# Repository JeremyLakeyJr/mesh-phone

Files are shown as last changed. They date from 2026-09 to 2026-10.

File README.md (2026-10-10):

# MESH-PHONE

ESP32-S3 handheld hardware with sub-GHz radios, LTE, NFC/RFID, a 4×4 keypad,
trackball, GPS and a rear expansion connector. Engineering prototype. **DO NOT FABRICATE OR POWER:** the current handset
is incomplete and only partially routed.

## Project layout

| Directory | Contents |
|---|---|
| [hardware/rev-f](hardware/rev-f/README.md) | Preserved GPS/expansion revision; superseded by the handset redesign |
| [hardware/handset-rev-a](hardware/handset-rev-a/README.md) | Active handset PCB and schematic; open `generated/handset.kicad_pro` |
| `hardware/main/` | Preserved original KiCad project and its local footprints |
| [mechanical/handset](mechanical/handset/README.md) | Latest reference-inspired handset concept; requires new PCB |
| [mechanical/enclosure](mechanical/enclosure/README.md) | Preserved enclosure for the existing Rev F board |
| `scripts/` | Maintained geometry extraction and revision verification |
| `docs/design/` | Historical design notes, pin budgets and routing notes |
| `docs/reviews/` | Electrical review evidence |
| `manufacturing/` | BOMs and explicitly unreleased legacy fabrication exports |
| `archive/` | Prior PCB candidates, enclosure and one-off development scripts |

## Working with the project

Open `hardware/handset-rev-a/generated/handset.kicad_pro` in KiCad 10.
Keep its local symbol and footprint libraries beside the project. The current
checkpoint was checked with KiCad 10.0.6.

Run `bash scripts/check_handset_pcb.sh` to refresh the native netlist, ERC/DRC,
connectivity checks, schematic PDF and previews. Then run
`python3 scripts/check_handset_release.py` to evaluate the release gate.
**The release gate currently fails intentionally:** passing artifact-integrity
checks does not mean the electronics are ready to manufacture.

For the preserved Rev F project, `python3 scripts/verify_revF.py` checks its saved
netlist and placement contracts; it does not run fresh native electrical analysis.

Run `python scripts/enclosure_geometry.py` after PCB mechanical changes, then
`scripts/export_enclosure.sh` to rebuild the enclosure STLs and preview.
See the mechanical README for panel-placement assumptions and fit checks.

Archived scripts preserve historical experiments, including obsolete absolute
paths and old project names. They are not a supported build pipeline and should
not be replayed on the active board. `.history/` is the existing KiCad history
repository and remains in place.

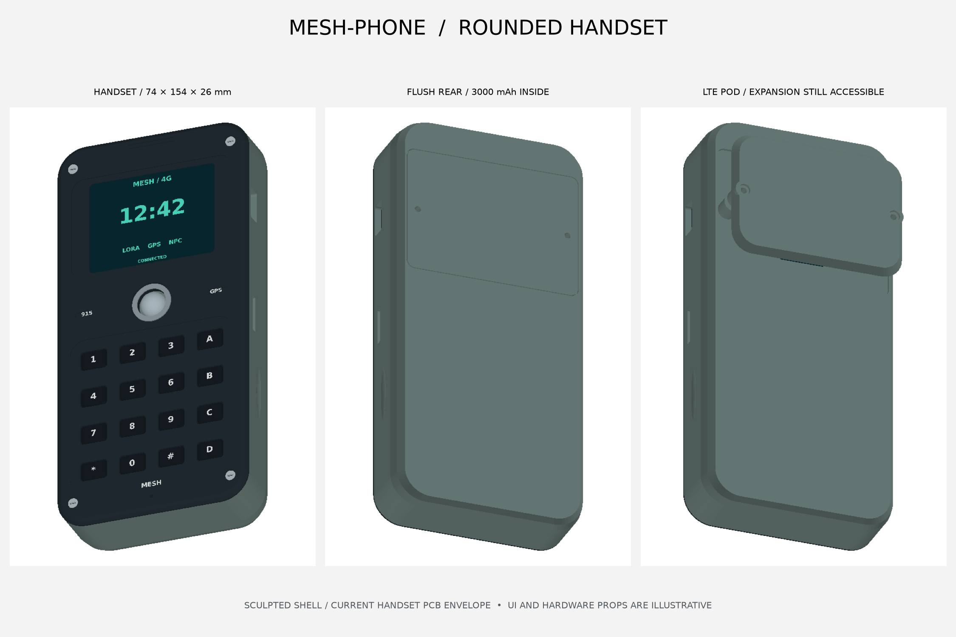
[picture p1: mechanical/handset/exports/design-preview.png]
Rounded handset enclosure


The current enclosure has a sculpted rear, rounded corners and a rolled front
rim. Its maximum body envelope remains 74 × 154 × 26 mm; populated-board fit
and the detachable modem pod still need engineering validation.

Latest appearance: [handset preview](mechanical/handset/exports/design-preview.png).
See [feature preservation](mechanical/handset/FEATURES.md) for the retained hardware
requirements and explicit packaging changes. Build with `scripts/export_handset.sh`.
The selected new-board materials list is in
[`hardware/handset-rev-a/materials-to-use.csv`](hardware/handset-rev-a/materials-to-use.csv).
The supporting component research and comparison table are in
[`docs/research/new-pcb-component-study.md`](docs/research/new-pcb-component-study.md)
and [`hardware/handset-rev-a/candidate-components.csv`](hardware/handset-rev-a/candidate-components.csv).

## Fabrication readiness checklist

Checkpoint: **2026-10-10**. Checked items mean the stated design-file work is
complete, not that the hardware has passed bench testing. Current status:
**277 schematic components, 2,644 passing integrity checks, zero schematic/PCB
parity findings, 20 ERC findings, zero DRC findings, and
216 unconnected items.** Eleven engineering blocker groups remain open.
The detailed source of truth is
[release-blockers.json](hardware/handset-rev-a/release-blockers.json).

Current priority is prototype fabrication readiness: complete the missing circuits,
finish copper and return paths, clear ERC/DRC, freeze the BOM and mechanical fit,
and obtain fabricator/assembler DFM review. Firmware feature work follows this
hardware work. Bench qualification remains required after prototype assembly.

### Completed design work

- [x] Route the SX1262 switch, three RF DC blocks, antenna connector, control filter and filtered supply. Seventeen regression cases and 753 reference samples pass; RF performance remains unqualified. [Switched RF checkpoint](hardware/handset-rev-a/sx1262-power-review.md#switched-rf-routing-checkpoint--2026-10-10).

- [x] Ground all five SX1262 matching-device return lands using scoped 0.2 mm drilled vias and local copper. Thirteen regression cases pass; record a screened 0.34 mm downstream RF routing target. [Ground/impedance checkpoint](hardware/handset-rev-a/sx1262-power-review.md#rf-ground-and-impedance-checkpoint--2026-10-10).
- [x] Relocate the SX1262 clock and route local PA/RF input connections. Nine copper regression cases pass; RF qualification stays open. [Local routing checkpoint](hardware/handset-rev-a/sx1262-power-review.md#local-parf-routing-checkpoint--2026-10-09).
- [x] Capture SX1262 PA choke and dual bypass with specified parts. Eleven circuit mutations pass; PA/RF electrical qualification remains open. [PA checkpoint](hardware/handset-rev-a/sx1262-power-review.md#pa-choke-and-bypass-checkpoint--2026-10-08).
- [x] Capture SX1262 matching/filter, TX/RX switch, control/supply filters and DC blocks. Eight wrong-wiring/value tests pass; physical copper follows in the switched RF checkpoint. [RF checkpoint](hardware/handset-rev-a/sx1262-power-review.md#rf-matching-and-switch-checkpoint--2026-10-08).
- [x] Connect SX1262 input supplies, bypass capacitors and all ground pins to the established rail/return network. Six open-pad tests and 16-pad continuity pass. [Supply checkpoint](hardware/handset-rev-a/sx1262-power-review.md#input-supply-routing-checkpoint--2026-10-08).
- [x] Route the SX1262 core regulator loop, VREG capacitor return and regulator/exposed-pad ground. Six open-pad controls pass; 15 copper items added with existing copper preserved. [Regulator checkpoint](hardware/handset-rev-a/sx1262-power-review.md#regulator-routing-checkpoint--2026-10-08).
- [x] Capture and route the SX1262 TCXO clock: 14 pads, an 8.092 mm relocated clock path and its ground reference pass checks. ERC falls by three; RF frontend and clock electrical qualification remain open. [Clock checkpoint](hardware/handset-rev-a/sx1262-power-review.md#tcxo-clock-checkpoint--2026-10-08).

- [x] Route amplifier power, ground and local shutdown bias; move C13 beside U6. Fifteen physical pads pass continuity, five regression cases pass, and existing copper remains intact. Speaker/I²S/microphone routing remains open. [Layout checkpoint](hardware/handset-rev-a/README.md#audio-power-routing-checkpoint).

- [x] Cross-build an ESP32-S3 keypad bring-up application with I²C, GPIO8 interrupts, USB logs and start/stop/recovery commands. Twelve session tests and native pin-map checks pass. [Build and commissioning instructions](firmware/bringup/README.md); hardware testing remains open.
- [x] Complete the 16-key matrix copper (72 physical pads), add five routing regression cases and a host-tested keypad driver with overflow recovery. [Routing and firmware evidence](hardware/handset-rev-a/keypad-routing-review.md).
- [x] Route ESP32 boot/reset service controls and U2 power, reset, I²C and interrupt connections; eight regression cases pass with zero DRC/parity findings. [Evidence and remaining bring-up work](hardware/handset-rev-a/core-bringup-review.md).
- [x] Organize hardware, mechanical designs, research, reviews and archived checkpoints.
- [x] Create the four-layer handset PCB and rebuild the schematic as a system index plus 24 functional sheets.
- [x] Retain ESP32-S3-WROOM-1-N16R8 and preserve interfaces for the external display, keypad, trackball, cellular adapter, radios, GNSS, NFC/LF RFID, storage, IR, audio and expansion.
- [x] Capture MakerFocus 3000 mAh battery requirements and the external-module connector; exact pack qualification remains below.
- [x] Populate the current schematic/PCB with component footprints and a materials list; final BOM and footprint audits remain below.
- [x] Capture BQ25186 charging, fused USB/battery entry, TPS25200 protection, TUSB320LAI source detection and TCA9536 controls; verify continuity of 113 local power-entry pads.
- [x] Cross-build and validate an inhibited STM32G031 commissioning image with private-bus I²C, PA0 shutdown, watchdog and diagnostic host interface. [Build, evidence and limits](firmware/power/stm32g031/README.md).
- [x] Route supervisor power, private/host I²C and SWD connections; verify 67 endpoints and preserve existing copper. [Routing evidence and remaining work](hardware/handset-rev-a/supervisor-routing-review.md).
- [x] Route charger VSYS to U7, the main power-switch control, and U7 to ESP32 power/bypass/ground; verify 38 physical pads with no new DRC findings. [Routing evidence and limits](hardware/handset-rev-a/main-distribution-review.md).
- [x] Add and route independent STM32 charge permission so a retained expander output cannot defeat reset inhibition; update controller sequencing and pass topology, continuity and fault tests. [Design and qualification limits](hardware/handset-rev-a/charge-inhibit-review.md).
- [x] Capture and place the separate STM32G031 charging supervisor, always-on regulator and isolated host bus; preserve existing copper geometry. [Circuit and remaining work](hardware/handset-rev-a/power-supervisor-review.md).
- [x] Record the charger-policy contract and implement a host-tested portable charger controller with a 4.17 V target; STM32 supervisor integration and hardware tests remain below.
- [x] Capture published MakerFocus pack specifications and calculate an illustrative modem-load budget; the current pack/modem compatibility blocker remains open.
- [x] Audit modem startup/output tolerance and battery current directly from CAD; add regression tests and release-gate checks. User selected a higher-current ~3000 mAh pack; provisional target is at least 5 A, with pack/fit/F2/J1 qualification still open. [Power review and battery requirements](hardware/handset-rev-a/modem-power-review.md).
- [x] Screen a concrete higher-current pouch and low-profile connector: CU-JAS427 and Molex 2053380002. Pack current clears the provisional calculation, but fit and production qualification fail; neither is frozen. [Candidate evidence and remaining checks](hardware/handset-rev-a/battery-candidate-review.md).
- [x] Replace J1 with the low-profile Molex 2053380002 in schematic and PCB; repair local battery/ground routing, preserve unrelated layout, and verify 118 power-entry pads plus a broken-route negative test. [Connector implementation and fuse screening](hardware/handset-rev-a/battery-connector-review.md).
- [x] Widen the battery-to-fuse main trace to 1.2 mm where clearance permits; reduce its calculated resistance by about 24%, preserve placement, and verify continuity with a broken-trace test. Fuse selection and current/thermal qualification remain open. [Copper and fuse follow-up](hardware/handset-rev-a/battery-copper-review.md).
- [x] Inventory handset loads and add a 60-case battery-only power-envelope check separating the charger-fed handset from the modem. Flag the incomplete 0.25 A allowance and configured handset discharge limit in the release gate. [System power review](hardware/handset-rev-a/system-power-review.md).
- [x] Audit display/backlight and expansion limits; specify four high-power backlight resistors in schematic, PCB and BOM. Add checks for panel supply tolerance and port current limit. [Display and expansion review](hardware/handset-rev-a/display-expansion-power-review.md).
- [x] Capture and place a dedicated 3.0 V display supply, SPI/control buffers and touch I²C translator using specified parts. Preserve shared-bus MISO deselection; update BOM and power inventory. Physical routing is recorded below; electrical qualification remains open. [Display interface review](hardware/handset-rev-a/display-interface-review.md).
- [x] Route and physically verify the dedicated display interface: 25 net groups, including supplies, host/connector signals and grounds. Preserve existing placement/copper; add ground returns and continuity regression tests. [Display routing review](hardware/handset-rev-a/display-routing-review.md).
- [x] Install and route the CAT4004A backlight current driver, replacing Q2/R52–R55; verify 26 endpoints, seven regression tests and no new DRC findings. Preserve existing display continuity. [Implementation and qualification limits](hardware/handset-rev-a/backlight-routing-review.md).
- [x] Capture and route expansion power control, fault sensing and hardware signal isolation; verify 31 physical net groups and six regression tests, and add a host-tested portable controller. Preserve all 4,183 existing copper items. [Implementation and qualification limits](hardware/handset-rev-a/expansion-control-review.md).
- [x] Improve expansion ESD ground returns with local inner-layer pours and a direct U16 ground bridge; remove 36.24 mm of ground detours, preserve all signal routing and pass ground-return regression tests. [Evidence and remaining limits](hardware/handset-rev-a/expansion-control-review.md).
- [x] Clear all four USB connector hole-clearance findings using a dedicated ground-corner-relief footprint; preserve holes, routed copper and board rules. Native DRC is now zero; four geometry regression tests pass. [Footprint change and remaining qualification](hardware/handset-rev-a/usb-connector-review.md).
- [x] Route both USB-C data orientations through ESD protection and 22 Ω host termination; match CAD path lengths, add reference copper and verify seven regression cases. Record the JLC04161H-7628 stackup target; fabricator impedance and electrical qualification remain open. [Routing evidence and limits](hardware/handset-rev-a/usb-data-routing-review.md).
- [x] Route the local TPS63802 main 3.3 V regulator circuit; verify continuity of 26 pads.
- [x] Route U20 local modem converter, feedback, ground and switch-controlled enable network; verify 48 pads with no new DRC findings. [Layout and startup limits](hardware/handset-rev-a/modem-layout-review.md).
- [x] Route U10 local 5 V boost, feedback, ground and switch enable; verify 19 pads with no new DRC findings. [Layout and voltage limits](hardware/handset-rev-a/reg5-layout-review.md).
- [x] Route U10 VSYS feed and LF RFID power/ground for U9/U18; verify 36 pads and preserve existing copper. [Distribution evidence and limits](hardware/handset-rev-a/reg5-distribution-review.md).
- [x] Route the local U11 1.8 V regulator circuit, reposition input bypass and orient the inductor toward SW; verify 15 pads and preserve existing copper. [Layout evidence and remaining qualification](hardware/handset-rev-a/reg18-layout-review.md).
- [x] Connect U7 to U11 input, shorten C28 output/sense paths and verify 17 pads. Audit confirms no external 1.8 V loads are assigned; rail purpose remains open. [Distribution evidence](hardware/handset-rev-a/reg18-distribution-review.md).
- [x] Capture auxiliary supplies and the regulated modem supply/enable circuit; complete routing and load qualification remain below.
- [x] Capture the CC1101 clock, 868/915 MHz matching/filter, supply bypass and GDO2 test pad; pass 90 topology/value checks and five negative tests.
- [x] Add SX1262 core DC-DC support, correct its VREG capacitor to 470 nF, and specify input bypass parts; pass 30 circuit checks and four negative tests.
- [x] Capture GNSS, display/touch/backlight, audio, storage/IR, NFC/LF support and protected expansion interfaces; incomplete support circuits are listed below.
- [x] Preserve prior CAD checkpoints and existing routed copper during staged updates.
- [x] Add repeatable checks, schematic PDF and board/assembly previews. Current placement checks report no overlaps; fabrication release remains blocked.

### Remaining before first prototype fabrication

Work through these in order; circuit and mechanical decisions must be resolved
before final routing and manufacturing exports.

- [ ] **Battery and charging:** qualify a higher-current ~3000 mAh 1S replacement (provisional ≥5 A target), preserving the pocketable design; verify dimensions, polarity, protection, NTC and charge/discharge limits. Re-select F2 and qualify J1/harness/copper for the full handset/modem current budget. Complete STM32 durable fault storage, service rearm and expiring host permissions, qualify reset-time CE inhibition and powered-off charging. Confirm NTC attachment and charge-temperature limits. Implement charger policy, fault handling and source recovery; qualify the routed supervisor power/control buses and finish remaining system distribution.
- [ ] **Power supplies:** finish U7 distribution to the remaining peripheral loads and U20 external battery/modem distribution; resolve the audited 3.71–4.13 V turn-on range (up to 4.21 V with the EN-current screening allowance); qualify the routed U10 display branch for voltage, current and trace sizing; resolve the unused 1.8 V rail (assign justified loads or remove it), then finalize U11 output/sense layout. Calculate worst-case inductor current, capacitor DC bias, feedback tolerance, thermal dissipation, startup/UVLO and modem burst margin. Define current-limited bring-up limits and test points.
- [ ] **Cellular adapter:** freeze an orderable modem variant, firmware, SIM interface, logic translation and call-audio circuit. Verify supported bands and carrier VoLTE requirements; interchangeable adapters do not guarantee every carrier. Select the call microphone and speaker/harness arrangement.
- [ ] **SX1262 LoRa:** qualify the captured 32 MHz TCXO amplitude, DIO3 supply and startup timing; qualify the routed PA choke/bypass and local RF input geometry; qualify matching-device grounds, routed RF switch/antenna paths and all three signal-via transitions; complete thermal layout; qualify the routed input supplies and core regulator loop.
- [ ] **CC1101:** refine and route the oscillator, bypass, balun/filter and separate antenna feed against the selected stackup. Review crystal load/drive and the optional spur filter; define firmware SPI/GDO configuration.
- [ ] **NFC and LF RFID:** finish ST25R3916B matching/receive circuitry and HTRC110 clock, analog reference, coil network and timing-capable host return path. Specify external coils, crystal loading and tuning provisions.
- [ ] **GNSS:** finish MAX-M10S decoupling and RF feed; select the passive antenna and verify mounting, keepouts and coexistence requirements.
- [ ] **Expansion and USB:** qualify routed J16 current limits, inrush, isolation, ESD return paths, fault recovery and shared-bus timing; integrate the portable controller. Exchange modules only with handset power off. Qualify the routed USB fanout, uncoupled tuning, three via transitions per leg, termination and eye performance; obtain fabricator impedance approval. Obtain assembler DFM approval of the USB4105 relieved ground-land contour and qualify connector fit/solder joints.
- [ ] **Display, controls and peripherals:** next, qualify the routed U28–U31 interface for regulator load/heat, trace sizing, capacitor DC bias, power sequencing and shared-bus timing; qualify the routed CAT4004A backlight current, heat and default-off/on sequencing. Confirm the purchased display/touch configuration, FPC contact orientation, supply/backlight requirements and GPIO budget. Review keypad-scanner controls, shared SPI chip selects, IR boot behavior, microSD and audio interfaces; implement the firmware needed for safe bring-up.
- [ ] **Antennas and coexistence:** select actual LTE, LoRa, CC1101, GNSS and Wi-Fi/BLE antenna arrangements, cable/connectors and matching provisions. Establish ground clearance, spacing and simultaneous-transmit policy; retain access for RF measurements.
- [ ] **BOM and footprints:** freeze all orderable parts with tolerance, voltage, power, dielectric, temperature and lifecycle requirements. Independently audit every custom symbol pin map, package, exposed pad, paste pattern, orientation and connector mating direction. Define DNP options and approved substitutions.
- [ ] **Mechanical fit:** reconcile the PCB with the pocketable case, actual battery, external screen/FPC, trackball opening and retention, top speaker, bottom microphone, antennas, mounting hardware and external module port. Check populated heights, cable bends and moved power-switch access using a full assembly model and fit prototype.
- [ ] **Fabricator rules:** confirm the proposed JLC04161H-7628 four-layer stackup, copper weights, impedance targets, drill/via limits, solder-mask rules and ESP32 and expansion J16.8/U14.1/U14.6/U16.1 via-in-pad filling/capping requirements with the chosen fabricator. Resolve RF reference via sizes against those capabilities.
- [ ] **Complete PCB routing:** connect all 216 currently unconnected items; finish return planes, ground stitching, thermal paths and supply distribution. Review switching loops, RF/USB impedance, antenna keepouts and analog/digital interference. Recheck clearances after all placement changes.
- [ ] **Independent electrical review:** check every pin and power state against manufacturer documents, including boot straps, pull resistors, power sequencing, unpowered interfaces and test access. Close each blocker with evidence rather than marking an incomplete subsystem complete.
- [ ] **Final native checks:** regenerate netlist/ERC/DRC from the exact release revision; resolve the 30 current ERC findings and all airwires; retain zero DRC findings. Require zero parity errors and passing circuit/continuity checks. Any genuinely intentional rule exception needs a documented engineering justification, not a blanket waiver.
- [ ] **Prototype manufacturing package:** export and inspect Gerbers, plated/non-plated drill files, fabrication drawing/stackup, assembly drawings, full MPN BOM, DNP list and pick-and-place files. Verify units, origin, bottom-side rotation, pin 1, polarity and layer alignment in an independent viewer; obtain fabricator/assembler DFM feedback.
- [ ] **Prototype release:** review the complete package and bring-up plan, close the applicable prototype blockers, tag the exact Git revision and archive checksums/reports with the exports. Update the release gate to distinguish an approved prototype from production qualification. Only then authorize a small prototype build.

### After prototype assembly, before production release

These require physical hardware and therefore cannot be prerequisites for
fabricating the first engineering prototypes.

- [ ] Inspect assembly and check shorts/polarity before applying power; bring up each rail on a current-limited supply with the battery initially disconnected.
- [ ] Measure charge limits, NTC/fault response, protected-pack behavior, powered-off charging, source switching, sleep current, runtime, rail stability, thermal rise and worst-case modem/radio bursts.
- [ ] Validate oscillator startup/frequency/drive, LoRa and CC1101 conducted power/sensitivity, spurious emissions, antenna matching and RF coexistence in the assembled case; tune NFC/LF coils and verify GNSS reception.
- [ ] Test calls/SMS/data with the selected adapters and supported carriers, SIM operation, call/media audio, display/touch, keypad combinations, trackball, storage, IR, GNSS/PPS and expansion functions.
- [ ] Test USB/expansion faults and ESD response, power interruption/recovery, firmware update/recovery and repeated accessory connection cycles.
- [ ] Validate enclosure fit, connector access/retention, drops, pocket pressure, temperature and battery protection from mechanical damage.
- [ ] Complete required EMC/radio/product compliance assessment and testing for intended markets and operating modes.
- [ ] Correct prototype findings, repeat affected checks/tests, freeze production BOM/firmware and create assembly test fixtures, programming instructions, acceptance limits and traceability records.
- [ ] Obtain independent final review and release a versioned production manufacturing package only after all qualification evidence is recorded.

Battery follow-up: [pack, charging and power-budget review](hardware/handset-rev-a/battery-charging-review.md).

Implementation evidence: [power entry](hardware/handset-rev-a/power-entry-review.md),
[3.3 V layout](hardware/handset-rev-a/3v3-layout-review.md),
[schematic rebuild](hardware/handset-rev-a/schematic-rebuild-review.md),
[CC1101](hardware/handset-rev-a/cc1101-review.md), and
[SX1262 power](hardware/handset-rev-a/sx1262-power-review.md).

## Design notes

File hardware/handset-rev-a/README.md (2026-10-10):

# Handset Rev A — PCB redesign in progress

Open [generated/handset.kicad_pro](generated/handset.kicad_pro) in KiCad 10.
This is a new board and hierarchical schematic, not the old Rev F layout.
**It is incomplete, partially routed, and not ready to fabricate or power.**
The original Rev F project is preserved in `../rev-f/`.

Latest: [SX1262 switched RF routing](sx1262-power-review.md#switched-rf-routing-checkpoint--2026-10-10). Fabrication
readiness takes priority over additional firmware features. RF, NFC/LF and other
unfinished circuits remain fabrication blockers.

## Implemented in the design files

- 66 × 142 × 1.6 mm board with four copper layers, four 2.2 mm mounting
  holes and a 27 × 24 mm trackball opening. The extra 4 mm length prevents
  the mounting drills from breaking through the former 138 mm outline.
- Retained ESP32-S3-WROOM-1-N16R8; PSRAM pads 28–30 stay unconnected.
- A rebuilt system index and 21 functional schematic sheets, including
  GNSS/antennas, NFC, protection, storage/IR, LF support, display and modem power.
  See [schematic PDF](generated/handset-schematic.pdf) and
  [rebuild review](schematic-rebuild-review.md) for corrections and remaining work.
- Sixteen switches at the enclosure coordinates, TCA8418 scan circuit,
  matrix row traces on F.Cu and column traces on In2.Cu. Scanner fanout remains.
- BQ25186 programmable charger, TPS63802 3.3 V converter, TPS62840 1.8 V converter,
  TPS61023 LF/backlight 5 V converter and MAX17048 gauge circuits.
- Fused battery and USB paths, TPS25200 eFuse, TUSB320LAI Type-C detection,
  TLV704 always-on detector supply and TCA9536 charge controls. The 113-pad
  local power-entry cell passes copper continuity; firmware and external
  distribution are unfinished. See [power-entry-review.md](power-entry-review.md).
- Main 3.3 V converter local copper is routed and continuity-checked across
  U7, L1, C20–C22 and R30–R33. External power distribution remains incomplete;
  see [3v3-layout-review.md](3v3-layout-review.md).
- CC1101 clock, filtered supply and 868/915 MHz balun/matching/filter circuit
  are captured with specified parts and checked PCB placement. RF routing and
  tuning remain; see [cc1101-review.md](cc1101-review.md).
- SX1262 TCXO clock and local routing are captured; its RF frontend and
  electrical qualification remain open. HTRC110 clock/analog/coil circuits are incomplete.
- MAX98357A media amplifier, SPH0645 digital mic, separate analog call-audio
  harnesses, native ESP32 USB-C and dedicated modem/expansion connectors.
- Manufacturer-derived custom pin definitions and TPS63802 DLA0010A land
  pattern. Custom library geometry still needs an independent pre-fab review.
- MAX-M10S GNSS; ST25R3916B NFC and oscillator; TPS2553 expansion current
  limiter and TPD4E05U06 protection arrays; Hirose DM3D-SF microSD socket;
  LF level translators; transistor-driven case-mounted IR; top-contact
  display connector/backlight switch; TPS63070 regulated modem supply.
- Routed TCA9537 expansion control, SN74CB3Q3245 signal isolation and SN74HCS10 fault interlock; portable controller host tests pass. [Design and remaining qualification](expansion-control-review.md).
- Named Coilcraft XFL4020 inductors replace the generic inductor allowances.
  Details and outstanding electrical work: [population-review.md](population-review.md).

The current component count, native ERC/DRC findings, remaining airwires and
schematic-to-board integrity results are in
[generated/verification-summary.json](generated/verification-summary.json).
The seven former reservation rectangles have been replaced by physical parts
and schematic circuits. Zero reservation rectangles does **not** mean that the
circuits are complete or that the PCB can be ordered.

## Critical unfinished work

| Block | Required work before release |
|---|---|
| GNSS | MAX-M10S is populated. Finish its RF feed, decoupling placement and coexistence review; no hardware backup supply is implemented. |
| Cellular | Select exact unlocked modem/firmware and establish calls, SMS and data on target carriers. The detachable adapter needs its own SIM, antenna feeds, voltage translation, regulated peak-current supply and audio implementation. |
| LCD / touch | ER-TFT024IPS-3 pinout and FH12A-50S-0.5SH(55) connector are captured with backlight switching. Confirm purchased CTP configuration, rail tolerances, FPC orientation/bending and firmware. |
| NFC | ST25R3916B, crystal and bypass components are populated. Finish and tune the antenna matching/receive network and validate oscillator loading. |
| Radio frontends | SX1262 input supply/ground and local core DC-DC loop are routed; finish thermal layout and qualify supply integrity; qualify the relocated TCXO, routed PA and local RF input geometry; qualify matching-device ground vias and complete switch/antenna routing. Route and qualify the implemented CC1101 clock/decoupling/balun/filter circuit and separate antenna feed. |
| LF RFID | SN74AHCT125 and SN74LVC1G17 translation is populated. Clock, analog reference, coil network and timing-capable host return path remain incomplete. |
| GPIO budget | Confirm scanner GPIO behavior and LCD D/C throughput. IR_RX now uses ESP32 GPIO3; preserve default JTAG eFuse policy and verify boot behavior with active IR. |
| USB / J16 | TPS2553 and signal ESD arrays are captured. Finish protected routing, VBUS protection and power-off accessory policy; test current limit and ESD response. |
| Storage / IR | DM3D-SF and IR driver/harnesses are captured. Validate card access, TSAL6400/TSOP38438 case mounting and firmware. |
| Mechanical / RF | Check actual populated heights, display FPC bends, antenna keepouts, connector mating direction and trackball retention. Power-switch placement has moved and needs matching case access. |
| Layout | Finish placement, reference-plane design, all remaining routing, controlled impedance, thermal copper, ground stitching and silkscreen. Clear native ERC/DRC. |

## Power and connector contracts

J1 is a provisional two-pin battery connector; verify the purchased MakerFocus
pack polarity and plug before populating it. J2 is an external 10 kΩ B3435
thermistor to be thermally coupled to the battery; the two-wire pack itself does
not supply that signal. The BQ25186 CE input defaults off; firmware must apply
and read back [charger-policy.json](charger-policy.json) before charging.
The contract requests 300 mA charge on enumerated legacy USB or 500 mA on
qualified Type-C sources, subject to source and thermal limits. It is not yet
implemented firmware. Validate pack protection and discharge current; the
modem burst budget and powered-off charging remain unresolved.

SW19 controls converter enables. VSYS, charger, and battery gauge can remain
energized while the handset rails are off. Inductors now have exact XFL4020
MPNs and documented land patterns; rated-current and thermal review remains.
The legacy-named +5V_RF rail now also supplies the display backlight.

J16 preserves Rev F pin order: GND, EXP_3V3, SCL, SDA, SCK, MOSI, MISO, CS,
IRQ, GND. It is a locking JST GH cable port, independent of the modem.
U14 now supplies EXP_3V3 through a TPS2553 with a 100 kΩ limit resistor;
U15/U16 protect the seven signals. This is captured circuitry, still unrouted
and untested. Swap accessories with power off.

J8 is the proposed modem adapter's 3.3 V logic contract: GND, host TX, host RX,
LTE_ON, GND, MODEM_STATUS. Raw modem UART pins must not be connected unless
their voltage levels match; translation belongs on the adapter. J9 reserves a
separate regulated modem supply with two supply and two ground contacts.
U20 now generates nominal 3.792 V from VBAT, with hardware shutdown and
conservative battery UVLO; it does not connect the modem to raw charger SYS.
Startup requires a sufficiently charged battery (about 3.92 V nominal).
Connector/contact current, cable resistance and transient limits are not yet
validated. J4 carries adapter call speaker ± and microphone ±.
J7 is a proposed harness for PIM447, not a claim that its pad order matches it.

## Multi-carrier requirement

The user requires unlocked operation across carriers. A7672G is consequently
**a candidate, not a frozen or universally compatible modem**. Quectel EG25-G
is another research lead with broader published carrier documentation, but
carrier data approval does not establish smartphone VoLTE acceptance. No
universal-carrier claim is made, and no carrier-specific module is hard-wired
into this main board. The replaceable modem adapter preserves that choice.

## Reproduce and inspect

Edit the saved project directly. `scripts/build_handset_pcb.py` refuses to
overwrite an existing board. The additive population scripts are one-shot
migrations with snapshots/markers; do not rerun them to reset manual placement.

Run `bash scripts/check_handset_pcb.sh` for native XML
netlist export, ERC, DRC, integrity checks and SVG previews. Integrity checks verify real exported
schematic pin nets against board pads and mounting/key coordinates. Passing
them does not waive native errors or establish electrical functionality.

Run `python scripts/check_handset_release.py` for the separate release gate.
It intentionally fails while native errors, unrouted connections or engineering
blockers remain. See [population-review.md](population-review.md) for the
22 September checkpoint and remaining work by review category.

## Primary design references

- [TI BQ25186](https://www.ti.com/lit/ds/symlink/bq25186.pdf)
- [TI TPS63802, including DLA0010A land pattern](https://www.ti.com/lit/ds/symlink/tps63802.pdf)
- [TI TPS62840](https://www.ti.com/lit/ds/symlink/tps62840.pdf)
- [TI TPS61023](https://www.ti.com/lit/ds/symlink/tps61023.pdf)
- [TI TCA8418](https://www.ti.com/lit/ds/symlink/tca8418.pdf)
- [TI CC1101](https://www.ti.com/lit/ds/symlink/cc1101.pdf)
- [Analog Devices MAX17048](https://www.analog.com/media/en/technical-documentation/data-sheets/MAX17048-MAX17049.pdf)
- [u-blox integration-document availability](https://content.u-blox.com/sites/default/files/documents/UBX-M10050-KB_IP_IN_UBX-22012688-2.pdf)
- [SIMCom A7672G specifications and certification list](https://www.simcom.com/product/A7672G.html)
- [Quectel EG25-G carrier and software documents](https://www.quectel.com/product/lte-eg25-g/)

## Audio power routing checkpoint

2026-10-08: U6 supply pins, exposed-pad/ground pins, C13/C14 bypass network and
R13 local shutdown bias now pass physical continuity checks. C13 moved from
(82, 83) mm to (77.45, 80.9) mm, rotated 90 degrees, to put its 100 nF bypass
beside U6. No other footprint, previous track/via, stackup or design rule changed.
All 613 pre-existing connected pad groups retain continuity; all 9,075 previous
copper items remain. The original checkpoint is archived at
`archive/handset-before-audio-routing/a31246005c3d/` in the repository root.

The [MAX98357A datasheet, page 33](https://www.analog.com/media/en/technical-documentation/data-sheets/MAX98357A-MAX98357B.pdf)
specifies supply bypassing and low-resistance supply/output/ground paths.
This routing uses a 0.5 mm feed to the existing 3.3 V trunk, a 0.3 mm bulk-capacitor
branch and short 0.25 mm VDD pad escapes. It is a CAD continuity checkpoint;
current capacity, ground-return/thermal performance, supply noise and audio
performance still need engineering qualification. The 3.3 V system load budget
remains open.

[Construction and preservation evidence](generated/audio-routing.json),
[15-pad continuity checks](generated/audio-routing-check.json) and
[five routing regression cases](generated/audio-routing-tests.json) are included
in the board checks. The release gate checks the new copper directly.
Native DRC and schematic parity are zero; unconnected items fall from 250 to 238.
Thirty ERC findings and eleven engineering blocker groups remain open.

Speaker output placement/routing, I²S, the U2 MEDIA_EN connection and the microphone
are still unfinished. Complete the speaker placement review before routing its
switching-current paths. The circuit is not ready for power-up or fabrication.

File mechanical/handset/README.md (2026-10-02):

# MESH-PHONE handset concept

A rounded handset redesign replaces the flat-sided brick silhouette with a
rolling rear shell, 11 mm corner radii, a softened front rim and smooth thumb
channels. A dark face sits against a muted green-grey rear shell in the CAD
preview. The detachable modem pod also has rounded corners and a tapered back.

**This is a mechanical concept for the current handset Rev A board envelope,
not the preserved Rev F PCB.** The envelope fit checks do not establish a
populated-board, cable or antenna fit. No electronic feature is removed.

## Size and architecture

- Handset: **74 × 154 × 26 mm** maximum, unchanged by the rounded redesign.
  The new shape reduces corner bulk, not the required battery/PCB stack. Compared with the prior 93 × 160 × 38.8 mm body.
  About 49% less body bounding-box volume. No external screw ears. The
  illustrative trackball rises 2.3 mm above the face; quoted body sizes exclude it.
- Proposed new main board: **66 × 142 × 1.6 mm**, underside Z=17.2 mm.
  Extended 4 mm during PCB design to keep mounting drills inside the board.
  Mounting holes are [±30.5, ±68]; board corners use a 1.5 mm clip.
- Battery: MakerFocus **3000 mAh**, nominal 65 × 36 × 10 mm, supplier tolerance
  ±2 mm. Cradle reserves **38 × 67 × 12 mm**, at [0, -39], with lead exit,
  rounded guides and soft-strap anchors. No forced compression of the pouch.
- Smaller touchscreen candidate: EastRising **ER-TFT024IPS-3** rotated to
  landscape. The LCD is 59.26 × 42.72 × 2.3 mm; the CAD reserves
  **60.5 × 43.5 × 3.5 mm** pending the exact capacitive-touch stack drawing,
  with a **48.5 × 36.3 mm** window at [0,42.5]. Freeze its full ordering code and
  FPC before treating it as selected.
- Trackball: retain PIM447's documented **25 × 22 × 11 mm** envelope. Proposed
  center [0,8]. A **27 × 24 mm board aperture** lets its carrier sit partly below
  the new board instead of adding thickness above it. Retention is not finalized.
- Keypad: 16 keys at X=-22.5,-7.5,7.5,22.5 and Y=-11,-26,-41,-56. Requires
  relocated switches. Print `keycap.stl` 16 times; stem height and switch travel
  are provisional. The flange sits below the face and retains each cap.
- LTE carrier: moves into a detachable **66 × 48 × 18 mm** rear pod. It adds
  **16.8 mm** locally when attached, making maximum thickness **42.8 mm**.
  The slim 26 mm body dimension is **without the LTE pod**, not the all-up phone.
  LTE calling/data require that pod until a compact integrated modem redesign.

The design reduces size by changing the packaging, not scaling down components.
The smaller screen and new switch coordinates are explicit changes to the
hardware plan; old display/PCB parts are not drop-in compatible.

## Keep every feature

See [FEATURES.md](FEATURES.md) for the complete feature-to-space/port mapping,
including power, RF, audio, storage and independent expansion requirements.
No camera is added: the user removed it in the prior design history.

The LTE pod uses its own power/UART/control/audio harness through the upper
rear opening. **Do not power LTE from J16.** A separate lower opening reserves
J16 access; the pod's side cable exit keeps that connection accessible while
LTE is attached. A future powered accessory interface is required where a
module exceeds J16's existing 3.3 V/50 mA budget or needs 5 V.

The pod has approximately 61.2 × 43.2 × 15.8 mm internal space before pillars.
A 44.45 × 31.75 × 12.44 mm modem carrier fits the central nominal envelope with
thin foam and no stacked connectors. Its real harness bends, SIM orientation,
antenna and US-compatible replacement still need selection. Optional NFC/RFID
accessories require their own pod/coil arrangement; the LTE pod is not claimed
to hold LTE, NFC and RFID together. They can use the independent accessory
connection after its electrical/power contract is redesigned.

## Files

| File | Purpose |
|---|---|
| `handset.scad` | Editable mechanical concept and transparent `fit` envelopes |
| `exports/rear.stl` | Main body, battery cradle, revised ports and mounts |
| `exports/front.stl` | Frame, recessed face, screen opening and rectangular keys |
| `exports/keycap.stl` | One provisional retained keycap; print 16 |
| `exports/port_cover.stl` | Flush rear cover for both harness openings |
| `exports/module_pod.stl` | Removable LTE/accessory housing |
| `exports/design-preview.png` | Actual CAD geometry with illustrative display/ball/labels |
| `appearance.scad`, `exports/visual_*.stl` | Render-only props; **not printable functional components** |

Rebuild with `scripts/export_handset.sh` from repository root. Requires
OpenSCAD, Python, NumPy and Matplotlib. Preview uses a software depth buffer,
so no display server is required. Mesh checks test closed edges and connected
solids; they do not establish populated-board fit or electrical functionality.

## Assembly and remaining engineering

Main upper walls/face are 2.4 mm and the rear floor is 2.2 mm. The rear
rolls from a 68 mm wide central back to the full 74 mm width over its first
7 mm of depth; the internal cavity follows that transition. Front edges roll
out over 1.8 mm. Side thumb channels are limited to 0.45 mm depth, leaving
1.95 mm of nominal wall at their deepest point. Internal tongue aligns the halves. Four M2
screws pass through the front columns and new board mounting holes into rear
1.7 mm pilots; start with 14 mm under-head screws, then check 5–7 mm engagement
and actual head dimensions. Dock screws engage M2 nuts inserted from inside:
approximately 6 mm for the cover, 22 mm for the pod, subject to a fit print.

Print the five parts exterior-side down as exported; the sculpted rear and
pod shoulders may need supports depending on printer/material and layer height. Verify 0.3 mm lip/cover
clearance and 0.3 mm per-side key clearance on a small fit print first. Keycap
flanges and strap bridges may require local bridging/support. A 7 mm soft strap
holds the battery without squeezing it. The pod currently requires thin foam
or a removable adapter to retain its chosen carrier.

Speaker vents are on the upper left; a front microphone opening is at the
bottom. Top-facing IR apertures preserve transmit/receive access. Power is
left-side, USB and microSD right-side; SIM access is in the modem pod.
Port sizes and centers are targets for the new PCB, not measured positions
from Rev F. The screen, trackball carrier, speaker and RF antennas still need
measured mounting parts and exclusion zones. No drop/waterproof rating is
claimed; this remains a mechanical concept, not a manufacturing release.

Reference: the [user-supplied MAKERphone image](https://i.kickstarter.com/assets/055/040/516/5a5b513d7df97f58d78bb12ea723ae6a_original.png).
Battery dimensions: [MakerFocus 3000 mAh specification](https://www.makerfocus.com/products/makerfocus-3-7v-3000mah-lithium-rechargeable-battery-1s-3c-lipo-battery-pack-of-4).
Other existing module envelopes come from `../../docs/design/module_selection_revE.md`
and `module_inventory_revC.md`; those historical documents are not electrical
release approvals. The previous US modem/power-path blockers still apply.

## Fit checks

Run `python scripts/check_handset_fit.py` to evaluate shell-to-shell, battery,
display, proposed board, keycap, rear cover, rear pod and modem-envelope
intersections. Results are saved in `exports/fit-checks.json`. The board envelope
includes new mounting holes and the trackball aperture. A 0.001 mm offset at
seating planes excludes coincident-surface artifacts. No full populated-board,
antenna or cable-bend model is available yet.

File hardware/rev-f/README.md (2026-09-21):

# Owasso1 Rev F — engineering checkpoint, not a fabrication release

Open `mesh-phone.kicad_pro` in this directory. The project in `../main/` is
the preserved original, not this corrected revision.

Implemented in schematic and PCB:

- MAX-M10S GPS with passive-antenna U.FL, UART, PPS and bypass capacitors.
- Rear keyed 10-pin JST-GH expansion interface, with a current-limited 3.3 V
  supply and shared SPI/I²C. Switch off and disconnect USB before swapping.
- MCU EN/BOOT support, usable SPI pin assignments, keypad expander pin-order
  corrections, display controls and I²C pull-ups.
- Removal of the switch connection that directly joined USB 5 V to the battery.
- Reconciled schematic/PCB pad contracts, with original component placements
  preserved. New parts are rear-mounted.

Read [INTERFACES.md](INTERFACES.md) before designing a module. This is a keyed
cable connector, not a finished blind-mate mechanical docking system.

## Not safe to order or power yet

The inherited battery protection, charger/power path, 3.3 V regulator and 5 V
boost circuits still require redesign. The A7670E modem/carrier is not approved
for the US target. Remaining radio-control, IR, fuel-gauge, RFID and SIM
interfaces are incomplete. See the full
[connection review](../../docs/reviews/review-2026-09-20/CONNECTION_REVIEW.md).

RF/USB impedance and antenna/enclosure placement are unverified. Ground vias
at the new reset circuitry overlap solderable pads; move them outside pads or
specify a suitable filled/capped via process during the final DFM pass. Do not
assume ordinary open vias in solder pads are assembly-ready.

## Verification evidence

Latest checkpoint: **608/608 contract and placement checks passed**. Native
KiCad DRC reports **0 errors, 0 unconnected items and 0 schematic-parity
findings**, with 5 footprint-library mismatch warnings. ERC still reports
**2 errors and 24 warnings** from unresolved supply modelling and interfaces.
The five footprint warnings concern J10, USB1, U1, J14 and J3; their modified
pad/geometry contracts need final library and manufacturer-drawing review.

- `verification-summary.json`: independent net/placement checks, native tool
  counts and SHA-256 fingerprints of the checked files.
- `drc-final.json`: native KiCad DRC, including schematic parity.
- `erc.json`: unresolved electrical-rule findings, not waived with power flags.
- `owasso1-engineering.pdf`: two-sheet schematic for review.
- `previews/`: schematic SVGs.

Zero routing errors would not certify circuit operation. Firmware, bench
bring-up, battery-safety verification, RF tests and cellular carrier acceptance
are still required. No revised manufacturing package has been released.

To repeat the read-only contract checks, run `python scripts/verify_revF.py` from the
repository root after exporting a fresh `netlist.xml`. The build/routing and
layout experiment scripts in `../../archive/scripts/` are checkpoint tools, not an
idempotent pipeline: do not replay them on this finished checkpoint.

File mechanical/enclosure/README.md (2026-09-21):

# Pocket enclosure — MakerFocus 3000 mAh

A compact revision for the existing **87 × 154 mm PCB**. The body is
**93 × 160 × 38.8 mm**, with no projecting screw ears: 11 mm narrower at its
widest point and 0.2 mm thinner than the previous enclosure. It is still a chunky
handheld; a phone-width design requires a narrower PCB and repackaged modules.

## Printable files

| File in `exports/` | Purpose |
|---|---|
| `rear.stl` | Beveled rear shell, PCB supports, battery cradle and strap anchors |
| `front.stl` | Front with internal closure columns and locating tongue |
| `port_cover.stl` | Flush expansion-port blank with orientation pin |
| `module_pod.stl` | Detachable external module housing |
| `preview.png` | All four print parts |
| `assembled.png` | Front and rear assembled views, with and without pod |

`enclosure.scad` is the editable source. `part` selects these four parts,
`layout`, `assembly`, `with_module`, or `fit` (translucent fit envelopes).
Run `scripts/export_enclosure.sh` from the repository root to extract current
PCB datums, rebuild every STL, verify closed connected meshes, and render previews.
Requires OpenSCAD and Python with NumPy/Matplotlib; no display server required.

## Battery and interior

Sized for the [MakerFocus 3000 mAh 103665 pack](https://www.makerfocus.com/products/makerfocus-3-7v-3000mah-lithium-rechargeable-battery-1s-3c-lipo-battery-pack-of-4),
listed at **65 × 36 × 10 mm, ±2 mm** (checked September 21, 2026).
The crosswise **67 × 38 × 12 mm** allowance includes that tolerance;
the cradle adds 0.8 mm per side. Its center is [0, -51], below the keypad.
A rounded lip locates the pouch; a soft 8 mm strap threads through the two
side bridges. Do not tighten it enough to compress the pouch. The cradle has
a 14 mm lead exit toward the upper electronics area. Route the lead along the
right interior margin to J13, clear of screws and the module connector.

The PCB underside is 17.3 mm above the rear exterior. The cradle floor is at
3.2 mm, leaving 2.1 mm above the maximum battery allowance for rear keypad
components. Verify solder joints, actual diode heights, strap and insulation
within that space before assembly. The taller rear RF/GPS components occupy
the upper region instead of being stacked above the battery.

MakerFocus offers 1.25 and 2.0 mm connector options. Confirm the purchased
plug and polarity against J13; this enclosure update does not change the PCB
connector or resolve the existing power-path design blockers.

## External module port

A **24 × 14 mm radiused opening** is centered on J16 at [-3, -10]. The
**68 × 44 mm recessed interface** has a 0.3 mm fit allowance, two M2 fasteners
58 mm apart, and an asymmetric locator. The blank fills the recess when no
module is fitted. Screw heads may sit slightly proud; no exterior ears remain.

The removable pod shares this interface and adds **16.8 mm** of rear depth
only while installed. Its outer envelope is 68 × 44 × 18 mm. Internal walls
leave 63.2 × 39.2 × 15.6 mm before screw pillars and strap bridges. A conservative
central module allowance is **48 × 26 × 10 mm**, with extra room elsewhere for
cable routing. Use foam and a soft strap through the internal anchors; alter the
parametric pod for larger modules. It does not claim to fit every RF/NFC/LTE
carrier. The LTE carrier remains part of the host's provisional front stack.

Plug a short keyed JST-GH cable into J16 through the opening, then secure the
pod; this is a cable-connected module, not a blind-mate electrical card slot.
The shell and screws carry module loads, not J16. Keep the cable within the
50 mm target from [the interface contract](../../hardware/rev-f/INTERFACES.md).
The existing electrical contract requires power off and USB disconnected for
module swaps. Antenna windows and any external module connectors must be
added for the selected module; the generic pod is otherwise closed.

## Closure, durability and assembly

Walls/faces are 2.4 mm; small corner radii preserve clearance around the square
PCB. A 1 mm edge bevel softens the pocket-contact edges. A perimeter tongue
aligns the halves. Four recessed M2 screw heads align with H1–H4, passing through
the front columns and PCB mounting holes into 1.7 mm rear pilot holes. This
uses the board's existing mounting datums without side projections.

Start with approximately 28 mm under-head-length M2 screws for the main body,
then measure engagement; target 6–8 mm without bottoming the 9 mm pilots.
Do not over-tighten against the PCB. Dock mounting uses M2 nuts inserted into
4.8 mm corner-to-corner hex pockets from inside before fitting the board.
Use approximately 6 mm screws for the blank and 22 mm for the pod, confirming
actual nut engagement and head profiles on a fit print. Nut pockets and ports
are not sealed; no water/dust/drop rating is claimed.

Print each part exterior-side down. The exports are already oriented this way.
The 9–10 mm strap-slot bridges and side openings may need local support/tuning.
Inspect layer adhesion and fit before installing electronics. No physical
durability or drop test has been performed.

## Remaining measured-fit work

The documented display outline is 61 × 92.44 mm; four front tabs locate it at
[0, 30]. The opening is 50 × 76 mm and its surrounding ledge accepts thin foam
tape. Confirm the visible display area, FPC fold and actual panel thickness.
The trackball opening remains at [-4.5, -23]; its 25 × 22 × 11 mm carrier needs
measured retention and must clear nearby controls. Keycaps/plungers are not
included. Front clearance is 17.5 mm: 12.44 mm for the documented LTE carrier,
4 mm provisional display thickness, and 1.06 mm assembly clearance. Confirm
header seating and actual display/trackball heights. Increasing `front_clearance` increases thickness.
USB access must be checked with the actual recessed socket and cable overmold.
These are mechanical prototypes, not a verified populated-hardware fit.

## Geometric verification

All four exported parts pass closed-edge and single-connected-component checks.
OpenSCAD intersection checks in `check_fit.scad` found no solid overlap for the
case halves, rear/blank, rear/pod, or rear/battery allowance. The pod test offsets
its seating plane by 0.001 mm to exclude coincident-surface artifacts. These
checks do not include unmodeled populated components or prove physical fit.

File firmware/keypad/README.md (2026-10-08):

# Keypad commissioning driver

Portable C++17 `controller.hpp` controls the handset's U2 keypad scanner at
7-bit I²C address 0x34. The [ESP32 bring-up application](../bringup/README.md) now integrates it with
I²C, GPIO8 interrupts and USB logging and has been cross-built for ESP32-S3.
No image has been flashed or tested on the physical handset.

Implement `keypad::Bus` using serialized, bounded I²C transfers. Give this driver
exclusive ownership of U2's scan/configuration/FIFO registers. Call
`initialize()` with all keys released after hardware commissioning approval.
A GPIO8 falling-edge ISR should wake a task; perform I²C work in that task,
not the ISR. Poll periodically as well as on IRQ, drain while IRQ stays low,
and bound the task's work per scheduling interval. Determine the actual service
rate by measurement; each call returns at most ten events.

Initialization configures only the four matrix rows/columns for scanning,
enables their pull-ups/debounce, disables GPIO FIFO events, and verifies writes.
GPIO direction and output-latch registers are untouched. It neither initializes
nor enables display, backlight, media, modem or RFID outputs. A future shared
U2 controller must integrate those GPIO functions with this register ownership;
do not run independent configuration writers against the chip.

`Batch` contains zero-based row/column press/release events. The physical switch
number is `4 * row + column + 1` (SW1–SW16). Key legends and UI actions are not
assigned here. Process events only when status is `ready`. Any other status
invalidates the application's entire held-key state; cancel gestures/actions,
report the fault and require explicit recovery with all keys released. A failed
or overflowed drain publishes no partial batch. The driver never asserts the
shared MCU_EN reset net automatically.

The implementation follows the [TI TCA8418 datasheet, revision G](https://www.ti.com/lit/ds/symlink/tca8418.pdf),
including the overflow and false-CAD errata. FIFO data loss latches a fault;
CAD status is never interpreted as a reset command. Matrix ghosting remains
possible without per-key diodes: commission one key at a time, and qualify
required multi-key combinations separately. This driver does not promise
arbitrary-key rollover or filter phantom presses.

Run the host checks:

```sh
python scripts/check_handset_keypad_firmware.py
```

Tests cover all 16 press/release codes, initialization and GPIO-register
preservation, FIFO order, empty polls, overflow before/during draining,
invalid events, configuration loss, arrival during interrupt acknowledgement,
ignored writes and transfer failure at each initialization/poll operation.
`test-report.json` binds the result to the tested source hashes.

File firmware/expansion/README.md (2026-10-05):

# Expansion controller core

`controller.hpp` is portable C++17 logic for U33 (TCA9537 at 7-bit address
0x49). It is not installed ESP32 firmware and does not authorize powering the
incomplete board. See the [circuit review](../../hardware/handset-rev-a/expansion-control-review.md).

Initialization writes and reads back output latch 0xF0, polarity 0x00 and
configuration 0xFA, in that order. P0 and P2 become outputs only after the
OFF latch is verified; P1 is fault input and P3 stays unused. Enabling requires
explicit load/startup and bus/address qualification plus a measured settling
interval. Power-only 0xF1 precedes signal-arm 0xF5. Polling verifies configuration,
output levels and FAULT every 100 ms or faster, including during settling.
This interval is a software deadline, not an electrical protection guarantee.
A detected fault or late poll latches OFF until an explicit initialization.
Repeated polling never rewrites the ON latch.

The hardware NAND disconnects signals while FAULT is low, after the TPS2553's
fault-reporting delay. It does **not latch short faults**: the signals may
reconnect when FAULT clears before software observes it. TPS2553 current limiting
is automatic; a polling-only driver can miss brief faults. Short-circuit/startup
and fault persistence must be qualified; there is no claim of latched hardware
shutdown or a rail-good measurement.

Integration must provide bounded-time, serialized I2C operations. Reserve
0x49, prevent other owners from writing U33, and validate the accessory against
all host I2C addresses and shared-SPI behavior. Configure host chip selects
inactive before arming. Never enable unknown or externally powered modules.
The bus switch does not translate voltage; accessories must use compatible
3.3 V signaling. Swap modules only with handset power off.

A failed transfer triggers a best-effort OFF write and reports
`unknown_reset_required`, even if a later write succeeds. A stuck accessory can
hold the same I2C bus used to control U33. Recovery requires an external
MCU_EN reset or whole-handset power cycle, followed by explicit initialization
and qualification. An ESP32 software/watchdog reset alone need not assert
MCU_EN. OFF means verified enable outputs low, not measured zero accessory
voltage; R87 is a bleed resistor, not an instant discharge guarantee. The target
must also detect missed execution externally: software cannot enforce its
poll deadline if it stops running.

Run host tests:

```sh
g++ -std=c++17 -Wall -Wextra -Werror -pedantic -fsanitize=undefined \
  firmware/expansion/tests/controller_test.cpp -o /tmp/handset-expansion-test
/tmp/handset-expansion-test
```

The fake bus covers initialization order, unqualified requests, delayed arming,
fault inhibition, steady-state traffic, missed deadlines, timer wrap,
expander reset, ignored writes, failed transactions and stuck-bus shutdown.
A target build, HAL integration, hardware fault injection and measured timing,
leakage, current, reset behavior and thermal limits remain open.

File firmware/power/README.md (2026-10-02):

# Charger controller integration

`charger.hpp` is a portable C++17 control core for the saved BQ25186/TCA9536
circuit. It is **not installed ESP32 firmware**, and is not authorization to
power the incomplete PCB. No ESP32 firmware target existed in this repository.

The controller starts with CE and legacy authorization low, preloads expander
outputs before configuring direction, verifies register writes and polls the
read-to-clear fault registers. Source loss removes charging permission; valid
source return can recover within the same fault-free session. A fault, register
reset, bus failure or missed 1-second deadline latches inhibition. Steady-state
polling does not toggle CE or restart the charge safety timer.

The 4.17V setpoint incorporates BQ25186's +0.5% regulation tolerance below
4.2V. Limits otherwise match `hardware/handset-rev-a/charger-policy.json`.
Temperature derating/suspension remains enabled in hardware. TS-open/UVLO and
historical battery faults conservatively require service review, so automatic
deeply depleted-pack recovery is **not yet implemented**.

A [cross-built STM32 commissioning target](stm32g031/README.md) now includes
the core, bounded private-bus I²C, watchdog and GPIO shutdown. It deliberately
refuses charging: durable storage and operational host permissions remain open.
It has not been flashed or hardware-tested.

## Integration requirements

Target owner is now the separate STM32G031 supervisor; see
[hardware capture](../../hardware/handset-rev-a/power-supervisor-review.md).
The `esp_idf/` direct U3/U24 adapter is a superseded host-integration example,
not the driver for this PCB. Its fake-SDK tests do not constitute an ESP-IDF
target build. The ESP32 must communicate through the supervisor protocol.

- Implement `set_charge_arm(bool)` on U25 PA0 (pin 6) as a direct GPIO
  operation independent of I2C. Preload low before output mode. The default
  implementation returns failure, preventing startup with an unported HAL.
  The supervisor power/I2C/SWD wiring is now routed; the inhibited commissioning implementation is built, but operational firmware
  remains incomplete. The core disarms before bus/storage operations and raises this permission
  only after verified expander enable. Reset high impedance relies on local R79.
- Supply bounded-time I2C read/write operations at 7-bit addresses 0x6A and 0x41.
  Serialize this owner with the rest of the bus; no other code may consume its
  read-to-clear status flags or write charger/expander registers.
- Implement durable atomic `load_inhibit`/`save_inhibit` storage. Missing,
  corrupt or unavailable records must report failure. The session marker is
  written before charging is possible; an unexpected reset/reboot cannot resume
  charging silently. There is deliberately no automatic fault-clear API.
- An audited service procedure must establish the initial record and explicitly
  authorize recovery with CE disabled, after inspecting the pack/fault cause.
  Do not clear the record on every boot. The current core retains an inhibition
  bit, not detailed diagnostic history; add a durable fault-reason log in the HAL.
- Pass `exact_pack_qualified=false` until the actual pack, NTC, connector and
  thermal/current limits have been verified. It prevents charge enable.
- Call `poll` on USB events immediately and periodically within 1000ms, using
  monotonic uint32 millisecond time. `legacy_granted` is true only for a USB
  configuration authorizing 500mA; revoke on detach, reset, suspend or
  deconfiguration. Type-C permission comes from expander P2, not VBUS voltage.
- The state `charging` means charge permission, not measured current or charge
  completion. Decode charging progress separately without stealing status reads.
- On I2C failure, the independent PA0 permission is removed before best-effort
  bus shutdown. Qualify GPIO reset/discharge, independent watchdog and rail
  collapse; ongoing I2C traffic can service the charger
  watchdog, so a latched-fault system must stop other charger transactions.
- The new hardware capture supplies U25/U24 independently of SW19. This core
  still needs a STM32 HAL, target build, host permission lease and qualified
  reset-time hardware charge inhibit before powered-off charging works. Q8/R79 and the PA0
  control path are now routed; see [inhibit review](../../hardware/handset-rev-a/charge-inhibit-review.md).

## Host validation

```
g++ -std=c++17 -Wall -Wextra -Werror -pedantic -fsanitize=undefined \
  firmware/power/tests/charger_test.cpp -o /tmp/handset-charger-test
/tmp/handset-charger-test
python3 scripts/check_handset_charger_policy.py
python3 scripts/check_handset_battery.py
```

Tests cover source loss/return, Type-C versus legacy authorization, delayed
legacy power-good, unchanged steady-state CE, unqualified packs, startup storage
failure, safety timer, open thermistor, eFuse/OCP, register/expander reset,
I2C failure, restart inhibition and polling deadlines including timer wrap.
These are fake-bus host tests; hardware fault injection and STM32/host protocol integration
remain required. LeakSanitizer is unsupported under this environment's ptrace;
validation uses UndefinedBehaviorSanitizer.

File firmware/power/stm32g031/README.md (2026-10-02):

# STM32G031 supervisor commissioning target

A real, cross-linked Cortex-M0+ target for U25 STM32G031G8U6 is now present.
**This is an inhibited diagnostic image, not operational charging firmware.**
It has not been flashed or run on hardware. The PCB remains unreleased.

Build from the repository root using Clang/LLD and LLVM binary tools:

```sh
bash firmware/power/stm32g031/build.sh
```

Outputs default to `/tmp/handset-stm32g031`: `supervisor.elf`, `supervisor.bin`,
`supervisor.map` and `build-report.json`. An optional argument selects another
output directory. There is no automatic flash/download action or build-time
network dependency. Pinned ST/Arm headers and licenses are included in `vendor/`;
`vendor-manifest.json` records provenance and content hashes.

## Implemented

- Cortex-M0+ reset vector, data/BSS initialization, default fault handler and
  1 ms SysTick. Explicit HSI16 system/peripheral clock selection.
- Linker limits for 64 KiB flash and 8 KiB RAM. Application uses at most 60 KiB;
  two 2 KiB pages are reserved for a future journal. At least 1 KiB is reserved
  above static RAM for the stack. This is not a measured stack-use guarantee.
- PA0 is preloaded low before output mode. Every arm request drives it low;
  requesting high returns failure. The main loop also holds it low.
- Private I2C1 on PB8/PB7 AF6. Register writes and repeated-start byte reads
  have a shared 25 ms transaction deadline and a finite spin fallback. Errors
  drop PA0 before peripheral reset. No automatic stuck-bus recovery/rearming.
- Conservative Standard-mode timing at PCLK 16 MHz: prescaler 250 ns, low/high
  counts 10/8 us before filter/synchronizer delays. Actual frequency and rise
  times must be measured; this is not a validated 100 kHz timing profile.
- PA11/PA12 remapping and AF6 for I2C2 at 7-bit address 0x42. No internal
  pull-ups on the TCA9800 B side. Read-only, polled diagnostic slave with clock
  stretching; writes are discarded and cannot grant power permission.
- Independent watchdog, nominal ~1 s at 32 kHz LSI, refreshed only by the
  foreground loop. Actual bounds require LSI tolerance and hardware testing.
  Fault handlers stop refreshing. Reset cause and option bytes are observable;
  firmware does not write option bytes, configure BOR or erase/program flash.
- The portable charger core is compiled into the ARM image. Startup calls
  `begin(..., false)`. Missing durable storage deliberately reports failure;
  the core requests CE/legacy shutdown and remains fault-inhibited. It does
  not repeatedly service charger registers after that fault.

`load_inhibit` and `save_inhibit` **are deliberately unavailable**, returning
failure rather than inventing a valid persistent record. Thus this image cannot
be turned into working charging firmware by changing the pack-qualified flag.

## Diagnostic interface

Read eight consecutive bytes directly from I2C address 0x42; no register-address
write is needed. Data is snapshotted at address match. Extra bytes read as FF.

| Byte | Meaning |
| --- | --- |
| 0 | Diagnostic format version: 1 |
| 1 | Charging forcibly inhibited: 1 |
| 2 | Portable controller state enum; startup is expected to report fault |
| 3 | I2C1 error counter, low eight bits |
| 4–7 | Captured RCC reset-cause register, little endian |

`supervisor_diagnostics` is also available through SWD, including raw option
bytes and loop/error counters. The slave is polled once per foreground iteration
and can stretch SCL while waiting for SysTick. Validate ESP32 timeout settings.
This diagnostic format is not the future charging-permission protocol; it has
no grant, clear-fault, rearm, passthrough or flash-write commands.

## Validation and next work

The actual ELF passes architecture/EABI, vector-table/Thumb entry, load-region,
flash journal boundary, static RAM/stack reserve and unresolved-symbol checks.
The commissioning build is 2,336 bytes flash and 44 bytes static RAM with the
recorded compiler. Portable charger tests pass with strict warnings and UBSan.
These checks do not execute ARM peripheral behavior or measure hardware timing.

Next implement a power-loss-safe durable inhibit/fault journal, audited service
initialization/rearm, the host protocol with expiring legacy-USB permission and
ESP32 integration. Complete BOR/reset/watchdog provisioning and target-level
fault-injection tests before permitting any charging. Keep exact-pack
qualification false until pack, thermistor, connector and current limits are
verified. Validate bus transactions, clock stretching, reset shutdown and
unpowered-host isolation on the qualified hardware revision.

Register definitions come from [ST's CMSIS device package](https://github.com/STMicroelectronics/cmsis-device-g0)
and [Arm CMSIS 5.9.0](https://github.com/ARM-software/CMSIS_5/tree/5.9.0).
Clock, GPIO remapping and I2C behavior follow
[ST RM0444](https://www.st.com/resource/en/reference_manual/rm0444-stm32g0x1-advanced-armbased-32bit-mcus-stmicroelectronics.pdf);
board pin assignments remain in `power-supervisor.kicad_sch`.

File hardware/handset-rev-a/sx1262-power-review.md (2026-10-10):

# SX1262 core regulator support — 2026-09-24

Latest: [RF matching/switch capture](#rf-matching-and-switch-checkpoint--2026-10-08).

Follow-up: the [TCXO clock checkpoint](#tcxo-clock-checkpoint--2026-10-08) below
adds the clock circuit and its local routing. The original regulator review is
retained as history.

**Engineering draft. Do not fabricate or power.** This step corrects the
core regulator circuit and initial component placement. It does not complete
or qualify the LoRa radio. No new copper has been routed.

## Implemented

- L12, **MLZ2012M150WT000**, 15 µH ±20%, connects U4.9 `SX_DCC_SW`
  to U4.7 `SX_VREG`. This is a shielded 2.0 × 1.25 × 1.25 mm part
  listed in Semtech's recommended-inductor table. KiCad's part-specific
  `L_TDK_MLZ2012_h1.25mm` footprint is used.
- C9 changes from the incorrect 100 nF to **470 nF ±10% X5R 10 V**,
  **GRM155R61A474KE15D**, between VREG and ground (Semtech C17).
- C8 receives an exact **GRM155R71C104KA88D** specification and moves
  closer to VBAT, pin 10. C75 and C76 use the same 100 nF ±10% X7R 16 V
  capacitor for local VDD_IN, pin 1, and VBAT_IO, pin 11, bypass.
- VDD_IN, VBAT and VBAT_IO stay on +3V3. VREG is never tied to +3V3.
  The SX1262 PA does not draw its transmit supply through L12.
- U4, the antenna connector and all unrelated placements remain unchanged.
  All 792 existing copper items are preserved, as are 217 old footprints;
  only C8 and C9 move. Three footprints are added.

TDK specifies 1.235 Ω maximum DCR and a 120 mA inductance-based rating
(at **50% inductance reduction**, not a continuous-current guarantee of
nominal inductance). Semtech's table lists 40 MHz resonance for this type;
verify impedance/current behavior in the final layout. The lower-DCR
MLZ2012N150L alternative was not selected: its 90 mA inductance rating is
below the datasheet's general 100 mA selection criterion, despite appearing
in that same recommended table.

Firmware must select `SetRegulatorMode(0x01)` in `STDBY_RC` after hardware
qualification. This document does not implement or validate that firmware.
Measure effective C9 capacitance, regulator startup, ripple, current and
radio sensitivity on the completed board. Nominal 3.3 V alone does not
prove +22 dBm across rail tolerance, load droop and temperature.

## Validation

- 218 schematic components; 222 board footprints including four mounts.
- 1,957 artifact-integrity assertions pass.
- 30 independent native-netlist power-contract checks pass. Four mutations
  (wrong inductor destination, grounded capacitor error, PA input on VREG,
  and the old 100 nF C9 value) are correctly rejected.
- Native schematic/PCB parity: **0 findings**.
- No new courtyard overlap, short, clearance or silkscreen findings.
- Native ERC: **30 findings** (24 isolated labels and six undriven pins).
- DRC: the same **four USB1 hole-clearance findings**.
- **491 unconnected items**; the added parts require routing.
- The existing CC1101 and local power continuity checks remain required.

The rebuild tool stages into `/tmp/handset-sx1262-power`; it never overwrites
an installed update. Source hashes and a full CAD backup guard installation.
`generated/sx1262-power-update.json` records the backup and preservation
counts. `generated/sx1262-power-bom.csv` is this step's subset, not a complete
manufacturing BOM. `check_handset_sx1262_power.py` reads native KiCad XML,
independently of the circuit generator.

## Remaining LoRa work

1. Qualify the captured TCXO clock below: maximum output amplitude, DIO3
   supply behavior, startup timing and temperature drift remain open.
2. Complete PA choke/bypass, RF switch, matching/filter and antenna feed.
   C10 remains provisional, and J20 is not connected to a working frontend.
3. Route against a frozen stackup, with local returns and thermal vias;
   validate conducted RF, antenna matching and coexistence in the case.

At the original regulator checkpoint, the **Johanson 0900FM15K0039001E** 2.0 × 1.25 mm integrated matching/filter
is a researched candidate for 862–928 MHz, not an installed component.
Its reference still needs an external PA choke, PA bypass, RF switch and
antenna DC block. **BGS12WN6** is a switch candidate; ordering suffix/package,
truth table and land pattern must be verified before capture. The old
BGS12SN6 should not be copied blindly. The reference's 0.2 mm ground-via
layout also needs reconciliation with this board's fabrication rules.

## Manufacturer sources

- [Semtech SX1261/2 datasheet rev 1.2](https://files.waveshare.com/wiki/SX1262-XXXM-LoRaWAN-GNSS-HAT/DS_SX1261-2_V1.2.pdf),
  manufacturer-authored copy hosted by Waveshare: §§5.1.3–5.1.5, Table 5-3,
  and Fig. 14-2. Regulator topology, inductor recommendation and 470 nF bypass.
- [TDK MLZ2012M150WT000](https://product.tdk.com/en/search/inductor/inductor/smd/info?part_no=MLZ2012M150WT000):
  production status, dimensions, DCR and rated-current definitions.
- [TDK MLZ2012 catalog](https://product.tdk.com/info/en/catalog/datasheets/inductor_commercial_decoupling_mlz2012_en.pdf).
- [Murata C9 specification](https://search.murata.co.jp/Ceramy/image/img/A01X/G101/ENG/GRM155R61A474KE15-01A.pdf).
- [Semtech AN1200.40](https://cdn-reichelt.de/documents/datenblatt/A200/SX1262REFERENCE.pdf),
  manufacturer-authored distributor copy: TCXO reference and thermal-drift discussion.
- [Johanson AN101](https://www.johansontechnology.com/docs/4476/Johanson_AN101.pdf)
  and [IPD datasheet](https://www.johansontechnology.com/datasheets/0900FM15K0039/0900FM15K0039.pdf):
  compact frontend candidate and remaining external components.

## TCXO clock checkpoint — 2026-10-08

The clock circuit and local copper are now present. The PA feed, matching/filter,
RF switch, antenna path and remaining radio power/ground are still incomplete.
This does not release the radio or handset for fabrication.

| Ref | Selected part | Connection |
| --- | --- | --- |
| Y3 | ECS-TXO-32CSMV-320-AN-TR | DIO3-powered 32 MHz clipped-sine TCXO |
| R90 | RC0402FR-07220RL, 220 Ω 1% | Series clock resistor |
| C94 | GRM155R71C104KA88D, 100 nF | TCXO supply bypass |
| C95 | GRM1555C1H100JA01D, 10 pF C0G | Series coupling into XTA |

[ECS’s product page](https://ecsxtal.com/products/oscillators/surface-mount-oscillators/ecs-txo-32csmv-320-an-tr/)
lists the selected 32 MHz AN option. Its
[series datasheet](https://ecsxtal.com/store/pdf/ECS-TXO-32CSMV.pdf)
specifies a 1.7–3.465 V supply, 2.5 mA maximum consumption at this frequency,
2 ms maximum startup and 0.8 Vpp **minimum** output. The 0.5 ppm temperature
option is not total frequency accuracy: initial tolerance, aging and other
terms still apply. The audited footprint follows its 1.4 × 1.2 mm lands on
2.2 × 1.6 mm centers; pins 1 and 2 are both ground, 3 is output, 4 is supply.
The older Abracon ASVTX/ASTX-13 datasheet is marked EOL and was not selected.

Semtech DS rev 1.2 §4.1.4 specifies the 220 Ω / 10 pF series network and an open
XTB. DIO3 is reserved for the regulated TCXO supply. The specialized U4 symbol
models this selected supply function; other pin functions are retained.
The proposed setting is 1.8 V (`tcxoVoltage=0x02`) with a provisional 5 ms delay
(`0x000140` at 15.625 µs/tick, §13.3.6). VBAT must exceed the programmed voltage
by 200 mV. These settings require target integration and measurement.

**Open qualification:** Semtech requires TCXO output no greater than 1.2 Vpp,
but ECS’s series sheet supplies no maximum. Obtain a supplier guarantee or
appropriate measurement evidence before approving this interface. Confirm
loaded startup, DIO3 ramp/current, temperature drift, phase noise and radio
sensitivity; the series RC network alone is not proof of compliance.

The routed clock path is 6.789 mm on B.Cu with no signal vias. Two local inner
GND extensions provide its return; 228 sampled corridor points pass. All 14
required physical pads pass continuity. Five netlist mutations and five copper
regression cases detect wrong wiring, capacitance, open pads and a missing
reference plane. Existing component locations and all 9,238 previous copper
items remain intact; all 601 previous connected pad groups remain connected.
Only U12’s reference text moves to B.Fab to clear the new lands.

Native DRC/parity are zero. The three former isolated clock labels are resolved:
ERC falls from 30 to 27. There are 265 components, 2,560 integrity assertions
and 237 remaining unconnected items. Evidence is in
`generated/sx1262-clock-update.json`, `sx1262-clock-checks.json`,
`sx1262-clock-tests.json` and the clock BOM subset. The source checkpoint is
archived at `archive/handset-before-sx1262-clock/7d4b34c23603/` in the repository
root. The manufacturing gate retains clock qualification as an explicit blocker.

## Regulator routing checkpoint — 2026-10-08

The local DC-DC switching and VREG paths are routed on B.Cu without vias.
L12 rotates 180 degrees in place so its switching terminal faces U4.9;
its VREG terminal joins U4.7 and C9.1. C9.2 returns through a new ground
via into the existing inner return. U4.8 and the exposed pad U4.25 join
the established U4.5 ground connection. This establishes electrical
continuity; it does not qualify the final thermal or switching layout.

Fifteen copper items are added. All 9,265 previous tracks/vias and all
602 previous connected pad groups are preserved; L12 is the only rotated
footprint. Independent checks cover the three net groups, back-layer-only
regulator routing, short trace limits and six deliberately disconnected
pads. The existing clock continuity and reference-plane checks still pass.
Native DRC and schematic parity remain zero; open connections fall from
237 to 231. ERC remains at 27 findings.

Evidence: `generated/sx1262-regulator-routing.json` and
`generated/sx1262-regulator-checks.json`. The previous board and placement
are archived at `archive/handset-before-sx1262-regulator/e36b11dc7446/`.
Both the board-check script and manufacturing gate enforce this contract.

**Still open:** U4 input supply/bypass distribution, remaining ground pins,
thermal ground stitching, PA feed and RF frontend. Review loop return
geometry in the completed layout and measure regulator startup/ripple and
RF performance. The TCXO qualification requirements above still apply.
This checkpoint does not release fabrication or authorize power-up.

## Input supply routing checkpoint — 2026-10-08

U4.1 (VDD_IN), U4.10 (VBAT), U4.11 (VBAT_IO), C8, C75 and C76
are connected to the established +3V3 and ground networks. U4.2 and U4.20
join the already routed ground pins and exposed pad. C75 rotates 180 degrees
in place; all other footprint geometry stays unchanged. A front-layer supply
bridge clears the back-layer XTA clock trace.

The new main-rail feed is 0.5 mm wide and 76.695 mm long with ten layer
transitions. The local front-layer bridges are 0.3 mm wide, with 0.2 mm IC
pad escapes. These dimensions describe the implemented copper, not a supply
integrity approval. Review the feed/via impedance, VDD_IN bypass loop and
return geometry; measure rail droop and noise under transmit load before
release. Thermal stitching/spreading and the PA/RF frontend remain open.

All 16 physical pads in the input-supply/ground contract pass, including
continuity to established U1 rail/ground anchors. Six deliberately opened
pads are rejected, alongside the installed-board positive test. Existing
clock continuity/reference coverage and regulator checks pass. All 9,280
previous copper items and 596 previous connected pad groups are preserved;
191 copper items are added. Native DRC/parity are zero; open connections fall
from 231 to 220. The manufacturing gate enforces the new continuity contract
and retains the outstanding engineering blockers.

Evidence: `generated/sx1262-supply-routing.json`, `sx1262-supply-checks.json`
and `sx1262-supply-tests.json`. The previous board and placement are archived
at `archive/handset-before-sx1262-supply/eaa92c47fb4f/`. This checkpoint does
not release fabrication or power-up; the RF and TCXO qualification requirements
above still apply.

## RF matching and switch checkpoint — 2026-10-08

Ten components now capture the matching/filter and TX/RX switch topology.
**This is schematic capture with provisional front-side placement, not a
routed RF frontend.** The clock area occupies space near U4's RF pins;
final placement must be revised to follow the manufacturer layout geometry.
No existing footprint or copper is moved at this checkpoint.

| Ref | Selected part | Function |
| --- | --- | --- |
| U36 | 0900FM15K0039001E | Johanson integrated SX1262 TX/RX matching/filter |
| U37 | BGS12WN6E6327XTSA1 | Infineon SPDT, PG-TSNP-6-10 |
| R91/R92 | RC0402FR-07100RL, 100 Ω 1% | Control/supply series filters |
| C96/C97 | GRM155R71H102KA01D, 1 nF 10% X7R 50 V | Control/supply shunt filters |
| C98/C99/C100 | GRM1555C1H101JA01D, 100 pF 5% C0G 50 V | Antenna/TX/RX DC blocks |
| R93 | RC0402FR-07100KL, 100 kΩ 1% | Default-RX pull-down |

The [Johanson datasheet, revision 3.0](https://www.johansontechnology.com/docs/4856/IPD-0900FM15K0039001E_w8h4xck.pdf)
identifies the part and terminal mapping. Its
[AN101 reference](https://www.johansontechnology.com/docs/4476/Johanson_AN101.pdf)
connects U4 RFO/RFI_N/RFI_P to the matching device, with separate TX and RX
outputs feeding an SPDT. The PA choke and bypass remain external. RF trace
geometry and ground-via placement are part of the filter implementation;
component presence alone does not establish harmonic performance.

The [Infineon product page](https://www.infineon.com/part/BGS12WN6)
identifies the selected order code/package. The
[revision 2.9 datasheet](https://www.infineon.com/assets/row/public/documents/24/49/infineon-bgs12wn6-datasheet-en.pdf)
maps pins 1/2/3/4/5/6 to RF2/GND/RF1/VDD/RFIN/CTRL. Low selects RF1 (RX),
high selects RF2 (TX). DIO2 drives CTRL through R91; R93 supplies the default
low state. R92 feeds the switch from +3V3, independently of DIO3's TCXO rail.
The schematic power flag identifies that passive supply feed, not an
independent source. Firmware must select DIO2 RF-switch control and allow
switch power-up/settling before transmitting.

Infineon requires zero DC on all RF ports. All three ports therefore have
explicit series capacitors. The 100 pF value is an engineering starting
choice, reusing the specified C66 family, rather than a copied reference
value or a validated RF match. Measure DC isolation, loss and return loss in
the completed circuit. The control/supply 1 nF part is documented by
[Murata](https://www.murata.com/en-sg/products/productdetail?partno=GRM155R71H102KA01D).

Independent checks enforce exact net memberships, order codes, values and
both IC land patterns. Eight mutations catch swapped TX/RX ports, bypassed
DC blocks, swapped balanced input, wrong supply/ground and a short in place
of the RF capacitor. Native DRC/parity are zero; the SX1262 sheet has no ERC
findings. Overall ERC falls from 27 to 20. There are 275 components and
2,634 passing integrity assertions. Open connections rise from 220 to 245
because the new circuitry is deliberately still unrouted.

All 9,471 prior copper items, 269 prior footprints and 585 prior connected
pad groups are preserved. Evidence is in `generated/sx1262-rf-update.json`,
`sx1262-rf-checks.json` and `sx1262-rf-bom.csv`; the previous CAD is archived
at `archive/handset-before-sx1262-rf/f178a595df44/`.

**Remaining:** select/capture the PA choke and final VR_PA bypass values;
finish RF placement, routing and ground vias; qualify switch timing, DC
isolation, conducted power/harmonics, receive sensitivity, thermal behavior,
clock and antenna coexistence. The release gate retains these requirements.
No fabrication or power-up release is implied.

## PA choke and bypass checkpoint — 2026-10-08

The PA feed is now captured: `U4.24 (VR_PA)` feeds L13, whose other end
joins `U4.23 (RFO)` and `U36.1`. C10 and C101 connect from VR_PA to ground,
on the supply side of the choke. This rail remains separate from the core
VREG output and +3V3. No extra power flag is needed for U4's PA output.

| Ref | Selected part | Value / function |
| --- | --- | --- |
| L13 | LQW15AN47NG80D | 47 nH ±2%, 0402 wirewound PA choke |
| C10 | GRM155R71E473KA88D | 47 nF ±10%, X7R, 25 V; replaces provisional 100 nF |
| C101 | C1005C0G1H470J050BA | 47 pF ±5%, C0G, 50 V; high-frequency PA bypass |

The values follow the manufacturer's
[RAK4270 schematic](https://downloads.rakwireless.com/LoRa/RAK4270/Hardware-Specification/RAK4270_Schematic.pdf):
L1 is 47 nH and the VR_PA shunts C32/C33 are 47 nF/47 pF.
[Johanson AN101](https://www.johansontechnology.com/docs/4476/Johanson_AN101.pdf)
also shows the external PA choke and two bypass capacitors around its IPD.
**This combines a documented SX1262 PA baseline with the Johanson topology;
it is not a qualified reference BOM/layout for this assembled frontend.**
The chosen supplier parts are engineering selections; the RAK schematic
establishes nominal values, not these exact order codes.

[Murata's component list](https://www.murata.com/-/media/webrenewal/tool/library/common-pdf/static-model/component-list-ind-s-2602.ashx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)
identifies LQW15AN47NG80. Its
[manufacturer-authored data sheet, mirrored by Arrow](https://static6.arrow.com/aropdfconversion/dad745742b96a55e3970cd4197a24f0c7dc60c0/lqw15an47ng80.pdf)
lists the D tape suffix, 440 mA temperature-rise rating and 0.648 ohm maximum
DC resistance. These are component limits, not PA current/thermal approval.
C10's value/dielectric/rating are recorded in
[Murata's MLCC list](https://www.murata.com/-/media/webrenewal/tool/library/common-pdf/dynamic-model/component-list-d-mlcc-2506.ashx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).
[TDK's C101 product page](https://product.tdk.com/en/search/capacitor/ceramic/mlcc/info?part_no=C1005C0G1H470J050BA)
identifies the selected 0402 part. Confirm procurement status and assembly
land patterns when the BOM is frozen.

C10 keeps its previous back-side position. L13/C101 have provisional
front-side positions beside the RF circuit; no PA copper is added. Final
layout must bring the choke/bypass next to U4's RF pins, with short ground
returns and the required RF ground geometry. The existing TCXO occupies
nearby back-side space, so resolve that placement conflict before routing.
Do not route this provisional arrangement as if it were the final RF layout.

The independent PA checker enforces exact VR_PA/RFO membership, bypass
grounds, values, MPNs and PCB/netlist agreement. Eleven mutations reject
wrong supply rails, the core-switch node, bypasses on the RFO side, a wrong
IPD connection, the old C10 value, wrong choke value/package and missing MPN.
Both the integrity gate and manufacturing gate enforce the PA contract;
qualification remains an explicit manufacturing blocker.

There are 277 components and 2,644 passing integrity assertions. Native DRC,
schematic parity and placement findings are zero; overall ERC remains 20
and the SX1262 sheet is clear. Open connections increase from 245 to 249
because the new PA parts are still unrouted. All 9,471 existing copper items,
279 existing footprint geometries and 623 existing connected pad groups are
preserved. Only C10's value/MPN changes among existing PCB components.

Evidence: `generated/sx1262-pa-update.json`, `sx1262-pa-checks.json` and
`sx1262-pa-bom.csv`. The previous CAD is archived at
`archive/handset-before-sx1262-pa/ba78918224a3/`.

**Next:** resolve RF/TCXO placement, route PA and RF paths against the chosen
stackup, complete ground/thermal geometry, and clear remaining circuit and
routing blockers. PA current, supply droop, RF matching, power/harmonics and
receive sensitivity require qualification. Fabrication and power-up remain
unreleased.

## Local PA/RF routing checkpoint — 2026-10-09

The TCXO has moved west of U4 to clear its RF pins. L13, C10, C101 and U36
are now on the back layer beside U4. The PA feed, bypass returns and
RFO/RFI_N/RFI_P connections to U36 are routed. **U36 ground lands and the
downstream switch/antenna paths are still incomplete; this is not an
operational RF frontend or a fabrication release.**

Y3, R90 and C94 move together while C95 stays fixed. The clock signal path
remains entirely on B.Cu without signal vias: 8.092 mm, below the unchanged
10 mm check limit. All 14 clock pads and 276 In2 ground-reference samples
pass. DIO3 power now crosses the local area on In1.Cu; it remains isolated
from the main supply. Two local ground-zone extensions retain the adjacent
reference plane. TCXO amplitude/startup/supply qualification is unchanged.

The unrouted IR connector J25 moves from (103,35) to (103,33.7) mm; R49 and
C44 move to (101,38.4) and (98.8,38.6) mm. These changes clear the oscillator
courtyard while retaining connector pinout and nets. Review case-harness
reach and assembly access before mechanical release. R10 moves to
(116.8,37) mm. The U4 VDD_IN escape/via is rerouted locally to clear the PA
choke; input-supply continuity still passes against the established anchors.
All other footprint geometries stay unchanged.

| Routed net | Total trace length | Geometry |
| --- | --- | --- |
| SX_VR_PA | 4.2094 mm | Local B.Cu choke/bypass feed, no vias |
| SX_RFO | 4.5287 mm | B.Cu input route including choke branch, no vias |
| SX_RFI_N | 3.0924 mm | B.Cu input fanout, no vias |
| SX_RFI_P | 3.0924 mm | B.Cu input fanout, no vias |

These are sums of CAD trace lengths, not electrical lengths. RFO includes
its PA choke branch. The RF fanouts use 0.2 mm traces with native clearance
checks; the receive routes have equal CAD lengths. **Neither equal length
nor continuity validates RF impedance.** The fanouts are routing candidates
pending adaptation/validation against the selected JLC04161H-7628 stackup.
Do not treat them as approved 50-ohm transmission lines.

The [Johanson layout guidance](https://www.johansontechnology.com/docs/4856/IPD-0900FM15K0039001E_w8h4xck.pdf)
requires transmission-line geometry for the actual PCB material/thickness
and emphasizes ground-via placement for harmonic attenuation. Its reference
shows 0.2 mm ground vias; reconcile that geometry with the current board
rules and fabricator before completing U36 grounds. The relocated U36 is a
layout candidate, not a substitute for this review. Adjacent CC1101/GNSS
parts constrain the downstream switch/antenna placement.

Fourteen local PA/RF contract pads pass continuity, including both bypass
returns to the established ground anchor. All 375 sampled In2 ground
reference points under the RF input traces pass. Nine regression cases
cover the installed board, six isolated pads, a wrong RF layer and a removed
reference plane. The five existing clock regression cases also pass.
The RF footprint checker now accounts for back-side mirroring while keeping
the same terminal positions, dimensions and pin-net requirements.

The change replaces 28 explicitly identified clock/local-supply copper items
and adds 49. All other 9,443 copper items and all 627 previously connected
pad groups are preserved; total copper items are 9,492. The manifest lists
every removed item. Native DRC/parity and placement findings remain zero.
All 2,644 integrity assertions pass; 277 components and 20 ERC findings are
unchanged. Unconnected items fall from 249 to 240.

Evidence: `generated/sx1262-local-rf-routing.json`,
`sx1262-local-rf-checks.json`, `sx1262-local-rf-tests.json`, and refreshed
clock/supply checks. Previous board/placement evidence is archived at
`archive/handset-before-sx1262-local-rf/9a212933222f/`.

**Next:** resolve RF transmission-line and U36 ground-via geometry, then
finish switch/DC-block/antenna placement and copper. Complete thermal,
supply, clock, conducted power/harmonics, sensitivity and coexistence
qualification. The manufacturing gate retains these open requirements.

## RF ground and impedance checkpoint — 2026-10-10

All five U36 ground lands (2, 5, 7, 9, 10) now connect to local B.Cu ground
and established ground planes. Each has a nearby through via: 0.45 mm land,
0.2 mm hole, 0.125 mm nominal annular width, explicitly tented on both faces.
The longest pad-center to nearest-via-center distance is 0.6 mm. No component
moves in this checkpoint. Detailed return geometry and harmonic performance
still require validation; this is not an RF performance sign-off.

The [Johanson reference layout](https://www.johansontechnology.com/docs/4856/IPD-0900FM15K0039001E_w8h4xck.pdf)
shows 0.2 mm ground vias and calls out their placement as important to harmonic
attenuation. The implemented five-via/ground-pour arrangement follows those
constraints as a layout candidate, not a claim to reproduce an unavailable
manufacturer CAD file exactly. Confirm the intended hole definition and
final return geometry with the manufacturer/fabricator before release.

[JLCPCB's published drilling capabilities](https://jlcpcb.com/capabilities/pcb-capabilities)
list 0.2 mm as the preferred minimum via hole and describe larger via lands
for small-hole processing. The selected 0.45 mm land retains more than the
board's 0.1 mm minimum annulus. The nominal board is still 1.6 mm/four layers;
this change does not introduce blind vias or via-in-pad. Hole tolerance,
plating, tenting and assembly acceptance remain fabricator review items.

KiCad's global floors are now 0.45 mm via diameter and 0.2 mm hole so the RF
vias can pass. **The new `generated/handset.kicad_dru` is required:** general
rules retain the prior 0.5 mm via / 0.3 mm hole minimums. Only GND vias fully
enclosed in the named `SX1262 RF grounding` area receive the exact
0.45/0.2 mm exception. Copper/hole clearances and minimum annular width are
unchanged. The checker rejects missing or weakened rule files. Native DRC
mutation cases confirm that a small signal via in the area and a small GND
via outside it are rejected, as is a larger drill within the RF exception.

The nominal drill edges stay at least 0.15 mm outside all matching-device
lands; a regression case rejects a drill moved onto a ground land. Fabricator
drill-position and finished-hole tolerances still require review.

The old 14.1 mm front-layer 3V3 segment crossed the new via locations. It is
replaced by a 17.4154 mm path around the RF return area at the same 0.5 mm
width. Input-supply continuity remains intact. Qualify the additional feed
length and its supply impedance under transmit load; continuity and native
clearance do not establish current/thermal performance.

### Downstream 50-ohm routing target

The selected [JLC04161H-7628 stackup](https://jlcpcb.com/impedance) retains
0.2104 mm outer dielectric and 35 micrometre outer copper. A reproducible
2-D finite-volume quasi-TEM screen uses nominal Dk 4.4 and an approximate
solder-mask model, consistent with the existing USB screening approach.

| Model at 0.34 mm trace width | Estimated single-ended impedance |
| --- | --- |
| 5 micrometre grid, 4 × 1.5 mm domain | 49.805 ohms |
| 2.5 micrometre grid, same domain | 49.899 ohms |
| 5 micrometre grid, 6 × 2.25 mm domain | 50.216 ohms |

Grid refinement changes the result by 0.094 ohm; expanding the finite
boundary changes it by 0.411 ohm. These are numerical sensitivity checks,
not material-tolerance or impedance-coupon evidence. The same isolated-line
model gives 63.755 ohms for a 0.2 mm trace, reinforcing that the existing
short IC fanouts cannot simply be described as verified 50-ohm routing.
That isolated-line result does not model the coupled RX pair or the actual
complex chip-port impedances.

A new **RF 50 ohm target** net class records a 0.34 mm routing width only for
SX_TX_MATCH, SX_TX_AC, SX_RX_MATCH, SX_RX_AC, SX_ANT_AC and LORA_RF_50R.
The radio's RFO/RFI_N/RFI_P fanouts remain outside this class. The model
assumes a uniform isolated line above a continuous reference plane; pads,
bends, near coplanar copper, vias, device matching and short transitions
need separate review. No existing signal copper is widened at this checkpoint.
The downstream switch/antenna layout must implement and validate these
transitions rather than blindly apply the nominal trunk width everywhere.

Evidence: `generated/rf-impedance-estimate.json` records inputs, results,
limitations and the estimator hash. Reproduce with
`scripts/estimate_handset_rf_impedance.py --width .34`, add `--step .0025`
for refinement or `--span 3 --height 2.25` for the expanded domain.
Fabricator field-solver/coupon evidence and assembled RF qualification remain
required; no order or supplier approval is implied.

### Verification and remaining work

Thirteen regression cases pass: the installed board, five isolated ground
lands, missing tenting, drill overlap with a land, three native drill-rule mutations, missing rules
and weakened general limits. The full project integrity checks pass with
2,644 assertions, 277 components, zero native DRC/parity/placement findings
and unchanged 20 ERC findings. Unconnected items fall from 240 to 235.

All 281 footprint geometries, 9,491 unreplaced copper items and 618 previously
connected pad groups are preserved. One supply segment is replaced and 15
copper items are added, for 9,506 total. Evidence is in
`generated/sx1262-rf-ground-routing.json`, `sx1262-rf-ground-checks.json`
and `sx1262-rf-ground-tests.json`; the previous board/project is archived at
`archive/handset-before-sx1262-rf-ground/ca67f1aee4ed/`.

**Next:** finish RF switch, DC-block and antenna placement/copper, then review
all RF transitions and ground geometry against the reference design. Keep
fabrication blocked pending RF/supply/clock/thermal qualification and the
other recorded electrical/mechanical blockers.

## Switched RF routing checkpoint — 2026-10-10

**CAD copper is captured; not fabrication or RF performance approval.** The
matching device now connects through C99/C100 to the TX/RX switch, then through
C98 to J20. DIO2 control, its RC filter and default-RX pull-down, filtered +3V3
switch supply, bypass returns and both antenna-connector ground pads are routed.
No schematic values, pin assignments or part selections change.

U37 and its eight passives move within the available front-layer area. The
matching device and connector remain on the back. Three tented 0.5 mm land /
0.3 mm drill through vias transfer TX, RX and antenna signals between faces;
the ordinary drill rules apply. The matching-device 0.45/0.2 mm GND exception
remains limited to its previously checked area. GNSS and existing USB circuitry
retain their placement and copper.

The [Infineon BGS12WN6 datasheet, revision 2.9](https://www.infineon.com/assets/row/public/documents/24/49/infineon-bgs12wn6-datasheet-en.pdf)
requires zero DC on the RF ports and identifies CTRL low with RX/RF1, high with
TX/RF2. All three 100 pF DC blocks and the default-low control bias remain in
that topology. The [Johanson reference](https://www.johansontechnology.com/docs/4856/IPD-0900FM15K0039001E_w8h4xck.pdf)
still governs matching-device ground and port-layout review; the changed layer
transitions require separate RF analysis and measurement.

### Geometry and reference checks

| Net | Planar trace length | Signal vias |
| --- | ---: | ---: |
| SX_TX_MATCH | 3.5105 mm | 1 |
| SX_TX_AC | 2.2586 mm | 0 |
| SX_RX_MATCH | 1.9524 mm | 1 |
| SX_RX_AC | 2.5700 mm | 0 |
| SX_ANT_AC | 4.3875 mm | 0 |
| LORA_RF_50R | 6.3381 mm | 1 |

Lengths exclude component internals and via barrels. Trunks use the previously
screened 0.34 mm width, with 0.2 mm matching-device escapes and 0.15 mm local
switch neck-downs. Neither the narrow sections nor the three transitions are
qualified 50-ohm geometry. Bends, pads, coupling, loss and parasitics remain
part of RF validation; the uniform-line screen does not cover them.

The checker samples the adjacent In1 ground under front traces and In2 under
back traces every 0.1 mm, at the center and 0.1 mm beyond each trace edge.
All 753 samples pass: 103 points inside the explicitly bounded same-net
signal-via antipads are exempt, and no other reference gaps remain. Filled
return copper extends the existing reference planes. The nearest connected
ground vias are 0.6500, 0.8732 and 0.8062 mm from the TX, RX and antenna
transitions respectively. The 1.25 mm checker bound is a layout guard, not an
RF return-inductance qualification. Nominal signal drill edges remain at least
0.15 mm outside numbered lands; actual hole and registration tolerances still
need fabricator review.

The main 0.5 mm front-layer supply feed detours around the RF area. Its
previous 17.4154 mm path is now 20.1225 mm; the width is unchanged and a
0.25 mm branch feeds R92. Confirm the extra feed impedance and thermal behavior
under load. The C8 ground via moves from (115.6, 34.1) to (115.6, 33.6) mm,
shortening its ground stub to clear the DIO2 escape. Supply, clock, local PA/RF
and matching-device ground checks continue to pass.

### Evidence and remaining work

Seventeen regression cases cover the installed layout, twelve disconnected
pad controls, missing signal-via tenting, removed reference planes, missing
transition ground returns and an unreviewed trace width. The full project
checks retain 2,644 passing integrity assertions, 277 schematic components,
zero native DRC/parity/placement findings and 20 existing ERC findings.
Unconnected items fall from **235 to 216**.

All 613 previously connected pad groups, 272 unmoved footprints and 9,501
unreplaced copper items are preserved. Five copper items are replaced and 86
are added, giving 9,587 total. The previous board, project/rules, placement and
verification files are archived at
`archive/handset-before-sx1262-switch/6e88163d5783/`. Current evidence:
`generated/sx1262-switch-routing.json`, `sx1262-switch-checks.json` and
`sx1262-switch-tests.json`. Both the full PCB gate and manufacturing release
check run the new live copper checks; RF qualification still blocks release.

**Next fabrication work:** place and route the CC1101 clock and local supply
network, then its RF matching/filter and antenna path. Complete remaining
routing and ERC corrections, mechanical/BOM review and fabricator DFM before
prototype release. The SX1262 still needs stackup/transition review, switch
DC and timing checks, conducted power/harmonics, sensitivity, antenna matching,
coexistence and clock/supply/thermal qualification on assembled hardware.

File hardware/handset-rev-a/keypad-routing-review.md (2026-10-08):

# Keypad matrix routing and commissioning driver

2026-10-07. **Engineering checkpoint; fabrication release remains blocked.**

Follow-up: the [ESP32 bring-up application](../../firmware/bringup/README.md) now
integrates this driver and cross-builds for the target. Hardware testing remains
open; the layout results below are unchanged.

All eight matrix branches now connect U2 to the existing 16-switch matrix.
All 64 physical switch contacts and eight controller pins pass independent
connectivity checks. No parts, existing tracks/vias, stackup or design rules
were changed. New fanout uses ordinary 0.5 mm through vias with 0.3 mm drills.
New inner-layer segments avoid the protected USB reference area.

| Function | U2 pin | Switches |
| --- | --- | --- |
| ROW0 | 8 | SW1–SW4, both contacts numbered 1 |
| ROW1 | 7 | SW5–SW8, both contacts numbered 1 |
| ROW2 | 6 | SW9–SW12, both contacts numbered 1 |
| ROW3 | 5 | SW13–SW16, both contacts numbered 1 |
| COL0 | 9 | SW1, SW5, SW9, SW13, both contacts numbered 2 |
| COL1 | 10 | SW2, SW6, SW10, SW14, both contacts numbered 2 |
| COL2 | 11 | SW3, SW7, SW11, SW15, both contacts numbered 2 |
| COL3 | 12 | SW4, SW8, SW12, SW16, both contacts numbered 2 |

`generated/keypad-routing.json` records board hashes, preserved copper,
fanout geometry and route evidence. Before installation, all 621 previously
connected pad groups were compared with the staged board; none lost a connection.
The pre-change board/rules/reports are retained under
`archive/handset-before-keypad-routing/24e35cd12f1f/` at the repository root.

The saved checkpoint has zero native DRC violations and zero schematic parity
findings. Unconnected items drop from 258 to 250. There are still 30 ERC findings
and 11 open engineering blocker groups. The main check script runs the eight
matrix groups, five routing regression cases and the host firmware tests,
alongside the prior core, USB, display, expansion and power checks.

The [keypad driver](../../firmware/keypad/README.md) decodes all 16 switches,
checks configuration, bounds FIFO draining and invalidates application key
state after overflow, transfer failure or unexpected events. Its 12 host-test
scenarios do not establish operation on the ESP32 or physical handset.
It does not program GPIO outputs or enable the backlight, modem or media rails.
Target HAL/application integration and shared U2 GPIO sequencing remain open.

After overall hardware approval, commission each switch individually with
press and release logging, then measure IRQ/service timing and test reset,
disconnection and overflow recovery. Check required multi-key combinations:
the current matrix has no per-key diodes and does not establish ghost-free
arbitrary rollover. Key legends, user-interface actions, enclosure actuation,
EMI and switch debounce behavior still require qualification.

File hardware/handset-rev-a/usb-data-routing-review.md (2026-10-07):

# USB data routing — 2026-10-07

USB-C data now connects through U17 protection and R88/R89 termination to the
ESP32-S3. Both cable orientations pass physical continuity, polarity, planar
length and reference-copper checks. Native DRC and schematic parity remain zero;
remaining unconnected items fall from 285 to 279. This is a completed CAD routing
step. USB electrical qualification and fabrication release remain open.

## Circuit and placement

| Signal | Connector contacts | U17 external pass-through | Series resistor | ESP32 module |
|---|---|---|---|---|
| D− | A7, B7 | 10 ↔ 1 | R88, 22 Ω | U1.13 / GPIO19 |
| D+ | A6, B6 | 9 ↔ 2 | R89, 22 Ω | U1.14 / GPIO20 |

The TI protection channels are used with the polarity shown above; the pin names
D1+/D1− in its symbol do not change the table's actual net assignments. Pins 9/10
are **not internally connected** to 2/1: explicit PCB traces join them. NC lands
6/7 remain unused. TI documents external flow-through routing in its
[TPDxE05U06 datasheet, layout section](https://www.ti.com/lit/ds/symlink/tpd4e05u06.pdf).

R88/R89 are [Yageo RC0402FR-0722RL](https://www.yageogroup.com/component-documentation/download/specsheet/RC0402FR-0722RL),
22 Ω, 1%, 0402. This is an initial termination value, following
[Espressif's USB schematic guidance](https://docs.espressif.com/projects/esp-hardware-design-guidelines/en/latest/esp32s3/schematic-checklist.html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).
Their board-side paths to the module pads are each 6.03 mm. No shunt capacitors
are populated or claimed as qualified; evaluate whether tuning footprints are
needed during the remaining signal-integrity review. All existing footprint
positions, connector holes and land geometry are preserved.

## Stackup and routing evidence

The selected **design target** is JLCPCB JLC04161H-7628, nominal 1.6 mm, four
layers: 35 µm outer copper, 15.2 µm inner copper, 0.2104 mm 7628 outer dielectrics,
and a 1.065 mm core. These published rounded copper/dielectric dimensions total
1.5862 mm; the nominal board setting stays 1.6 mm. The manufacturer must confirm
finished thickness and tolerances. This is not an approved order or fabrication
stackup. [Published stackup and material inputs](https://jlcpcb.com/impedance).

Native KiCad stackup data and the `USB data` net class record the target. The
uniform paired trunk uses 0.29 mm width and 0.21 mm edge spacing. The local
finite-volume quasi-TEM screening gives 89.55 Ω at a 5 µm grid and 89.83 Ω at a
2.5 µm grid. The 0.28 Ω refinement difference checks numerical sensitivity; it
does not validate the material model. The model excludes pad/via discontinuities,
uncoupled tuning, etch tolerances, glass weave and module internals. Obtain a
fabricator field-solver result and impedance coupon for the 90 Ω ±10% target.
See [the input/output record](generated/usb-impedance-estimate.json) and
[the reproducible estimator](../../scripts/estimate_handset_usb_impedance.py).

Both orientations have approximately 42.638 mm of planar connector-to-module
copper, excluding resistor bodies, via barrels and module-internal routing.
Nominal CAD mismatch is under 0.01 mm; the check limit is 0.25 mm. Symmetric
connector branches give the same path lengths in either cable orientation.
There are three through-via transitions per leg. The route includes uncoupled
fanout and length tuning, so the uniform-trunk estimate is **not** a claim that
the entire path has controlled impedance. Review those sections and validate USB
electrical behavior before closing the USB engineering blocker.

Ground pours on In1/In2 provide the adjacent reference for the outer signal
layers. The checker samples the trace center and both edges plus a 0.10 mm
margin, at intervals no larger than 0.10 mm. All 2,928 samples pass outside
recorded local antipad exemptions within 0.65 mm of a signal via. Six added
return vias are independently checked for connection to board ground; each
signal transition has at least two connected ground vias within 2.5 mm.
This is a geometric return-path check, not an ESD or high-frequency measurement.
The design targets follow [Espressif's USB layout guidance](https://docs.espressif.com/projects/esp-hardware-design-guidelines/en/latest/esp32s3/pcb-layout-design.html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).

## Power preservation and validation

Two existing VBUS segments were changed to make room for the connector data
fanout. The local bridge now uses In1 with a new through via at (128.5, 56) mm;
its route avoids the front USB reference corridor. All other 7,858 original
track/via items are preserved exactly. The new inner-layer power copper needs
current/voltage-drop and thermal review against the selected 15.2 µm copper;
continuity alone does not qualify it. All 118 existing local power-entry pad
connections still pass. No clearance rule was relaxed and no exclusion added.

Seven regression cases cover the installed board, a removed external ESD
bridge, swapped host polarity, missing reference fill, missing transition
return, wrong termination, and added skew with continuity retained. The full
project check also verifies previous power, display, backlight, expansion and
radio-power work. The release gate independently reruns the USB geometry checks.

- [Actual copper/path/reference report](generated/usb-data-check.json)
- [Regression results](generated/usb-data-tests.json)
- [Change manifest](generated/usb-data-update.json) and [added-parts BOM](generated/usb-data-bom.csv)
- [Pre-change source archive](../../archive/handset-before-usb-data/2cb4ad59cd64)

The saved checkpoint has 261 components, 2,537 passing integrity assertions,
zero DRC/parity findings, 30 ERC findings and 279 unconnected items. All eleven
engineering blocker groups stay open. Still obtain USB footprint/stackup DFM,
qualify protection placement and ground returns, source current and VBUS copper,
termination and USB eye behavior, and finish the rest of the board. No fabrication
or power-up release is granted by this routing change.

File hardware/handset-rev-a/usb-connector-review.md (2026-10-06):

# USB4105 ground-land clearance correction — 2026-10-06

The four native USB1 hole-clearance findings are eliminated. Native DRC now
reports zero findings, with zero schematic parity findings and 285 unconnected
items. This completes the nominal CAD clearance correction, not board release.

## Geometry and evidence

The installed footprint is `Handset:USB4105_GroundCornerRelief`. USB4105,
its location/orientation, all locating and shell holes, pad centers, pad
bounding dimensions, nets and all 7,860 track/via items are retained. The
0.25 mm hole-clearance rule and all other board rules are unchanged.

The old round-rectangle ground lands were only 0.1944 mm from the locating
holes. A 0.30 mm chamfer on each hole-facing heel corner gives 0.263302 mm
nominal clearance. A1/B12 and A12/B1 are duplicate electrical pad numbers
on two physical lands; their overlapping shapes are changed together.

The [GCT USB4105 B4 drawing](https://gct.co/files/drawings/usb4105.pdf)
(18 December 2023, sheet 1) supplies the nominal hole and land dimensions.
The contour here is an **engineered modification of the recommended land
pattern**, not an unmodified or manufacturer-approved footprint. The 0.60 ×
1.15 mm land envelope and 0.65 mm locating holes remain intact. Only the
hole-facing corner beneath the connector is relieved; the terminal-facing
part of the land remains. An independent geometry check verifies a continuous
0.45 × 0.75 mm central solder rectangle in each ground land. That rectangle
is a design retention criterion, not a substitute for assembler approval or
a measured solder joint. Nominal CAD clearance does not include a fabricated
hole-registration tolerance analysis.

No connector substitution, drill shrinkage, moved holes, clearance exception
or DRC exclusion is used. The custom library footprint and schematic
assignment agree with the PCB. `prepare_handset_usb_connector.py` stages the
change and refuses to overwrite an installed revision.

## Verification and preservation

- Four regression tests pass: actual geometry, rejection of the original
  corner clearance, rejection of smaller locating holes, and rejection of a
  smaller ground land.
- All 118 local power-entry pad connections pass, including connector power,
  CC and ground. USB D+/D− routing is outside that continuity check.
- The full board check verifies all prior circuits and refreshes native reports
  and previews. The manufacturing release gate independently checks the USB
  land geometry and continues to block release for unfinished work.
- The previous board, rules, schematic sheet and verification reports are in
  [`archive/handset-before-usb-relief/ef24884f9bbb`](../../archive/handset-before-usb-relief/ef24884f9bbb).
- Exact source/final hashes and scope are in
  [generated/usb-connector-update.json](generated/usb-connector-update.json);
  measured clearances are in
  [generated/usb-connector-check.json](generated/usb-connector-check.json).

## Remaining work

Finish USB data routing against the selected stackup and qualify ESD, signal
integrity, source-current behavior and connector fit. Freeze the actual
USB4105 ordering suffix and obtain assembler DFM approval of the modified
land contour and solder process. The rest of the board still has 30 ERC
findings, 285 unconnected items and eleven open engineering blocker groups.
It is not released for fabrication or power-up.

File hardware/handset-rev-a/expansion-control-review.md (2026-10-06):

# Expansion power control and signal isolation — 2026-10-05

The expansion update replaces U14's permanently enabled supply and direct
host signal connections with separately controlled power and signal isolation.
This is an engineering implementation, not fabrication or power-up approval.

## Ground-return revision — 2026-10-05

Local GND pours on In1.Cu and In2.Cu fill previously uncovered areas above
the trackball cutout. Their outlines subtract existing pours, preserving
existing zone geometry and avoiding isolated overlap fragments. Ninety
expansion-added inner-layer ground segments (36.237 mm total) are removed.
Four short B.Cu ground segments (3.985 mm total) reinforce the ESD escapes
and directly join U16 ground pads 3/8. Three segments are 0.30 mm wide; the
U16.3 escape is 0.18 mm to retain clearance from the IRQ via.

All signal routing, all footprint positions and 7,856 retained copper items
are unchanged, including all 4,183 pre-expansion copper items. The final board
has 7,860 copper items. The previous board and reports are in
[`archive/handset-before-expansion-ground/a952add783fb`](../../archive/handset-before-expansion-ground/a952add783fb).
The current geometry/hash and removed segment IDs are recorded in
[generated/expansion-ground-update.json](generated/expansion-ground-update.json).

The [In1 ground preview](generated/previews/expansion-ground-In1.svg) and
[In2 ground preview](generated/previews/expansion-ground-In2.svg) show the
updated fill and remaining signal clearances.

Both ground-return tests and all six expansion regression tests pass. Removing
the new pours in a test copy breaks ESD ground continuity, demonstrating that
the new return does not rely on the removed detours. All previous copper checks
pass. Native DRC retains only the four USB1 hole-clearance findings, with 285
unconnected items and zero schematic parity findings.

This is a geometric/DC improvement, not ESD qualification. TI recommends
short, low-impedance ground returns and protection close to the connector
([TPD4E05U06 datasheet, layout section](https://www.ti.com/lit/ds/symlink/tpd4e05u06.pdf)).
U15 connector distance, remaining signal-created plane slots, current
spreading and transient clamping still require review and measurement. No
new vias are added; the existing J16.8/U14.1/U14.6/U16.1 filled-and-capped
via-in-pad requirements remain open with the assembler.

## Circuit and evidence

U33, TCA9537DGSR, shares the host I2C bus at fixed 7-bit address 0x49.
P0 controls TPS2553 EN, P1 reads its active-low fault, P2 arms the signal path,
and P3 remains an unused input. R83/R84 (4.7 kΩ) pull the two permissions low
when U33 resets to inputs. RESET follows MCU_EN; INT is unused. The routing scope also includes the
existing R1/C1 host reset network and checks the R3/R4 I2C pull-ups. The remaining
ESP32 boot-strap and PSRAM pins are unchanged. C91 provides local bypass.
The [TI TCA9537 datasheet](https://www.ti.com/lit/ds/symlink/tca9537.pdf)
supports the pin map, reset behavior, fixed address and register sequence.
TI names DGS VSSOP; the corresponding KiCad land pattern is
`MSOP-10_3x3mm_P0.5mm`. Independently verify the selected package before release.

U34, SN74CB3Q3245PWR, interrupts all seven accessory signals before the
existing 33 Ω series resistors and port-side ESD arrays. Its eighth channel
is grounded on both sides; pin 1 is NC. C92 bypasses its supply. This is a
bidirectional bus switch, not a voltage translator. Compatible 3.3 V accessories
remain mandatory. The [TI bus-switch datasheet](https://www.ti.com/lit/ds/symlink/sn74cb3q3245.pdf)
specifies disabled isolation, powered-off leakage and supply current; the
[TI switch databook](https://www.ti.com/lit/ug/scdd003a/scdd003a.pdf) includes
the package pinout. Leakage is finite, so disconnected does not mean zero
current or immunity to externally powered accessories.

U35, SN74HCS10PWR, drives `/OE = NOT (power_EN AND IO_ARM AND FAULT_N)`.
A real Schmitt-input NAND accommodates the open-drain fault signal; C93 is
its bypass capacitor. Unused gate inputs are grounded and outputs are NC.
R42 changes from 100 kΩ to 10 kΩ for the fault pull-up; R86 pulls /OE high
through 220 kΩ. At a 3.6 V supply, R86 plus the switch's specified input leakage
keeps the static sink load within the NAND's 20 µA low-voltage output test
condition. This calculation does not qualify transition timing or thresholds
through ramp/brownout. See the [TI SN74HCS10 datasheet](https://www.ti.com/lit/ds/symlink/sn74hcs10.pdf).

R41 remains 100 kΩ ±1%. The [TI TPS2553 datasheet](https://www.ti.com/lit/ds/symlink/tps2553.pdf)
yields a calculated current-limit range of approximately 232–306 mA including
resistor tolerance. This is neither an accessory current allocation nor proof
of adequate host supply margin. R87 (10 kΩ) bleeds EXP_3V3; accessory capacitance
and external power remain unknown, so no universal discharge interval is claimed.
Orderable parts are recorded in `generated/expansion-bom.csv` and native CAD.

## Reset, faults and firmware

An external MCU_EN reset makes the permission pins inputs and lets the
pull-downs turn the port off. An ESP32 internal software/watchdog reset need
not assert MCU_EN. A module holding the shared I2C bus low can prevent U33
shutdown commands; recovery then requires external reset or handset power-off.
Do not claim software-independent latched shutdown from this topology.

The NAND disconnects signals while FAULT is asserted, after the TPS2553's
fault-reporting delay. It reconnects if FAULT clears while both permissions
remain high. Brief faults can escape polling. There is no rail-good detector,
no independent watchdog on these permissions, and no hot-swap qualification.
Exchange modules only with the handset powered off. Reserve address 0x49 and
qualify every accessory's address, signal timing, chip-select and idle behavior.

The [portable controller](../../firmware/expansion/README.md) preloads output
0xF0 before direction 0xFA, verifies writes, enables supply with 0xF1, then arms
signals with 0xF5 only after an explicitly qualified settling interval.
Observed faults and missed polling deadlines latch software inhibition.
Failed bus operations produce an unknown/reset-required state even after a
best-effort OFF write. It is a host-tested core, not an integrated target build.

## Remaining qualification

Measure startup/inrush, load/current-limit tolerance, output discharge, power
ramps and brownout, external-reset behavior, fault delays/reconnection, stuck
bus recovery, isolation leakage, SPI edges and I2C capacitance. Audit bus-switch
charge-pump current and dynamic gate/controller demand in the system budget.
Verify routing widths, voltage drop, return paths, bypass loops, package land
patterns and assembly clearance against the final stackup and enclosure.
The total accessory and control load remains unqualified in the power inventory.
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

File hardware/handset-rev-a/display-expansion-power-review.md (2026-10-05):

# Display and expansion power review — 2026-09-27

The expansion topology in this earlier audit is superseded by the [power-control and isolation update](expansion-control-review.md). Current limits remain screening values, not qualified accessory demand.

**Historical resistor update (superseded 2026-10-01):** R52–R55 now specify **Vishay CRCW0603150RFKEAHP**, 150 Ω ±1%, in the existing 0603 footprints. The schematic and PCB contain explicit MPN fields; the connectivity specification, placement table and `generated/backlight-resistor-bom.csv` agree. Resistance, nets, component placement and copper geometry are unchanged.

The [current Vishay CRCW-HP e3 datasheet](https://www.vishay.com/docs/20043/crcwhpe3.pdf), revision 17-Mar-2026, specifies 0.33 W P70 for the 0603 part. It makes that rating conditional on permissible film temperature and assembly thermal performance. This replaces the previous 0.1 W specification; it is not a completed thermal qualification.

The CAT4004A driver now replaces Q2 and R52–R55; see the [backlight implementation and routing review](backlight-routing-review.md) for current topology, evidence and remaining limits. The resistor calculations below document the previous design.
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

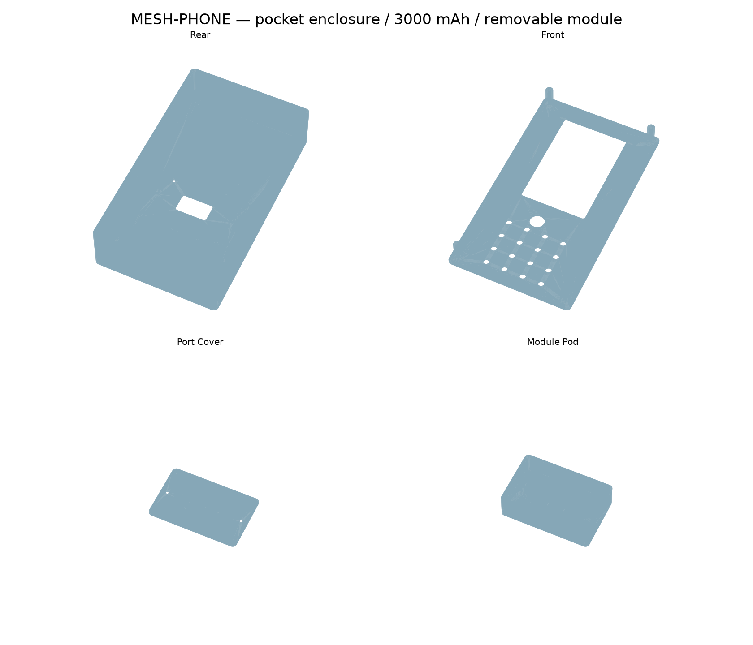
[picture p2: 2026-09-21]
mechanical/enclosure/exports/preview.png

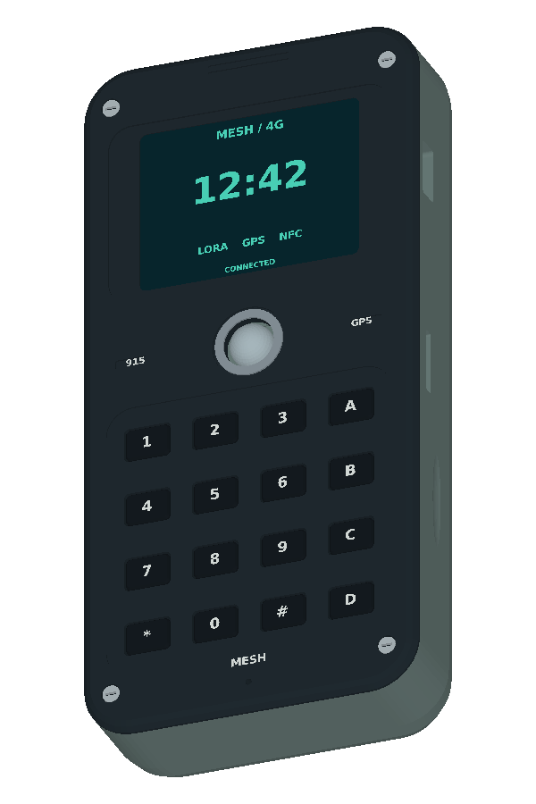
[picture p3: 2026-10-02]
mechanical/handset/exports/front-preview.png

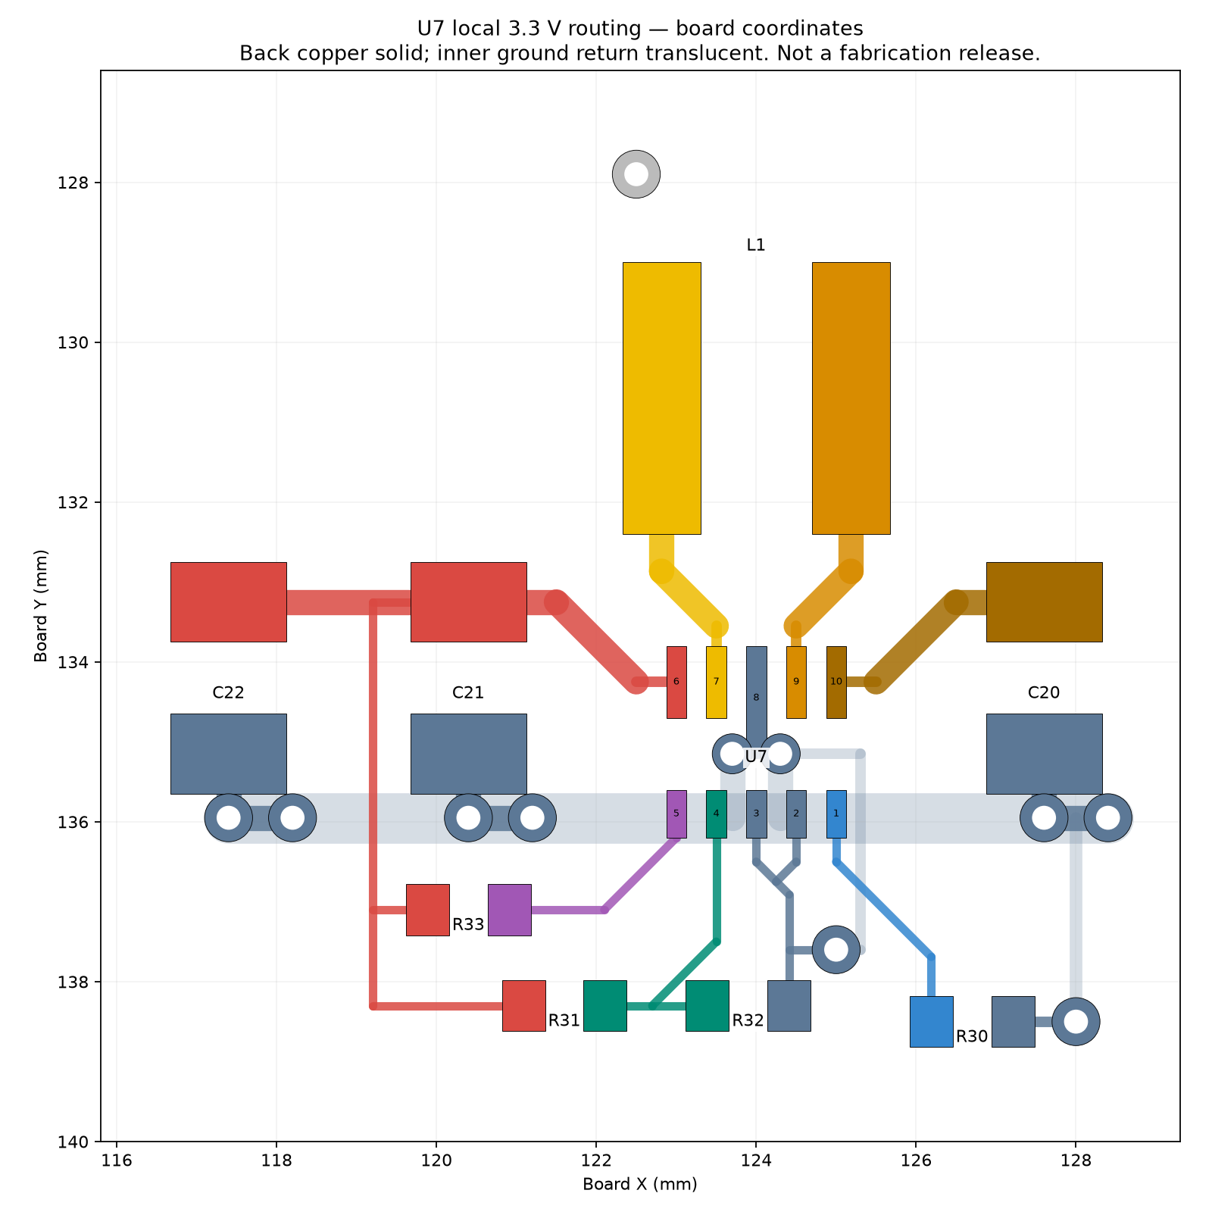
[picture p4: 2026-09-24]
hardware/handset-rev-a/generated/previews/reg3-layout.png

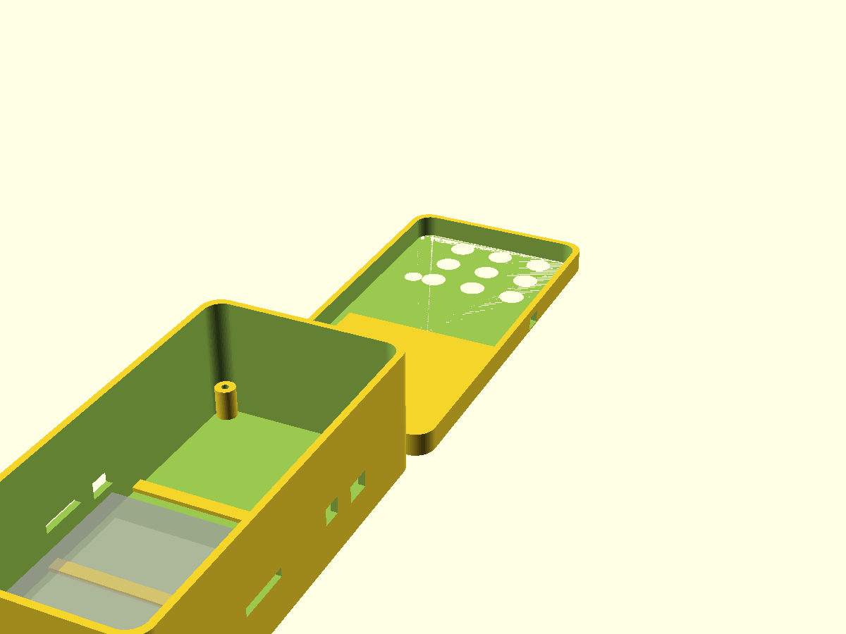
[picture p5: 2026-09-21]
enclosure.png

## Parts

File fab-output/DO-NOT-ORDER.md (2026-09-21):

# Do not order these fabrication files

The 2026-09-20 electrical audit found critical battery/power and pin-assignment
faults in the source design. These older manufacturing outputs are not approved
and do not include the GPS/expansion engineering revision.

Read [the connection review](../review-2026-09-20/CONNECTION_REVIEW.md).

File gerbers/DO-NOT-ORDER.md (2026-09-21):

# Do not order these Gerbers

These files predate the 2026-09-20 electrical audit and GPS/expansion work.
Critical battery/power and pin-assignment faults remain unresolved.

Read [the connection review](../review-2026-09-20/CONNECTION_REVIEW.md).

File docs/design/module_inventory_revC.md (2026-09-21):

# OWASSO-1 module inventory and mechanical audit — rev E

This is the controlled module list extracted from:

- `/home/lakey/diy-phone-blueprint.html`
- `/home/lakey/diy-phone-build.html`
- `/home/lakey/diy-phone-sourcing.html`

The PCB is now 70 x 154 mm. A listed item is marked **on-board** only when its
actual connector or IC footprint is on the PCB. Large breakout boards are
external modules connected through a deliberate header/FPC interface; their
full body must not be silently treated as PCB copper.

| Requirement | PCB ref/interface | Selected part or interface | Mechanical basis | Status |
|---|---|---|---|---|
| MCU + Wi-Fi/BLE + PSRAM | U1 | ESP32-S3-WROOM-1-N16R8 | 18 x 25.5 mm module; antenna keepout required | on-board, placed |
| Camera | J8 | Hirose FH12-24S-0.5SH FPC | 0.5 mm pitch, 24 position, approx. 16.1 x 6.4 x 2.0 mm connector | on-board connector, placed |
| Display | J7 | Waveshare 3.5inch Capacitive Touch LCD 18-pin FPC interface | 0.5 mm FPC; vendor-specific 18-pin pinout; use matching panel/cable only | interface must be changed to vendor pinout before fab |
| Display module | external | Waveshare 3.5inch Capacitive Touch LCD, ST7796-class | 61.00 x 92.44 mm module; 320×480; 18-pin FPC option; touch signals included | selected panel family; freeze exact revision/cable |
| microSD | J9 | Molex 104031-0811 | about 11.95 x 11.40 x 1.42 mm | on-board, exact footprint selected |
| LTE modem | J1 | SIMCom CC-MCore-A7670E-LASE audio core carrier | 44.45 x 31.75 x 12.44 mm; 12-pin + 11-pin 2.54 mm side headers; IPEX-1; micro-SIM | custom J1 footprint and documented 23-pin audio/UART mapping |
| nano-SIM | J10 | JAE SF72S006 | 11.2 x 14.35 x 1.25 mm | on-board, placed |
| CC1101 | J2 | N503-style module header | N503 module about 17 x 16 x 3 mm | external module interface |
| SX1262 / LoRa | J3 | Ebyte E22-400M30S | 24 x 38.5 mm; SMT/castellated module; SPI; 30 dBm; antenna edge/keepout required | do not call current 9-pin J3 direct-fit; use module carrier/adapter |
| PN532 NFC | J4 | 4-pin UART/I2C module header | common breakout about 40 x 40 x 4 mm | external module interface; antenna not on PCB |
| RDM6300 LF RFID | J5 | 4-pin UART/power header | common board about 38 x 22 x 8 mm; 5 V module | direct VCC/GND/TX/RX interface; corrected from 5 pins |
| IR transmitter | D1 | TSAL6200 | 5 mm THT/LED envelope | on-board, placed |
| IR receiver | U7 | TSOP38238 | small 3-pin receiver envelope | on-board, placed |
| Trackball | J6 | Pimoroni PIM447 Trackball Breakout | 25 x 22 x 11 mm; 5-pin header: VCC, GND, SDA, SCL, INT; I2C 0x0A/0x0B | exact module selected; J6 changed to 5-pin |
| Keypad | SW2–SW17/D2–D17/U2 | 4 x 4 switch matrix + PCF8574 | compact KMR2 SMD tactiles; 16 switches + 16 steering diodes | implemented in source/netlist; PCB rebuilt with 4x4 placement |
| Audio | J12 | A7670 analog voice audio | MIC+, MIC−, SPK+, SPK−; use electret mic + 8-ohm speaker | mapped through J1 SC/SD/SR/SV on the 23-pin carrier |
| Battery | J13 | MakerFocus 3.7 V 2000 mAh protected pouch | 50 x 34 x 10 mm ±2 mm; listed with Micro JST 1.25 plug | PH 2.0 was wrong; J13 changed to 1.25 mm mating footprint |
| Charger/protection | U3/U4 | TP4056 + DW01A/FS8205A | power circuit needs complete protection FETs/passives | incomplete schematic/power section |
| Modem boost | U8/L1/D11/C1/R2/R3 | MT3608-class 5 V boost | required by the HTML power plan for modem peaks | PCB implementation added |
| USB-C | USB1 | GCT USB4105-xx-A | connector body/layout per GCT drawing | on-board, placed |
| Power switch | SW1 | CK OS102011MA1Q | side-access switch envelope | on-board, placement still collides |

## Mechanical conclusions

1. The 40 x 40 mm PN532, 38 x 22 mm RDM6300, 24 x 38.5 mm E22 module,
   trackball breakout, and LTE carrier cannot all be physically stacked inside
   a 56 x 122 mm PCB envelope. They must be external/front-panel modules or
   the phone must grow substantially.
2. The PCB therefore carries interfaces, power, protection, antenna keepouts,
   and the MCU/display/camera/card connectors. It does not claim full-board
   placement for those external modules.
3. J1 now targets the larger 23-pin audio carrier. Its left row is SC, SD, SR,
   SV, STA, TXD, RXD, RTS, PEN, R/P, GND, P/G; its right row is VEXT, VTTL,
   CTS, RI, DTR, RXD2, TXD2, VBAT, NET, VIN, VIN.
4. The 4x4 rebuild is a new placement-only candidate and must be rerouted and
   DRC-cleaned before fabrication.
5. The TP4056/DW01A/FS8205A protection network is represented, but its exact
   purchased implementation and battery connector variant still need a bench
   validation before production release.

## Sources used for dimensions

- ESP32-S3-WROOM-1: https://documentation.espressif.com/esp32-s3-wroom-1_wroom-1u_datasheet_en.pdf
- Ebyte E22-400M30S: https://www.ebyte.com/product/452.html
- MakerFocus 2000 mAh pouch: https://www.makerfocus.com/products/makerfocus-3-7v-2000mah-lithium-rechargeable-battery-1s-3c-lipo-battery-with-protection-board-pack-of-4
- Molex 104031-0811: https://www.molex.com/content/dam/molex/molex-dot-com/products/automated/en-us/productspecificationpdf/104/104031/PS-104031-001-001.pdf
- Hirose FH12-24S: https://www.hirose.com/product/p/CL0586-0521-0-55
- JAE SF72: https://www.jae.com/en/connectors/series/detail/id%3D64200
- Ebyte/CC1101 and trackball dimensions: https://www.coralradio.com/CC1101.html and https://thepihut.com/products/trackball-breakout
- A7670SA-FASE carrier dimensions: https://manuals.plus/ae/1005005674566670
- A7670E-LASE compact 7-pin header and pin order: https://www.faranux.com/product/a7670e-4g-lte-cat1-core-board/
- E22-400M30S dimensions and pin definition: https://datasheet.lcsc.com/lcsc/1912111437_Chengdu-Ebyte-Elec-Tech-E22-400M30S_C411292.pdf
- PN532 breakout dimensions: https://www.espboards.dev/sensors/pn532/
- RDM6300 pinout and dimensions: https://www.espboards.dev/sensors/rdm6300/
- 3.5-inch 320×480 FPC display dimensions/interface: https://www.buydisplay.com/download/manual/ER-TFT035IPS-6_Datasheet.pdf
- RDM6300: https://www.espboards.dev/sensors/rdm6300/
- SIMCom A7670E-LASE 23-pin core board: https://manuals.plus/ae/1005007419043953
- A7670E compact 7-pin header order: https://www.faranux.com/product/a7670e-4g-lte-cat1-core-board/
- Waveshare 3.5-inch display: https://www.waveshare.com/wiki/3.5inch_Capacitive_Touch_LCD
- Pimoroni PIM447 trackball: https://wholesale.pimoroni.com/en-us/products/trackball-breakout
- Adafruit I2S microphone pinout reference: https://learn.adafruit.com/adafruit-i2s-mems-microphone-breakout/pinouts

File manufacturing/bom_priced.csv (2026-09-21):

Refs | Description | MPN | Qty | Source | LCSC | UnitUSD | ExtUSD | est
U1 | ESP32-S3-WROOM-1-N16R8 MCU module | ESP32-S3-WROOM-1-N16R8 | 1 | LCSC | C2913205 | 4.78 | 4.78 | VERIFIED LIVE
U2 | I2C GPIO expander (keypad+trackball dirs) | MCP23017T-E/SO SOIC-28 | 1 | LCSC | C32945 | 1.20 | 1.20 | est
U3 | Li-ion charger IC 1A | TP4056 ESOP-8 | 1 | LCSC | C382139 | 0.12 | 0.12 | VERIFIED LIVE
U4 | Battery protection IC | DW01A SOT-23-6 | 1 | LCSC | C14213 | 0.10 | 0.10 | est
U5 | 3.3V LDO 500mA | ME6211C33M5G SOT-23-5 | 1 | LCSC | C82942 | 0.05 | 0.05 | VERIFIED LIVE
U6 | Fuel gauge (header-mounted) | MAX17048G+T10 | 1 | LCSC | C2681679 | 1.80 | 1.80 | est
J1 | LTE Cat-1 modem core board + SIM slot | A7670SA-FASE core board | 1 | AliExpress |  | 14.00 | 14.00 | est
J2 | Sub-GHz transceiver module 300-928MHz | CC1101 N503 module | 1 | AliExpress |  | 4.00 | 4.00 | est
J3 | LoRa SX1262 mesh module (Meshtastic/RNode) | Ebyte E22-400M30S | 1 | cdebyte.com |  | 5.99 | 5.99 | VERIFIED LIVE
J4 | NFC reader/writer/emulator | PN532 breakout red-board | 1 | AliExpress |  | 5.00 | 5.00 | est
J5 | 125kHz RFID reader | RDM6300 | 1 | AliExpress |  | 2.50 | 2.50 | est
J6 | Scroll ball input | BlackBerry trackball breakout | 1 | PMD Way/eBay |  | 15.40 | 15.40 | VERIFIED LIVE
J7 | Display 2in IPS 320x240 SPI | ST7789V FPC module | 1 | AliExpress/Amazon |  | 6.00 | 6.00 | est
J8 | Camera 2MP DVP retro | OV2640 module w/ flex | 1 | AliExpress |  | 3.00 | 3.00 | est
J9 | microSD push-push socket | Molex 104031-0811 | 1 | LCSC | C114757 | 0.82 | 0.82 | VERIFIED LIVE
J10 | SIM card connector | push-type nano-SIM | 1 | LCSC/AliExpress |  | 0.60 | 0.60 | est
SW1_9 | Keypad tactile switches low-profile x9 | SKRPACE010 / ALPS SKRP | 9 | LCSC | C318884 | 0.07 | 0.63 | VERIFIED: LCSC C139797 10+@$0.0623
D_IR1 | IR emitter LED 940nm | TSAL6200 | 1 | LCSC | C9962 | 0.12 | 0.12 | est
U7 | IR receiver 38kHz | TSOP38238 | 1 | LCSC | C134616 | 0.35 | 0.35 | est
USB1 | USB-C receptacle 16pin | GCT USB4105 or equiv | 1 | LCSC | C165948 | 0.55 | 0.55 | est
SW_PWR | Slide switch SPDT | SS12D00 style | 1 | LCSC/AliExpress |  | 0.30 | 0.30 | est
BT1 | Flat LiPo pouch 4000mAh (605080) w/ protection | 605080 LiPo or 2x103450 | 1 | AliExpress/Amazon |  | 9.00 | 9.00 | CHANGED: user wants flat Li-ion not 18650
PCB | Custom 4-layer PCB 62x128mm | JLC04161H-7628 stackup | 5 | JLCPCB |  | 1.40 | 7.00 | est
ANT1 | LTE antenna u.FL + pigtail | 4G/LTE blade antenna | 1 | AliExpress |  | 2.00 | 2.00 | est
ANT2 | LoRa/SubGHz antenna u.FL | 868/915MHz rubber duck | 1 | AliExpress |  | 2.50 | 2.50 | est
PASS | Passives kit: 0805 R/C, 1N4148W x9+, bulk caps 1000uF x2 | assorted | 1 | LCSC/JLC-PCBA |  | 3.00 | 3.00 | est
LENS | Clear front lens 1mm acrylic/PETG | cut-to-size acrylic sheet | 1 | Amazon/TAP Plastics |  | 4.00 | 4.00 | NEW: user request
TOTAL |  |  |  |  |  | TOTAL (mixed verified+est) |  | 89.80

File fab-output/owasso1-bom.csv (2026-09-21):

Refs | Value | Footprint | Qty | DNP
C1 | 1000uF-MODEM-BULK | Capacitor_SMD:C_1206_3216Metric | 1
C2 | 100uF-VBAT-BULK | Capacitor_SMD:C_1206_3216Metric | 1
C3 | 10uF-3V3-BULK | Capacitor_SMD:C_1206_3216Metric | 1
C4 | 10uF-USB-IN | Capacitor_SMD:C_1206_3216Metric | 1
D1 | TSAL6200-IR-LED | LED_SMD:LED_0805_2012Metric | 1
D2 | 1N4148W-KEY-1 | Diode_SMD:D_SOD-123 | 1
D3 | 1N4148W-KEY-2 | Diode_SMD:D_SOD-123 | 1
D4 | 1N4148W-KEY-3 | Diode_SMD:D_SOD-123 | 1
D5 | 1N4148W-KEY-4 | Diode_SMD:D_SOD-123 | 1
D6 | 1N4148W-KEY-5 | Diode_SMD:D_SOD-123 | 1
D7 | 1N4148W-KEY-6 | Diode_SMD:D_SOD-123 | 1
D8 | 1N4148W-KEY-7 | Diode_SMD:D_SOD-123 | 1
D9 | 1N4148W-KEY-8 | Diode_SMD:D_SOD-123 | 1
D10 | 1N4148W-KEY-9 | Diode_SMD:D_SOD-123 | 1
D11 | 1N4148W-KEY-10 | Diode_SMD:D_SOD-123 | 1
D12 | 1N4148W-KEY-11 | Diode_SMD:D_SOD-123 | 1
D13 | 1N4148W-KEY-12 | Diode_SMD:D_SOD-123 | 1
D14 | 1N4148W-KEY-13 | Diode_SMD:D_SOD-123 | 1
D15 | 1N4148W-KEY-14 | Diode_SMD:D_SOD-123 | 1
D16 | 1N4148W-KEY-15 | Diode_SMD:D_SOD-123 | 1
D17 | 1N4148W-KEY-16 | Diode_SMD:D_SOD-123 | 1
J1 | A7670E-LASE-23P-12+11 | owasso1:A7670E_LASE_23P_12+11 | 1
J2 | CC1101-module | Connector_PinHeader_2.54mm:PinHeader_1x08_P2.54mm_Vertical | 1
J3 | Ra-01SH-SX1262-915MHz | owasso1:Ra-01SH | 1
J4 | PN532-NFC-module | Connector_PinHeader_2.54mm:PinHeader_1x04_P2.54mm_Vertical | 1
J5 | RDM6300-RFID-module | Connector_PinHeader_2.54mm:PinHeader_1x05_P2.54mm_Vertical | 1
J6 | Pimoroni-PIM447-Trackball | Connector_PinHeader_2.54mm:PinHeader_1x05_P2.54mm_Vertical | 1
J7 | Waveshare-3.5in-18pin-FPC | Connector_FFC-FPC:Hirose_FH12-18S-0.5SH_1x18-1MP_P0.50mm_Horizontal | 1
J9 | MicroSD-SPI | Connector_PinHeader_2.54mm:PinHeader_1x10_P2.54mm_Vertical | 1
J10 | Nano-SIM | Connector_PinHeader_2.54mm:PinHeader_1x06_P2.54mm_Vertical | 1
J13 | LiPo-BATTERY-MICRO-JST-1.25 | Connector_JST:JST_GH_SM02B-GHS-TB_1x02-1MP_P1.25mm_Horizontal | 1
J14 | LoRa-UFL-Antenna | owasso1:U.FL_Hirose_U.FL-R-SMT-1_Vertical | 1
L1 | 1uH-BOOST-INDUCTOR | Inductor_SMD:L_1210_3225Metric | 1
Q1 | FS8205A-PROTECTION-FET | Package_TO_SOT_SMD:SOT-23-6 | 1
R1 | 1.2k-TP4056-PROG | Resistor_SMD:R_0805_2012Metric | 1
R2 | 180k-BOOST-FB | Resistor_SMD:R_0805_2012Metric | 1
R3 | 27k-BOOST-FB | Resistor_SMD:R_0805_2012Metric | 1
R4 | 5.1k-USB-C-CC1-Rd | Resistor_SMD:R_0805_2012Metric | 1
R5 | 5.1k-USB-C-CC2-Rd | Resistor_SMD:R_0805_2012Metric | 1
SW1 | Power-switch | Button_Switch_SMD:SW_SPDT_CK_JS102011SAQN | 1
SW2 | KEY-1 | Button_Switch_SMD:SW_SPST_B3S-1000 | 1
SW3 | KEY-2 | Button_Switch_SMD:SW_SPST_B3S-1000 | 1
SW4 | KEY-3 | Button_Switch_SMD:SW_SPST_B3S-1000 | 1
SW5 | KEY-4 | Button_Switch_SMD:SW_SPST_B3S-1000 | 1
SW6 | KEY-5 | Button_Switch_SMD:SW_SPST_B3S-1000 | 1
SW7 | KEY-6 | Button_Switch_SMD:SW_SPST_B3S-1000 | 1
SW8 | KEY-7 | Button_Switch_SMD:SW_SPST_B3S-1000 | 1
SW9 | KEY-8 | Button_Switch_SMD:SW_SPST_B3S-1000 | 1
SW10 | KEY-9 | Button_Switch_SMD:SW_SPST_B3S-1000 | 1
SW11 | KEY-10 | Button_Switch_SMD:SW_SPST_B3S-1000 | 1
SW12 | KEY-11 | Button_Switch_SMD:SW_SPST_B3S-1000 | 1
SW13 | KEY-12 | Button_Switch_SMD:SW_SPST_B3S-1000 | 1
SW14 | KEY-13 | Button_Switch_SMD:SW_SPST_B3S-1000 | 1
SW15 | KEY-14 | Button_Switch_SMD:SW_SPST_B3S-1000 | 1
SW16 | KEY-15 | Button_Switch_SMD:SW_SPST_B3S-1000 | 1
SW17 | KEY-16 | Button_Switch_SMD:SW_SPST_B3S-1000 | 1
U1 | ESP32-S3-WROOM-1-N16R8 | RF_Module:ESP32-S3-WROOM-1 | 1
U2 | PCF8574T-keypad-expander | Package_SO:SOIC-16_3.9x9.9mm_P1.27mm | 1
U3 | TP4056-charger | Package_SO:HSOP-8-1EP_3.9x4.9mm_P1.27mm_EP2.3x2.3mm | 1
U4 | DW01A-protection | Package_TO_SOT_SMD:SOT-23-6 | 1
U5 | 3V3-LDO | Package_TO_SOT_SMD:SOT-23-5 | 1
U6 | MAX17048-fuel-gauge | Connector_PinHeader_2.54mm:PinHeader_1x04_P2.54mm_Vertical | 1
U7 | TSOP38238-IR-receiver | Connector_PinHeader_2.54mm:PinHeader_1x03_P2.54mm_Vertical | 1
U8 | TPS61023DRLR-5V-BOOST | Package_TO_SOT_SMD:SOT-563 | 1
USB1 | USB-C-charge-and-data | Connector_USB:USB_C_Receptacle_GCT_USB4105-xx-A_16P_TopMnt_Horizontal | 1

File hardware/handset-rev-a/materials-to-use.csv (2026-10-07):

Block | Part / material | Manufacturer part number | Package / envelope | Use on new PCB | Release condition
MCU / Wi-Fi / BLE | ESP32-S3-WROOM-1 N16R8 | ESP32-S3-WROOM-1-N16R8 | 18x25.5mm module | RETAIN CURRENT PART | Observe Espressif antenna keepout and module placement rules
LTE voice and data | Unlocked replaceable modem adapter; A7672G or broader approved alternative | TBD | Adapter envelope pending | REQUIRED BUT MODEM NOT FROZEN | User requires multi-carrier service; verify exact modem firmware carrier VoLTE audio and peak-current operation
LoRa / Meshtastic | Semtech SX1262 | SX1262 | 4x4mm QFN | YES | Copy the 915MHz reference RF network and validate antenna matching
Sub-GHz general radio | TI CC1101 | CC1101 | 4x4mm VQFN | CC1101 FRONTEND SCHEMATIC POPULATED | 868/915MHz clock and matching captured; finish RF layout and qualify oscillator, conducted RF, emissions and case antenna; see cc1101-review.md
GNSS and PPS | u-blox MAX-M10S | MAX-M10S-00B-01 | 9.7x10.1mm LCC | POPULATED U12 | Complete passive antenna feed and coexistence validation; no hardware backup supply
NFC reader / writer | ST ST25R3916B | ST25R3916B-AQET | 5x5mm QFN | YES | Design and tune a case-mounted 13.56MHz loop and matching network
125kHz RFID reader | NXP HTRC110 | HTRC11001T | SO14 body about 8.7x3.9mm | YES | Validate tag protocol and tune the external LF coil
Keypad scanner | TI TCA8418 | TCA8418 | 4x4mm WQFN | YES | Test required simultaneous key combinations before removing per-key diodes
Battery charger and power path | TI BQ25186 | BQ25186DLHR | 2.2x2.0mm DLH WSON-10 | SELECTED U3 | Program and verify charger-policy.json; battery NTC and thermal/load qualification required
Battery fuel gauge | Analog Devices MAX17048 | MAX17048G+T | 2x2mm TDFN | YES | Configure and validate the battery model
3.3V system buck-boost | TI TPS63802 | TPS63802 | 3x2mm VSON-HR | YES | Verify simultaneous radio/display transient budget
1.8V regulator | TI TPS62840 | TPS62840 | SON or WCSP | YES | Freeze package after 1.8V load budget
Switched 5V boost | TI TPS61023 | TPS61023 | 1.6x1.6mm SOT-5X3 | YES IF REQUIRED | Populate only when a confirmed RFID/audio/accessory load requires 5V; never feed LTE from it
Media / key-tone speaker amplifier | Analog Devices MAX98357A | MAX98357A | 3x3mm QFN preferred | YES | Use QFN for prototype assembly and keep modem call-audio routing separate
Call microphone | Low-profile analog microphone on modem audio adapter | TBD | TBD | REQUIRED ON ADAPTER | Select against verified modem codec and microphone bias circuit
Digital microphone | Knowles SPH0645LM4H-1 | SPH0645LM4H-1 | 3.5x2.65x0.98mm | YES | Use for ESP32 recording/assistant input rather than direct modem call audio
Display with capacitive touch | EastRising ER-TFT024IPS-3 CTP option | ER-TFT024IPS-3 with CTP | 42.72x59.46x2.3mm plus touch | INTERFACE POPULATED J26 | Confirm purchased CTP configuration and voltage tolerances; SPI II and top-contact FPC captured
Trackball module | Pimoroni trackball breakout | PIM447 | 25x22x11mm | YES | Recess through the main-PCB cutout and retain serviceable module connection
microSD socket | Hirose push-pull microSD | DM3D-SF | 1.55mm high | POPULATED J23 | Manufacturer contact map and KiCad footprint; confirm card insertion access in enclosure
nano-SIM socket | JAE push-push nano-SIM | SF72S006 | 11.2x14.3x1.25mm | YES | Route only to the selected modem SIM supply/interface
USB-C receptacle | GCT USB4105 | USB4105 | 7.35mm body / 3.31mm profile | YES | USB4105_GroundCornerRelief footprint; assembler DFM and ordering suffix remain open; finish USB2 data routing and qualification
IR transmitter | Vishay case-mounted IR LED and AOS driver | TSAL6400 + AO3400A | 5mm LED off-board and SOT-23 driver | DRIVER AND J24 POPULATED | Confirm optical range and enclosure alignment; 47 ohm series resistor
IR receiver | Vishay case-mounted 38kHz receiver | TSOP38438 | 5x6.95x4.8mm off-board | J25 INTERFACE POPULATED | GPIO3 receives directly; validate protocol and boot behavior
Battery | MakerFocus protected 3000mAh LiPo | MakerFocus 3000mAh protected pouch | 65x36x10mm nominal +/-2mm | YES | Verify the exact purchased pack connector polarity protection-board current and measured dimensions
Expansion connection | JST GH 10-pin cable port | BM10B-GHS-TBT | Enclosure rear port | POPULATED J16 | Power-off swaps; verify cable and connector assembly
NFC antenna | Case-mounted 13.56MHz flex or PCB loop | Custom | Tuned to installed enclosure | YES | Tune with production plastics battery and nearby conductors installed
LF RFID antenna | Case-mounted 125kHz coil | Custom | Tuned to installed enclosure | YES | Tune with production plastics battery and nearby conductors installed
RF antennas | LTE + LoRa + CC1101 + GNSS + Wi-Fi/BLE antennas | Exact parts TBD | Separate validated antenna systems | YES | Select after placement study and validate matching isolation coexistence and regulatory performance
Expansion power switch | TI adjustable current limiter | TPS2553DBVR | SOT-23-6 | POPULATED U14 | 100k ILIM resistor; validate accessory current and fault behavior
External signal protection | TI four-channel ESD array | TPD4E05U06DQAR | USON-10 2.5x1mm | POPULATED U15 U16 U17 | Complete low-inductance ground returns and test ESD performance
LF logic up-translation | TI TTL-input buffer | SN74AHCT125PWR | TSSOP-14 | POPULATED U18 | 5V supply; dedicated host timing still unresolved
LF logic down-translation | TI Schmitt buffer | SN74LVC1G17DBVR | SOT-23-5 | POPULATED U19 | 3.3V supply and 5V-tolerant input; host return remains unassigned
NFC clock | Abracon 27.12MHz crystal | ABM8-27.120MHZ-B2-T | 3.2x2.5mm four-pad | POPULATED Y1 | Validate 27pF load capacitors against actual parasitics
Display connector | Hirose top-contact 50-way ZIF | FH12A-50S-0.5SH(55) | 0.5mm pitch | POPULATED J26 | Custom footprint from shared manufacturer lands; inspect contact orientation and cable retention
Modem regulator | TI buck-boost | TPS63070RNMR | VQFN-HR RNM0015A | POPULATED U20 | 3.792V nominal; conservative UVLO; burst and custom footprint validation required
System inductor | Coilcraft shielded 0.47uH | XFL4020-471MEC | 4x4x2.1mm | POPULATED L1 | Check inductance under peak current and temperature
5V inductor | Coilcraft shielded 1uH | XFL4020-102MEC | 4x4x2.1mm | POPULATED L2 | LF plus display backlight rail load budget
1.8V inductor | Coilcraft shielded 2.2uH | XFL4020-222MEC | 4x4x2.1mm | POPULATED L3 | Validate current and control-loop behavior
Modem inductor | Coilcraft shielded 1.5uH | XFL4020-152MEC | 4x4x2.1mm | POPULATED L4 | TI-listed inductor family; validate burst temperature and saturation
USB input eFuse | TI TPS25200 | TPS25200DRVR | 2x2mm DRV WSON-6 | SELECTED U21 | 100k 1% current limit; verify TVS/fuse coordination and fault response
USB-C source detector | TI TUSB320LAI | TUSB320LAIRWBR | 1.6x1.6mm RWB X2QFN-12 | SELECTED U22 | Sink-only GPIO mode; internal Rd; no PD or BC1.2
USB detector supply | TI TLV70433 | TLV70433DBVR | SOT-23-5 | SELECTED U23 | Always-on detector supply from fused VBUS; verify power budget
Charger control GPIO | TI TCA9536 | TCA9536DGKR | VSSOP-8 | SELECTED U24 | 0x41 I2C; preload outputs low before enabling output direction
USB and battery fuses | Littelfuse 467 series | 046701.5NRHF | 0603 | SELECTED F1 F2 | 1.5A fast fuse is not a precision operating-current limiter
USB VBUS TVS | Diotec SMF5.0A | SMF5.0A | SOD-123FL | SELECTED D1 | Verify polarity and pulse/fuse coordination; not continuous high-voltage protection
USB permission diode OR | Nexperia BAT54C | BAT54C,215 | SOT-23 | SELECTED D2 | Common cathode pin 3; qualify logic thresholds
Type-C permission switch | AOS AO3401A | AO3401A | SOT-23 | SELECTED Q6 | Logic-level P-channel; confirm pinout and startup behavior
Charger gate and status isolation | AOS AO3400A | AO3400A | SOT-23 | SELECTED Q5 Q7 | Gate pulldowns and isolated source status; fault injection required
CC1101 frontend | 26MHz CL10pF | ABM8-26.000MHZ-10-D-1-G-T | 3.2x2.5mm | POPULATED Y2 | Circuit specification only; RF layout, effective capacitance, oscillator loading and bench qualification remain; see cc1101-review.md
CC1101 frontend | 1kohm @100MHz | BLM15HG102SN1D | 0402 | POPULATED L11 | Circuit specification only; RF layout, effective capacitance, oscillator loading and bench qualification remain; see cc1101-review.md
CC1101 frontend | 100pF 5% C0G 50V | GRM1555C1H101JA01D | 0402 | POPULATED C66 | Circuit specification only; RF layout, effective capacitance, oscillator loading and bench qualification remain; see cc1101-review.md
CC1101 frontend | 12pF 5% C0G 50V | GRM1555C1H120JA01D | 0402 | POPULATED C67 | Circuit specification only; RF layout, effective capacitance, oscillator loading and bench qualification remain; see cc1101-review.md
CC1101 frontend | 15pF 5% C0G 50V | GRM1555C1H150JA01D | 0402 | POPULATED C61, C62 | Circuit specification only; RF layout, effective capacitance, oscillator loading and bench qualification remain; see cc1101-review.md
CC1101 frontend | 1pF 0.25pF C0G 50V | GRM1555C1H1R0CA01D | 0402 | POPULATED C63 | Circuit specification only; RF layout, effective capacitance, oscillator loading and bench qualification remain; see cc1101-review.md
CC1101 frontend | 1.5pF 0.25pF C0G 50V | GRM1555C1H1R5CA01D | 0402 | POPULATED C64, C68 | Circuit specification only; RF layout, effective capacitance, oscillator loading and bench qualification remain; see cc1101-review.md
CC1101 frontend | 3.3pF 0.25pF C0G 50V | GRM1555C1H3R3CA01D | 0402 | POPULATED C65 | Circuit specification only; RF layout, effective capacitance, oscillator loading and bench qualification remain; see cc1101-review.md
CC1101 frontend | 1uF 10% X5R 10V | GRM155R61A105KE15D | 0402 | POPULATED C74 | Circuit specification only; RF layout, effective capacitance, oscillator loading and bench qualification remain; see cc1101-review.md
CC1101 frontend | 100nF 10% X7R 16V | GRM155R71C104KA88D | 0402 | POPULATED C11, C12, C69, C70, C71, C72, C73 | Circuit specification only; RF layout, effective capacitance, oscillator loading and bench qualification remain; see cc1101-review.md
CC1101 frontend | 12nH 5% | LQW15AN12NJ00D | 0402 | POPULATED L5, L6, L9, L10 | Circuit specification only; RF layout, effective capacitance, oscillator loading and bench qualification remain; see cc1101-review.md
CC1101 frontend | 18nH 5% | LQW15AN18NJ00D | 0402 | POPULATED L7, L8 | Circuit specification only; RF layout, effective capacitance, oscillator loading and bench qualification remain; see cc1101-review.md
LoRa core regulator | TDK shielded 15uH 20% inductor L12 | MLZ2012M150WT000 | 2.0x1.25x1.25mm | POPULATED L12 | Route core loop; qualify ripple and current; see sx1262-power-review.md
LoRa core bypass | Murata 470nF 10% X5R 10V C9 | GRM155R61A474KE15D | 0402 | CORRECTED C9 | Verify effective capacitance and regulator startup; replaces incorrect 100nF
LoRa input bypass | Murata 100nF 10% X7R 16V C8 C75 C76 | GRM155R71C104KA88D | 0402 | POPULATED C8 C75 C76 | Route close to U4 supply pins 10 1 11 with local ground returns
Backlight current control | onsemi CAT4004A | CAT4004AHU2-GT3 | UDFN-8 2x2mm exposed pad | INSTALLED U32; 4.99k RSET | Qualify current, panel compatibility, heat and control timing; see backlight-routing-review.md
Expansion controller | Resettable 4-bit I2C GPIO | TCA9537DGSR | DGS 3x3mm / KiCad MSOP10 | CAPTURED U33 | Host target integration and external-reset/stuck-bus qualification
Expansion bus switch | 8-channel bidirectional switch; 7 used | SN74CB3Q3245PWR | TSSOP20 | CAPTURED U34 | Compatible 3.3V modules only; leakage, timing, current and startup qualification
Expansion fault interlock | Triple 3-input Schmitt NAND | SN74HCS10PWR | TSSOP14 | CAPTURED U35 | Qualify thresholds, delays and brief-fault reconnection; no hardware fault latch
USB data termination | R88/R89: 22 ohm 1% series resistors | RC0402FR-0722RL | 0402 / 1005 | POPULATED AND ROUTED | Initial termination; qualify USB eye and stackup impedance; see usb-data-routing-review.md

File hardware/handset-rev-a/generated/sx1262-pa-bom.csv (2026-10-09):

ref | value | mpn | footprint | role
C10 | 47nF 10% X7R 25V | GRM155R71E473KA88D | Capacitor_SMD:C_0402_1005Metric | PA bypass on VR_PA side of choke; replaces provisional 100nF
L13 | 47nH 2% | LQW15AN47NG80D | Inductor_SMD:L_0402_1005Metric | PA RF choke; 47nH baseline from RAK4270; qualify current, RF loss and harmonics
C101 | 47pF 5% C0G 50V | C1005C0G1H470J050BA | Capacitor_SMD:C_0402_1005Metric | PA high-frequency bypass on VR_PA side of choke; provisional RF placement

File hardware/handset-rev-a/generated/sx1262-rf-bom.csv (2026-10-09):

ref | value | mpn | footprint | role
U36 | 0900FM15K0039001E | 0900FM15K0039001E | RF_Converter:Balun_Johanson_0900FM15K0039 | Integrated SX1262 matching/filter; RF placement/routing and ground vias require qualification
U37 | BGS12WN6E6327 | BGS12WN6E6327XTSA1 | Package_LGA:Infineon_PG-TSNP-6-10_0.7x1.1mm_0.7x1.1mm_P0.4mm | CTRL high selects TX RF2; low selects RX RF1; all RF ports require zero DC
R91 | 100R 1% | RC0402FR-07100RL | Resistor_SMD:R_0402_1005Metric | DIO2 control series filter
R92 | 100R 1% | RC0402FR-07100RL | Resistor_SMD:R_0402_1005Metric | Always-powered switch supply series filter
C96 | 1nF 10% X7R 50V | GRM155R71H102KA01D | Capacitor_SMD:C_0402_1005Metric | Switch control/supply shunt filter
C97 | 1nF 10% X7R 50V | GRM155R71H102KA01D | Capacitor_SMD:C_0402_1005Metric | Switch control/supply shunt filter
C98 | 100pF 5% C0G 50V | GRM1555C1H101JA01D | Capacitor_SMD:C_0402_1005Metric | Explicit RF port DC block; 100pF starting value requires RF validation
C99 | 100pF 5% C0G 50V | GRM1555C1H101JA01D | Capacitor_SMD:C_0402_1005Metric | Explicit RF port DC block; 100pF starting value requires RF validation
C100 | 100pF 5% C0G 50V | GRM1555C1H101JA01D | Capacitor_SMD:C_0402_1005Metric | Explicit RF port DC block; 100pF starting value requires RF validation
R93 | 100k 1% | RC0402FR-07100KL | Resistor_SMD:R_0402_1005Metric | Default RX while DIO2 is high impedance

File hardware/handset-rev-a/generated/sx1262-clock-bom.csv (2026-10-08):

ref | value | mpn | footprint | role
Y3 | 32MHz TCXO 0.5ppm temp | ECS-TXO-32CSMV-320-AN-TR | Handset:ECS_TXO_32CSMV_3225 | 1.8V DIO3 supply; clipped sine; maximum amplitude requires supplier/bench qualification
R90 | 220R 1% | RC0402FR-07220RL | Resistor_SMD:R_0402_1005Metric | Semtech series clock resistor
C94 | 100nF 10% X7R 16V | GRM155R71C104KA88D | Capacitor_SMD:C_0402_1005Metric | Local TCXO supply bypass
C95 | 10pF 5% C0G 50V | GRM1555C1H100JA01D | Capacitor_SMD:C_0402_1005Metric | Semtech XTA series DC blocking capacitor

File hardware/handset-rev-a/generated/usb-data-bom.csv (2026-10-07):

Reference | Manufacturer | MPN | Value | Footprint | Qualification
R88 | Yageo | RC0402FR-0722RL | 22 ohm 1% | Resistor_SMD:R_0402_1005Metric | Initial termination; qualify USB electrical performance
R89 | Yageo | RC0402FR-0722RL | 22 ohm 1% | Resistor_SMD:R_0402_1005Metric | Initial termination; qualify USB electrical performance

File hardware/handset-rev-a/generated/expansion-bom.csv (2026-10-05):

Reference | Manufacturer | MPN | Value | Footprint | Qualification
U33 | Texas Instruments | TCA9537DGSR | TCA9537DGSR | Package_SO:MSOP-10_3x3mm_P0.5mm | Captured; hardware qualification pending
U34 | Texas Instruments | SN74CB3Q3245PWR | SN74CB3Q3245PWR | Package_SO:TSSOP-20_4.4x6.5mm_P0.65mm | Captured; hardware qualification pending
U35 | Texas Instruments | SN74HCS10PWR | SN74HCS10PWR | Package_SO:TSSOP-14_4.4x5mm_P0.65mm | Captured; hardware qualification pending
C91 | Murata | GRM155R71C104KA88D | 100nF 10% X7R 16V | Capacitor_SMD:C_0402_1005Metric | Captured; hardware qualification pending
C92 | Murata | GRM155R71C104KA88D | 100nF 10% X7R 16V | Capacitor_SMD:C_0402_1005Metric | Captured; hardware qualification pending
C93 | Murata | GRM155R71C104KA88D | 100nF 10% X7R 16V | Capacitor_SMD:C_0402_1005Metric | Captured; hardware qualification pending
R83 | Yageo | RC0402FR-074K7L | 4.7k 1% | Resistor_SMD:R_0402_1005Metric | Captured; hardware qualification pending
R84 | Yageo | RC0402FR-074K7L | 4.7k 1% | Resistor_SMD:R_0402_1005Metric | Captured; hardware qualification pending
R85 | Yageo | RC0402FR-07100KL | 100k 1% | Resistor_SMD:R_0402_1005Metric | Captured; hardware qualification pending
R86 | Yageo | RC0402FR-07220KL | 220k 1% | Resistor_SMD:R_0402_1005Metric | Captured; hardware qualification pending
R87 | Yageo | RC0402FR-0710KL | 10k 1% | Resistor_SMD:R_0402_1005Metric | Captured; hardware qualification pending
R42 | Yageo | RC0402FR-0710KL | 10k 1% | Resistor_SMD:R_0402_1005Metric | Captured; hardware qualification pending

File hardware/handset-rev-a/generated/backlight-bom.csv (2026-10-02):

Reference | Manufacturer | MPN | Value | Footprint | Qualification
U32 | onsemi | CAT4004AHU2-GT3 | CAT4004AHU2-GT3 | Handset:CAT4004A_UDFN-8_2x2mm_P0.5mm_EP1x1.73mm | Installed and routed; electrical and thermal qualification pending
R82 | Yageo | RC0402FR-074K99L | 4.99k 1% | Resistor_SMD:R_0402_1005Metric | Installed and routed; electrical and thermal qualification pending
C90 | Murata | GRM188R71E105KA12D | 1uF 10% X7R 25V | Capacitor_SMD:C_0603_1608Metric | Installed and routed; electrical and thermal qualification pending

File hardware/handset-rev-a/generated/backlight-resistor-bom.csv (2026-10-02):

References | Quantity | Manufacturer | MPN | Value | Footprint | Qualification
R52 R53 R54 R55 | 4 | Vishay | CRCW0603150RFKEAHP | 150 1% 0.33W | Resistor_SMD:R_0603_1608Metric | 0.33W P70 per current datasheet; assembly thermal qualification open

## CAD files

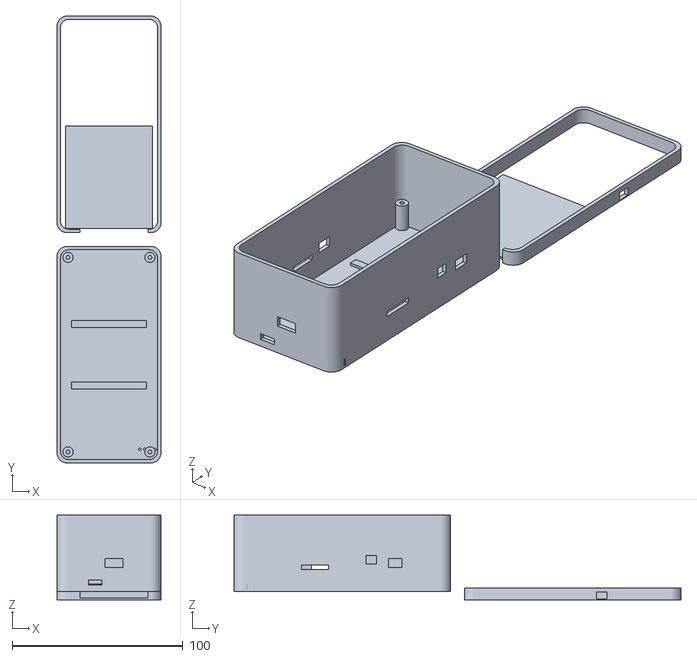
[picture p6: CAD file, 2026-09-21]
enclosure.stl
61.0 x 262.0 x 49.6

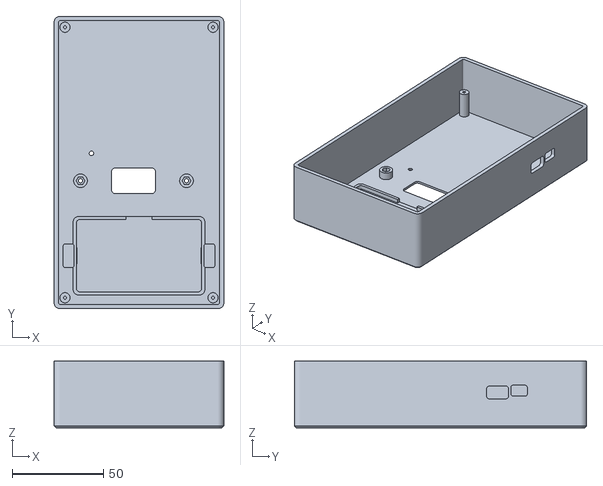
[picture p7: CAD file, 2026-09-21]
mechanical/enclosure/exports/rear.stl
93.0 x 160.0 x 36.4

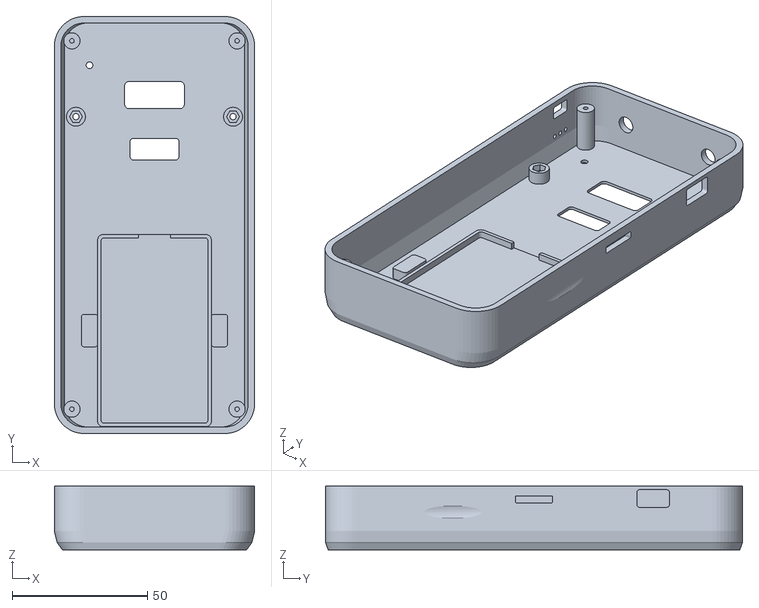
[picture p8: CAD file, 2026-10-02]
mechanical/handset/exports/rear.stl
74.0 x 154.0 x 23.6

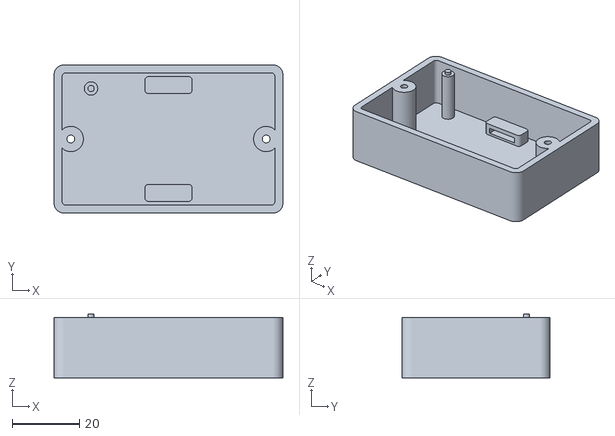
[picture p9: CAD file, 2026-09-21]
mechanical/enclosure/exports/module_pod.stl
68.0 x 44.0 x 19.0

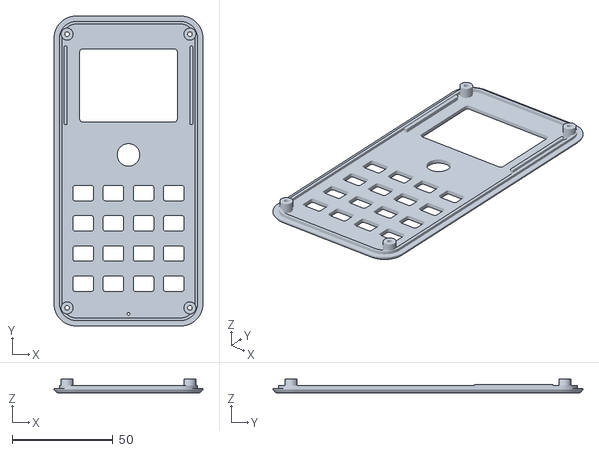
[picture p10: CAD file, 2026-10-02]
mechanical/handset/exports/front.stl
74.0 x 154.0 x 7.20

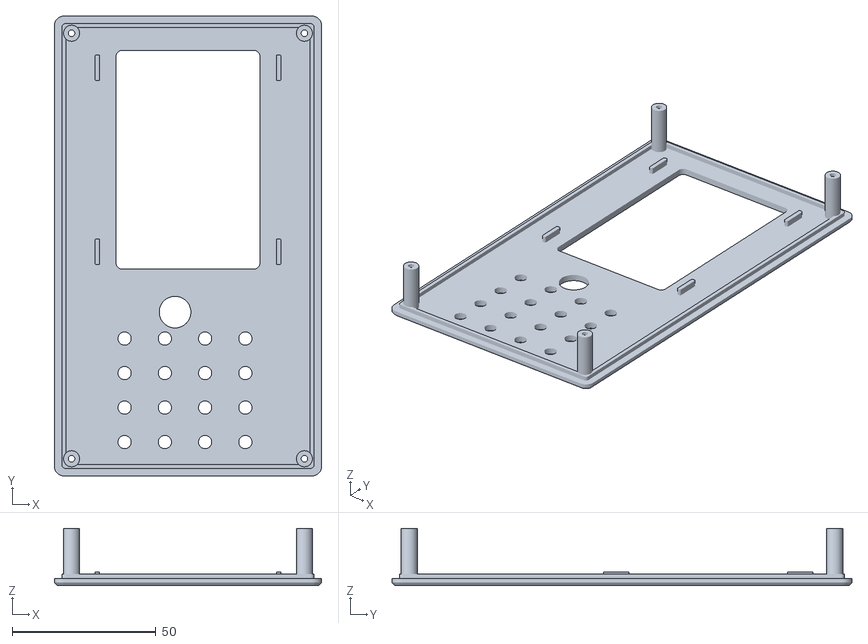
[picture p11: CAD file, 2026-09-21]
mechanical/enclosure/exports/front.stl
93.0 x 160.0 x 19.9

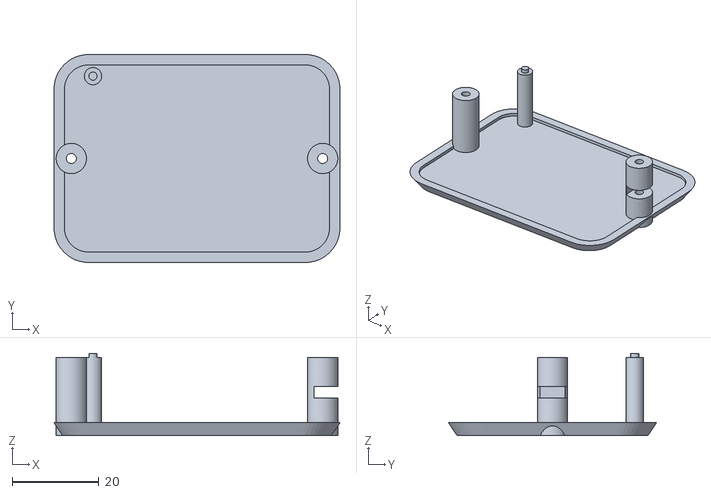
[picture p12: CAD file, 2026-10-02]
mechanical/handset/exports/module_pod.stl
66.0 x 48.0 x 19.0

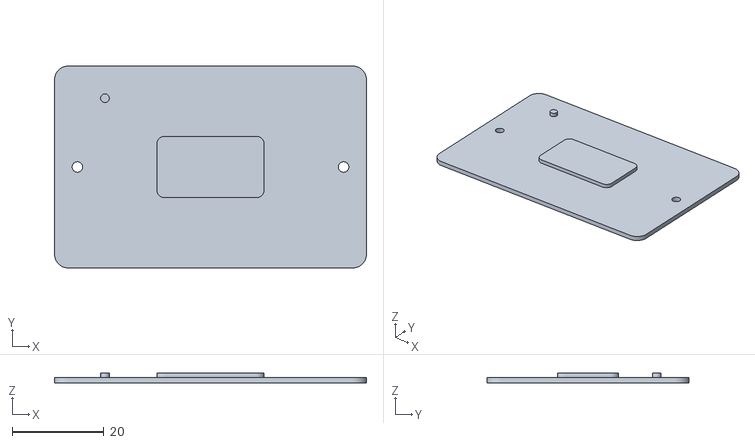
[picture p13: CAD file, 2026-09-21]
mechanical/enclosure/exports/port_cover.stl
68.0 x 44.0 x 2.20

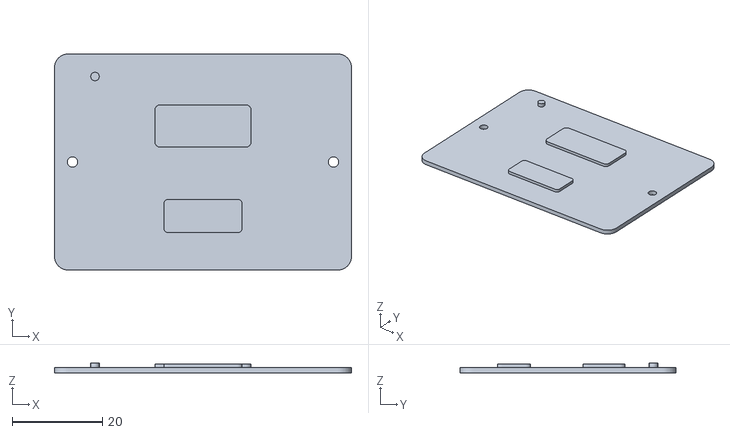
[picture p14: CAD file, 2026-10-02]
mechanical/handset/exports/port_cover.stl
66.0 x 48.0 x 2.20

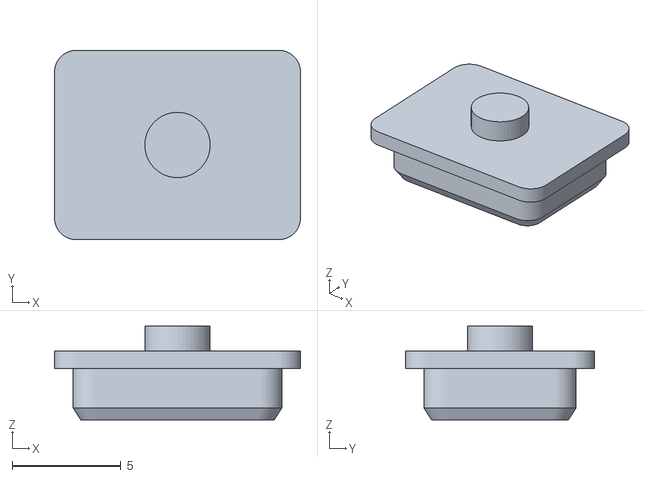
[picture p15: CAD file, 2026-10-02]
mechanical/handset/exports/keycap.stl
11.3 x 8.70 x 4.30

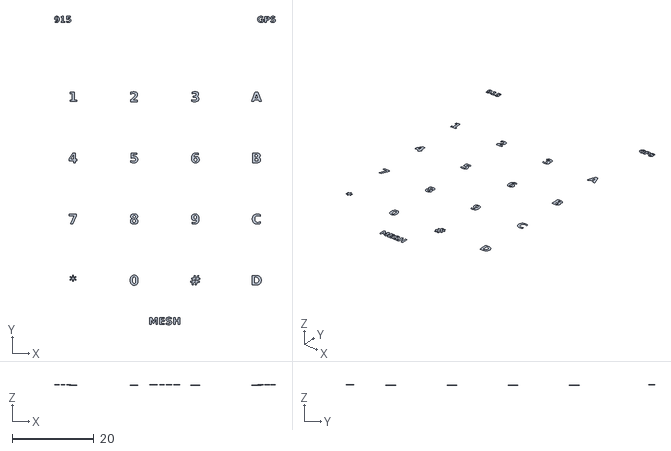
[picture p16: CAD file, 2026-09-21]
mechanical/handset/exports/visual_legends.stl
54.2 x 75.7 x 0.14

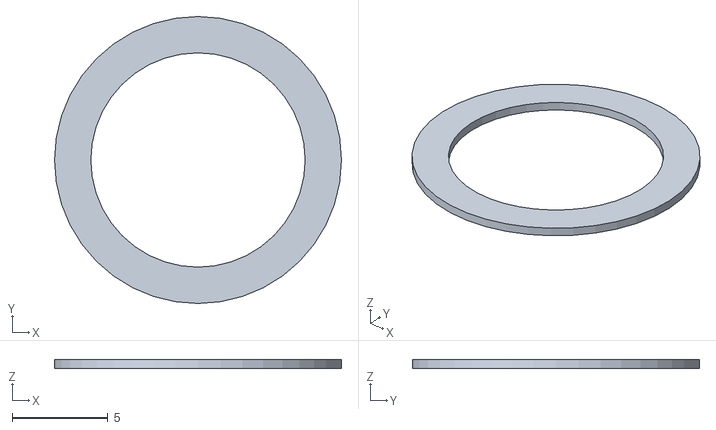
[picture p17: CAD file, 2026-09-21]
mechanical/handset/exports/visual_ring.stl
15.0 x 15.0 x 0.45

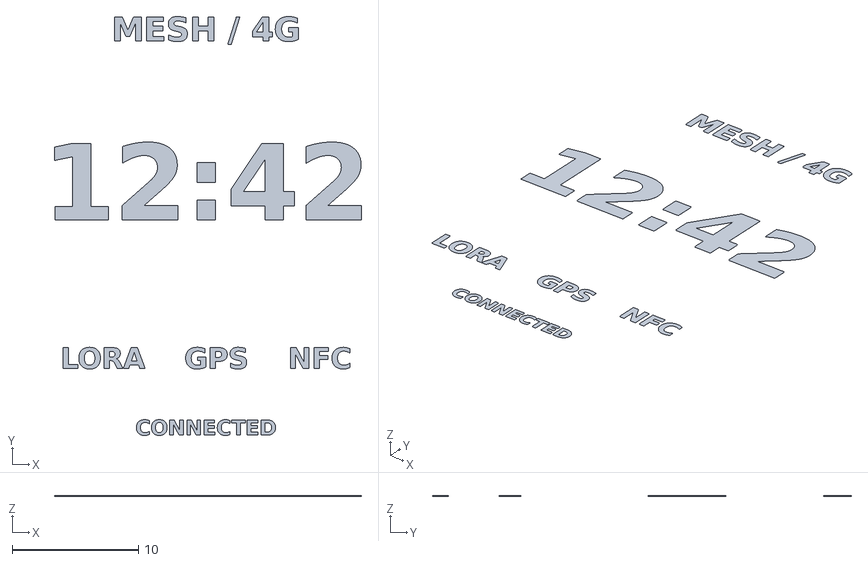
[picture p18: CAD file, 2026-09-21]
mechanical/handset/exports/visual_ui.stl
24.4 x 33.2 x 0.05

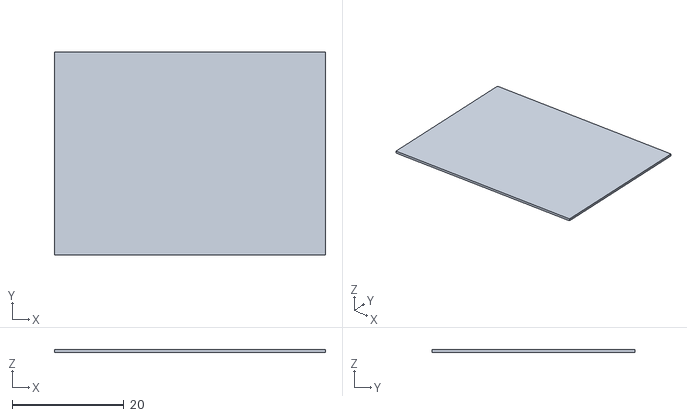
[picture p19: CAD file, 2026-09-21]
mechanical/handset/exports/visual_display.stl
48.5 x 36.3 x 0.5

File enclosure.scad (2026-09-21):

// ============================================================
//  OWASSO-1 rev A — Enclosure v2 (measurement-corrected)
//
//  PCB: 70 x 154mm actual Edge.Cuts
//  Stack (bottom→top):
//    floor 1.6 | battery 10 | air gap 1 | standoff 11 | PCB 1.6 |
//    tallest module ≈ 13 (2.54 header + A7670 board) | keycaps 3
//  Internal depth = 1.6+8+1+9+1.6+13+3 +0.5 clearance ≈ 37.7
//
//  Coordinate system: enclosure centered at origin, PCB origin
//  maps to (-pcb_w/2, -pcb_h/2) so KiCad (x,y) → enclosure
//  (x - pcb_w/2, y - pcb_h/2). All cutouts derive from PCB
//  footprint positions via pcb2case().
//
//  Print: PETG, 0.2mm layers, 3 walls, 15% infill. No supports.
// ============================================================

/* [PCB] */
pcb_w = 70;         // actual Edge.Cuts width
pcb_h = 154;        // actual Edge.Cuts height
pcb_t = 1.6;

/* [Heights above PCB top surface] */
h_header_a7670 = 2.54;   // J1 header pins
h_a7670_board = 10;      // core board incl. components + SIM tray side-clearance
h_keycap = 2;            // SKRP + cap
h_lcd = 4;               // 3.5in 320x480 panel w/ FPC folded

/* [Battery] */
// MakerFocus 3.7 V 2000 mAh flat LiPo nominal envelope is
// approximately 50 x 34 x 10 mm.  The cavity adds 2 mm total
// XY clearance and 2 mm thickness clearance for insulation/tolerance.
batt_l = 54;
batt_w = 38;
batt_t = 12;

/* [Case] */
wall = 2.0;
floor_t = 1.6;
clearance = 0.5;
corner_r = 6;
standoff_h = batt_t + 1;   // PCB must clear battery pouch: 13mm
air_gap = 1;               // between battery top and PCB bottom

stack_total = h_header_a7670 + h_a7670_board;   // tallest point on PCB top
case_inner_w = pcb_w + 2*clearance;
case_inner_h = pcb_h + 2*clearance;
case_inner_d = floor_t + batt_t + air_gap + standoff_h - floor_t + pcb_t + stack_total + h_keycap + clearance;
// = 1.6+12+1+(13-1.6)+1.6+12.54+2+0.5 ≈ 39.6

$fn = 64;

// PCB coord -> enclosure coord (KiCad origin at PCB corner)
function px(kx) = kx - pcb_w/2;
function py(ky) = ky - pcb_h/2;

module rbox(w, h, d, r) {
    hull() {
        for (sx=[-1,1], sy=[-1,1])
            translate([sx*(w/2-r), sy*(h/2-r), 0])
                cylinder(r=r, h=d);
    }
}

// ================= FRONT BEZEL =================
bezel_depth = 5;

difference() {
    translate([0, 0, -bezel_depth])
        rbox(case_inner_w + 2*wall, case_inner_h + 2*wall, bezel_depth + wall, corner_r);

    // hollow: through-opening for the component stack
    translate([0, 0, -bezel_depth])
        rbox(case_inner_w, case_inner_h, bezel_depth + wall + 2, corner_r - 1);

    // ---- LCD window: 3.5in panel, approx. 54.5 x 83 mm ----
    // Panel basis: 320x480 IPS FPC display, outline 54.5 x 83 mm.
    translate([px(35), py(43), 0])
        cube([56, 84, bezel_depth + 2*wall + 4], center=true);

    // ---- Trackball: front-panel module near the upper input area ----
    translate([px(8), py(68), 0])
        cylinder(d=11, h=bezel_depth + 2*wall + 4, center=true);

    // ---- Camera hole: J8 at KiCad(52,10), lens d=8 → hole 9 ----
        translate([px(52), py(10), 0])
        cylinder(d=9, h=bezel_depth + 2*wall + 4, center=true);

    // ---- Keypad 4x4: compact KMR2 switch centers match rebuild_pcb.py. ----
    for (kx=[14,28,42,56], ky=[93,105,117,129])
        translate([px(kx), py(ky), 0])
            cylinder(d=4, h=bezel_depth + 2*wall + 4, center=true);

    // ---- IR receiver window: U7 at KiCad(60,40) ----
    translate([px(60), py(40), 0])
        cylinder(d=6, h=bezel_depth + 2*wall + 4, center=true);

    // ---- POWER BUTTON (side): SW1 slide switch at KiCad(65,32) ----
    // SS12D00 actuator: ~3x2mm nub on right edge of PCB. Side slot cut
    // through bezel wall at that height. Slot 6x4mm for thumb access.
        translate([case_inner_w/2 + wall/2, py(32), -bezel_depth/2])
        cube([wall + 2, 6, 4], center=true);
}

// ================= CLEAR LENS =================
// Sits IN bezel recess: covers LCD+trackball+camera zone, 1mm acrylic
lens_t = 1.0;
translate([0, 0, 0])   // glued under bezel lip at z = -bezel_depth..-bezel_depth+lens_t
difference() {
    translate([0, py((8+12)/2 + 20), -bezel_depth + lens_t/2])
        cube([case_inner_w - 6, 60, lens_t], center=true);
}

// ================= REAR SHELL =================
translate([0, -(case_inner_h + 2*wall + 8), 0]) {
    total_depth = wall + case_inner_d;

    difference() {
        rbox(case_inner_w + 2*wall, case_inner_h + 2*wall, total_depth, corner_r);

        // main cavity down to floor
        translate([0, 0, wall])
            rbox(case_inner_w, case_inner_h, total_depth, corner_r - 1);

        // ---- USB-C: USB1 KiCad(66,50). Receptacle z spans PCB-bottom-2 to PCB-top+3.
        // PCB bottom sits at wall+batt_t+air_gap+standoff_h... compute:
        pcb_bottom_z = wall + floor_t + batt_t + air_gap;   // 13.2? no:
        // floor is solid up to wall+floor_t; battery bay recessed into that.
        // Simpler: cavity floor at z=wall+floor_t. Battery 12mm. gap 1. PCB bottom
        // rests on standoffs of height standoff_h measured from cavity floor:
        // pcb_z = wall + floor_t + standoff_h = 2+1.6+13 = 16.6
        // USB-C mid-shell z ≈ pcb_z ± 3:
        translate([px(66), -case_inner_h/2 - wall - 1, 16.6])
            cube([10.5, 8, 5], center=true);   // 10.5 wide, deep enough to pierce wall

        // ---- LTE carrier interface is at J1 KiCad(10,20), left/top region ----
        translate([-case_inner_w/2 - wall/2, py(20), 16.6])
            cube([wall + 2, 8, 5], center=true);

        // ---- LoRa carrier interface is at J3 KiCad(40,90) ----
        translate([-case_inner_w/2 - wall/2, py(90), 16.6])
            cube([wall + 2, 8, 5], center=true);

        // ---- POWER BUTTON side slot in SHELL too: SW1 KiCad(65,32) ----
        // Shell z-range for the switch actuator:
        //   PCB bottom z = wall+floor_t+standoff_h = 2+1.6+13 = 16.6
        //   switch body height above PCB ≈ 3.5 → slot centered ≈ 16.6+1.75
        translate([case_inner_w/2 + wall/2, py(32), 18.4])
            cube([wall + 2, 6, 5], center=true);

        // ---- SD card slot right side: J9 at KiCad(68,20) ----
        translate([case_inner_w/2 + wall/2, py(20), 14.0])
            cube([wall + 2, 16, 2.6], center=true);

        // ---- SIM access right side: J10 at KiCad(62,75) ----
        translate([case_inner_w/2 + wall/2, py(75), 14.0])
            cube([wall + 2, 14, 2.6], center=true);

        // ---- Battery bay: pouch UNDER pcb, sits on cavity floor ----
        // centered horizontally; from bottom edge upward
        translate([0, -case_inner_h/2 + clearance + batt_l/2,
                   wall + floor_t + batt_t/2])
            %cube([batt_w, batt_l, batt_t], center=true);

        // ---- JST-XH battery lead exit bottom edge, offset from USB-C ----
        translate([px(20), -case_inner_h/2 - wall/2, wall + floor_t + 1.5])
            cube([8, wall + 2, 3], center=true);

        // ---- Speaker/mic holes optional bottom-right grid ----
        for (i=[-2:2])
            translate([px(52) + i*3, -case_inner_h/2 + 6, wall + floor_t/2])
                cylinder(d=1.5, h=floor_t*2, center=true);
    }

    // ---- Standoffs: 4 corners, M2 bosses, height puts PCB above battery ----
    // Must match mounting holes added to PCB at KiCad(6,6),(70,6),(6,154),(70,154)
    for (kx=[6, 70], ky=[6, 154])
        translate([px(kx), py(ky), wall + floor_t])
            difference() {
                cylinder(d=6, h=standoff_h);
                translate([0, 0, standoff_h - 6])
                    cylinder(d=2.2, h=7);   // M2 self-tap pilot
            }

    // ---- Battery strap slots (2x silicone/velcro strap cross-over) ----
    for (sy=[-18, 18])
        difference() {
            translate([0, sy, wall + floor_t - 0.01])
                cube([batt_w + 6, 4, 1.2], center=true);
        }
}

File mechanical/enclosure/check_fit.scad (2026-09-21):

// Subtract 0.001 mm from pod seating depth to exclude coplanar CGAL artifacts.
use <enclosure.scad>
check="halves";
if(check=="halves") intersection() {
 rear();
 translate([0,0,38.8]) mirror([0,0,1]) front();
}
if(check=="cover") intersection() {
 rear();
 translate([-3,-10,0]) port_cover();
}
if(check=="pod") intersection() {
 rear();
 translate([-3,-10,1.199-18]) module_pod();
}
if(check=="battery") intersection() {
 rear();
 translate([0,-51,3.201]) linear_extrude(12) square([67,38],center=true);
}

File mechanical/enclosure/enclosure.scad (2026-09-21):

// Pocket Rev F: millimetres, +Y towards phone top, rear exterior at Z=0.
include <pcb_geometry.scad>
part = "layout"; // [layout,rear,front,port_cover,module_pod,assembly,with_module,fit]
$fn=48;
wall=2.4; floor_t=2.4; face_t=2.4; fit=0.6; pcb_t=1.6;
// MakerFocus 3000 mAh: 65x36x10 nominal, +2 mm manufacturer tolerance.
battery=[67,38,12]; battery_center=[0,-51];
tray_floor=0.8; rear_component_gap=2.1;
pcb_z=floor_t+tray_floor+battery[2]+rear_component_gap;
// Reserve LTE carrier + provisional display thickness + assembly clearance.
lte_height=12.44; display_thickness=4; stack_clearance=1.06;
front_clearance=lte_height+display_thickness+stack_clearance;
seam_z=pcb_z+pcb_t+front_clearance;
height=seam_z+face_t;
iw=pcb_w+2*fit; ih=pcb_h+2*fit;
ow=iw+2*wall; oh=ih+2*wall;
inner_r=1; outer_r=3.4; bevel=1.0;
display_center=[0,30]; display_window=[50,76];
display_outline=[61,92.44]; // documented panel envelope; measure thickness
trackball_center=[-4.5,-23]; trackball_d=11;
port=[24,14]; dock=[68,44]; dock_recess=1.2; dock_fit=0.3;
module_depth=18; module_wall=2.4;
// Asymmetric third locator prevents rotating the cover/pod 180 degrees.
dock_screws=[[-29,0],[29,0]];
module_origin=expansion;
module profile(w,h,r) { offset(r=r) square([w-2*r,h-2*r],center=true); }
module rounded(w,h,z,r=3) { linear_extrude(z) profile(w,h,r); }
module body(z) {
 // Bevel exposed bed-side perimeter; wall remains full thickness at PCB plane.
 hull() {
  rounded(ow-2*bevel,oh-2*bevel,0.01,outer_r-bevel);
  translate([0,0,bevel]) rounded(ow,oh,0.01,outer_r);
 }
 translate([0,0,bevel]) rounded(ow,oh,z-bevel,outer_r);
}
module dock_at() { translate([module_origin[0],module_origin[1],0]) children(); }
module rear() {
 difference() {
  union() {
   difference() {
    body(seam_z);
    translate([0,0,floor_t]) rounded(iw,ih,seam_z,inner_r);
   }
   for(p=mounts) translate([p[0],p[1],floor_t-0.1]) cylinder(d=5.6,h=pcb_z-floor_t+0.1);
   // Low, rounded battery cradle: no hard lid pressing on the pouch.
   translate([battery_center[0],battery_center[1],floor_t-0.05]) {
    rounded(battery[0]+5,battery[1]+5,tray_floor+0.05,3);
    difference() {
     rounded(battery[0]+5,battery[1]+5,3.2,3);
     translate([0,0,tray_floor]) rounded(battery[0]+1.6,battery[1]+1.6,4,2);
     // Lead exit at top, well clear of the J16 opening.
     translate([0,battery[1]/2,3]) cube([14,10,6],center=true);
    }
   }
   // Strap bridges beside cradle; transverse slots are cut below.
   for(x=[-1,1]) translate([battery_center[0]+x*(battery[0]/2+5),battery_center[1],floor_t-0.1])
    rounded(6,13,4.1,1.2);
   dock_at() for(p=dock_screws) translate([p[0],p[1],floor_t-0.1]) cylinder(d=7.5,h=4.5);
  }
  for(p=mounts) translate([p[0],p[1],pcb_z-9]) cylinder(d=1.7,h=10);
  // Recessed plug approach and actuator access, radiused to reduce stress risers.
  translate([ow/2+1,usb[1],pcb_z+2]) rotate([0,-90,0])
   linear_extrude(wall*3) profile(7,12,1.5);
  translate([ow/2+1,power[1],pcb_z+3]) rotate([0,-90,0])
   linear_extrude(wall*3) profile(6,9,1.2);
  dock_at() {
   translate([0,0,-0.01]) rounded(dock[0]+2*dock_fit,dock[1]+2*dock_fit,dock_recess+0.01,3);
   translate([0,0,-1]) rounded(port[0],port[1],floor_t+2,2);
   for(p=dock_screws) {
    translate([p[0],p[1],-1]) cylinder(d=2.3,h=9);
    // Captive M2 hex nut, inserted from inside before PCB installation.
    translate([p[0],p[1],4.3]) cylinder(d=4.8,h=4,$fn=6);
   }
   translate([-23,15,-0.1]) cylinder(d=2.5,h=2.5);
  }
  for(x=[-1,1]) translate([battery_center[0]+x*(battery[0]/2+5),battery_center[1],floor_t+1.5])
   cube([9,9,1.8],center=true);
 }
}
// Print outer face on bed. Mirror only Z for assembly; retain all XY datums.
module front() {
 difference() {
  union() {
   body(face_t);
   for(p=mounts) translate([p[0],p[1],face_t-0.1]) cylinder(d=5.6,h=front_clearance+0.1);
   // Perimeter tongue seats below seam, above all PCB edges.
   translate([0,0,face_t-0.1]) difference() {
    rounded(iw-0.5,ih-0.5,1.7,1.2);
    translate([0,0,-0.1]) rounded(iw-3.3,ih-3.3,2,1);
   }
   // Four panel location tabs; foam tape retains measured display on the ledge.
   for(x=[-1,1],y=[-1,1])
    translate([display_center[0]+x*(display_outline[0]/2+1),display_center[1]+y*32,face_t-0.1])
     rounded(1.6,9,2.5,0.5);
  }
  translate([display_center[0],display_center[1],-1]) rounded(display_window[0],display_window[1],face_t+2,2);
  translate([trackball_center[0],trackball_center[1],-1]) cylinder(d=trackball_d,h=face_t+2);
  for(p=keys) translate([p[0],p[1],-1]) cylinder(d=4.6,h=face_t+2);
  for(p=mounts) {
   translate([p[0],p[1],-1]) cylinder(d=2.3,h=front_clearance+face_t+2);
   translate([p[0],p[1],-0.01]) cylinder(d=4.2,h=1.1);
  }
 }
}
// Cover prints exterior-down, and sits flush in the rear pocket.
module port_cover() {
 difference() {
  union() {
   rounded(dock[0],dock[1],dock_recess,3);
   // Locator pin and shallow port plug support thin flush face.
   translate([-23,15,dock_recess-0.1]) cylinder(d=1.9,h=1.1);
   rounded(port[0]-0.6,port[1]-0.6,2.2,1.7);
  }
  for(p=dock_screws) translate([p[0],p[1],-1]) cylinder(d=2.3,h=4);
 }
}
// External pod: open side faces host, opening protected by host rear wall.
// Envelope 68x44x18; cable plugs into J16 before screwing pod to host.
module module_pod() {
 difference() {
  union() {
   difference() {
    rounded(dock[0],dock[1],module_depth,3);
    translate([0,0,module_wall]) rounded(dock[0]-2*module_wall,dock[1]-2*module_wall,module_depth,1);
   }
   for(p=dock_screws) translate([p[0],p[1],0]) cylinder(d=7.5,h=module_depth);
   translate([-23,15,module_wall-0.1]) cylinder(d=4,h=module_depth-module_wall+0.1);
   translate([-23,15,module_depth-0.1]) cylinder(d=1.9,h=1.1);
   // Strap anchors for removable module retention, no fixed module hole pattern.
   for(y=[-1,1]) translate([0,y*16,module_wall-0.1]) rounded(14,5,4.1,1);
  }
  for(p=dock_screws) {
   translate([p[0],p[1],-1]) cylinder(d=2.3,h=module_depth+2);
   translate([p[0],p[1],-0.1]) cylinder(d=4.5,h=1.3);
  }
  for(y=[-1,1]) translate([0,y*16,module_wall+1.7]) cube([10,8,1.8],center=true);
 }
}
module assembly(with_pod=false) {
 color("#314753") rear();
 color("#62838a") translate([0,0,height]) mirror([0,0,1]) front();
 dock_at() color("#de9c46")
  if(with_pod) translate([0,0,dock_recess-module_depth]) module_pod();
  else port_cover();
}
module fit_view() {
 assembly();
 %translate([0,0,pcb_z]) linear_extrude(pcb_t) square([pcb_w,pcb_h],center=true);
 %translate([battery_center[0],battery_center[1],floor_t+tray_floor]) rounded(battery[0],battery[1],battery[2],2);
 %translate([display_center[0],display_center[1],seam_z-display_thickness]) rounded(display_outline[0],display_outline[1],display_thickness,1);
}
assert(pcb_z-floor_t-tray_floor-battery[2]>=rear_component_gap-0.001);
assert(battery_center[1]+battery[1]/2+2.5 < expansion[1]-port[1]/2-1,"Battery overlaps port");
assert(display_center[1]+display_outline[1]/2 < ih/2-0.5,"Panel hits rim");
echo(body_mm=[ow,oh,height], module_added_depth=module_depth-dock_recess);
if(part=="rear") rear();
else if(part=="front") front();
else if(part=="port_cover") port_cover();
else if(part=="module_pod") module_pod();
else if(part=="assembly") assembly();
else if(part=="with_module") assembly(true);
else if(part=="fit") fit_view();
else if(part=="layout") {
 translate([-ow/2-5,0,0]) rear();
 translate([ow/2+5,0,0]) front();
 translate([-40,-oh/2-30,0]) port_cover();
 translate([40,-oh/2-30,0]) module_pod();
} else assert(false,"Unknown part");

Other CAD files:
mechanical/handset/exports/visual_ball.stl
mechanical/handset/exports/visual_screws.stl
mechanical/enclosure/pcb_geometry.scad
archive/enclosure/first-revf/enclosure.scad
archive/enclosure/first-revf/pcb_geometry.scad
mechanical/handset/appearance.scad
mechanical/handset/check_fit.scad
mechanical/handset/handset.scad

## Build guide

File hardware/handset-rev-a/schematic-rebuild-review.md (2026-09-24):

# Schematic rebuild — 24 September 2026

Later checkpoint: the [CC1101 circuit completion](cc1101-review.md) supersedes
the CC1101 missing-circuit entry and numerical counts in this rebuild snapshot.

All active schematic sheets have been rebuilt into a system index and 21
functional sheets. The 192-component population, ESP32-S3-N16R8, external
display, radio interfaces, top speaker/bottom microphone and expansion
connector are retained. This is an engineering draft, not a completed or
fabrication-ready electrical design.

Open [the schematic PDF](generated/handset-schematic.pdf) or
[the KiCad project](generated/handset.kicad_pro). The previous project is
snapshotted under `archive/handset-before-schematic-rebuild/`; the exact
snapshot and source hashes are in
[schematic-rebuild.json](generated/schematic-rebuild.json).

## Changes with electrical significance

| Reference | Correction | Basis |
|---|---|---|
| U4.1 | SX1262 VDD_IN connects to +3V3, separate from VREG | Semtech AN1200.40 SX1262 reference PA supply |
| U9.5 | HTRC110 MODE connects to ground for a short local interface | NXP HTRC110 application circuit |
| D1 | Unidirectional cathode/anode symbol replaces bidirectional TVS depiction; cathode remains USB_FUSED | Diotec SMF5.0A |
| U8.6 | MAX17048 QSTRT is an input tied to ground when unused | Analog Devices pin description |
| U6.17 | MAX98357A exposed ground pad is represented as a power input | Grounded exposed-pad connection |
| U20.8 | Internally paralleled VOUT terminal is passive; pin 7 retains the output-driver type | TPS63070 pin definition; both remain MODEM_SUPPLY |

Only U4.1 and U9.5 change PCB pad nets. Symbol electrical types were corrected
to describe the selected devices; unfinished radio inputs were not marked NC
or retyped to suppress their errors. Power flags identify actual external USB
and protected-pack sources through passive fuses and their ground return.
They do not assert that power distribution has been routed or qualified.

The charger, MCU boot/reset and main 3.3 V sheets now show explicit circuit
wiring; the keypad has a drawn 4 × 4 matrix. Other sheets group actual parts,
shared bypass banks and named interfaces. The display connector has a shared
ground bus. Those presentation changes do not complete missing RF networks.

## Verification

- All 192 parts appear exactly once. Exported KiCad pin nets match the design
  manifest, including individually isolated no-connect pins.
- 1,825 schematic/PCB integrity assertions pass; native schematic/PCB parity
  has zero findings.
- All 196 physical footprints, including four mounting holes, retain their
  positions, orientation, package, values and pad geometry. All 792 existing
  copper items retain their UUIDs, geometry and nets.
- Local power-entry continuity passes for 113 pads; main 3.3 V continuity
  passes for 26 pads. External distribution is excluded from these local tests.
- The charger register contract and five unsafe-policy negative tests pass.
  This is not implemented or tested charger firmware.
- Native ERC retains 37 findings: 31 isolated labels and six undriven inputs.
  Native DRC retains four USB connector internal hole-clearance findings and
  445 unconnected items. The extra airwire relative to the power-entry
  checkpoint follows the intentional pin-net corrections, not removed copper.

No ERC/DRC exclusions were added. The release gate stays closed.

## Electrical work still required

| Circuit | Missing implementation or qualification |
|---|---|
| SX1262 | 32 MHz clock, DCC/VREG power components, PA/RX matching, RF switch and 50-ohm feed. Freeze one manufacturer reference BOM and stackup. |
| CC1101 | 26 MHz crystal and load network, differential-to-single-ended matching/filter and antenna feed; resolve optional GDO2 handling. |
| HTRC110 | Oscillator, QGND/CEXT bypass, coil resonance/receive network, and a timing-capable host path. Expander-driven control is not evidence of working LF read/write timing. |
| NFC | Case-loop impedance, TX matching, receive divider/network and assembled-case tuning. |
| Host interfaces | Resolve RFID_DOUT_3V3, TRACKBALL_INT and MODEM_STATUS endpoints without breaking the ESP32 boot/PSRAM constraints. |
| Battery / USB | Implement charger firmware and fault handling; verify the actual pack and NTC. Powered-off charging, legacy-source recovery and modem burst-current budget remain open. |
| Other supplies | Finish auxiliary and modem converter layout; qualify effective capacitance, current, stability and thermal limits. |
| Cellular | Implement the actual replaceable modem adapter, SIM/RF/audio/logic translation and carrier-specific VoLTE qualification. |
| Display / peripherals | Verify purchased display/touch FPC option, firmware and all connector polarities; finish storage, IR, GNSS and protected expansion routing. |
| Release | Finish all routing and antenna coexistence work; independently review symbols, footprints, exact passive BOM and mechanical fit. |

The next electrical completion work is the radio frontends and LF host timing
allocation. A tidy schematic or a reduced ERC count is not a substitute for
those circuits.

## Manufacturer references

- [Semtech SX1262 reference-design entry](https://www.semtech.com/products/wireless-rf/lora-connect/sx1262mb2cas)
- [Semtech AN1200.40, manufacturer-authored distributor copy](https://cdn-reichelt.de/documents/datenblatt/A200/SX1262REFERENCE.pdf)
- [NXP HTRC110](https://www.nxp.com/docs/en/data-sheet/037031.pdf)
- [Analog Devices MAX17048/MAX17049](https://www.analog.com/media/en/technical-documentation/data-sheets/MAX17048-MAX17049.pdf)
- [Analog Devices MAX98357A/MAX98357B](https://www.analog.com/media/en/technical-documentation/data-sheets/MAX98357A-MAX98357B.pdf)
- [TI TPS63070](https://www.ti.com/lit/ds/symlink/tps63070.pdf)
- [Diotec SMF5.0A](https://diotec.com/files/diotec/productfiles/datasheet/smf50a.pdf)
- [TI CC1101](https://www.ti.com/lit/ds/symlink/cc1101.pdf)
- Power-entry component references and limitations: [power-entry-review.md](power-entry-review.md).

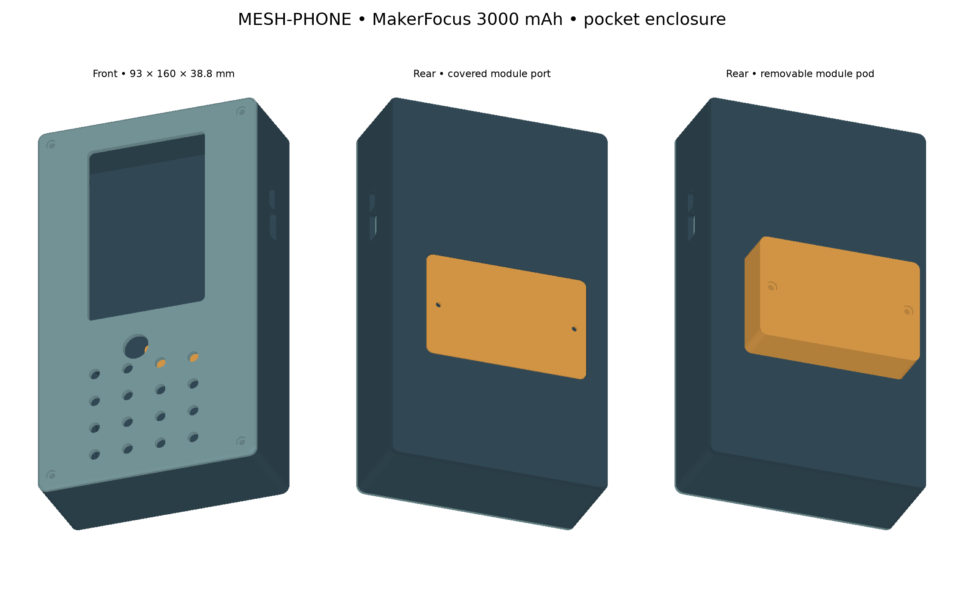
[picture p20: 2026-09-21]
mechanical/enclosure/exports/assembled.png

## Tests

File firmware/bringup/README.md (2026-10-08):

# ESP32-S3 keypad bring-up application

Cross-built with ESP-IDF v5.4.2 for the handset's ESP32-S3-WROOM-1-N16R8.
This application provides I²C keypad scanning, GPIO interrupts, USB event logs
and explicit start/stop/recovery commands. It has **not been flashed or tested
on hardware**. The incomplete PCB remains blocked for fabrication and power-up.

## Build and evidence

Install [ESP-IDF v5.4.2](https://docs.espressif.com/projects/esp-idf/en/v5.4.2/esp32s3/get-started/linux-macos-setup.html)
and its ESP32-S3 tools. The build script checks SDK commit
`f5c3654a1c2d2a01f7f67def7a0dc48e691f63c0`.

```sh
. /path/to/esp-idf/export.sh
bash firmware/bringup/build.sh /tmp/handset-esp32-bringup
python scripts/check_handset_bringup.py
python scripts/check_handset_keypad_firmware.py
```

Outputs include `handset_keypad_bringup.bin`, its ELF, bootloader, partition
table and `flasher_args.json`. Use the complete generated flash layout after
hardware commissioning approval; the application binary alone is not a full
flash image. This build does not flash a device or alter eFuses.

The configuration uses 16 MB flash, DIO at 40 MHz, internal RAM and no sleep.
PSRAM is unused. SDK/bootloader console logs are disabled; the application owns
the USB Serial/JTAG driver. UART console output is not configured. ROM behavior
before this application starts is outside its control.

`validation/build-report.json` records the SDK/compiler, source hashes,
image hashes, image target, flash size and build configuration checks.
`validation/python-packages.txt` records the Python build environment.
`validation/host-tests.json` records session/command tests and the GPIO contract.
The tests reject the formerly documented but incorrect GPIO18 IRQ mapping.

## Wiring and ownership

| Function | ESP32 GPIO | Module pad |
| --- | --- | --- |
| SDA | 10 | U1.18 |
| SCL | 9 | U1.17 |
| Keypad IRQ | 8 | U1.12 |
| USB D− / D+ | 19 / 20 | U1.13 / U1.14 |

The GPIO contract is checked against the native schematic and connectivity
manifest. Only U2 at I²C address 0x34 is accessed, at 100 kHz using R3/R4 external
pull-ups. Transfers have 20 ms timeouts. The scanner task owns the synchronous
[I²C master driver](https://docs.espressif.com/projects/esp-idf/en/v5.4.2/esp32s3/api-reference/peripherals/i2c.html).
The IRQ handler only wakes that task. Polling every 10 ms covers a missed edge;
a still-low IRQ schedules another batch with a mandatory scheduler yield.
Each driver call reads at most ten events. Poll/service timing needs measurement
on the assembled board; these settings are not a throughput guarantee.

No radio, modem, display, media, charger, expansion or backlight enable is
commanded. U2 GPIO direction/output registers remain untouched. The application
does not replace the STM32 power supervisor or the future full handset firmware.
It does not reset shared MCU_EN automatically.

## USB commissioning interface

After the hardware is approved, powered correctly and the full image programmed,
connect its [native USB Serial/JTAG port](https://docs.espressif.com/projects/esp-idf/en/v5.4.2/esp32s3/api-guides/usb-serial-jtag-console.html).
Use the SDK Python environment, which includes pyserial:

```sh
python firmware/bringup/monitor.py /dev/ttyACM0
```

The monitor does not toggle DTR/RTS intentionally, flash the board or start
scanning automatically. Port naming is host-dependent. Send LF-terminated
commands (CRLF also works):

- `status`: report active/valid state, held-key bitmap, IRQ level and log drops.
- `start`: with **all keys released**, initialize U2 and begin scanning. A second
  start during an active session is rejected so it cannot silently flush keys.
- `stop`: stop host scanning, disable its IRQ and invalidate held-key state.
  This does not assert hardware reset or guarantee that U2 stops its own scan.

Each event identifies SW1–SW16, zero-based row/column and PRESS/RELEASE.
Held-mask bit zero is SW1; bit fifteen is SW16. Status repeats once a second,
including while idle. Fault values are 0 ready, 1 reset/configuration required,
2 FIFO overflow, 3 invalid event, and 4 transfer error. On a fault, host scanning
stops and the held-key state becomes invalid. Release all keys, resolve the
cause, then explicitly start again. Setup failures require reset/reboot.

USB runs in a separate task with bounded queues and nonblocking writes. A slow
or disconnected host can lose records without blocking scanning. Sequence gaps
and `queue_drop` / `usb_drop` counters expose losses; a partial record is followed
by a new line. `usb_drop` also counts rejected commands when its queue is full.
Discard incomplete records and treat gaps as lost diagnostic evidence. This is
not a lossless event recorder or UI action pipeline.

Commission one switch at a time first. Verify every press/release, a held key,
stop/start, USB disconnect/reconnect, absent U2, reset and FIFO overflow. The
matrix has no per-key diodes; arbitrary multi-key rollover is not established.
Mechanical fit, IRQ timing, debounce, electrical noise and USB signal integrity
still need bench qualification.

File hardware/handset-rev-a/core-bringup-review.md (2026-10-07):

# Boot/reset and control-chip routing checkpoint

2026-10-07. **Engineering checkpoint; not released for fabrication or power-up.**

Follow-up: the matrix connections are completed in the
[keypad routing checkpoint](keypad-routing-review.md); target firmware and bench
qualification remain open.

The ESP32 boot pull-up and both service buttons now have copper connections.
U2 (TCA8418) has 3.3 V, exposed-pad/pin ground, shared MCU reset, SDA, SCL and
an interrupt connection to the ESP32. R5 supplies the interrupt pull-up.
The existing 10 kΩ EN pull-up and 1 µF reset capacitor are retained.
This enables the next control-firmware work; it does not demonstrate working
USB programming, display operation or keypad scanning on hardware.

## Layout changes

- R2 moves from (98, 62) to (98.8, 63.3) mm on the back to provide routing access.
- C4 moves from (128, 119) mm on the front to (123.5, 117.6) mm on the back,
  beside U2's supply fanout. No component or schematic net is changed.
- All duplicate physical button contacts are connected explicitly. Ground
  returns use through vias outside the component pads and lower-board pours.
- The crowded U2 pins use explicit fanout and ordinary 0.5 mm / 0.3 mm drilled
  through vias. No via-in-pad processing is introduced.
- One existing KEY_COL3 segment is split and locally rerouted around the new
  vias. Its lower trunk and branch connections are retained. All other existing
  tracks/vias retain their UUID, geometry and net assignments.
- Routing uses outer and inner signal segments. The USB reference region is
  excluded from new inner routing; the independent USB reference checks remain
  required. The added lower-board ground fills do not establish full-board
  return-path qualification.

`generated/core-routing.json` records the source/final hashes, moved parts,
rerouted segment and incremental route lengths. Route lengths are router
segments, not complete electrical path measurements; manual fanout is additional.

## Checks

`check_handset_core.py` reads actual PCB connectivity, including every duplicate
physical switch pad. It verifies the seven bring-up net groups, pull-up/bypass
values and local bypass placement. `test_handset_core.py` exercises eight cases:
installed routing, open boot pull-up, individual boot/reset contact opens,
controller supply/reset opens, wrong pull-up value and swapped bus assignments.
Both run in the main PCB check script. The manufacturing release gate checks
core connectivity independently of the saved routing manifest.

The original connected-pad groups are compared with the staged board before
installation; none may lose a connection. Existing display, backlight,
expansion, USB and power checks also remain required. Native DRC and schematic
parity must be zero under the unchanged project rules.

Saved checkpoint results: 2,537/2,537 integrity assertions; zero native DRC
violations and zero parity findings; eight core regression cases pass. All 642
previous connected-pad groups are preserved. Unconnected items drop from 279
to 258. The existing 30 ERC findings and 11 engineering blocker groups remain.

## Remaining bring-up work

The bottom-edge buttons create long boot/reset nets. Qualify noise/ESD immunity,
reset timing, supply rise/fall behavior and recovery from repeated power cycles
before release. The RC values alone do not establish reliable reset under a
slow or unstable supply. The [Espressif schematic checklist](https://docs.espressif.com/projects/esp-hardware-design-guidelines/en/latest/esp32s3/schematic-checklist.html)
is the reference for EN and boot-strapping review.

U2's active-low RESET and open-drain interrupt wiring follow the
[TI TCA8418 datasheet](https://www.ti.com/lit/ds/symlink/tca8418.pdf).
The keypad matrix still needs completion. Firmware must probe U2, configure its
GPIO/keypad functions, establish safe display/backlight defaults and service
interrupts. Do not enable the backlight before the panel/power sequence has been
qualified. Bus timing and signal integrity are not verified by CAD continuity.

After the overall hardware is approved for controlled commissioning, verify
rails and reset first, then test manual ROM-download entry using BOOT and RESET,
USB enumeration, programming, U2 communications and individual control outputs.
This is a future bench sequence, not permission to power the current incomplete
board. All open release blockers in `release-blockers.json` remain applicable.

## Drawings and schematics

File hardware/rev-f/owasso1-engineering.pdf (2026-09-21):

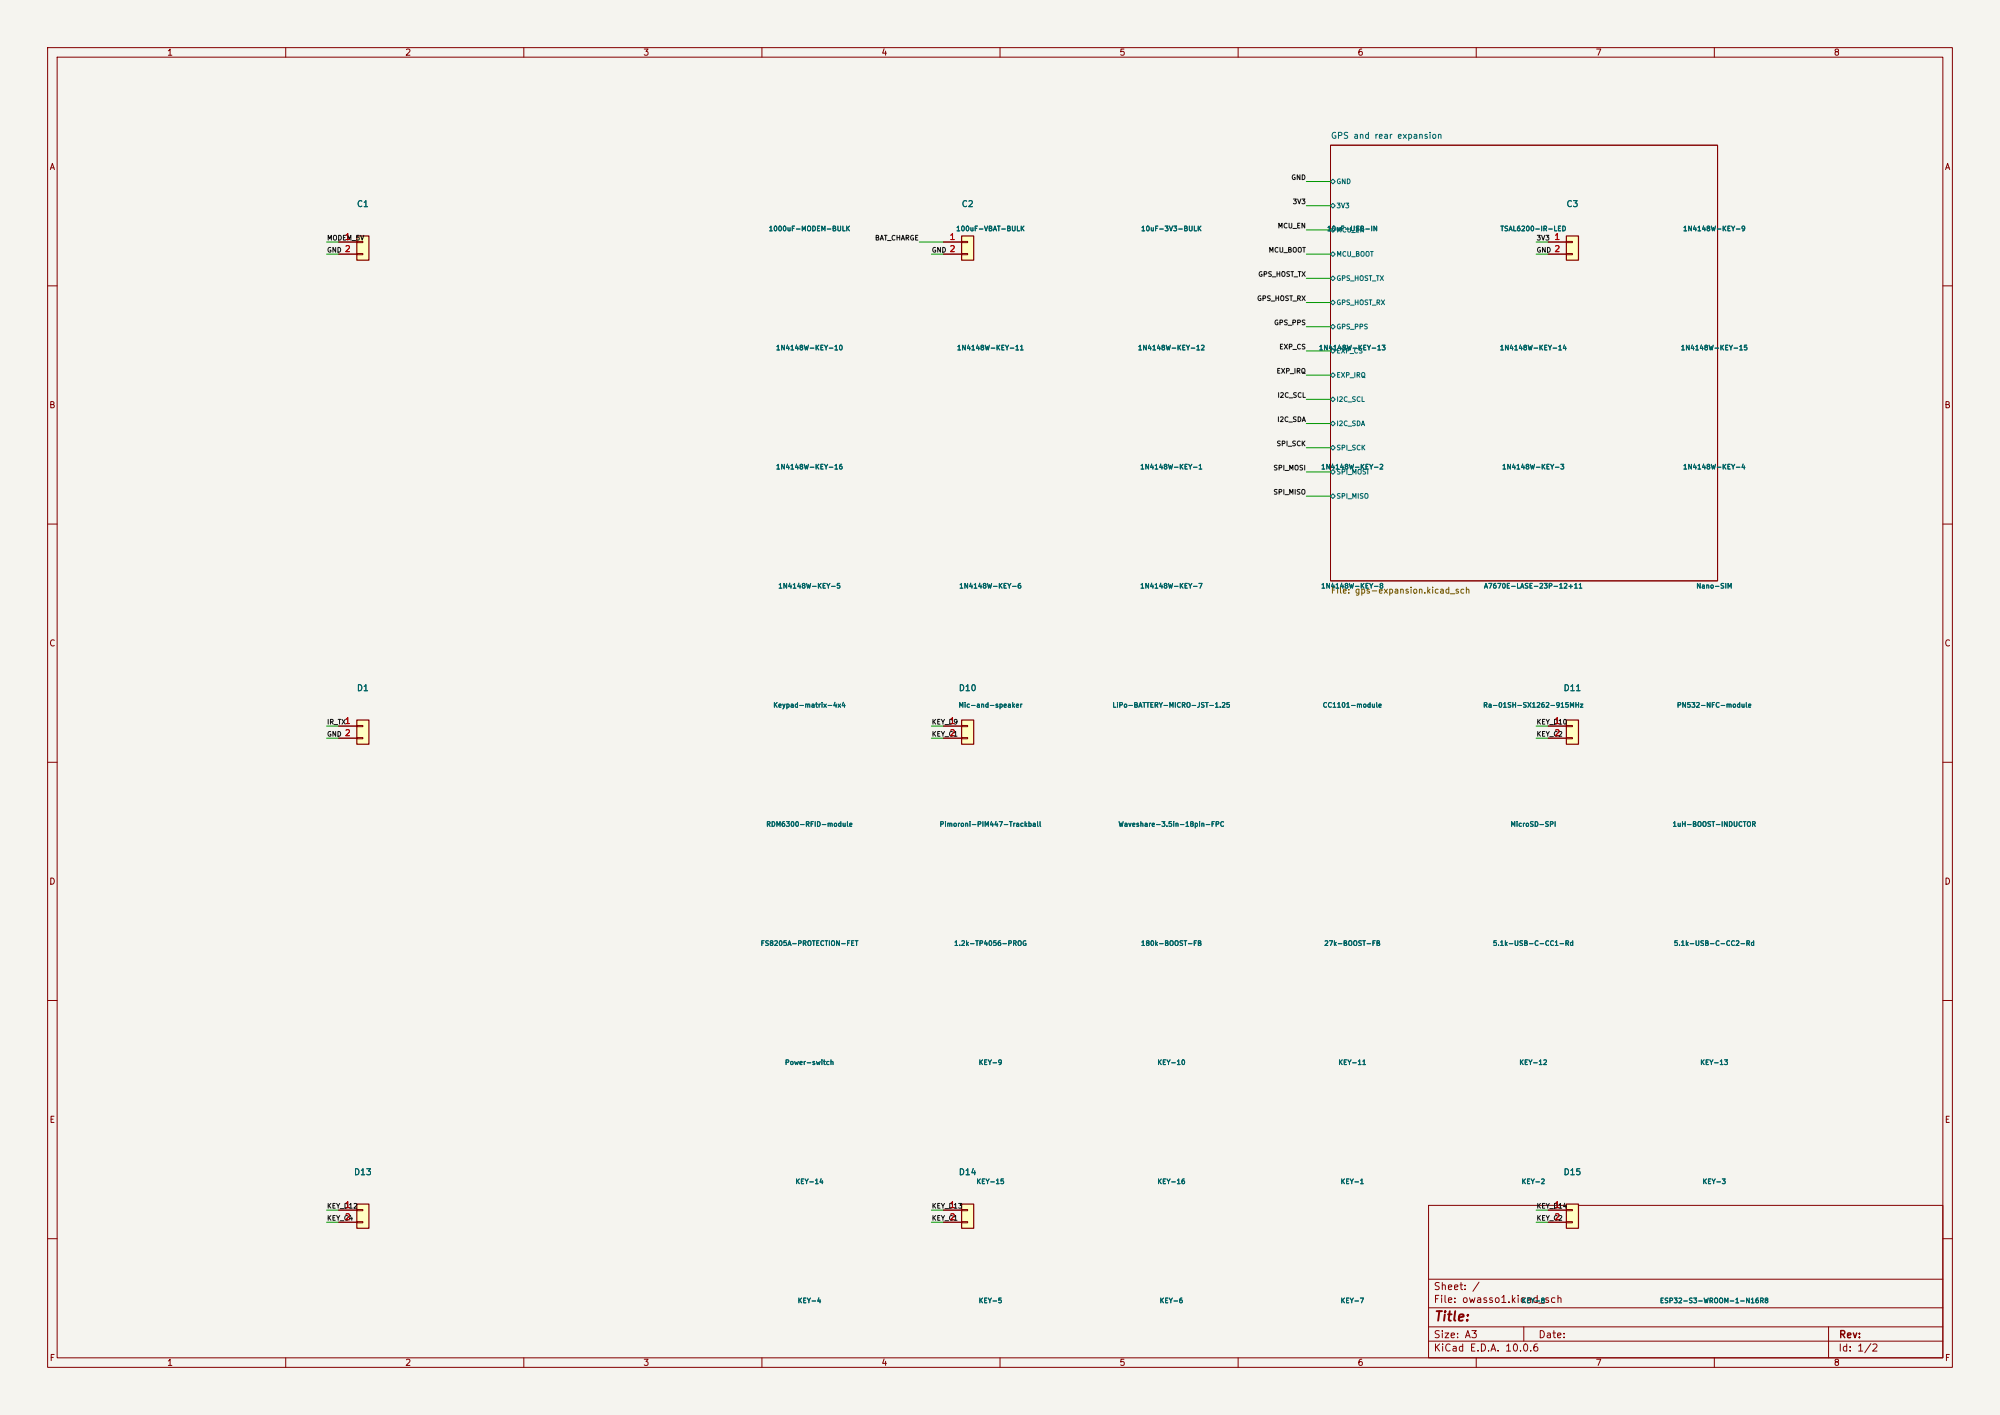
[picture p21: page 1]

SPI_MOSI SPI_MISO GPS and rear expansion
3V3 MCU_EN MCU_BOOT GPS_HOST_TX GPS_HOST_RX GPS_PPS

LiPo-BATTERY-MICRO-JST-1.25

Size: A3 | Rev: | F Date:
KiCad E.D.A. 10.0.6 | Id: 1/2

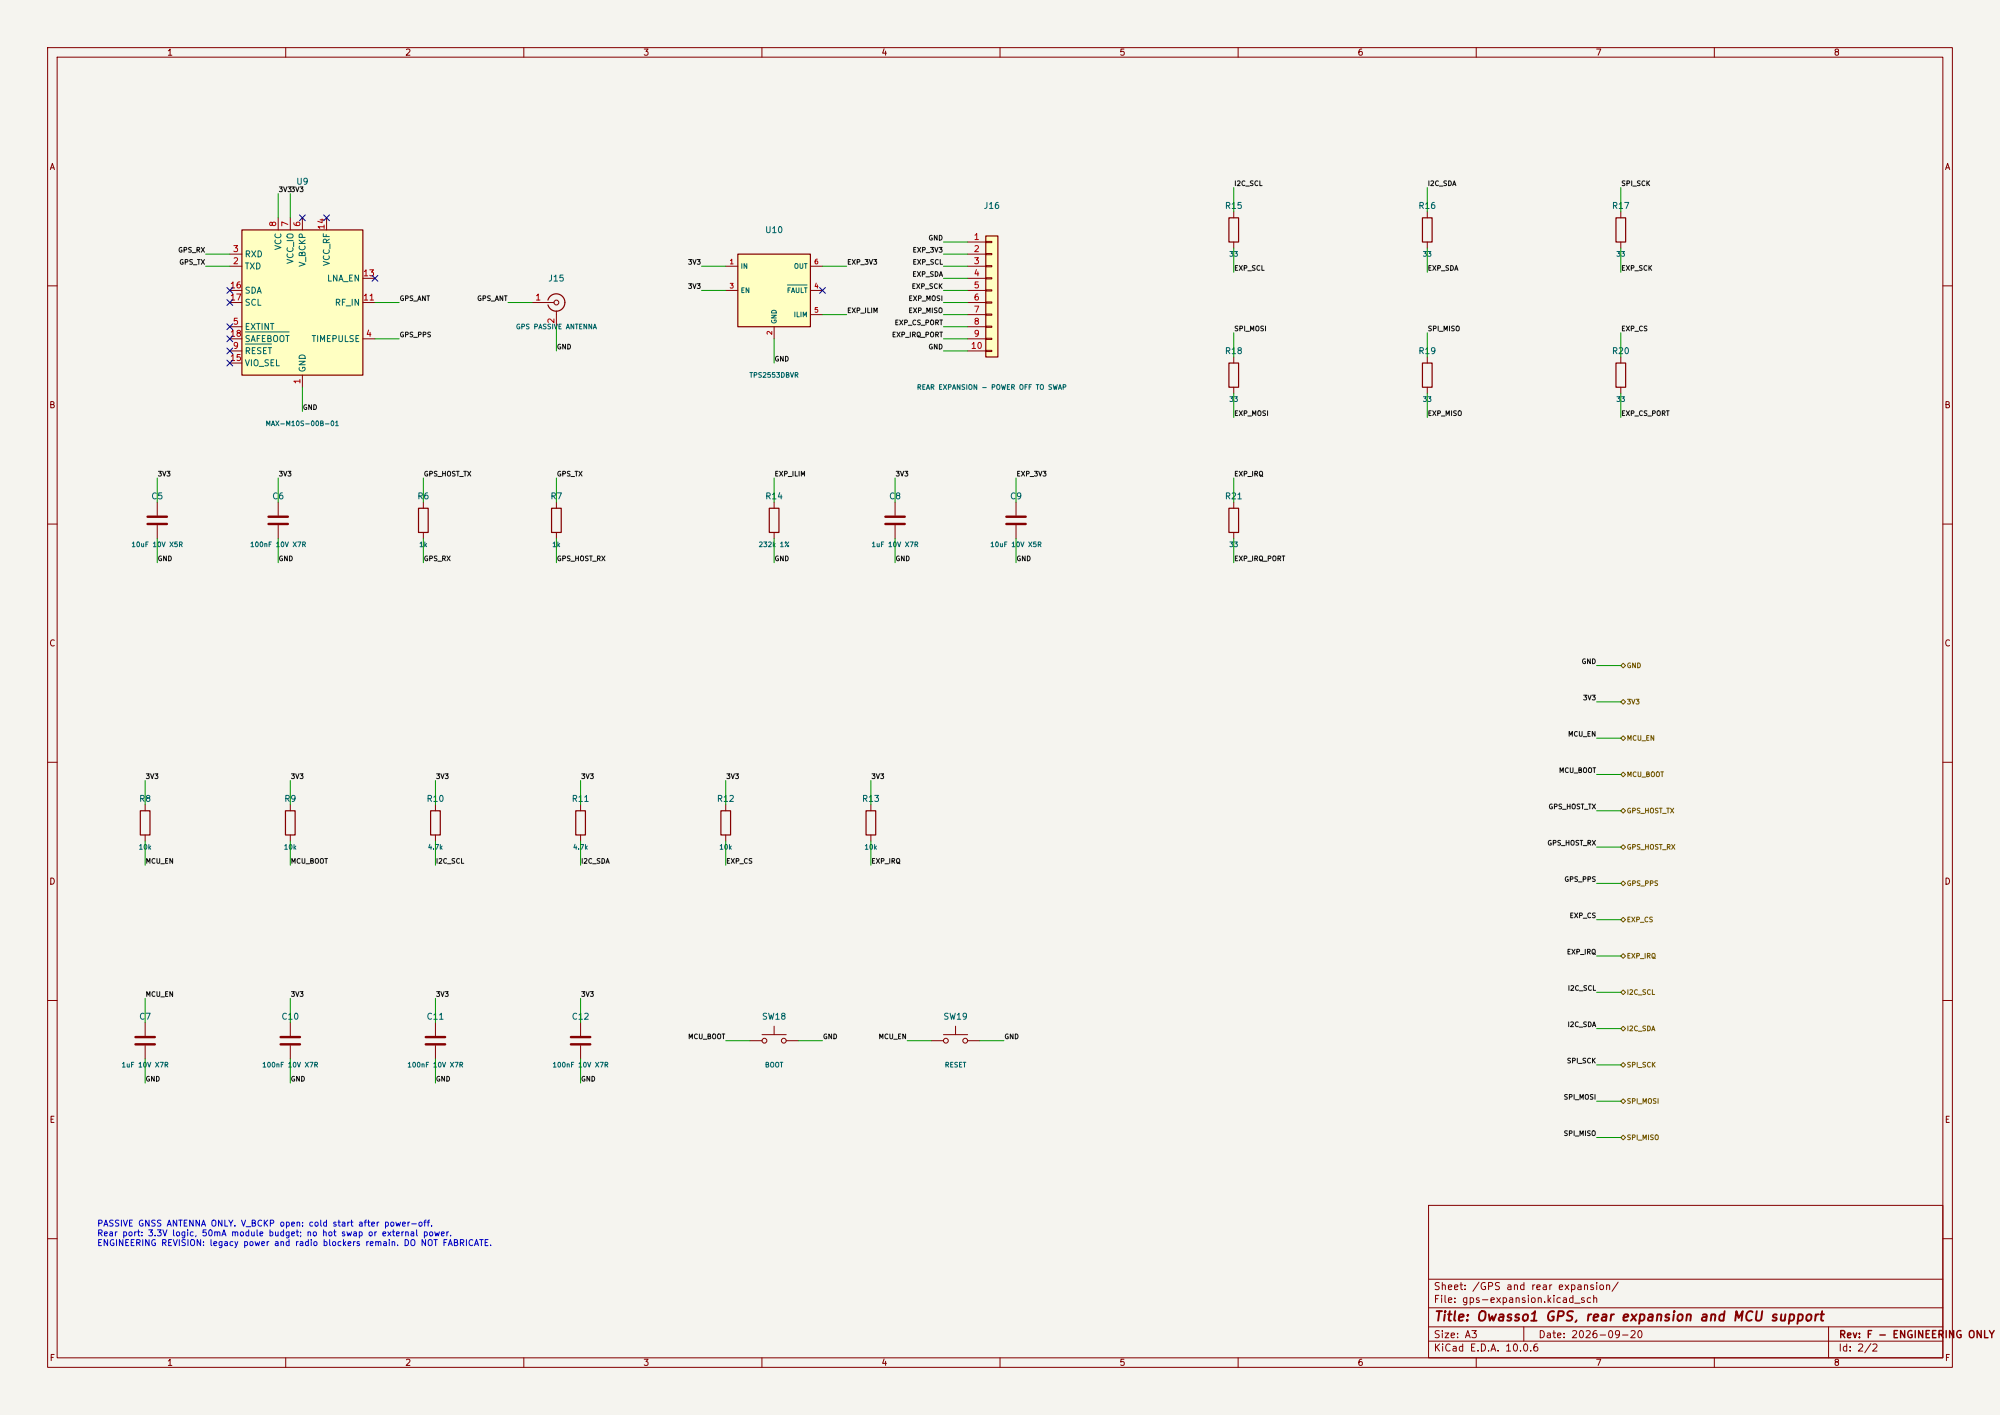
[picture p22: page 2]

REAR EXPANSION - POWER OFF TO SWAP C11

Sheet: /GPS and rear expansion/
File: gps-expansion.kicad_sch
Title: Owasso1 GPS, rear expansion and MCU support

F Date: 2026-09-20

KiCad E.D.A. 10.0.6 | Id: 2/2

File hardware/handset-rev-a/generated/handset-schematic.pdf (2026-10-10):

1 | 2 | 3 | 4 | 5 | 6 | 7 | 8 | 9 | 10 | 11
1 | 2 | 3 | 4 | 5 | 6 | 7 | 8 | 9 | 10 | 11

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
## FGH Date:

Size: A2 | Rev:
KiCad E.D.A. 10.0.6 | Id: 1/25

# Title:

## File: handset.kicad_sch

## Sheet: /

LF reader logic translation

# File: lf-support.kicad_sch Display supply and translation

File: display-interface.kicad_sch Always-on charging supervisor File: power-supervisor.kicad_sch Protected external module port File: protection.kicad_sch NFC reader, oscillator and local supplies

File: nfc.kicad_sch | Expansion control and isolation

File: expansion-control.kicad_sch External display, touch and backlight File: display.kicad_sch Cellular adapter and call-audio harnesses

# File: interfaces.kicad_sch GNSS receiver and passive antenna

# File: gnss-antennas.kicad_sch CC1101 sub-GHz radio

File: cc-radio.kicad_sch

Auxiliary 5 V and 1.8 V supplies

File: aux-power.kicad_sch

MicroSD and case-mounted infrared

File: storage-ir.kicad_sch Media speaker amplifier and digital microphone

File: audio.kicad_sch

# Key matrix and trackball File: keys.kicad_sch SX1262 LoRa radio

# File: radios.kicad_sch Main 3.3 V buck-boost supply

File: reg3.kicad_sch 125 kHz reader analog circuit File: lf-radio.kicad_sch Regulated modem supply and enable

# File: modem-power.kicad_sch Power control and fuel gauge

File: power-control.kicad_sch

Fused USB input and eFuse

File: usb-input.kicad_sch ESP32 host, boot and reset File: core.kicad_sch | Battery, thermistor and programmable charger File: power.kicad_sch USB-C source detection and permission
File: usb-detect.kicad_sch | USB-C data and ESD

File: usb.kicad_sch Engineering draft. Retained ESP32-S3 / MakerFocus 3000 mAh / external display / all peripheral interfaces. HANDSET REV A / SYSTEM SCHEMATIC INDEX

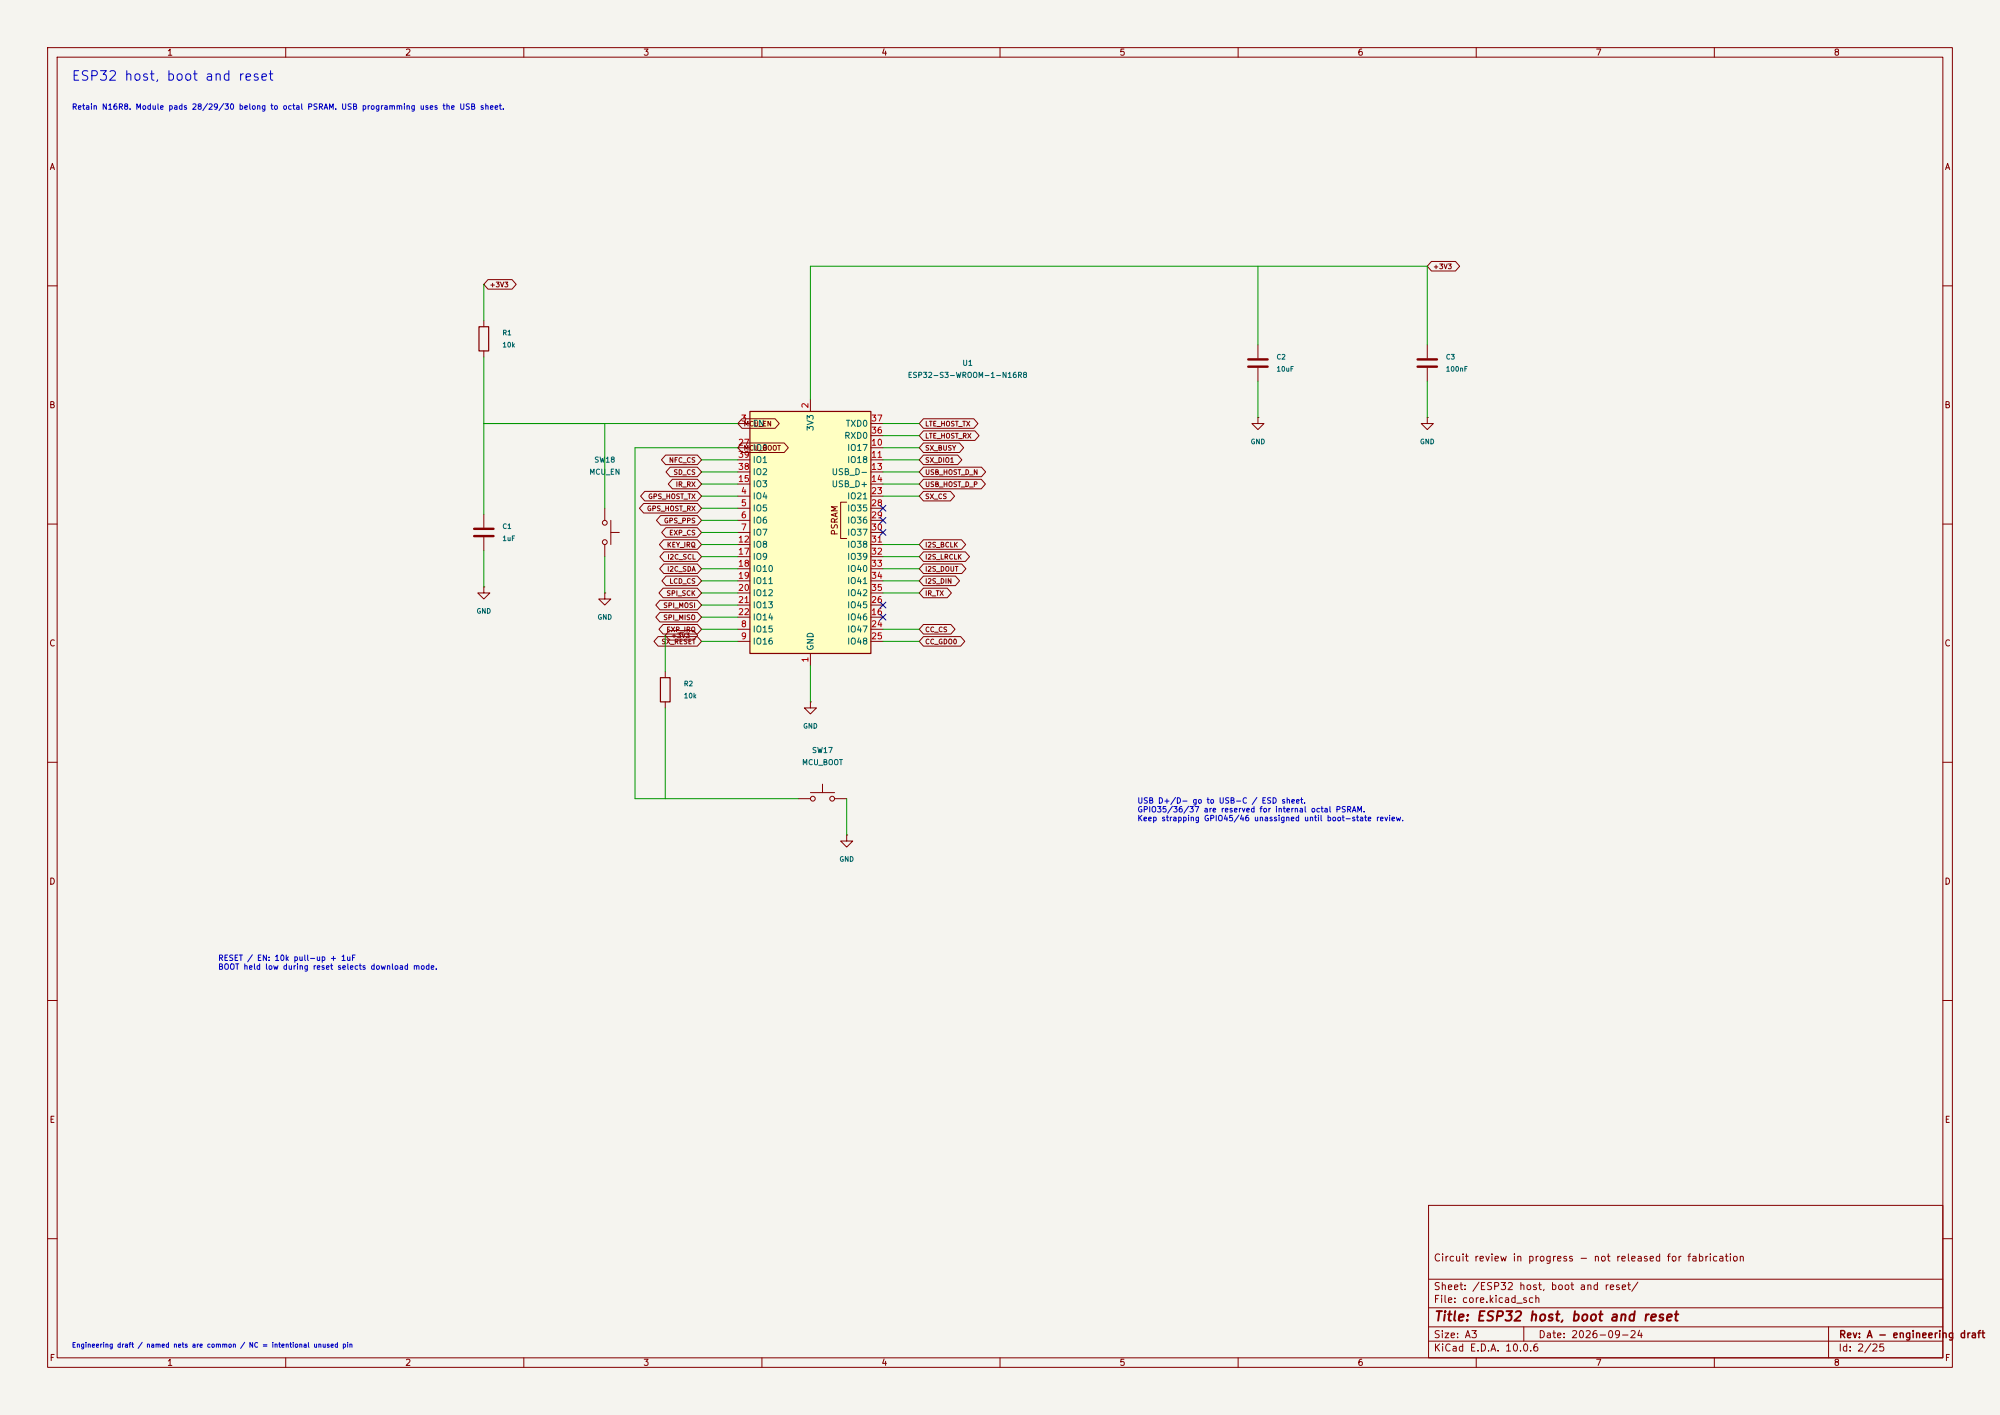
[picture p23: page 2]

Retain N16R8. Module pads 28/29/30 belong to octal PSRAM. USB programming uses the USB sheet. ESP32 host, boot and reset

Circuit review in progress - not released for fabrication PSRAM GND

Sheet: /ESP32 host, boot and reset/
File: core.kicad_sch
Title: ESP32 host, boot and reset

Engineering draft / named nets are common / NC = intentional unused pin

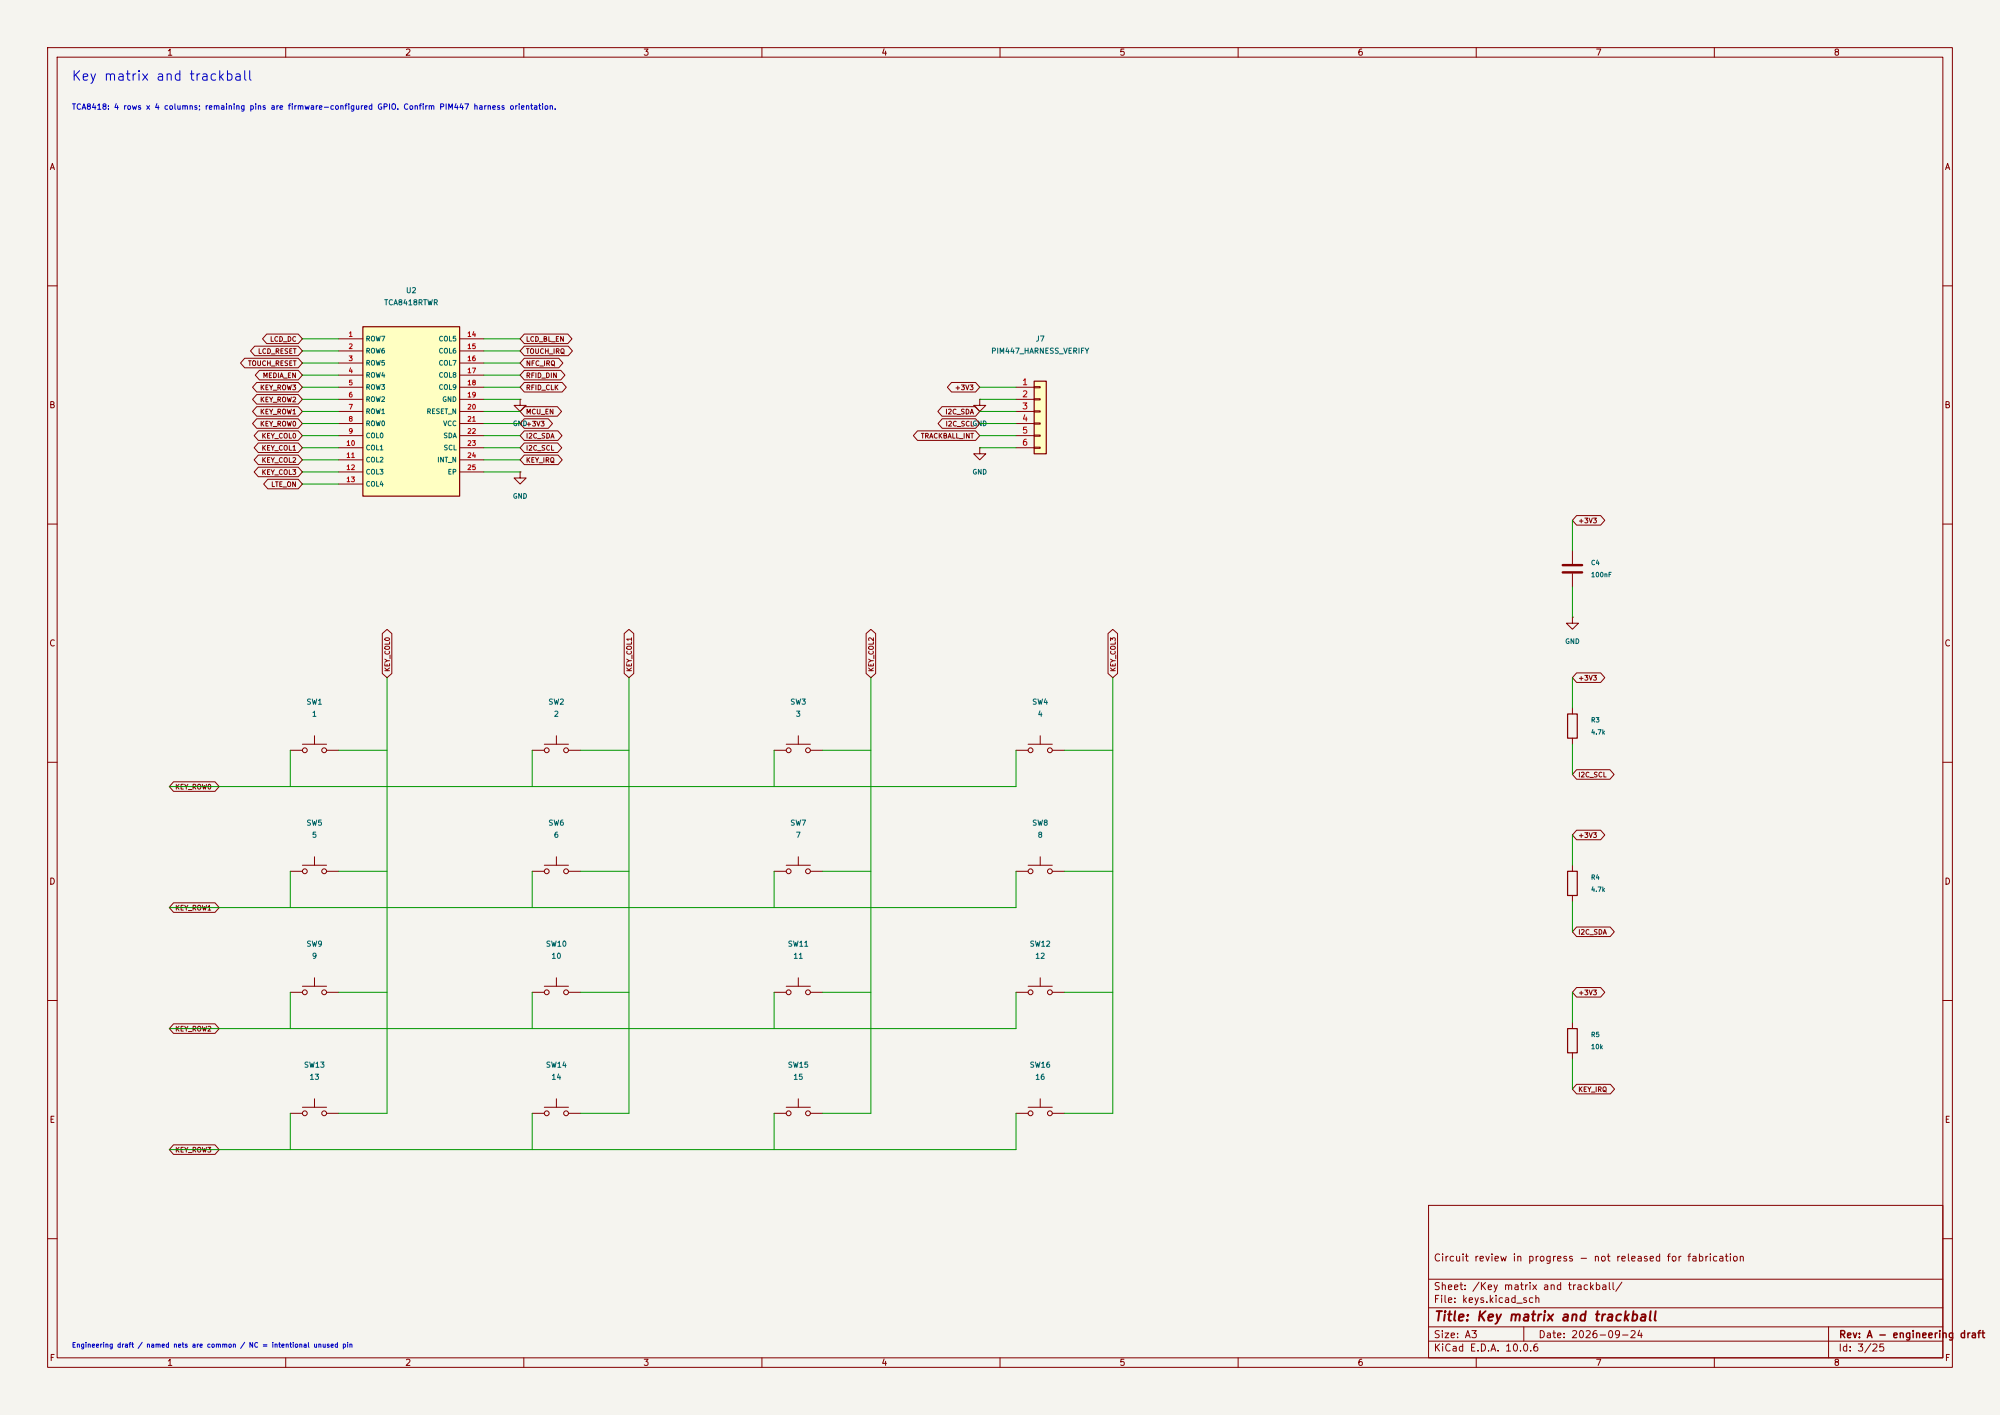
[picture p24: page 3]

Key matrix and trackball

TCA8418: 4 rows x 4 columns; remaining pins are firmware-configured GPIO. Confirm PIM447 harness orientation.

Circuit review in progress - not released for fabrication

Sheet: /Key matrix and trackball/
File: keys.kicad_sch
Title: Key matrix and trackball

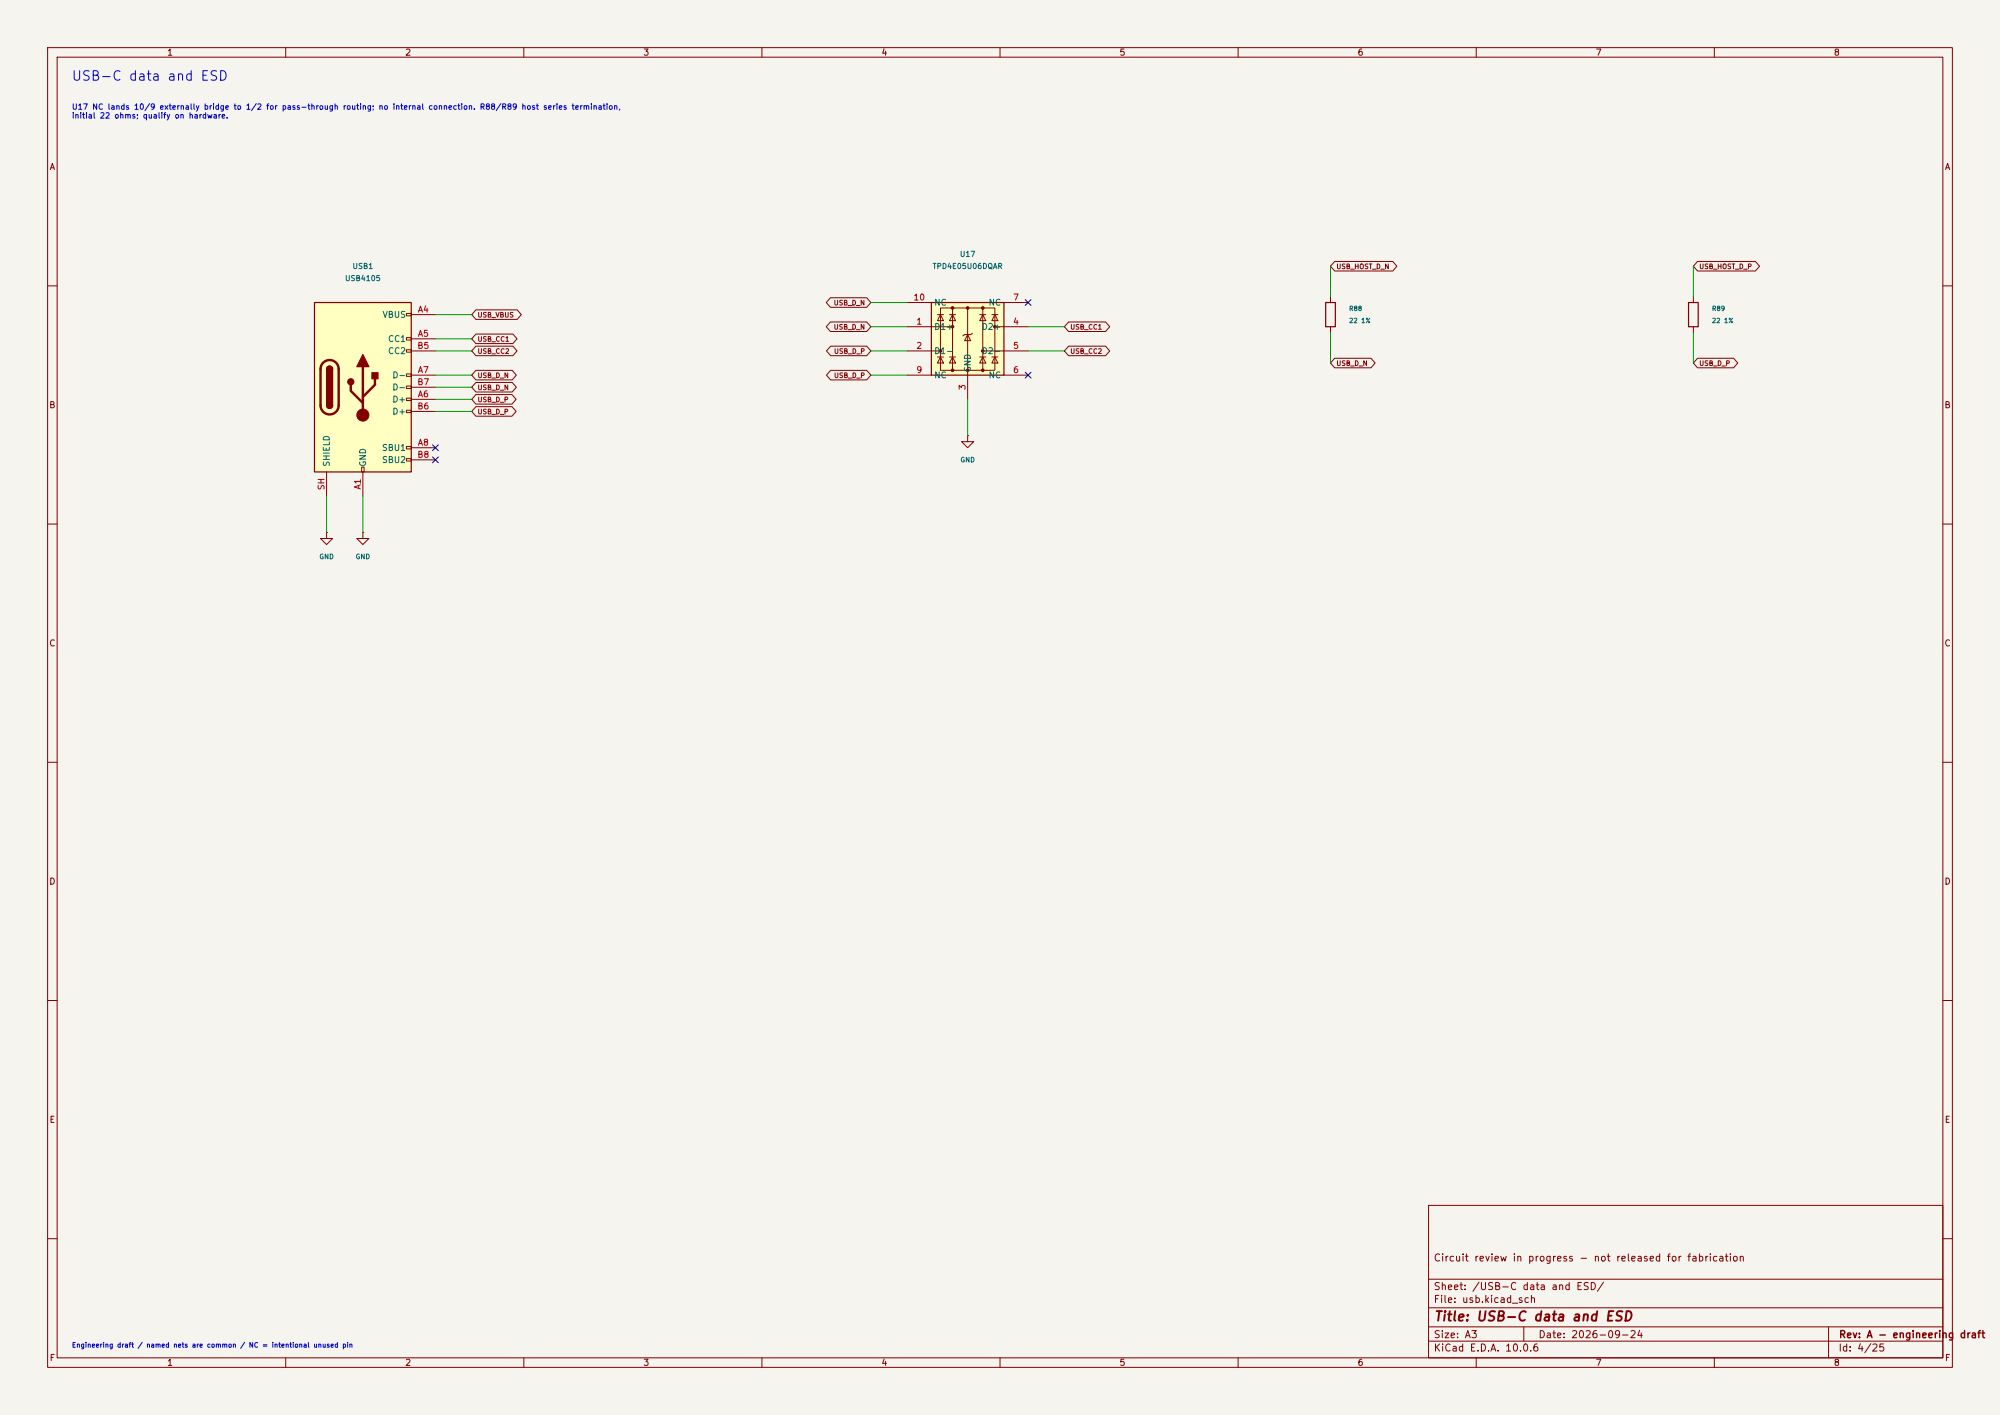
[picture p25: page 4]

USB_HOST_D_N USB-C data and ESD

U17 NC lands 10/9 externally bridge to 1/2 for pass-through routing; no internal connection. R88/R89 host series termination,
initial 22 ohms; qualify on hardware.

Circuit review in progress - not released for fabrication

Sheet: /USB-C data and ESD/
File: usb.kicad_sch
Title: USB-C data and ESD

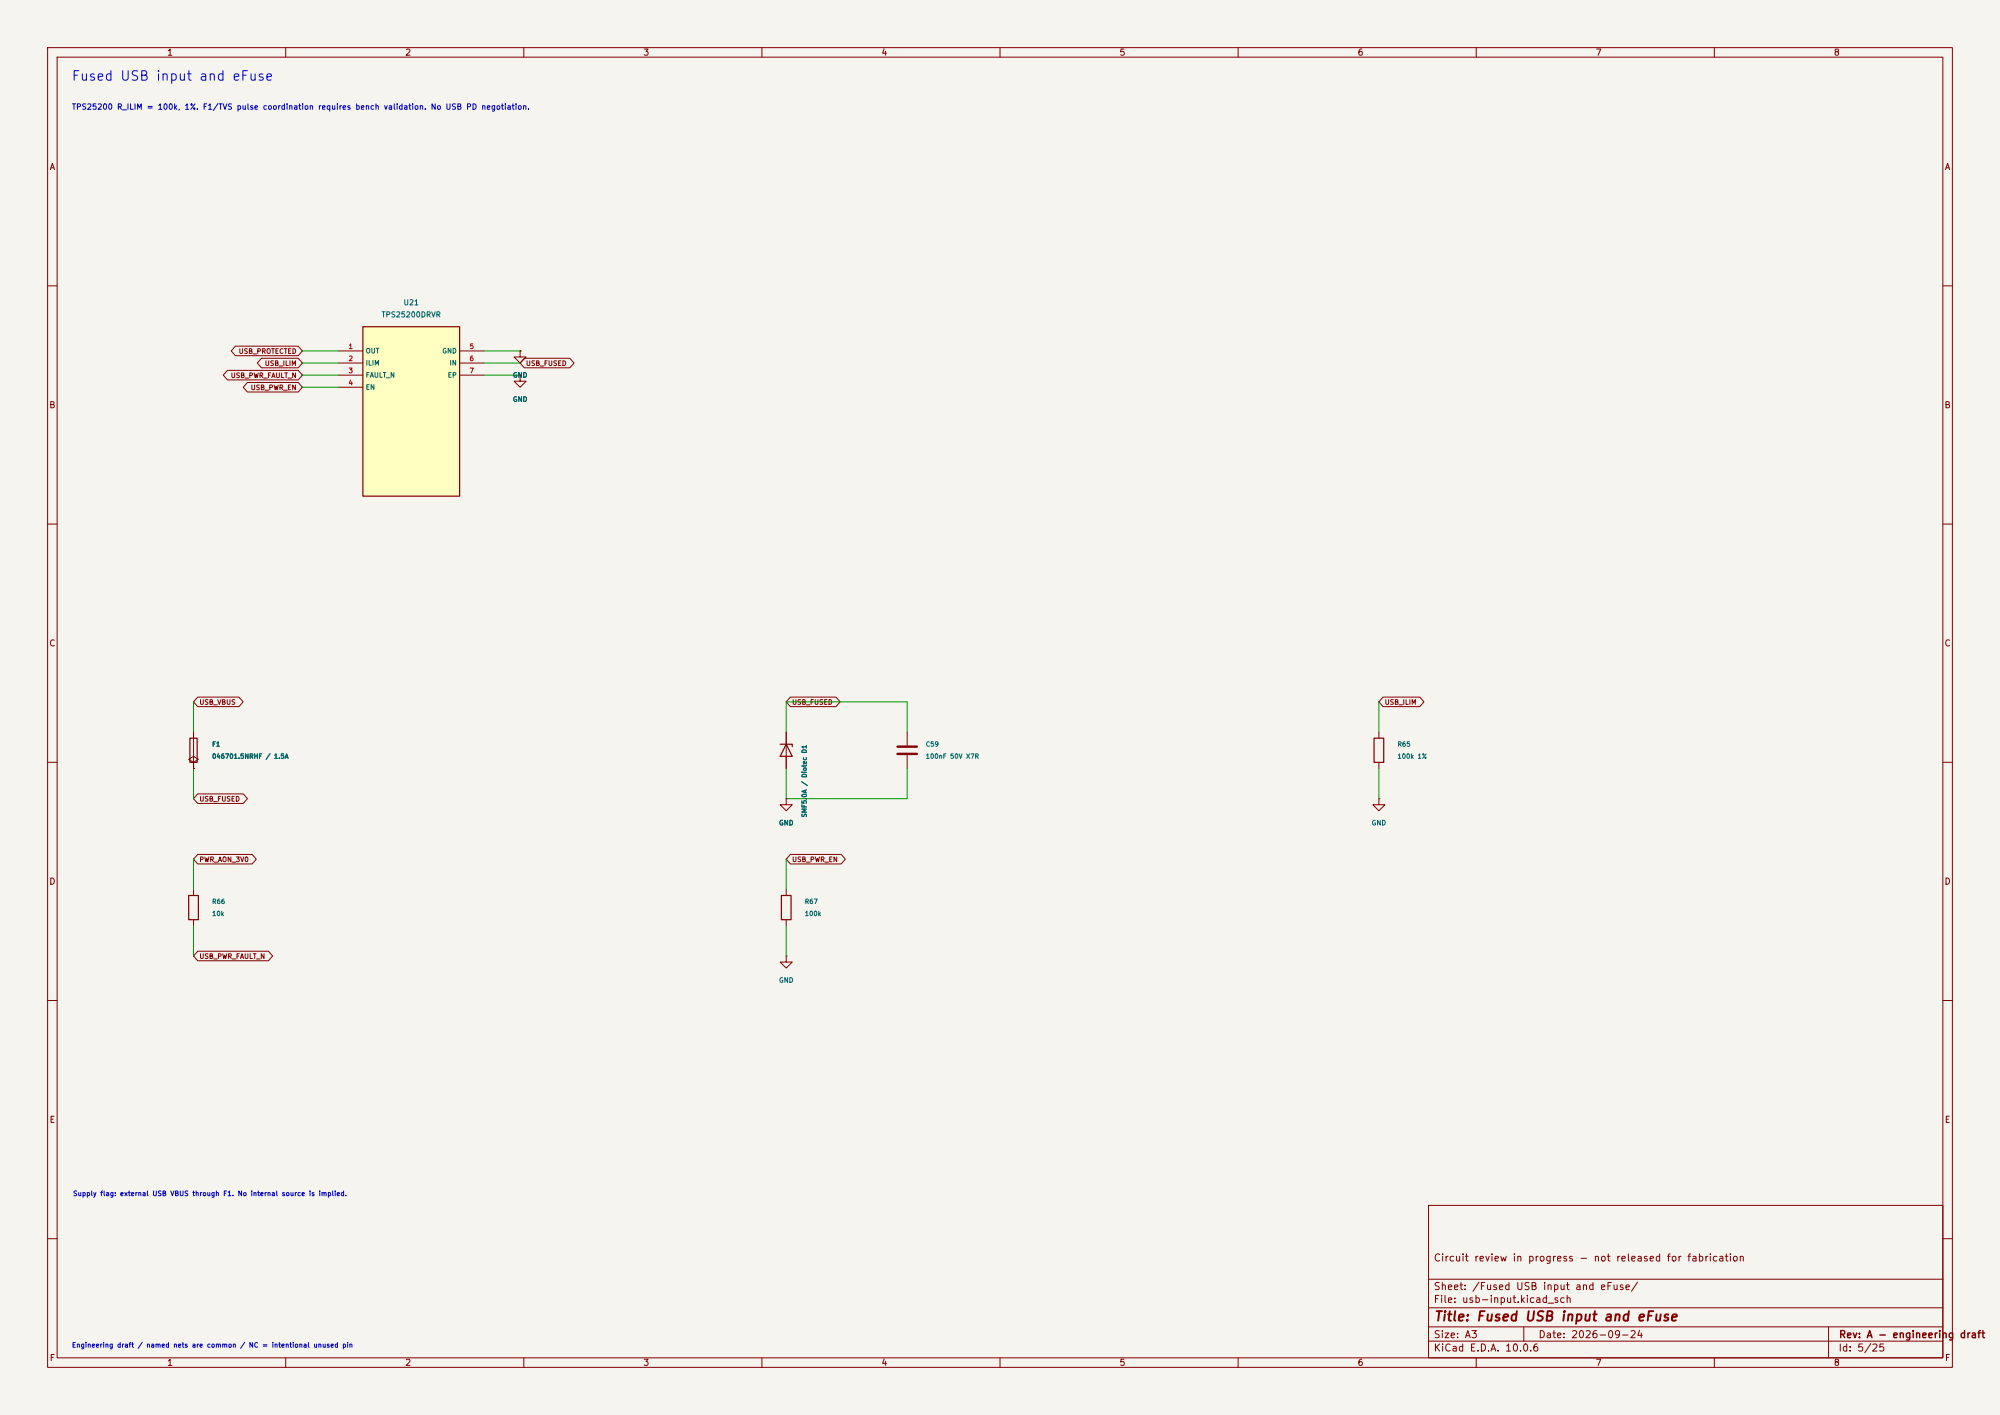
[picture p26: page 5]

Fused USB input and eFuse

TPS25200 R_ILIM = 100k, 1%. F1/TVS pulse coordination requires bench validation. No USB PD negotiation.

Supply flag: external USB VBUS through F1. No internal source is implied. Engineering draft / named nets are common / NC = intentional unused pin

Circuit review in progress - not released for fabrication

Sheet: /Fused USB input and eFuse/
File: usb-input.kicad_sch
Title: Fused USB input and eFuse

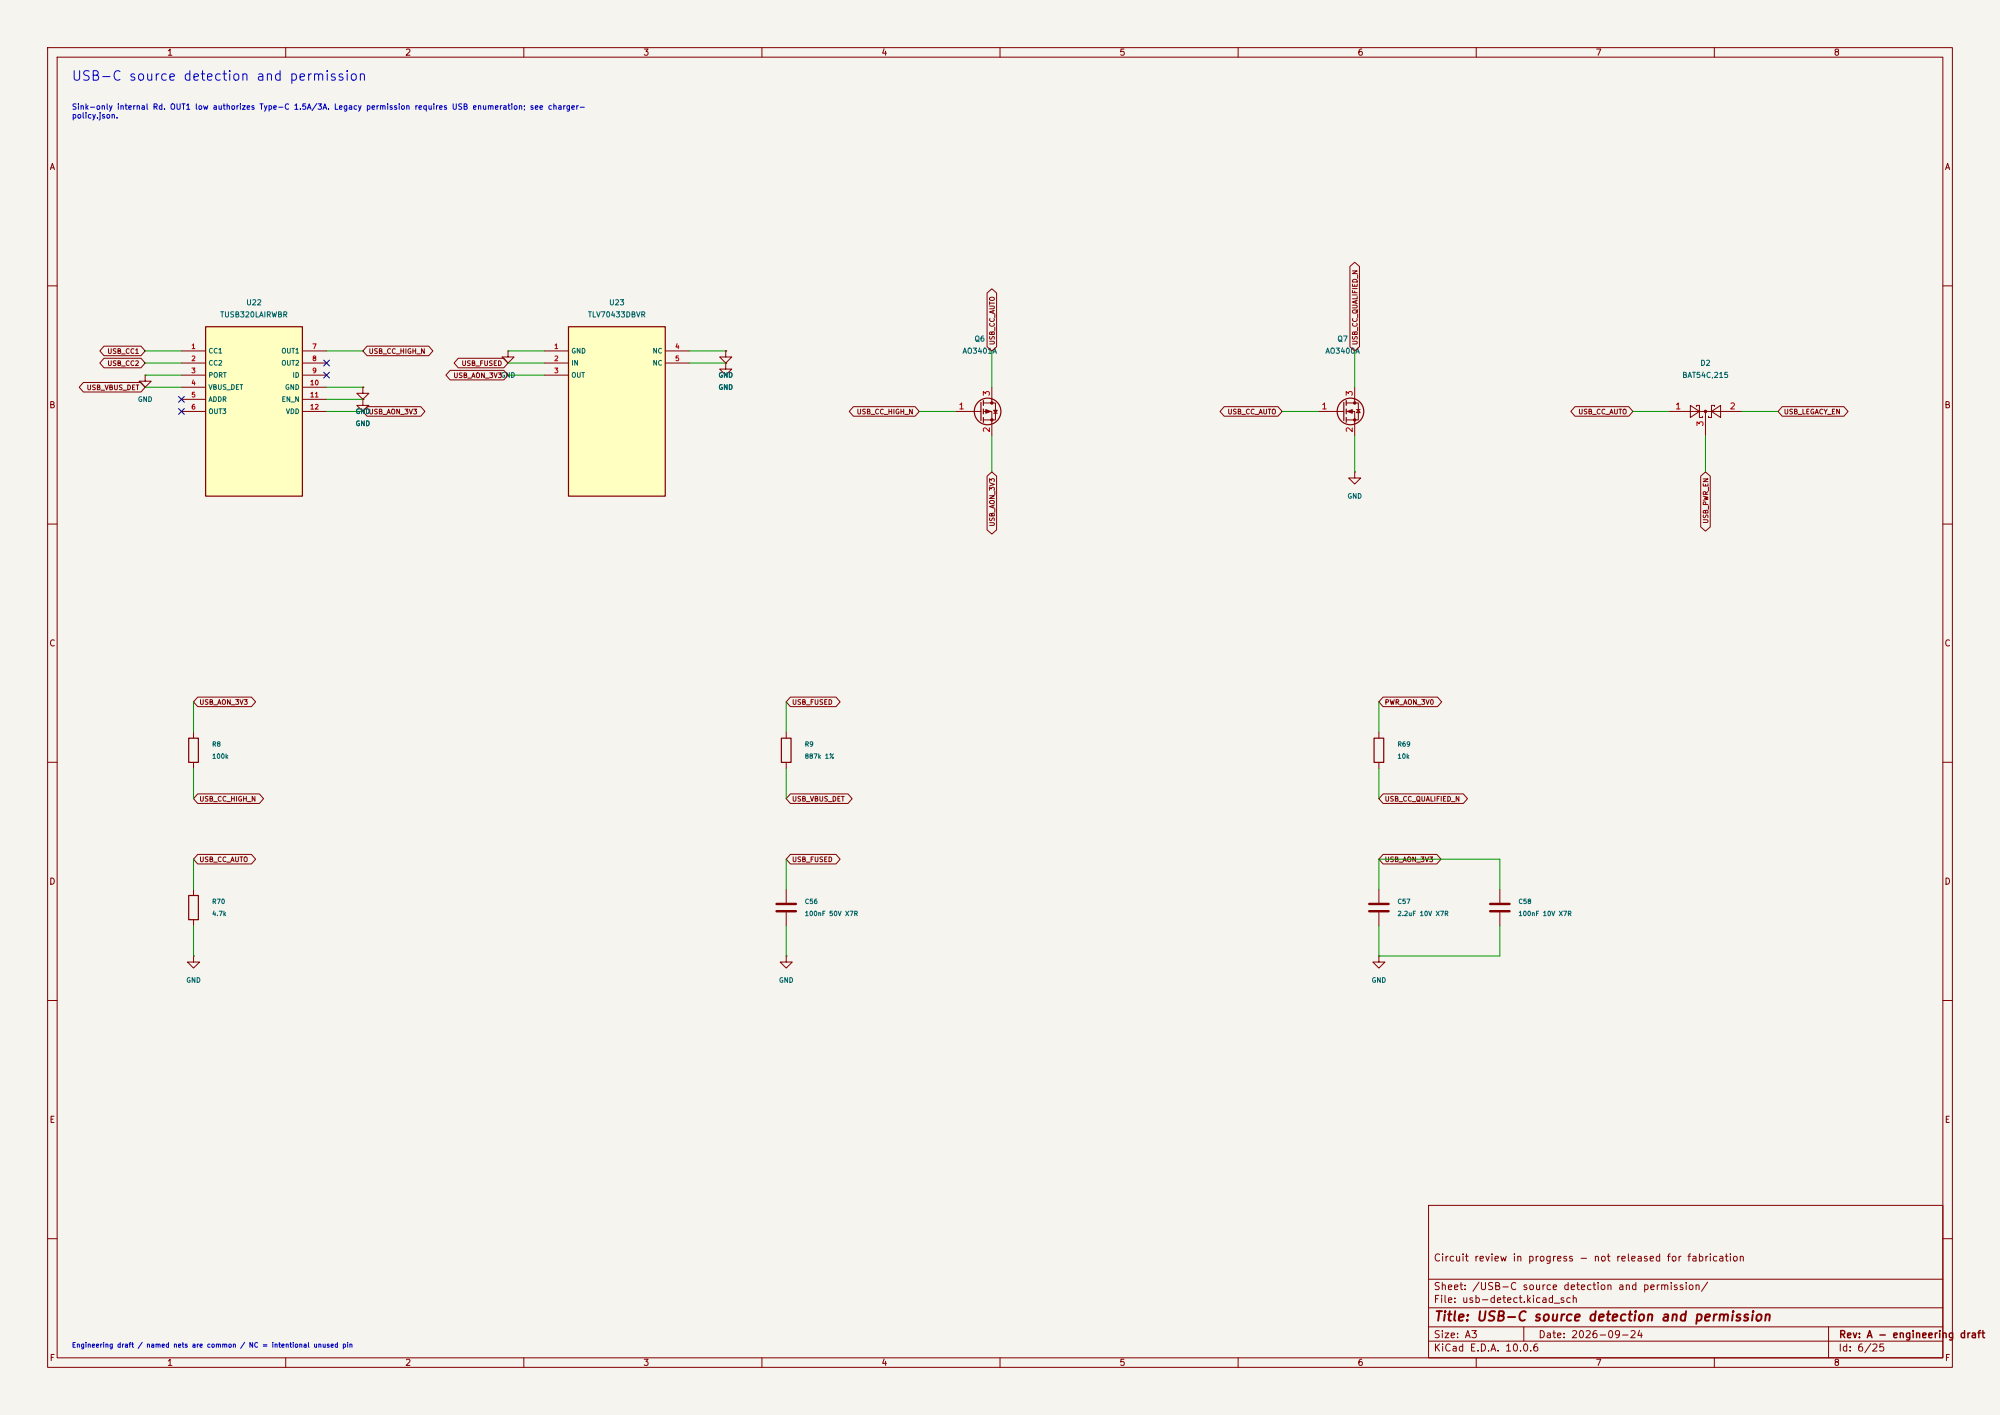
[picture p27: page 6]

USB-C source detection and permission

Sink-only internal Rd. OUT1 low authorizes Type-C 1.5A/3A. Legacy permission requires USB enumeration; see charger-
policy.json.

Circuit review in progress - not released for fabrication

Sheet: /USB-C source detection and permission/
File: usb-detect.kicad_sch
Title: USB-C source detection and permission

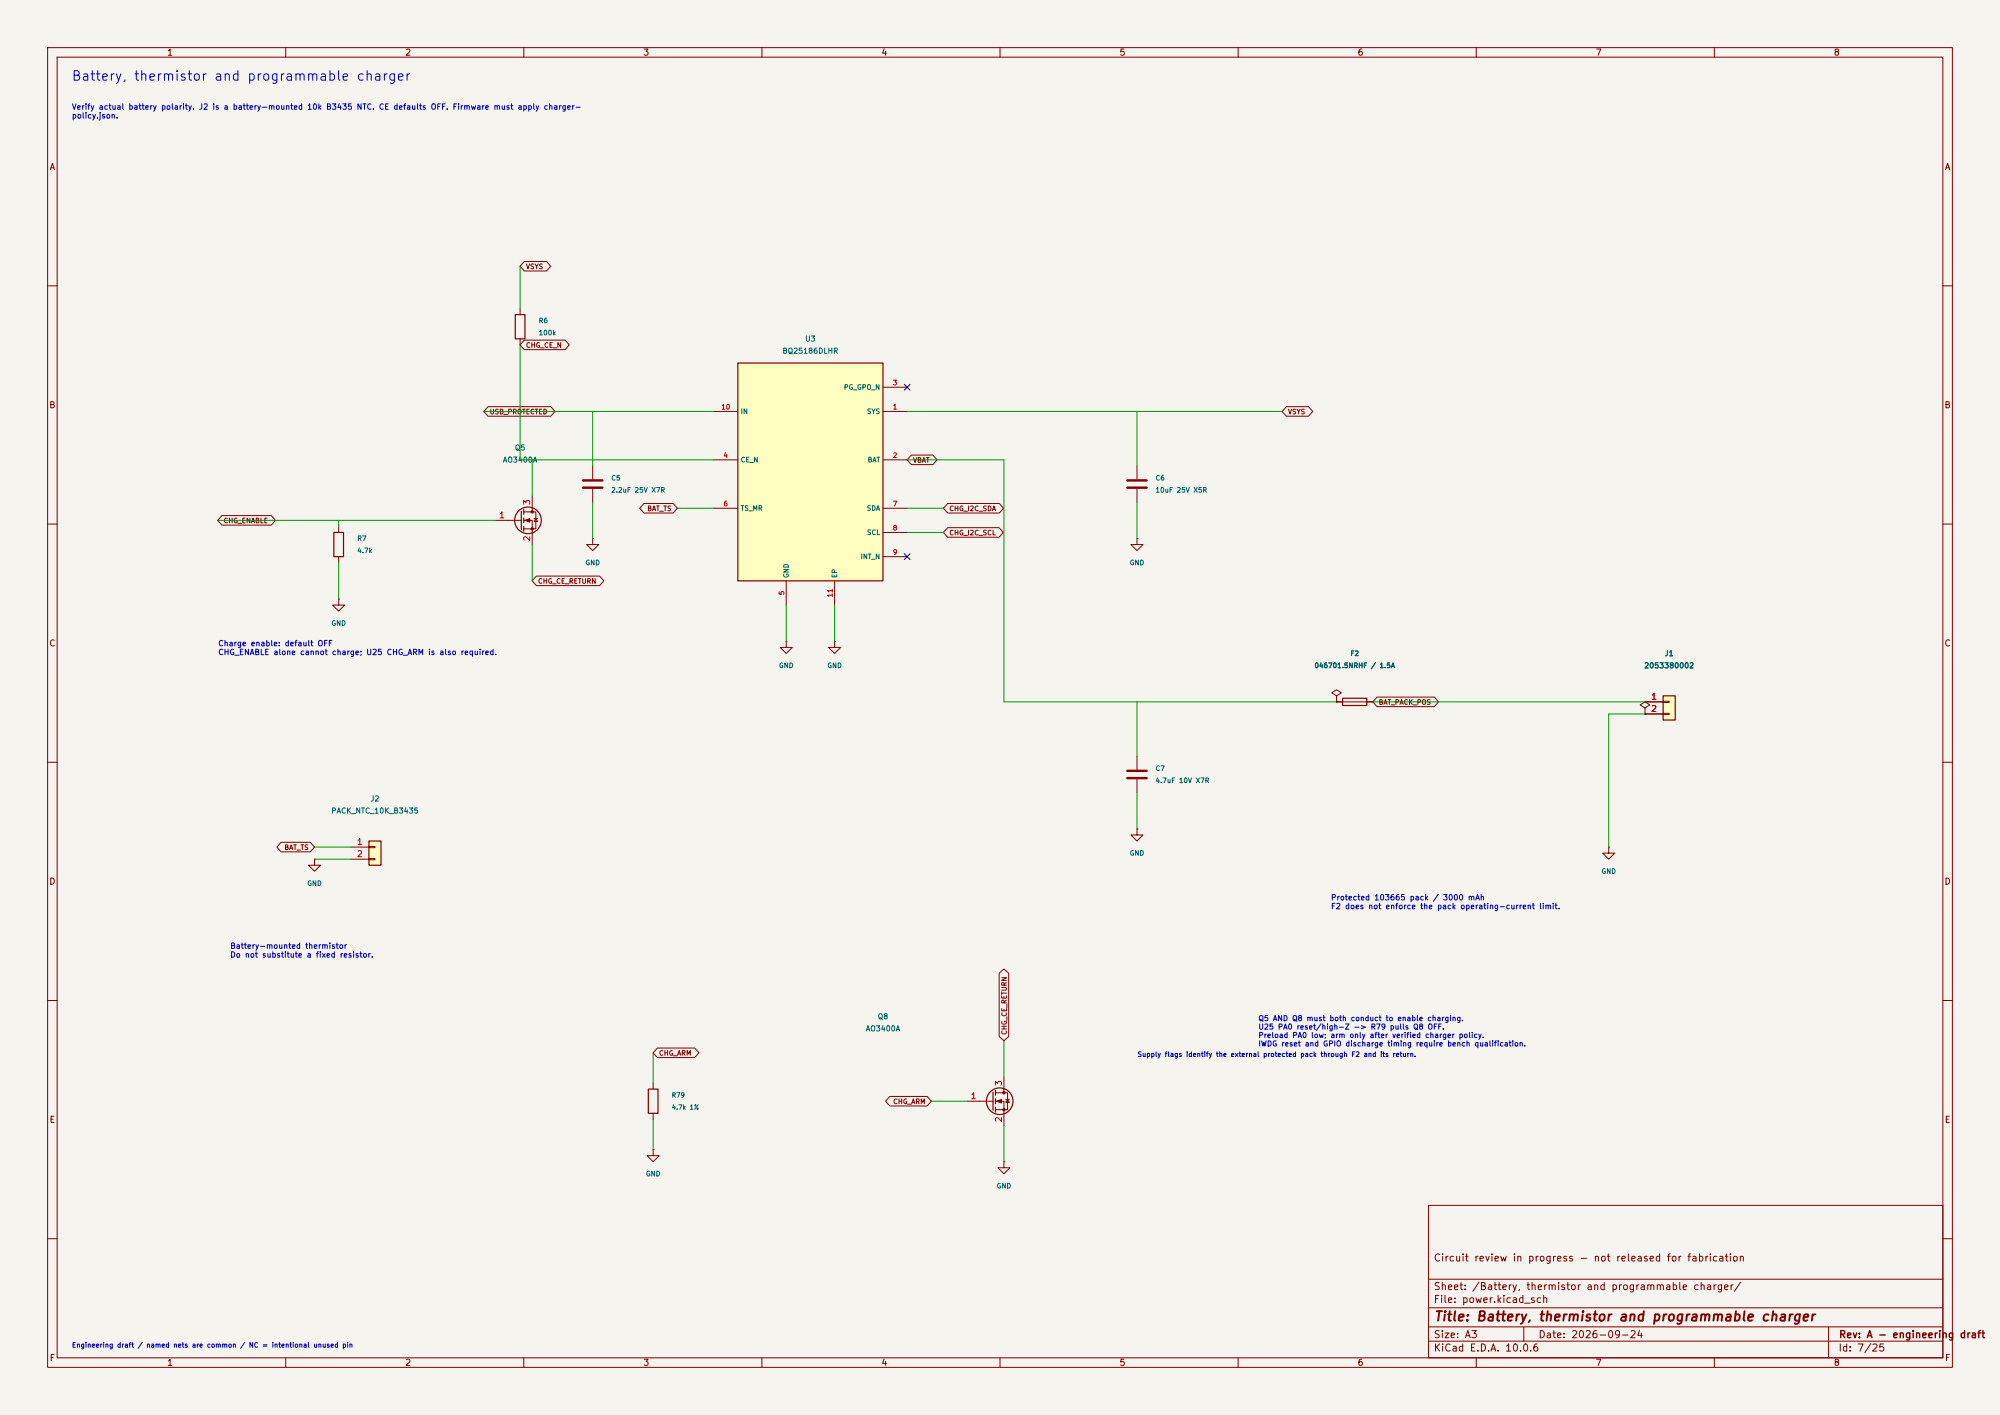
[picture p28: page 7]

Battery, thermistor and programmable charger

Verify actual battery polarity. J2 is a battery-mounted 10k B3435 NTC. CE defaults OFF. Firmware must apply charger-
policy.json.

Charge enable: default OFF CHG_ENABLE alone cannot charge; U25 CHG_ARM is also required.

F2 does not enforce the pack operating-current limit. F2
046701.5NRHF / 1.5A

IWDG reset and GPIO discharge timing require bench qualification. Protected 103665 pack / 3000 mAh

Battery-mounted thermistor Do not substitute a fixed resistor. Engineering draft / named nets are common / NC = intentional unused pin

Q5 AND Q8 must both conduct to enable charging. U25 PA0 reset/high-Z -> R79 pulls Q8 OFF. Preload PA0 low; arm only after verified charger policy.

Supply flags identify the external protected pack through F2 and its return.
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

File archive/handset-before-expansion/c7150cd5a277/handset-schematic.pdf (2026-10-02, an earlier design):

1 | 2 | 3 | 4 | 5 | 6 | 7 | 8 | 9 | 10 | 11
1 | 2 | 3 | 4 | 5 | 6 | 7 | 8 | 9 | 10 | 11

AB

C

D

E

### FGH

AB

C

D

E

## FGH Date:

Size: A2 | Rev:
KiCad E.D.A. 10.0.6 | Id: 1/24

# Title:

## File: handset.kicad_sch

## Sheet: /

### SX1262 LoRa radio

File: radios.kicad_sch

### Display supply and translation

File: display-interface.kicad_sch Always-on charging supervisor File: power-supervisor.kicad_sch Protected external module port File: protection.kicad_sch NFC reader, oscillator and local supplies

File: nfc.kicad_sch | External display, touch and backlight File: display.kicad_sch Cellular adapter and call-audio harnesses

# File: interfaces.kicad_sch GNSS receiver and passive antenna

# File: gnss-antennas.kicad_sch CC1101 sub-GHz radio

File: cc-radio.kicad_sch

### Auxiliary 5 V and 1.8 V supplies

File: aux-power.kicad_sch

### MicroSD and case-mounted infrared

### File: storage-ir.kicad_sch Media speaker amplifier and digital microphone

File: audio.kicad_sch

### LF reader logic translation

File: lf-support.kicad_sch

# Key matrix and trackball File: keys.kicad_sch Main 3.3 V buck-boost supply

File: reg3.kicad_sch 125 kHz reader analog circuit File: lf-radio.kicad_sch Regulated modem supply and enable

# File: modem-power.kicad_sch Power control and fuel gauge

File: power-control.kicad_sch

### Fused USB input and eFuse

File: usb-input.kicad_sch ESP32 host, boot and reset File: core.kicad_sch | Battery, thermistor and programmable charger File: power.kicad_sch USB-C source detection and permission
File: usb-detect.kicad_sch | USB-C data and ESD

File: usb.kicad_sch Engineering draft. Retained ESP32-S3 / MakerFocus 3000 mAh / external display / all peripheral interfaces. HANDSET REV A / SYSTEM SCHEMATIC INDEX

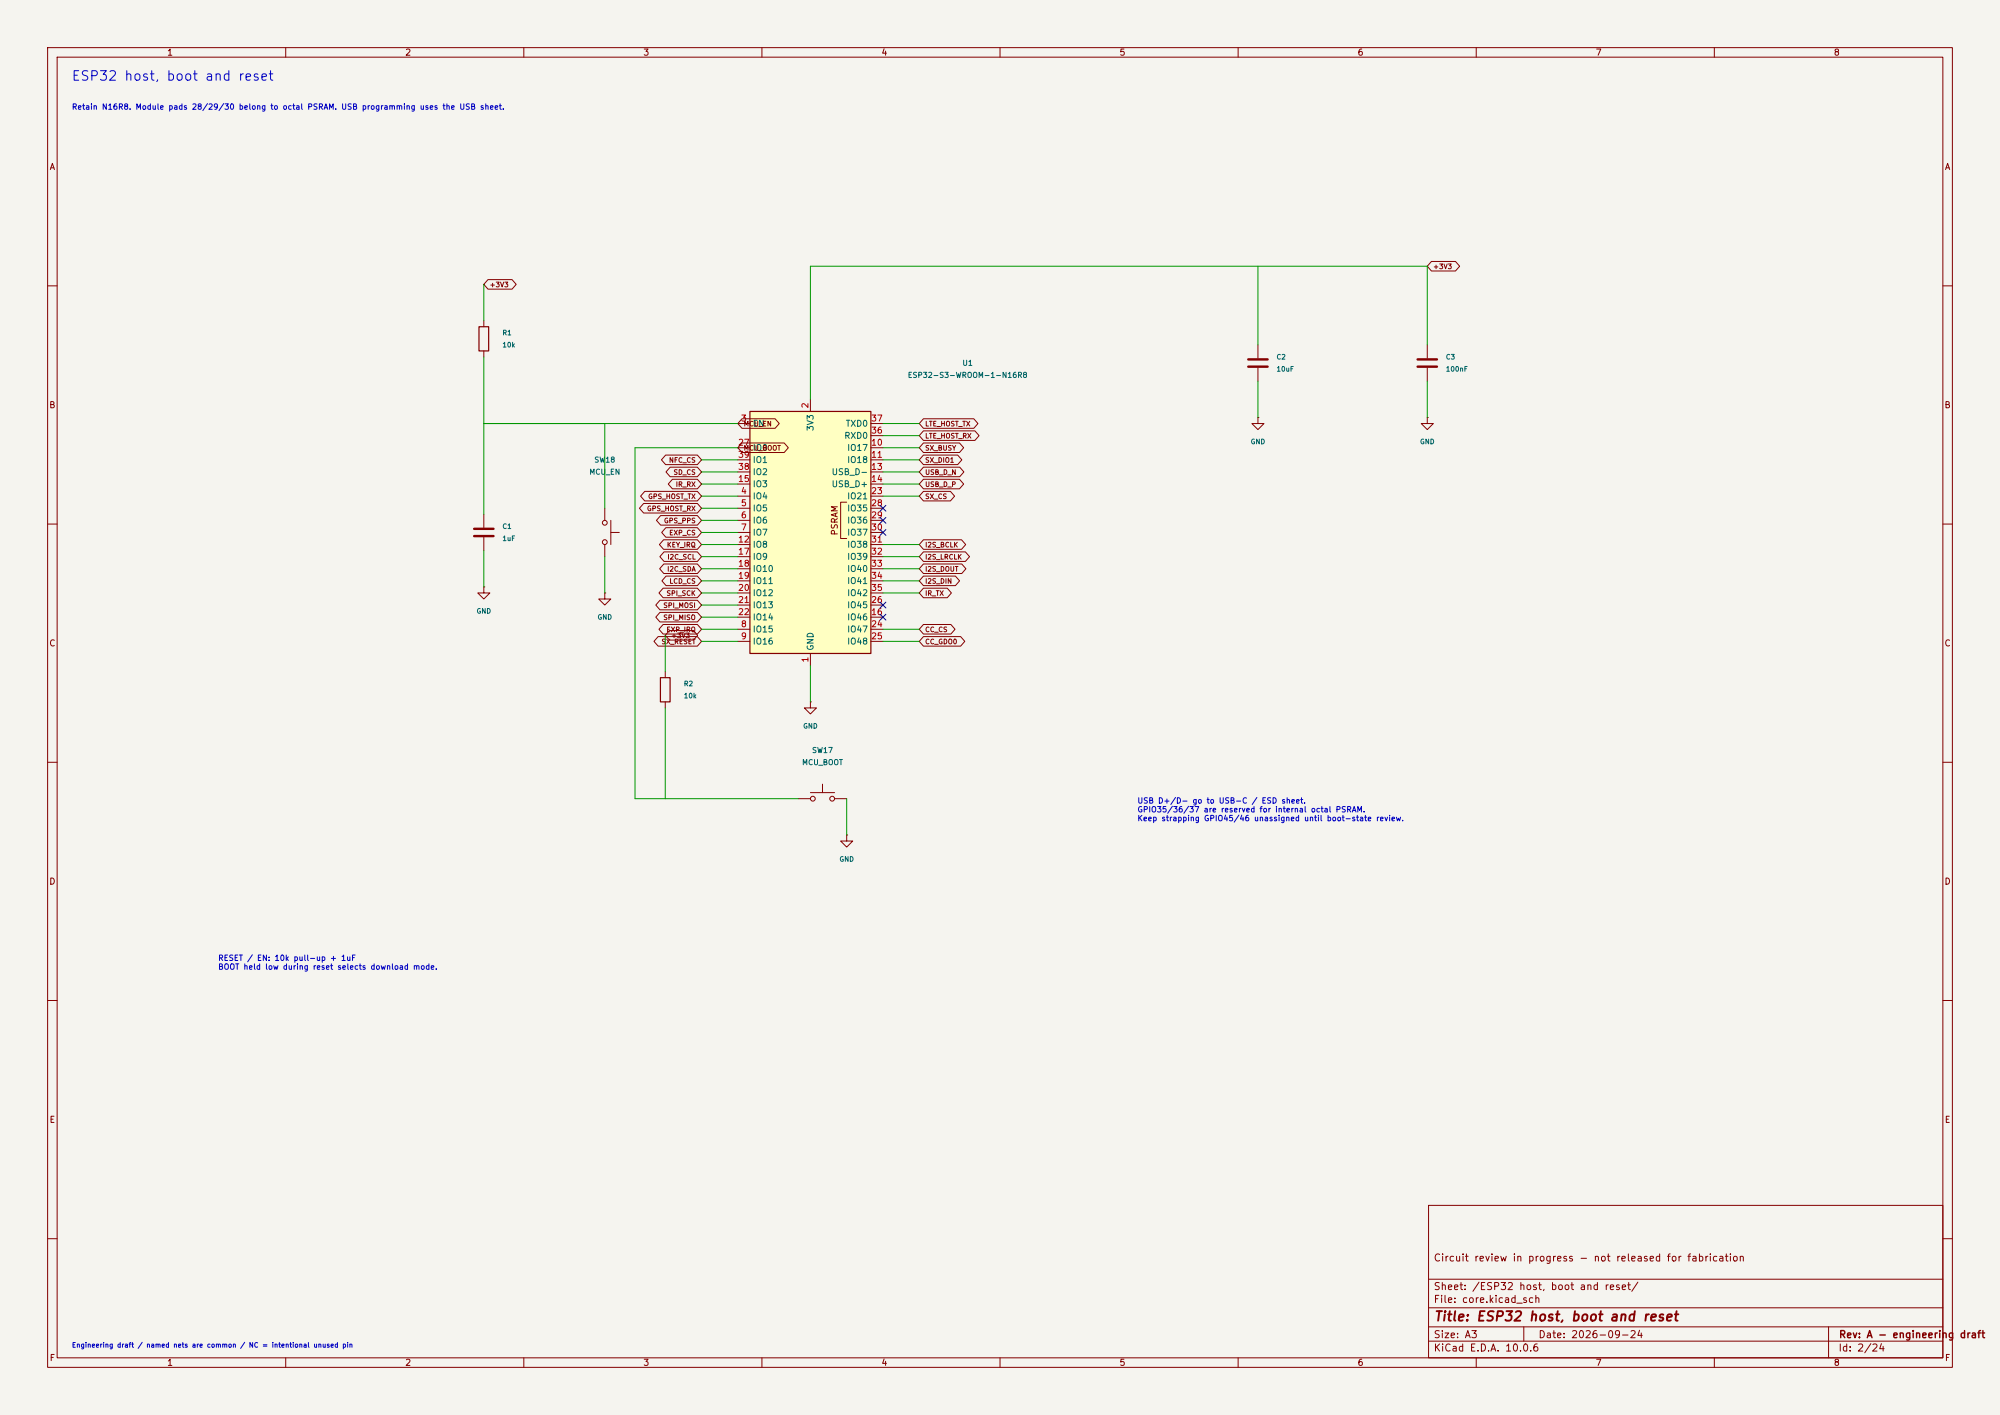
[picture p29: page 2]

Retain N16R8. Module pads 28/29/30 belong to octal PSRAM. USB programming uses the USB sheet. ESP32 host, boot and reset

SX_CS USB_D_P USB_D_N RESET / EN: 10k pull-up + 1uF BOOT held low during reset selects download mode. Engineering draft / named nets are common / NC = intentional unused pin

USB D+/D- go to USB-C / ESD sheet. GPIO35/36/37 are reserved for internal octal PSRAM. Keep strapping GPIO45/46 unassigned until boot-state review.

Circuit review in progress - not released for fabrication

Sheet: /ESP32 host, boot and reset/
File: core.kicad_sch
Title: ESP32 host, boot and reset

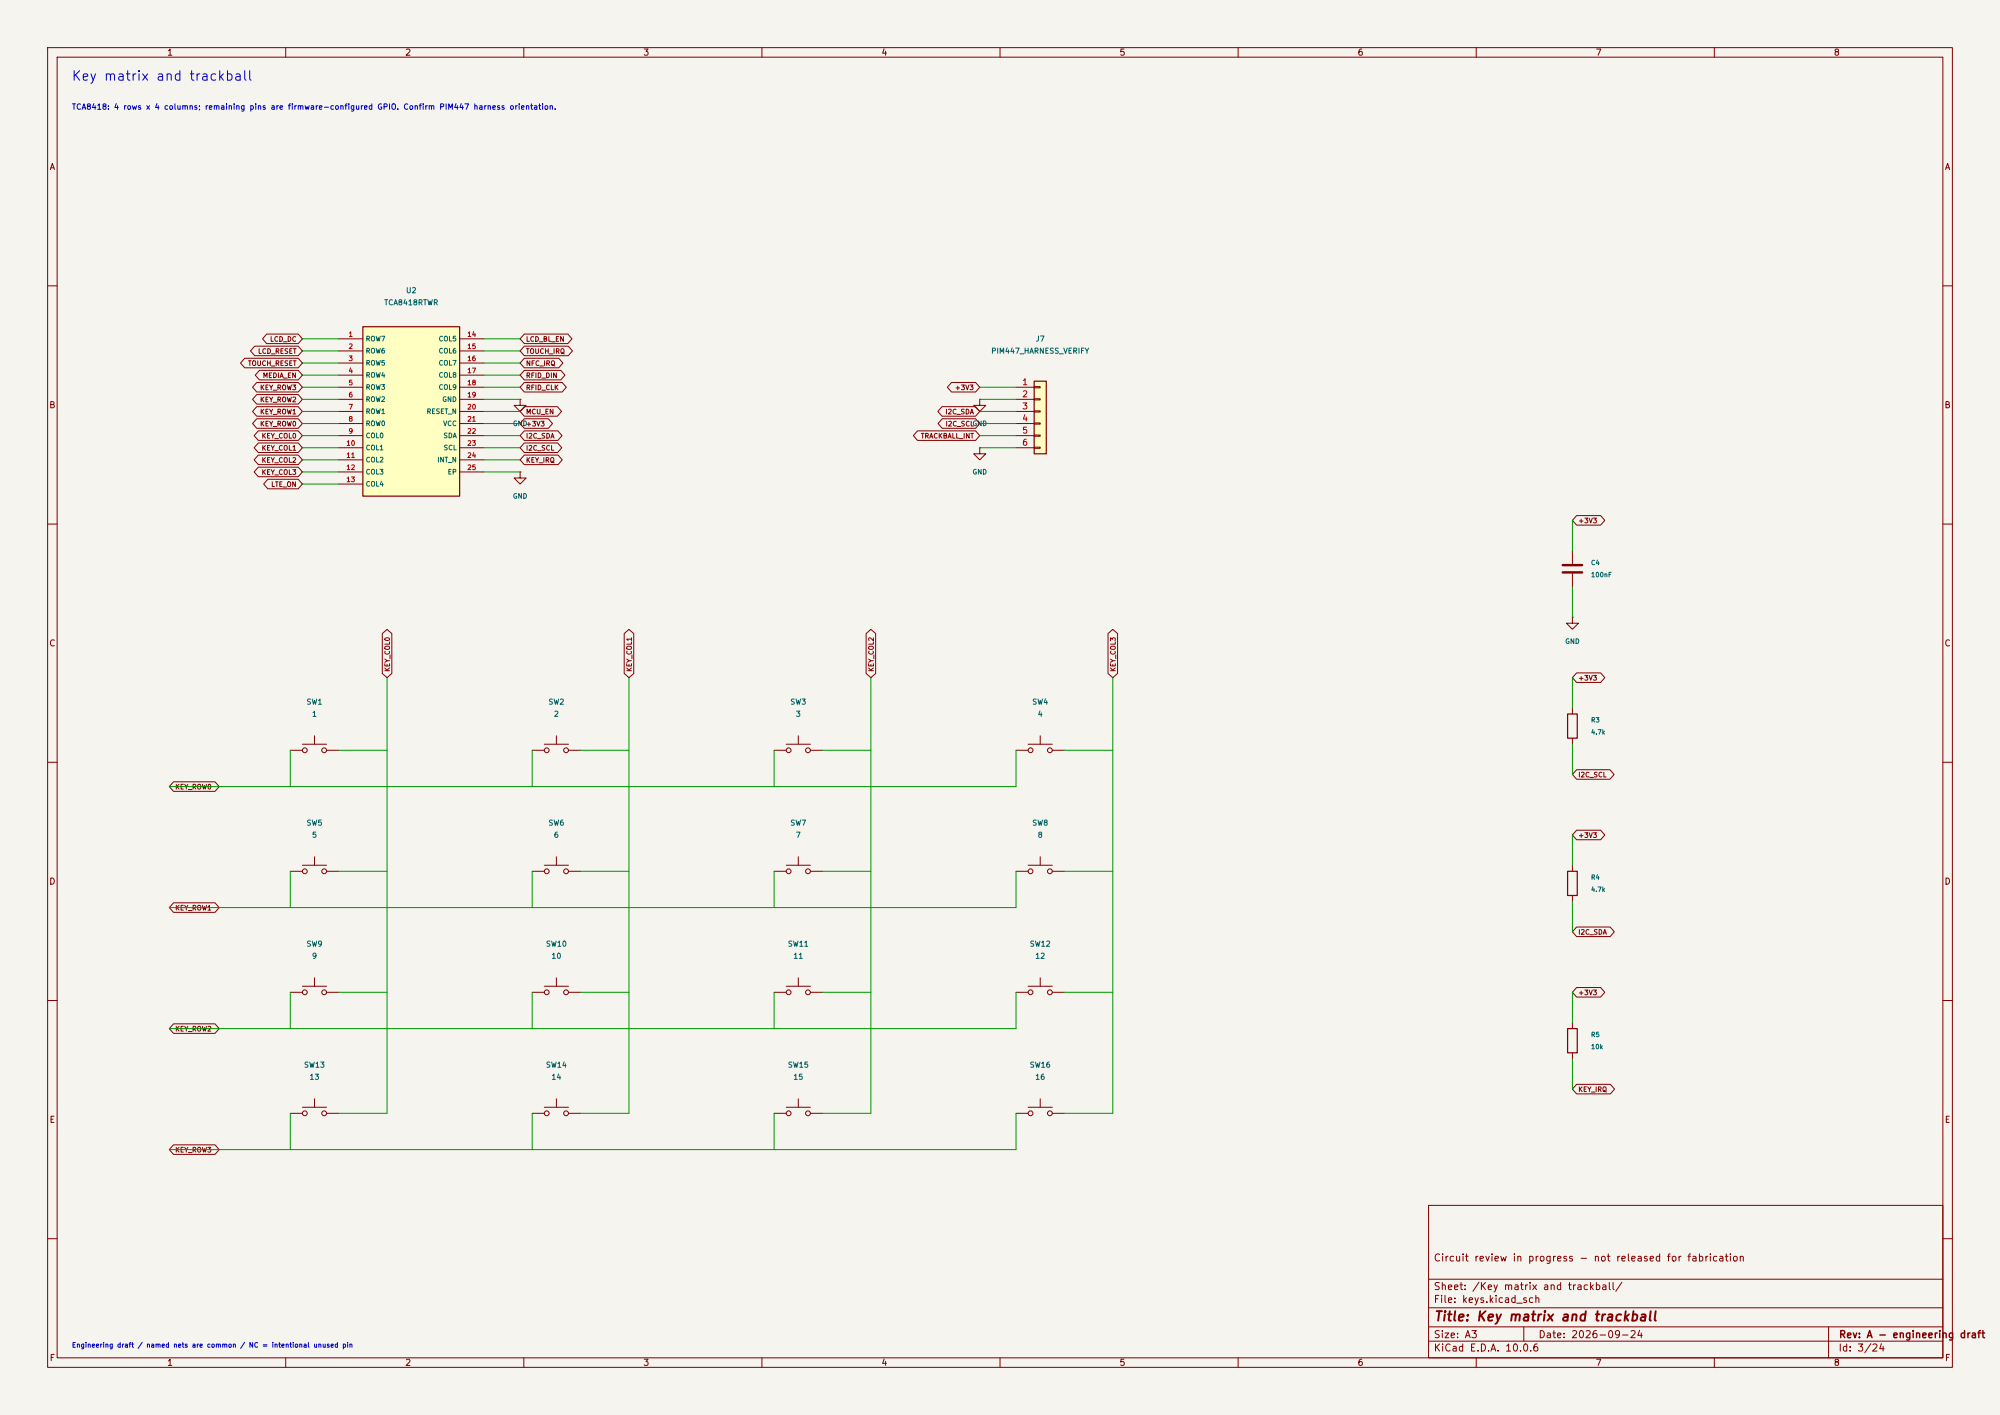
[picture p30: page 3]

Key matrix and trackball

TCA8418: 4 rows x 4 columns; remaining pins are firmware-configured GPIO. Confirm PIM447 harness orientation.

Circuit review in progress - not released for fabrication

Sheet: /Key matrix and trackball/
File: keys.kicad_sch
Title: Key matrix and trackball

Engineering draft / named nets are common / NC = intentional unused pin

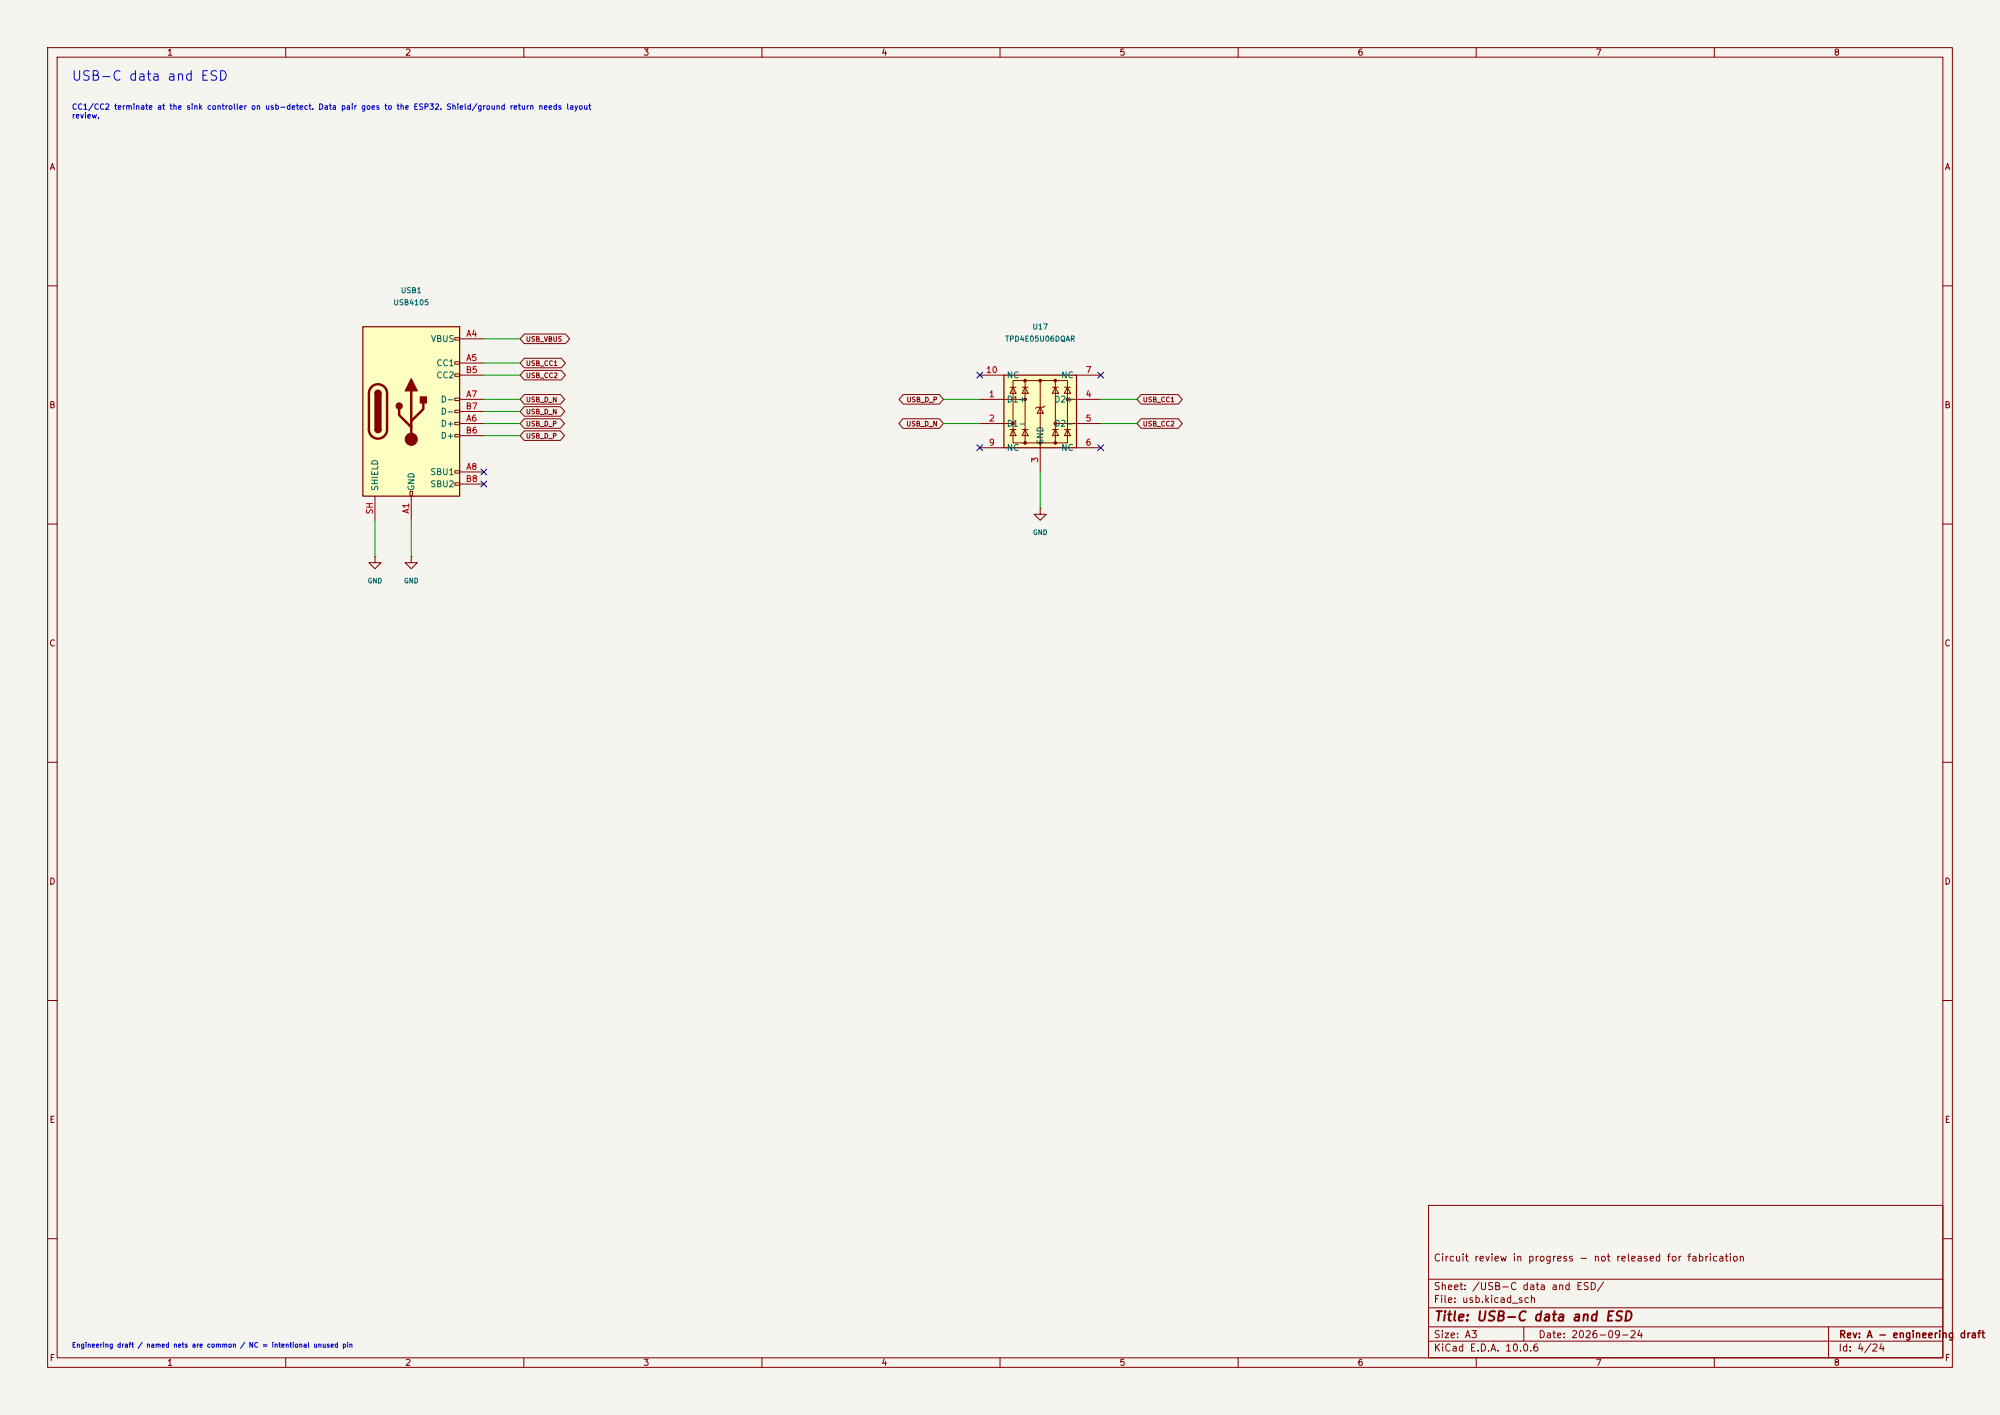
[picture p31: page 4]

USB_CC1 USB_CC2 CC1/CC2 terminate at the sink controller on usb-detect. Data pair goes to the ESP32. Shield/ground return needs layout review. USB-C data and ESD

Circuit review in progress - not released for fabrication

Sheet: /USB-C data and ESD/
File: usb.kicad_sch
Title: USB-C data and ESD

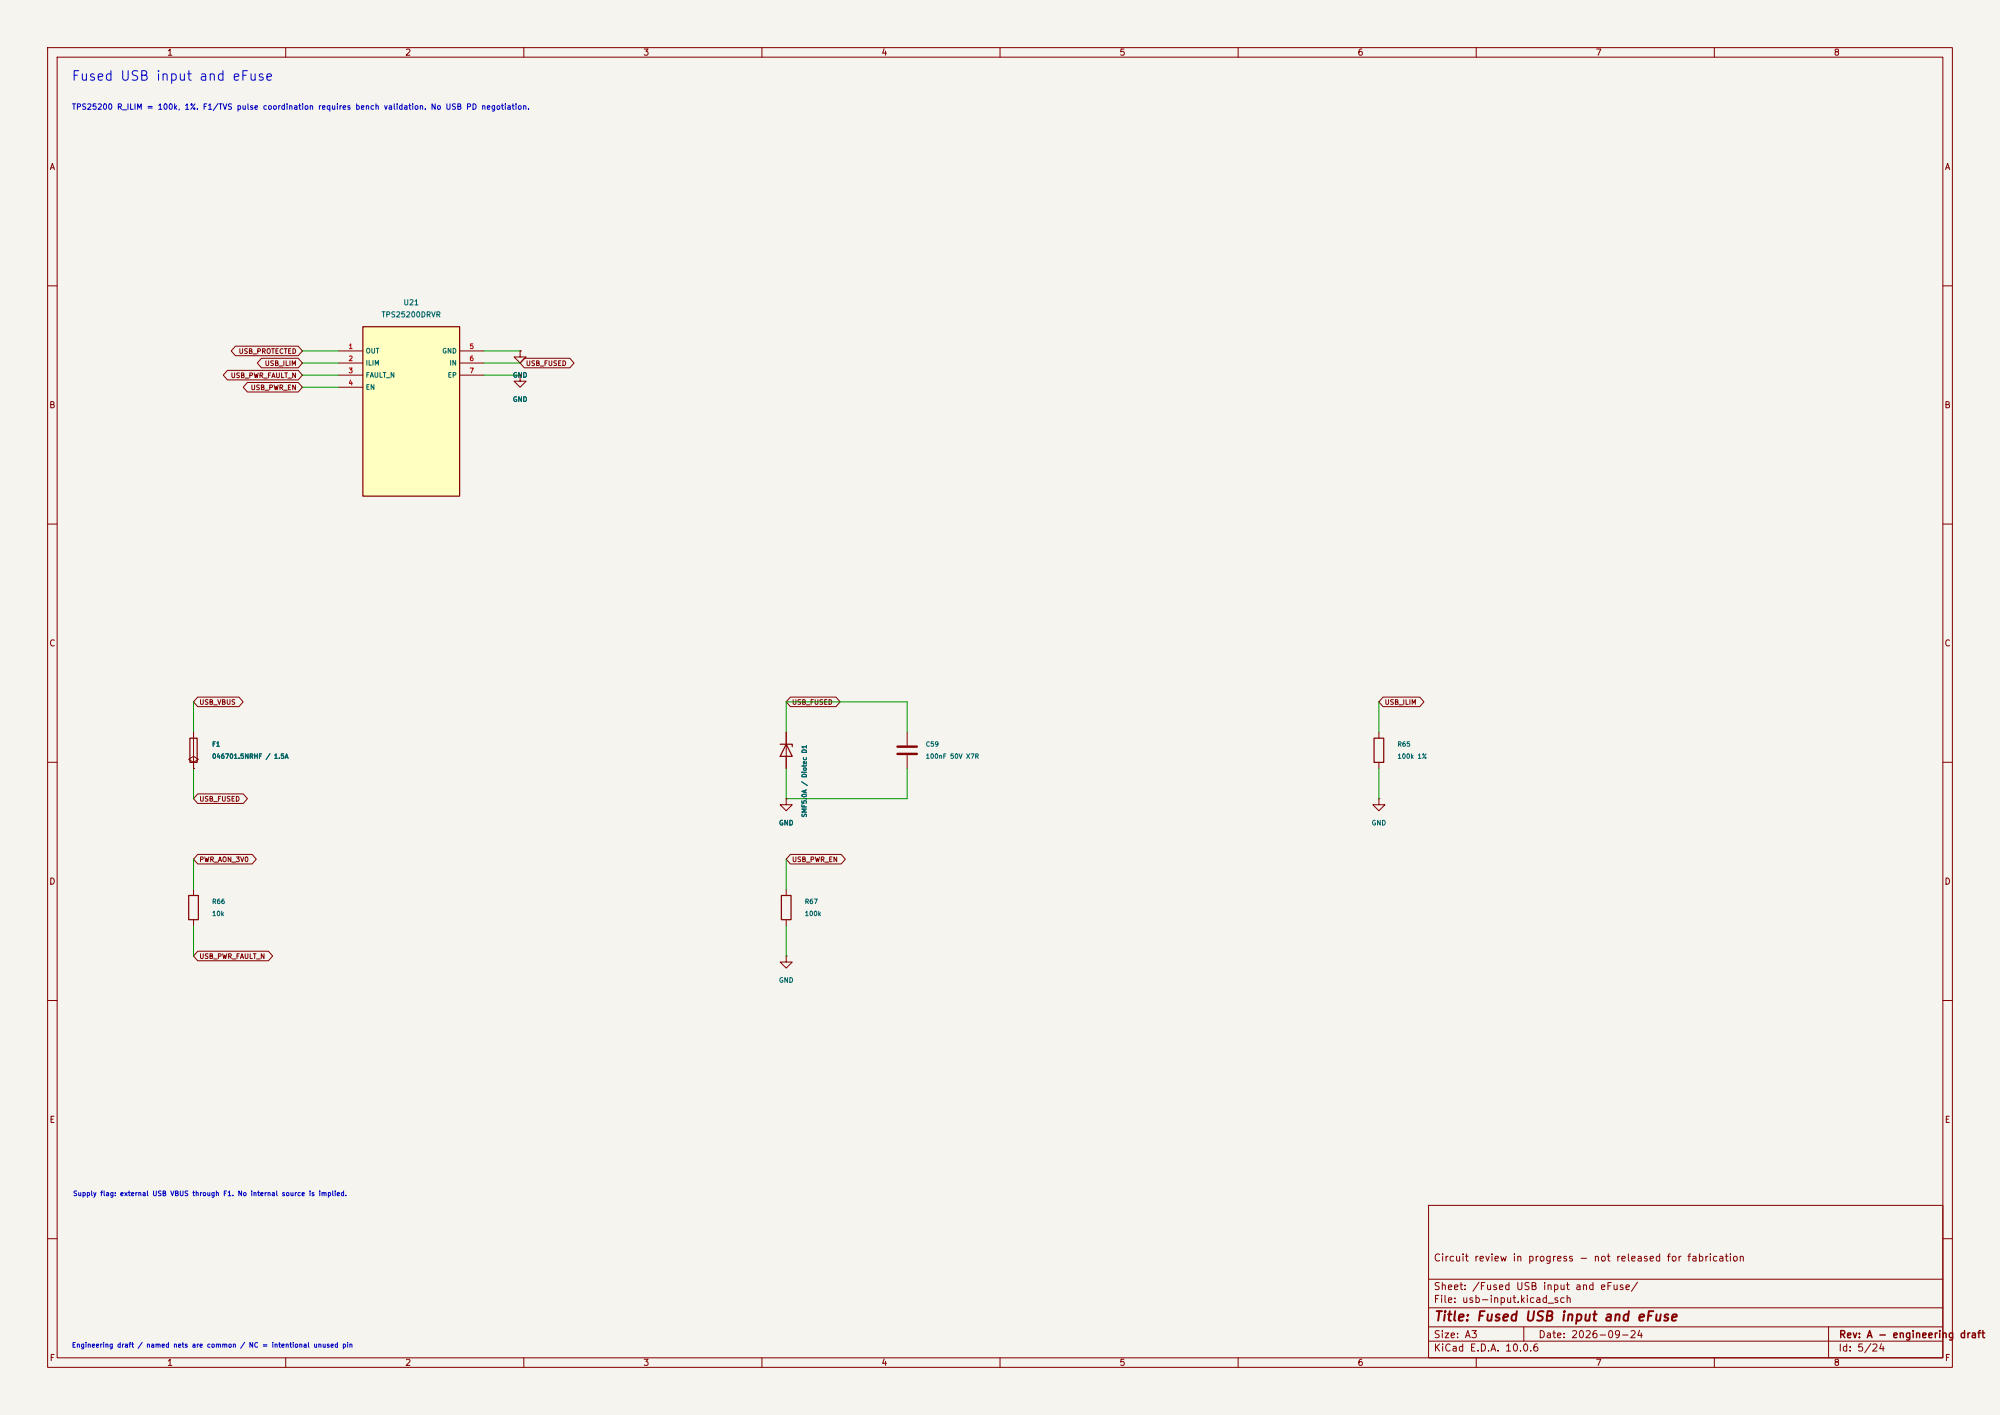
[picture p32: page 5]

Fused USB input and eFuse

TPS25200 R_ILIM = 100k, 1%. F1/TVS pulse coordination requires bench validation. No USB PD negotiation.

Supply flag: external USB VBUS through F1. No internal source is implied. Engineering draft / named nets are common / NC = intentional unused pin

Circuit review in progress - not released for fabrication

Sheet: /Fused USB input and eFuse/
File: usb-input.kicad_sch
Title: Fused USB input and eFuse


USB-C source detection and permission

Sink-only internal Rd. OUT1 low authorizes Type-C 1.5A/3A. Legacy permission requires USB enumeration; see charger-
policy.json.

Circuit review in progress - not released for fabrication

Sheet: /USB-C source detection and permission/
File: usb-detect.kicad_sch
Title: USB-C source detection and permission


Battery, thermistor and programmable charger

Verify actual battery polarity. J2 is a battery-mounted 10k B3435 NTC. CE defaults OFF. Firmware must apply charger-
policy.json.

Charge enable: default OFF CHG_ENABLE alone cannot charge; U25 CHG_ARM is also required.

F2 does not enforce the pack operating-current limit. F2
046701.5NRHF / 1.5A

IWDG reset and GPIO discharge timing require bench qualification. Protected 103665 pack / 3000 mAh
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

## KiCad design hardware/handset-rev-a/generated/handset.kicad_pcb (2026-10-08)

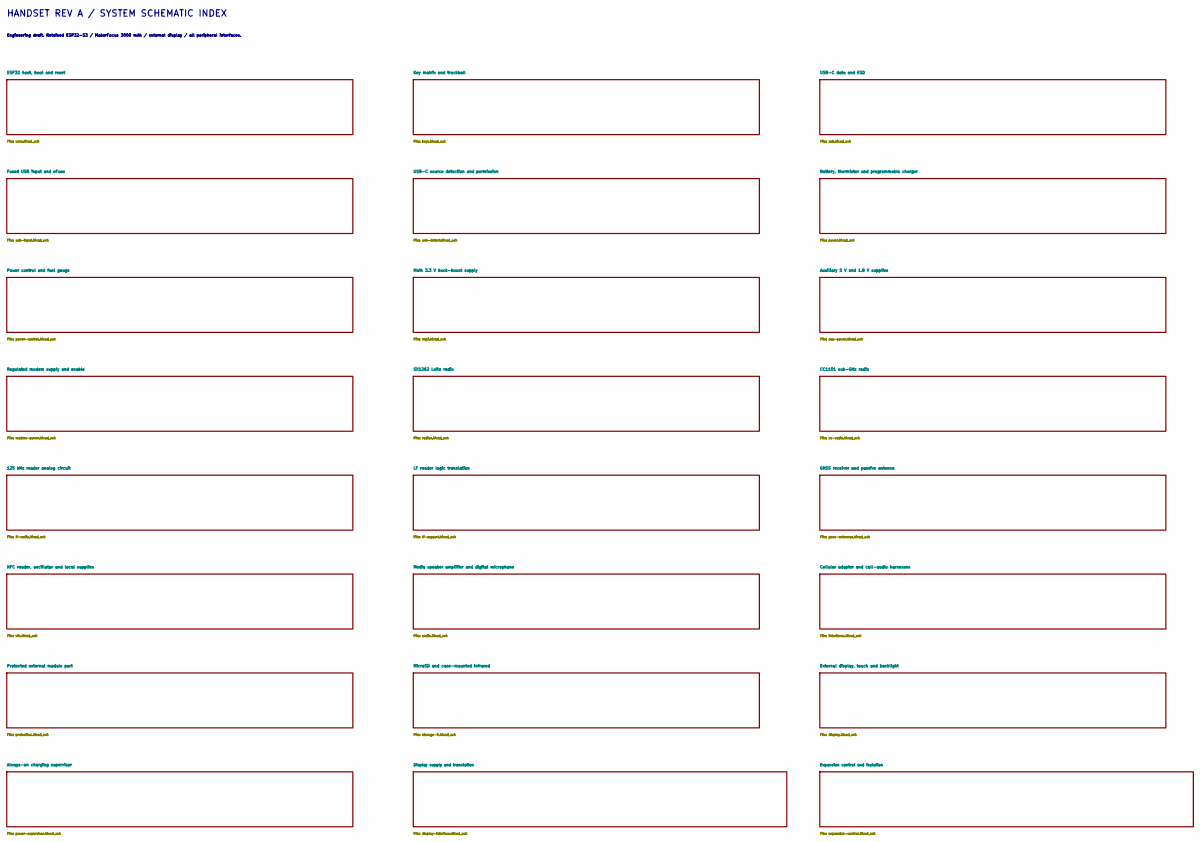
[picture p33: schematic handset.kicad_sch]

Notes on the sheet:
HANDSET REV A / SYSTEM SCHEMATIC INDEX
Engineering draft. Retained ESP32-S3 / MakerFocus 3000 mAh / external display / all peripheral interfaces.

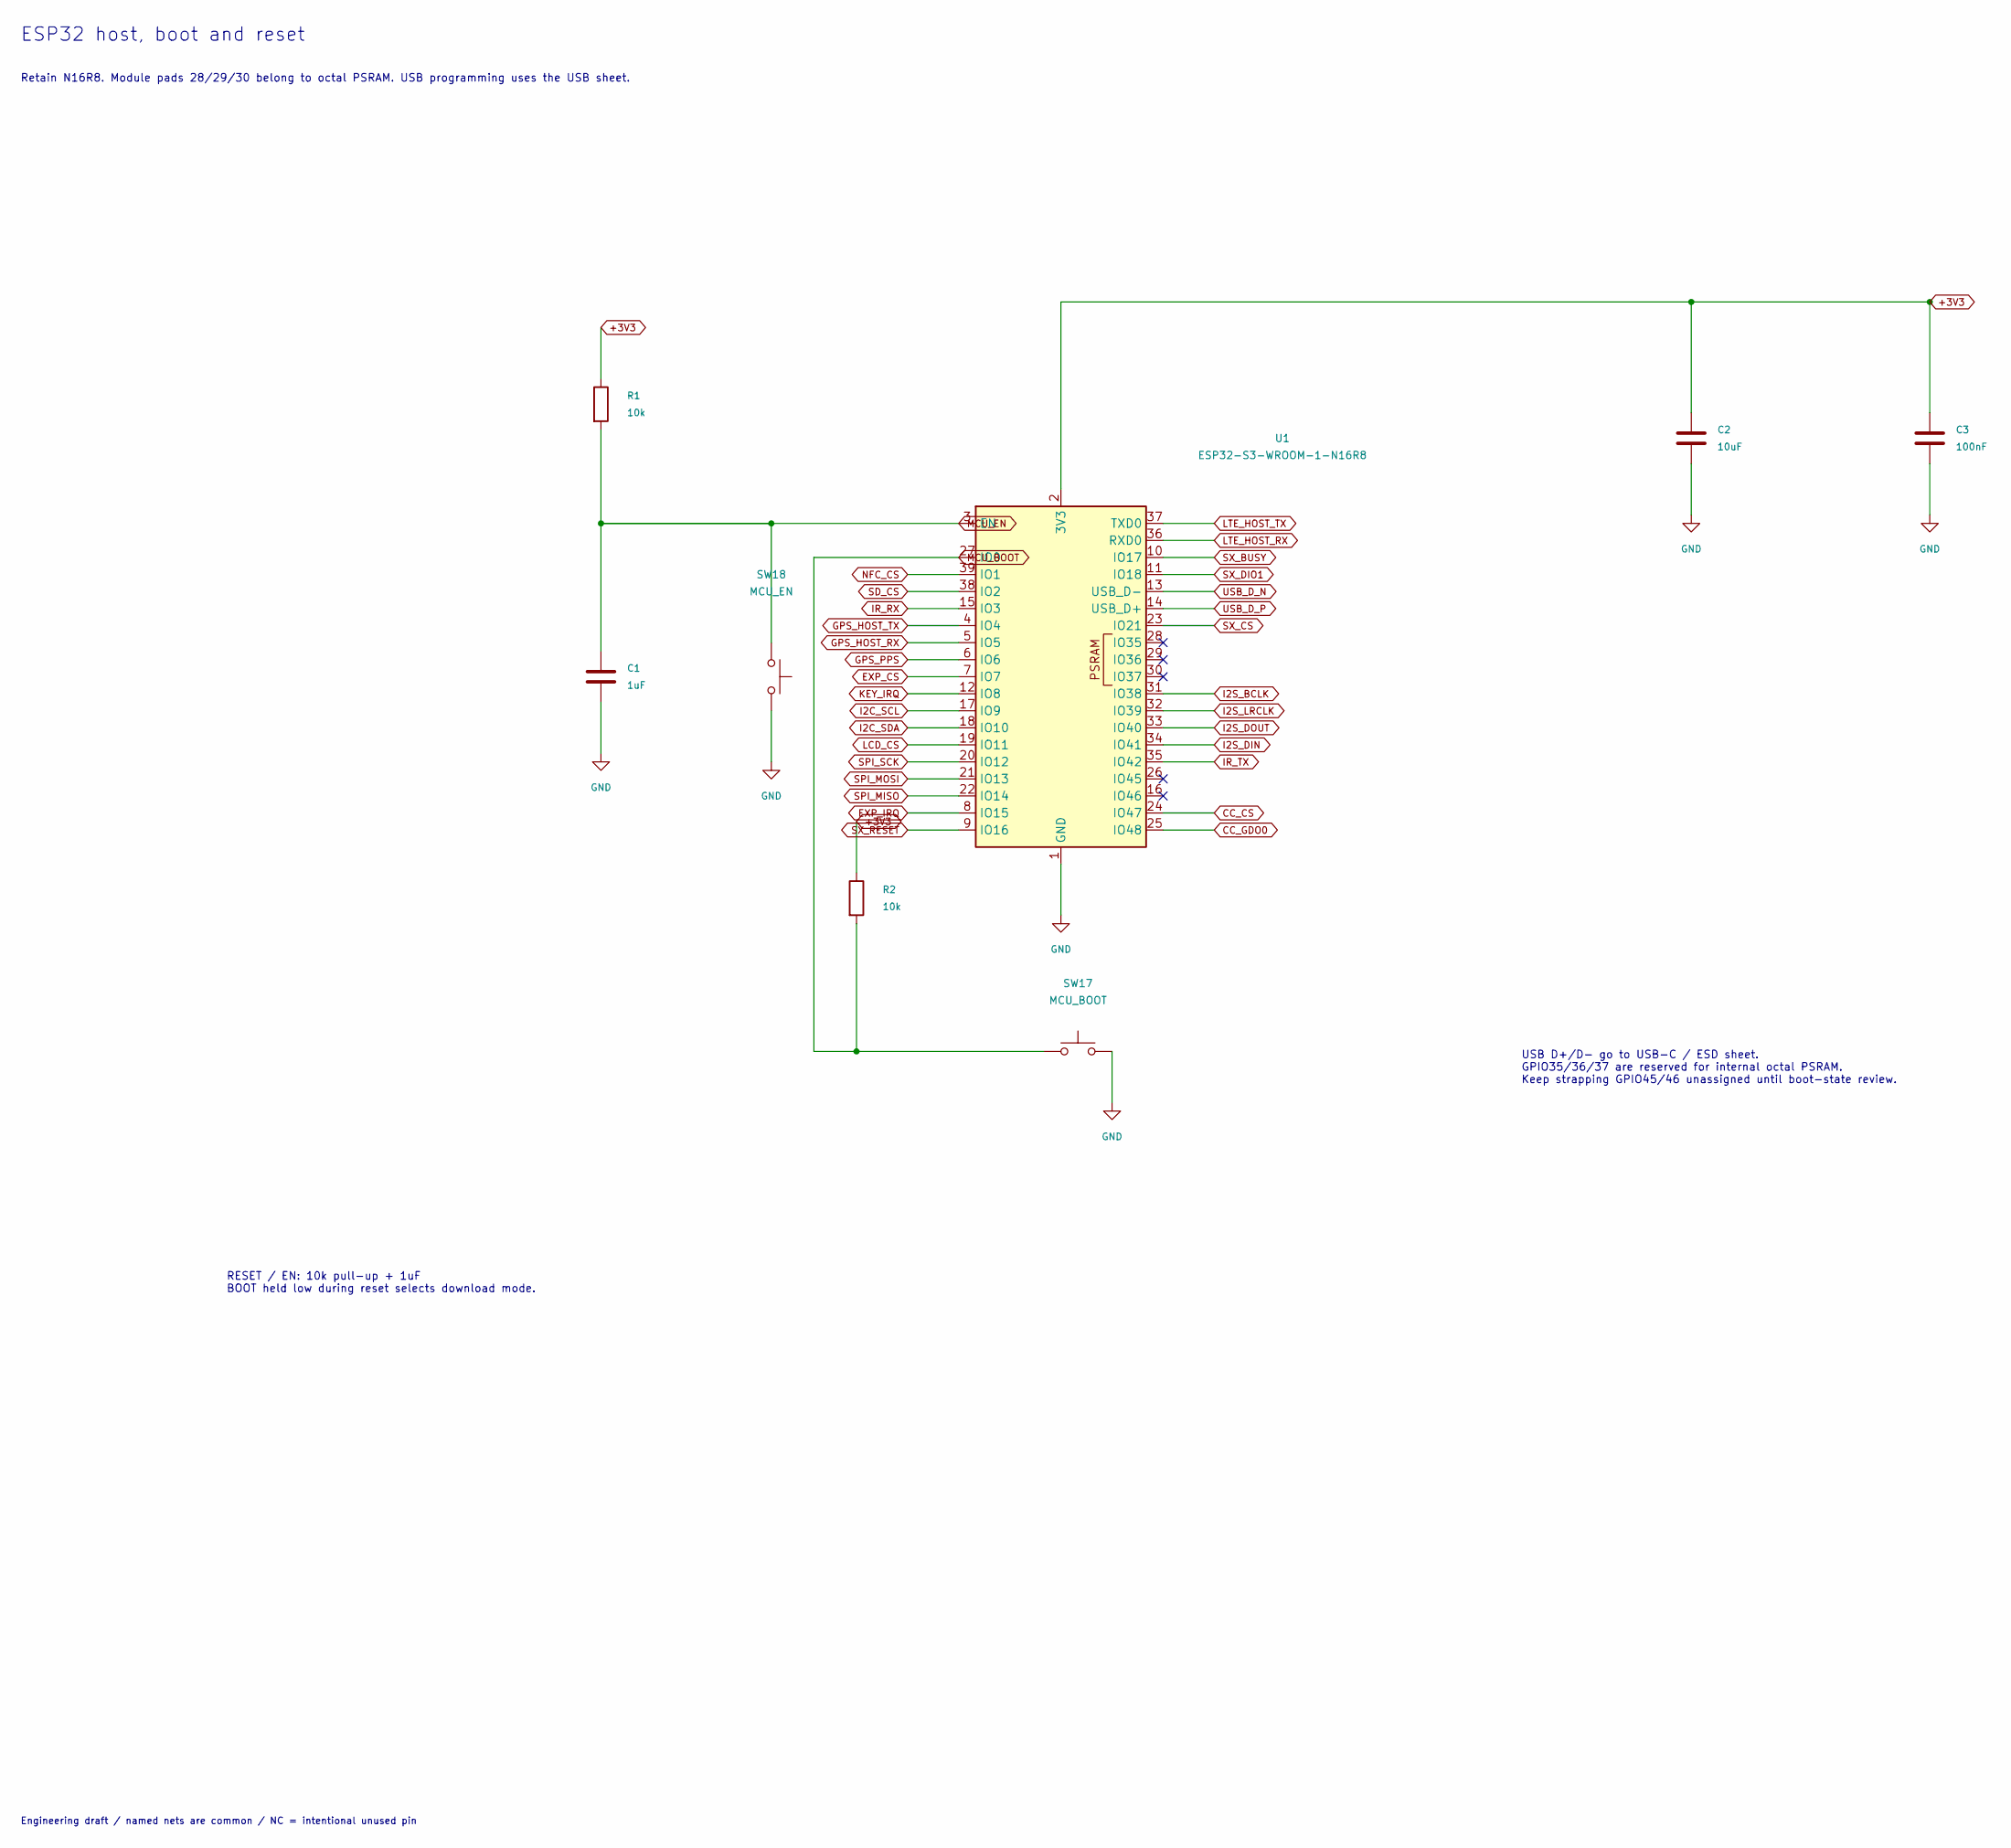
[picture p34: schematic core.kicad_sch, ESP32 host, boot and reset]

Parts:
C1: 1uF; C_0402_1005Metric
C2: 10uF; C_0805_2012Metric
C3: 100nF; C_0402_1005Metric
R1, R2: 10k; R_0402_1005Metric
SW17: MCU_BOOT; SW_SPST_TL3342
SW18: MCU_EN; SW_SPST_TL3342
U1: ESP32-S3-WROOM-1-N16R8; ESP32-S3-WROOM-1_0.3mm_ThermalDrills

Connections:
+3V3: C2.1, C3.1, R1.1, R2.1, U1.2 (3V3); also elsewhere on the board
CC_CS: U1.24 (IO47); also elsewhere on the board
CC_GDO0: U1.25 (IO48); also elsewhere on the board
EXP_CS: U1.7 (IO7); also elsewhere on the board
EXP_IRQ: U1.8 (IO15); also elsewhere on the board
GPS_HOST_RX: U1.5 (IO5); also elsewhere on the board
GPS_HOST_TX: U1.4 (IO4); also elsewhere on the board
GPS_PPS: U1.6 (IO6); also elsewhere on the board
I2S_BCLK: U1.31 (IO38); also elsewhere on the board
I2S_DIN: U1.34 (IO41); also elsewhere on the board
I2S_DOUT: U1.33 (IO40); also elsewhere on the board
I2S_LRCLK: U1.32 (IO39); also elsewhere on the board
IR_RX: U1.15 (IO3); also elsewhere on the board
IR_TX: U1.35 (IO42); also elsewhere on the board
KEY_IRQ: U1.12 (IO8); also elsewhere on the board
LCD_CS: U1.19 (IO11); also elsewhere on the board
LTE_HOST_RX: U1.36 (RXD0); also elsewhere on the board
LTE_HOST_TX: U1.37 (TXD0); also elsewhere on the board
MCU_BOOT: R2.2, SW17.1, U1.27 (IO0)
MCU_EN: C1.1, R1.2, SW18.1, U1.3 (EN); also elsewhere on the board
NFC_CS: U1.39 (IO1); also elsewhere on the board
SD_CS: U1.38 (IO2); also elsewhere on the board
SPI_MISO: U1.22 (IO14); also elsewhere on the board
SPI_MOSI: U1.21 (IO13); also elsewhere on the board
SPI_SCK: U1.20 (IO12); also elsewhere on the board
SX_BUSY: U1.10 (IO17); also elsewhere on the board
SX_CS: U1.23 (IO21); also elsewhere on the board
SX_DIO1: U1.11 (IO18); also elsewhere on the board
SX_RESET: U1.9 (IO16); also elsewhere on the board
USB_HOST_D_N: U1.13 (USB_D-); also elsewhere on the board
USB_HOST_D_P: U1.14 (USB_D+); also elsewhere on the board

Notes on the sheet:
ESP32 host, boot and reset
Retain N16R8. Module pads 28/29/30 belong to octal PSRAM. USB programming uses the USB sheet.
Engineering draft / named nets are common / NC = intentional unused pin
RESET / EN: 10k pull-up + 1uF BOOT held low during reset selects download mode.
USB D+/D- go to USB-C / ESD sheet. GPIO35/36/37 are reserved for internal octal PSRAM. Keep strapping GPIO45/46 unassigned until boot-state review.

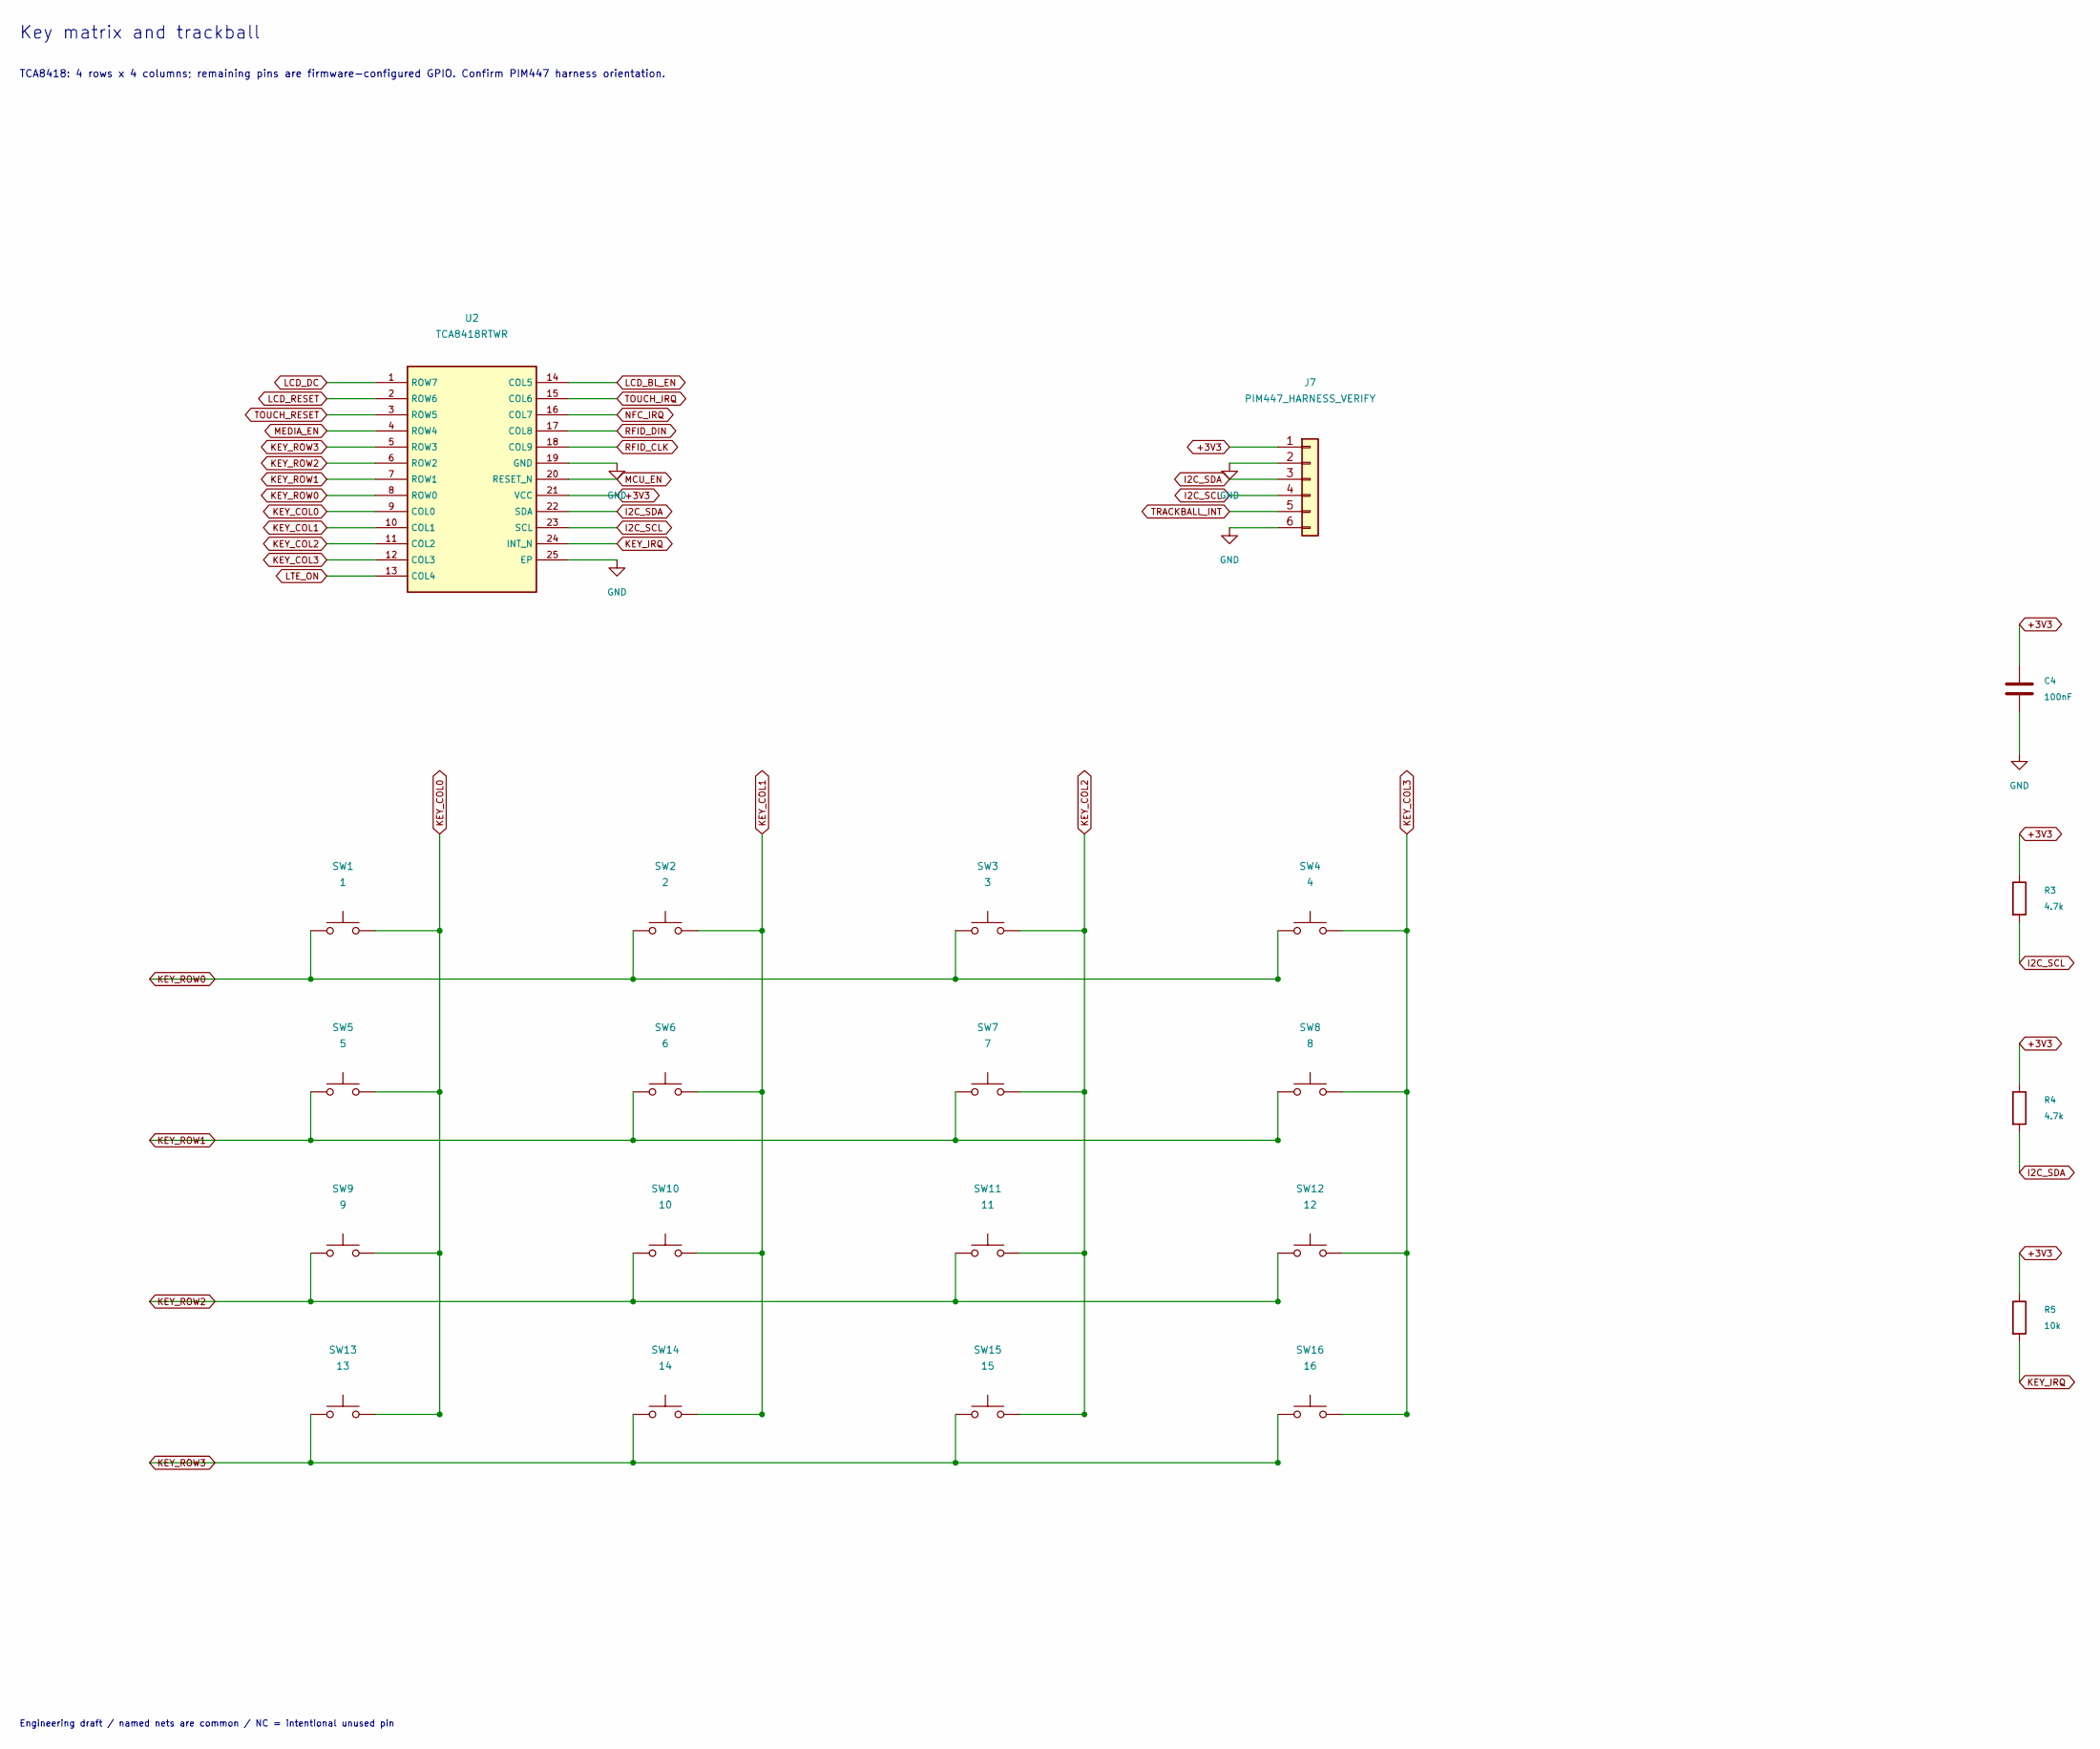
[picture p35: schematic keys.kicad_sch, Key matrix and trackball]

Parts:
C4: 100nF; C_0402_1005Metric
J7: PIM447_HARNESS_VERIFY; JST_GH_BM06B-GHS-TBT_1x06-1MP_P1.25mm_Vertical
R3, R4: 4.7k; R_0402_1005Metric
R5: 10k; R_0402_1005Metric
SW1: 1; SW_SPST_TL3342
SW2: 2; SW_SPST_TL3342
SW3: 3; SW_SPST_TL3342
SW4: 4; SW_SPST_TL3342
SW5: 5; SW_SPST_TL3342
SW6: 6; SW_SPST_TL3342
SW7: 7; SW_SPST_TL3342
SW8: 8; SW_SPST_TL3342
SW9: 9; SW_SPST_TL3342
SW10: 10; SW_SPST_TL3342
SW11: 11; SW_SPST_TL3342
SW12: 12; SW_SPST_TL3342
SW13: 13; SW_SPST_TL3342
SW14: 14; SW_SPST_TL3342
SW15: 15; SW_SPST_TL3342
SW16: 16; SW_SPST_TL3342
U2: TCA8418RTWR; Texas_RTW_WQFN-24-1EP_4x4mm_P0.5mm_EP2.7x2.7mm

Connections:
+3V3: C4.1, J7.1, R3.1, R4.1, R5.1, U2.21 (VCC); also elsewhere on the board
KEY_COL0: SW1.2, SW5.2, SW9.2, SW13.2, U2.9 (COL0)
KEY_COL1: SW2.2, SW6.2, SW10.2, SW14.2, U2.10 (COL1)
KEY_COL2: SW3.2, SW7.2, SW11.2, SW15.2, U2.11 (COL2)
KEY_COL3: SW4.2, SW8.2, SW12.2, SW16.2, U2.12 (COL3)
KEY_IRQ: R5.2, U2.24 (INT_N); also elsewhere on the board
KEY_ROW0: SW1.1, SW2.1, SW3.1, SW4.1, U2.8 (ROW0)
KEY_ROW1: SW5.1, SW6.1, SW7.1, SW8.1, U2.7 (ROW1)
KEY_ROW2: SW9.1, SW10.1, SW11.1, SW12.1, U2.6 (ROW2)
KEY_ROW3: SW13.1, SW14.1, SW15.1, SW16.1, U2.5 (ROW3)
LCD_BL_EN: U2.14 (COL5); also elsewhere on the board
LCD_DC: U2.1 (ROW7); also elsewhere on the board
LCD_RESET: U2.2 (ROW6); also elsewhere on the board
LTE_ON: U2.13 (COL4); also elsewhere on the board
MCU_EN: U2.20 (RESET_N); also elsewhere on the board
MEDIA_EN: U2.4 (ROW4); also elsewhere on the board
NFC_IRQ: U2.16 (COL7); also elsewhere on the board
RFID_CLK: U2.18 (COL9); also elsewhere on the board
RFID_DIN: U2.17 (COL8); also elsewhere on the board
TOUCH_IRQ: U2.15 (COL6); also elsewhere on the board
TOUCH_RESET: U2.3 (ROW5); also elsewhere on the board
TRACKBALL_INT: J7.5

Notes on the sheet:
Key matrix and trackball
TCA8418: 4 rows x 4 columns; remaining pins are firmware-configured GPIO. Confirm PIM447 harness orientation.
Engineering draft / named nets are common / NC = intentional unused pin

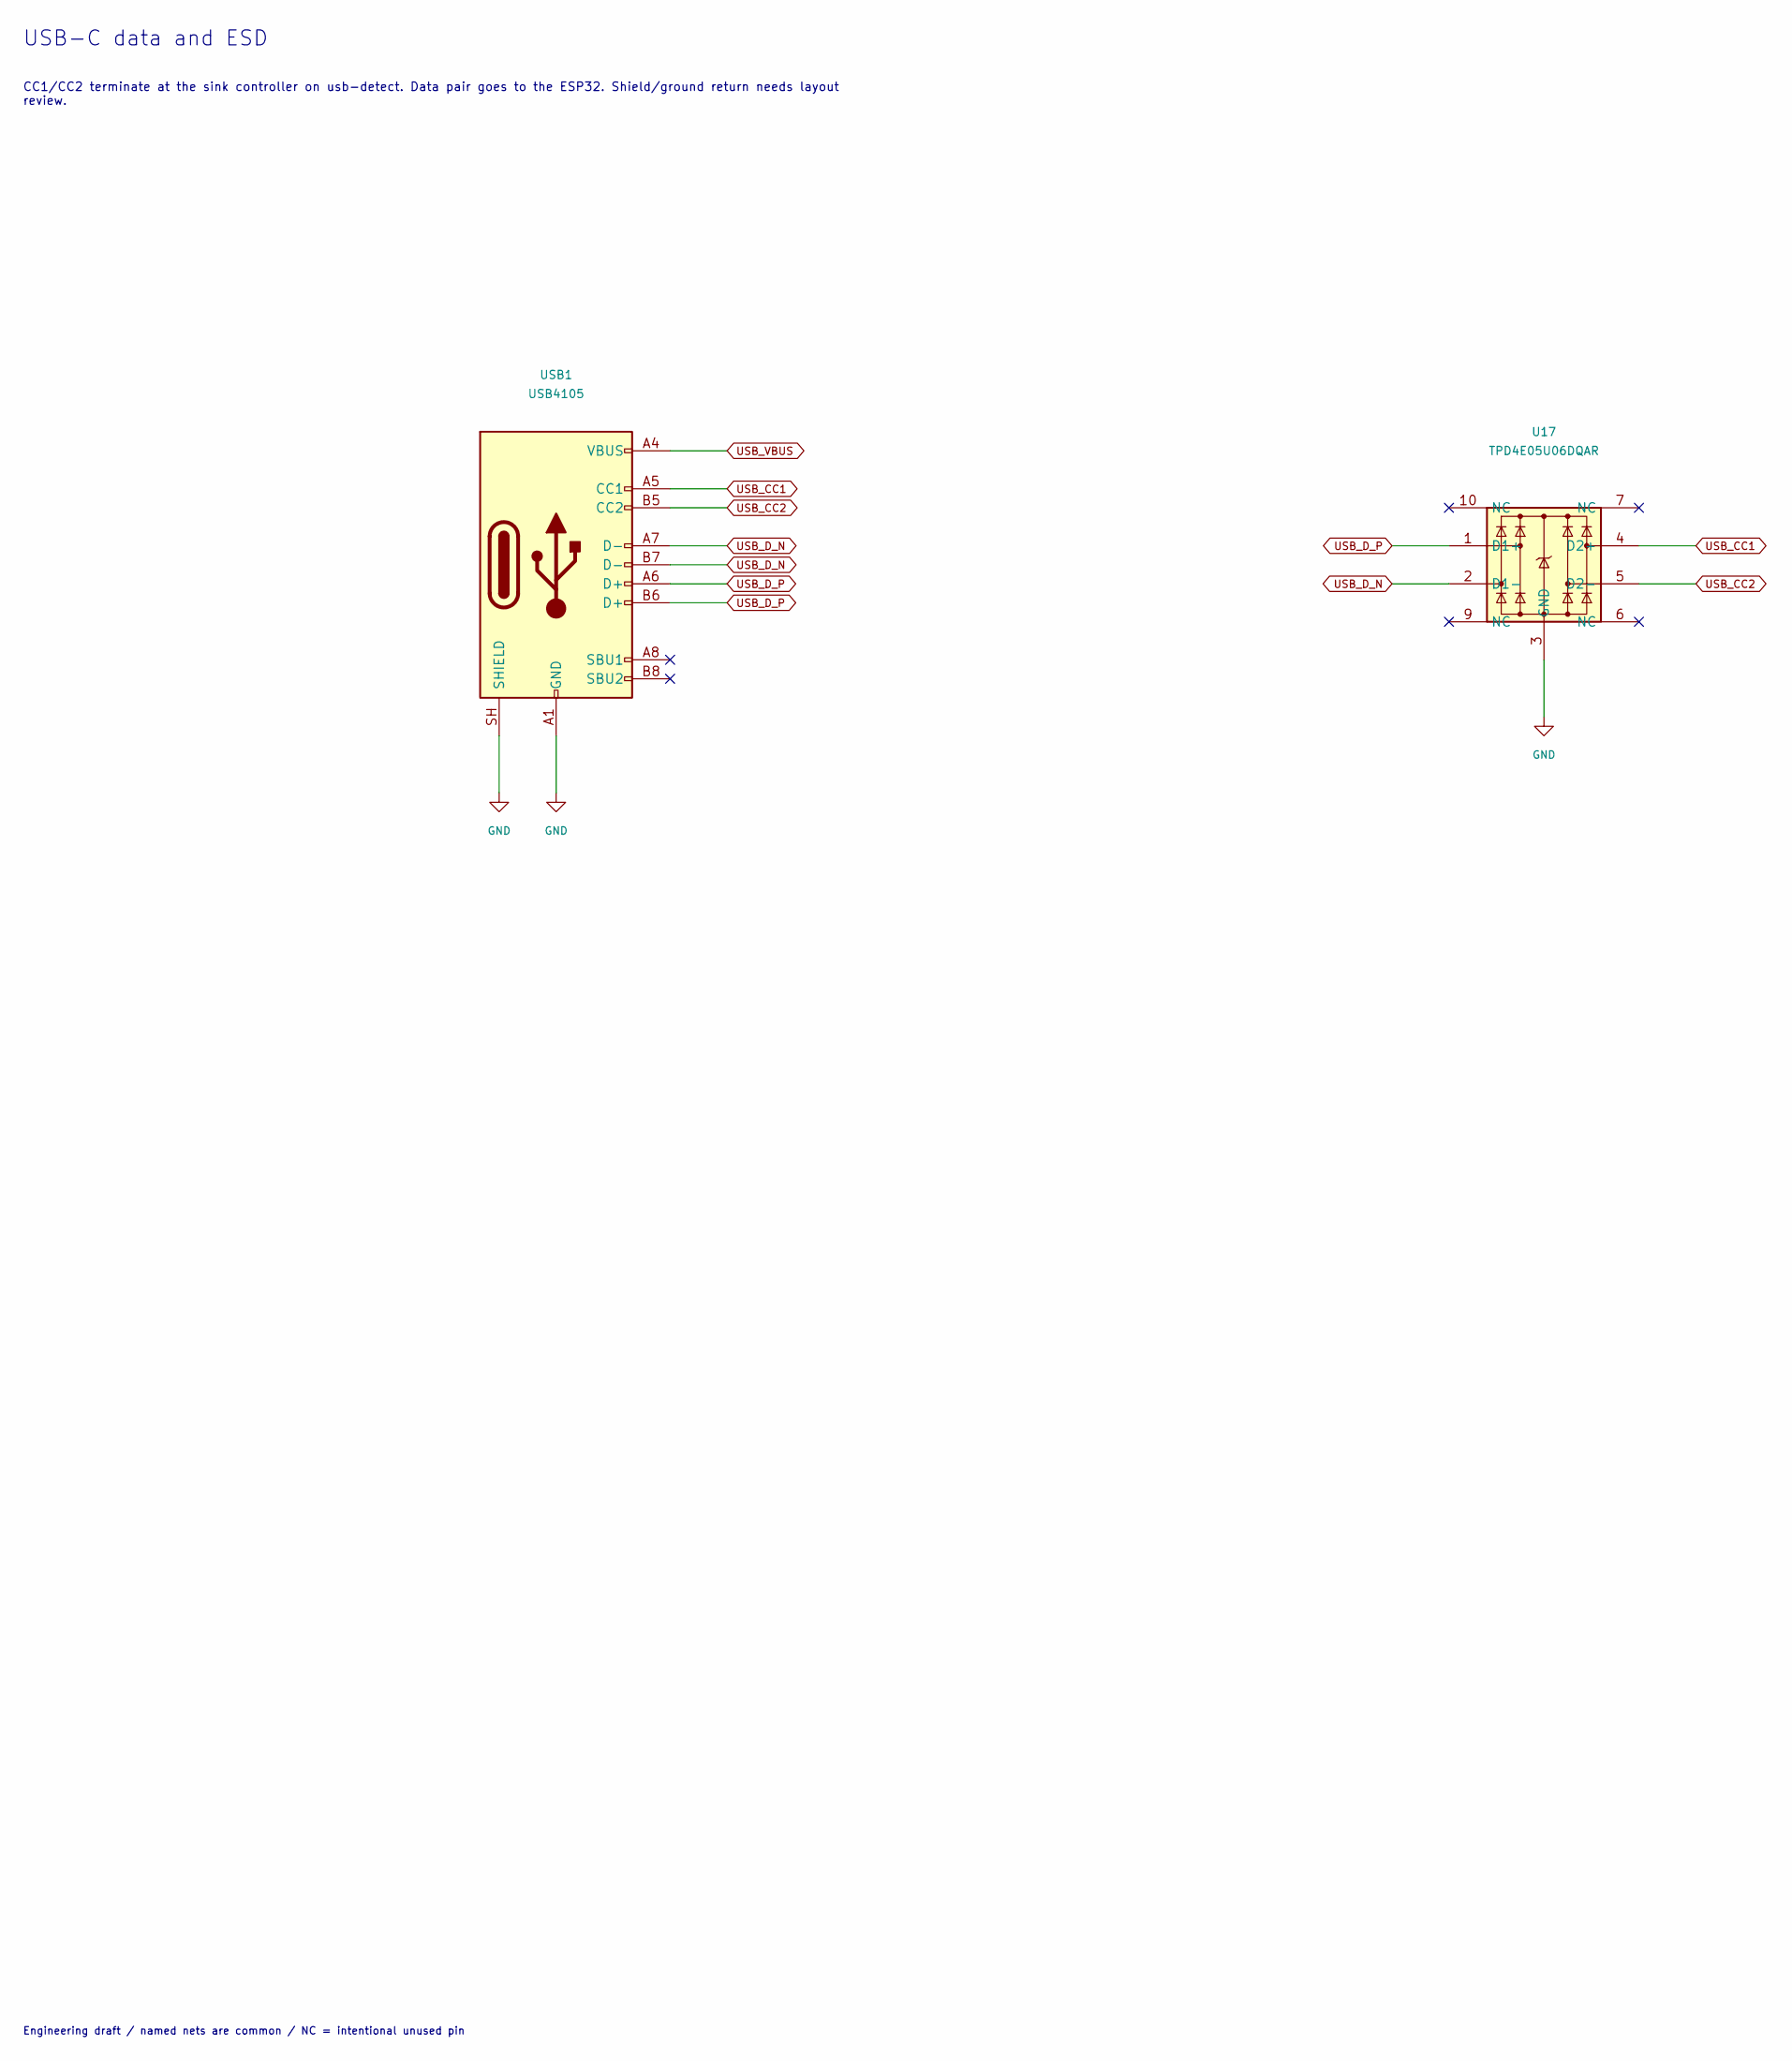
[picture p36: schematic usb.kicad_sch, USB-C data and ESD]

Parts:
U17: TPD4E05U06DQAR; USON-10_2.5x1.0mm_P0.5mm
USB1: USB4105; USB_C_Receptacle_GCT_USB4105-xx-A_16P_TopMnt_Horizontal

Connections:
USB_CC1: U17.4 (D2+), USB1.A5 (CC1); also elsewhere on the board
USB_CC2: U17.5 (D2-), USB1.B5 (CC2); also elsewhere on the board
USB_VBUS: USB1.A4 (VBUS), USB1.A9 (VBUS), USB1.B4 (VBUS), USB1.B9 (VBUS); also elsewhere on the board

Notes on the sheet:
USB-C data and ESD
CC1/CC2 terminate at the sink controller on usb-detect. Data pair goes to the ESP32. Shield/ground return needs layout review.
Engineering draft / named nets are common / NC = intentional unused pin

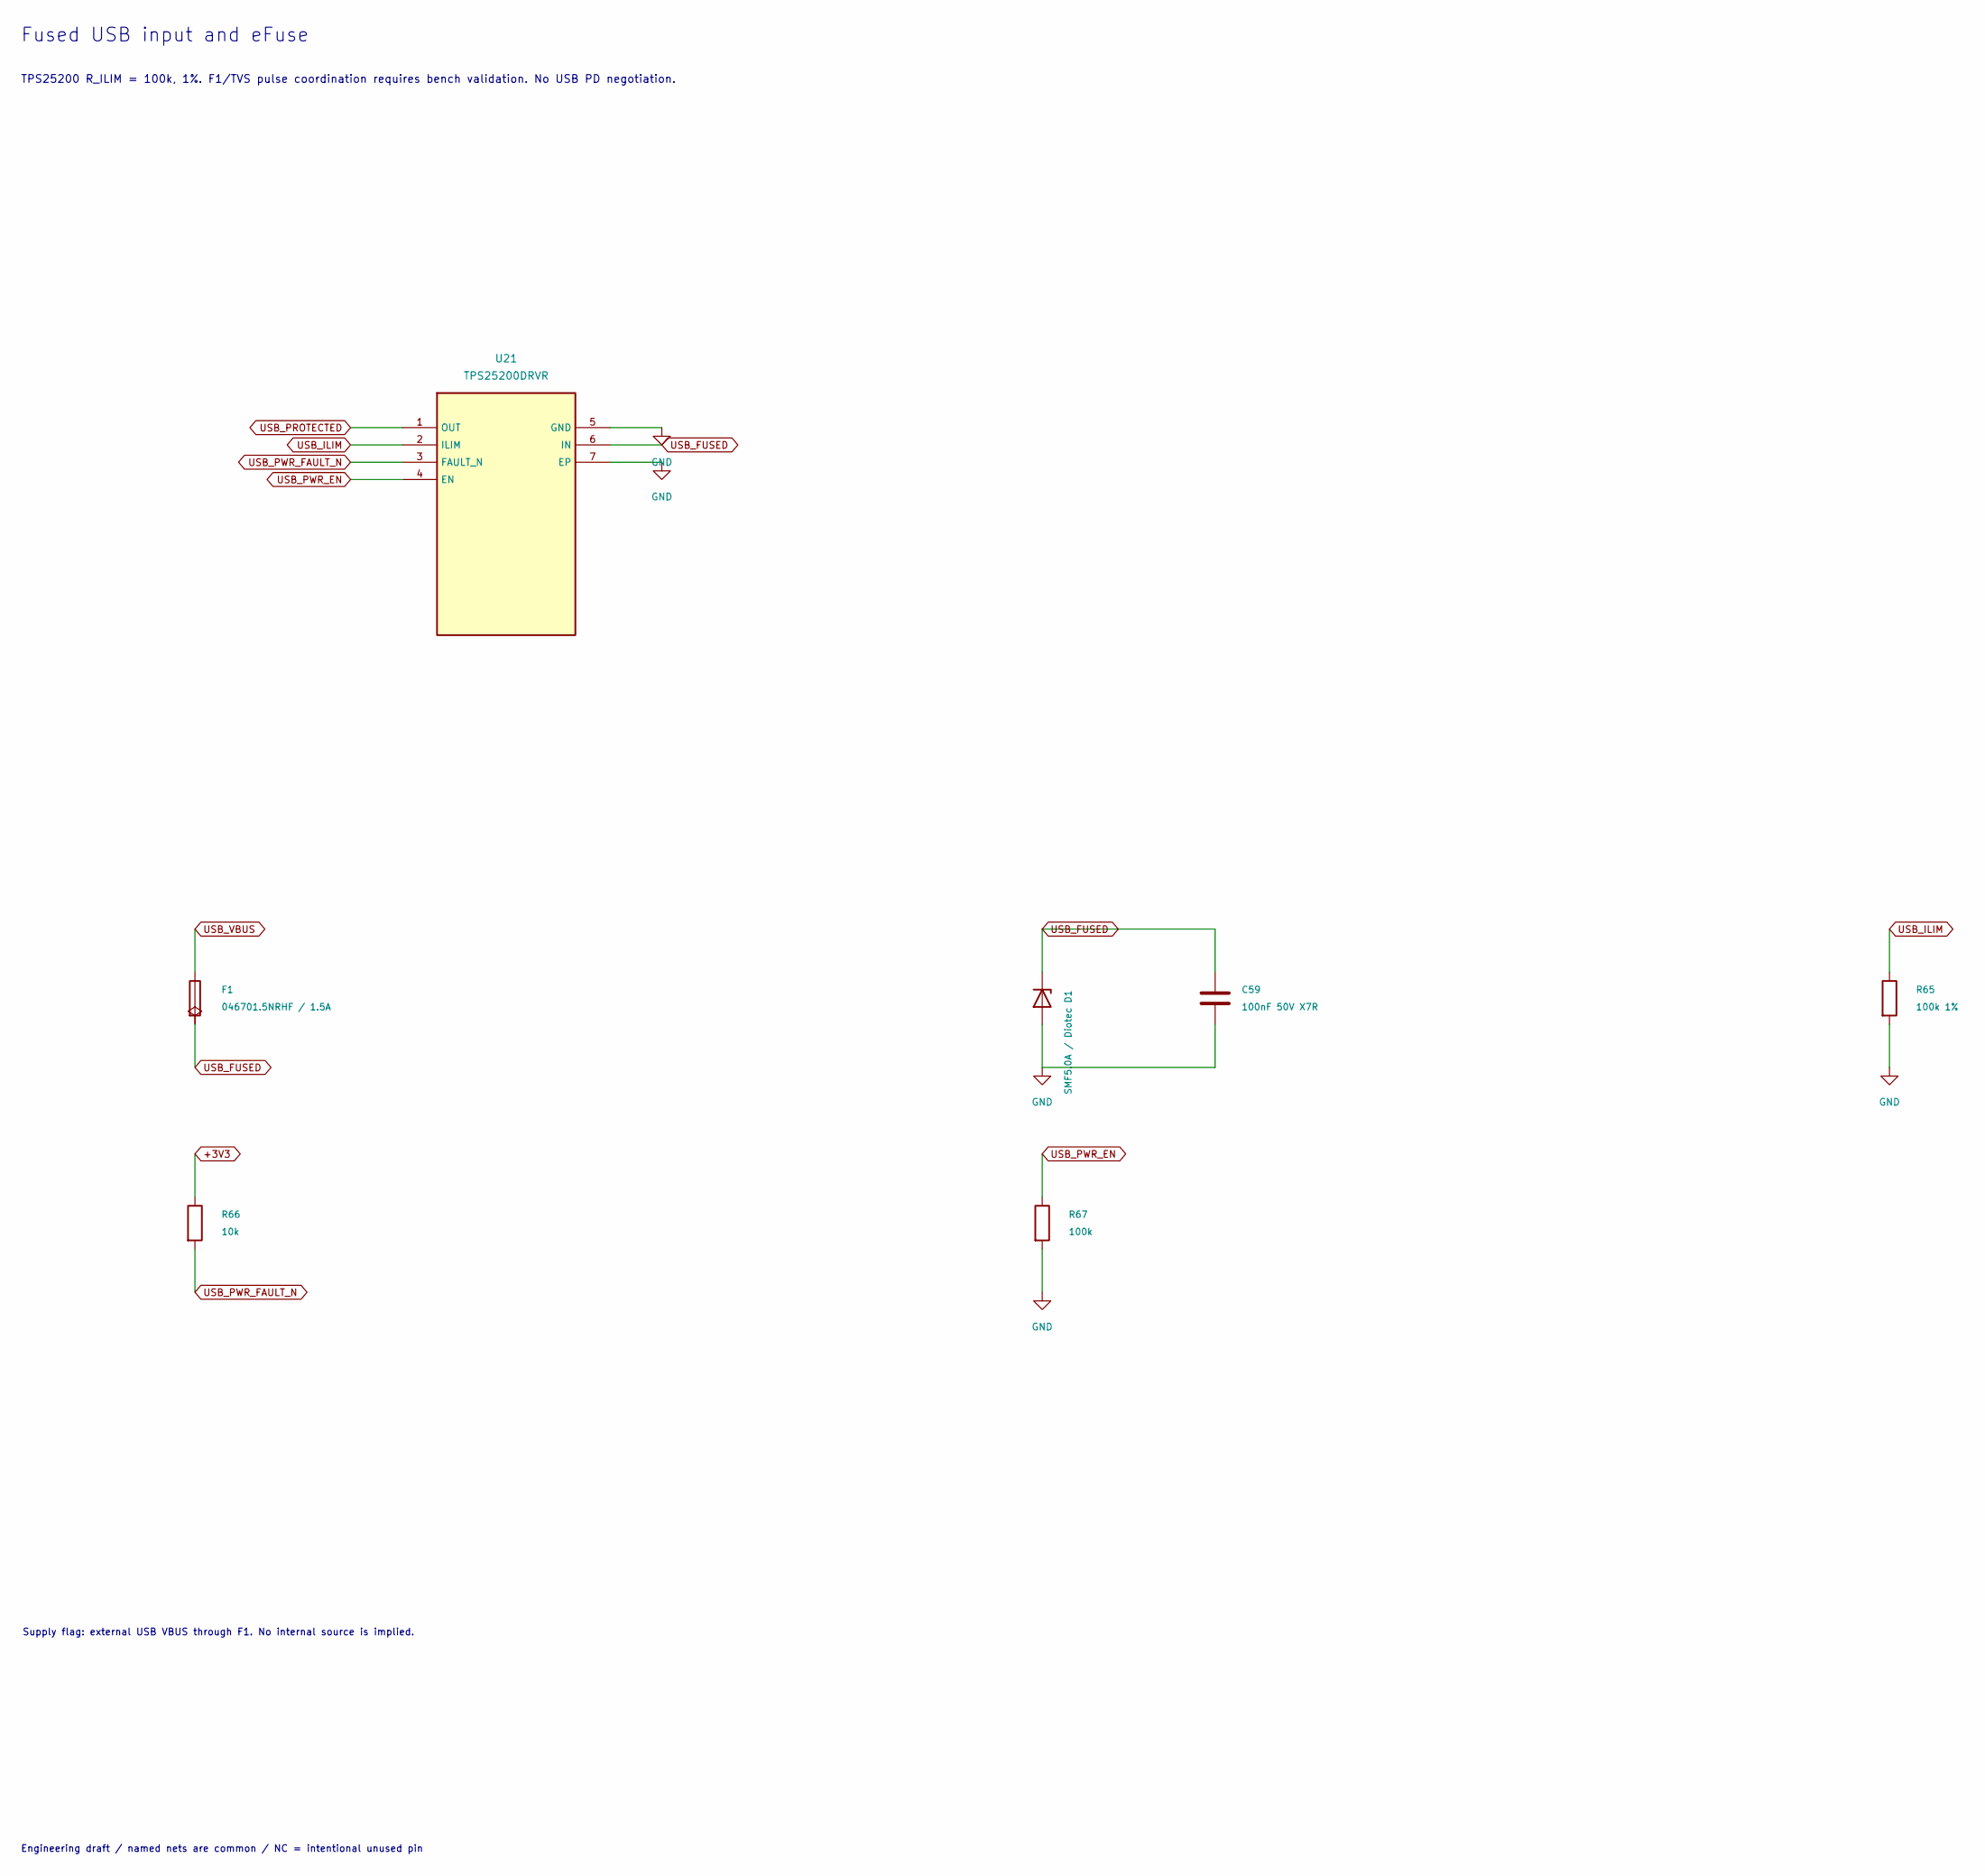
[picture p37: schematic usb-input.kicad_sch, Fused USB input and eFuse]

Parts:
C59: 100nF 50V X7R; C_0603_1608Metric
D1: SMF5.0A / Diotec; D_SOD-123F
F1: 046701.5NRHF / 1.5A; Fuse_0603_1608Metric
R65: 100k 1%; R_0402_1005Metric
R66: 10k; R_0402_1005Metric
R67: 100k; R_0402_1005Metric
U21: TPS25200DRVR; WSON-6-1EP_2x2mm_P0.65mm_EP1x1.6mm

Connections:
USB_FUSED: C59.1, D1.1 (K), F1.2, U21.6 (IN); also elsewhere on the board
USB_ILIM: R65.1, U21.2 (ILIM)
USB_PROTECTED: U21.1 (OUT); also elsewhere on the board
USB_PWR_EN: R67.1, U21.4 (EN); also elsewhere on the board
USB_PWR_FAULT_N: R66.2, U21.3 (FAULT_N); also elsewhere on the board
USB_VBUS: F1.1; also elsewhere on the board

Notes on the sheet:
Fused USB input and eFuse
TPS25200 R_ILIM = 100k, 1%. F1/TVS pulse coordination requires bench validation. No USB PD negotiation.
Engineering draft / named nets are common / NC = intentional unused pin
Supply flag: external USB VBUS through F1. No internal source is implied.

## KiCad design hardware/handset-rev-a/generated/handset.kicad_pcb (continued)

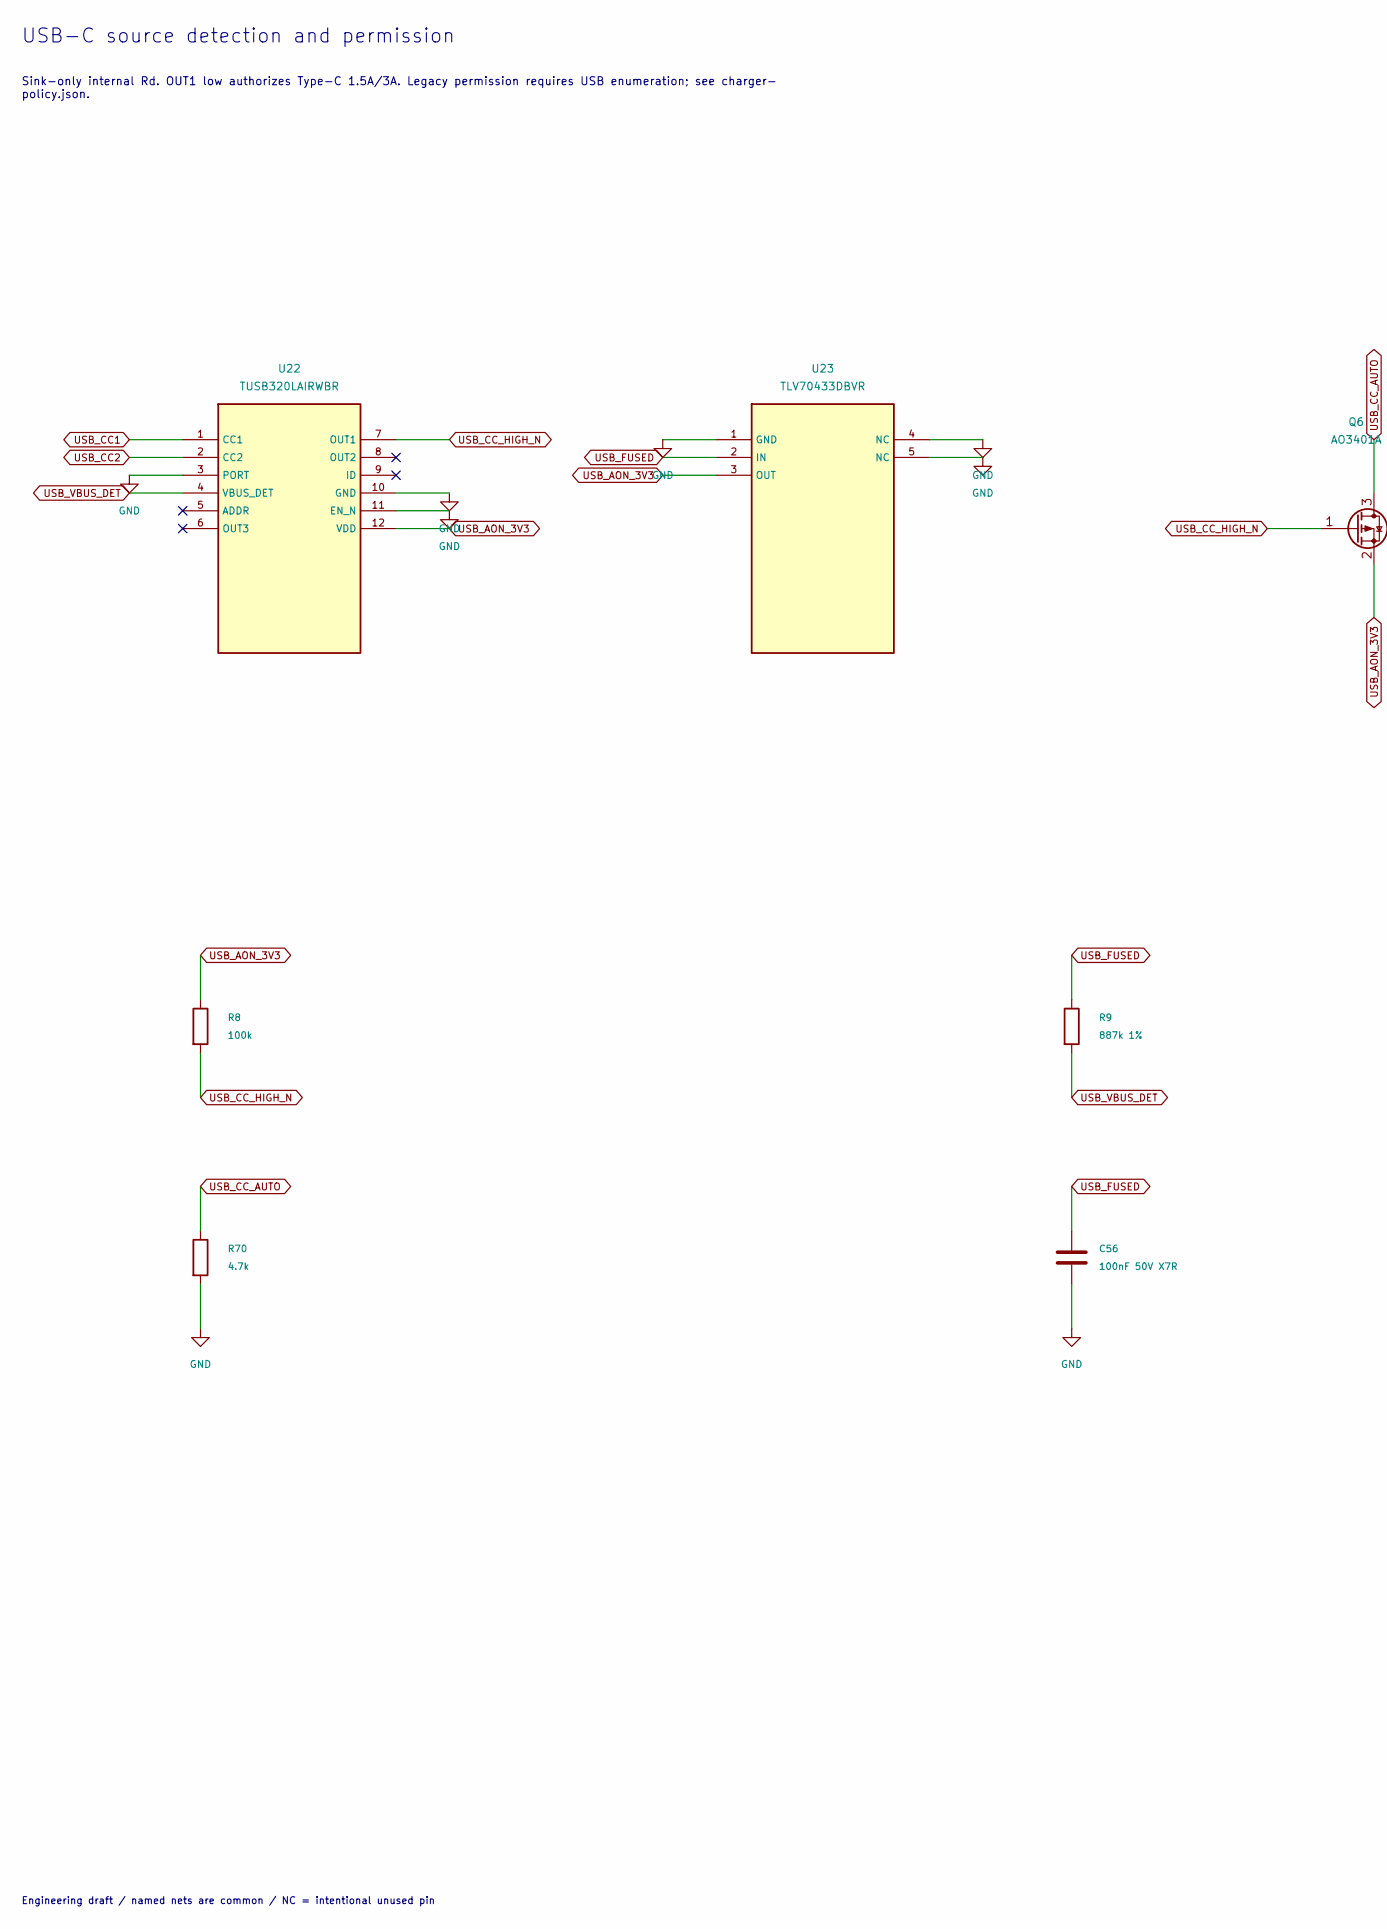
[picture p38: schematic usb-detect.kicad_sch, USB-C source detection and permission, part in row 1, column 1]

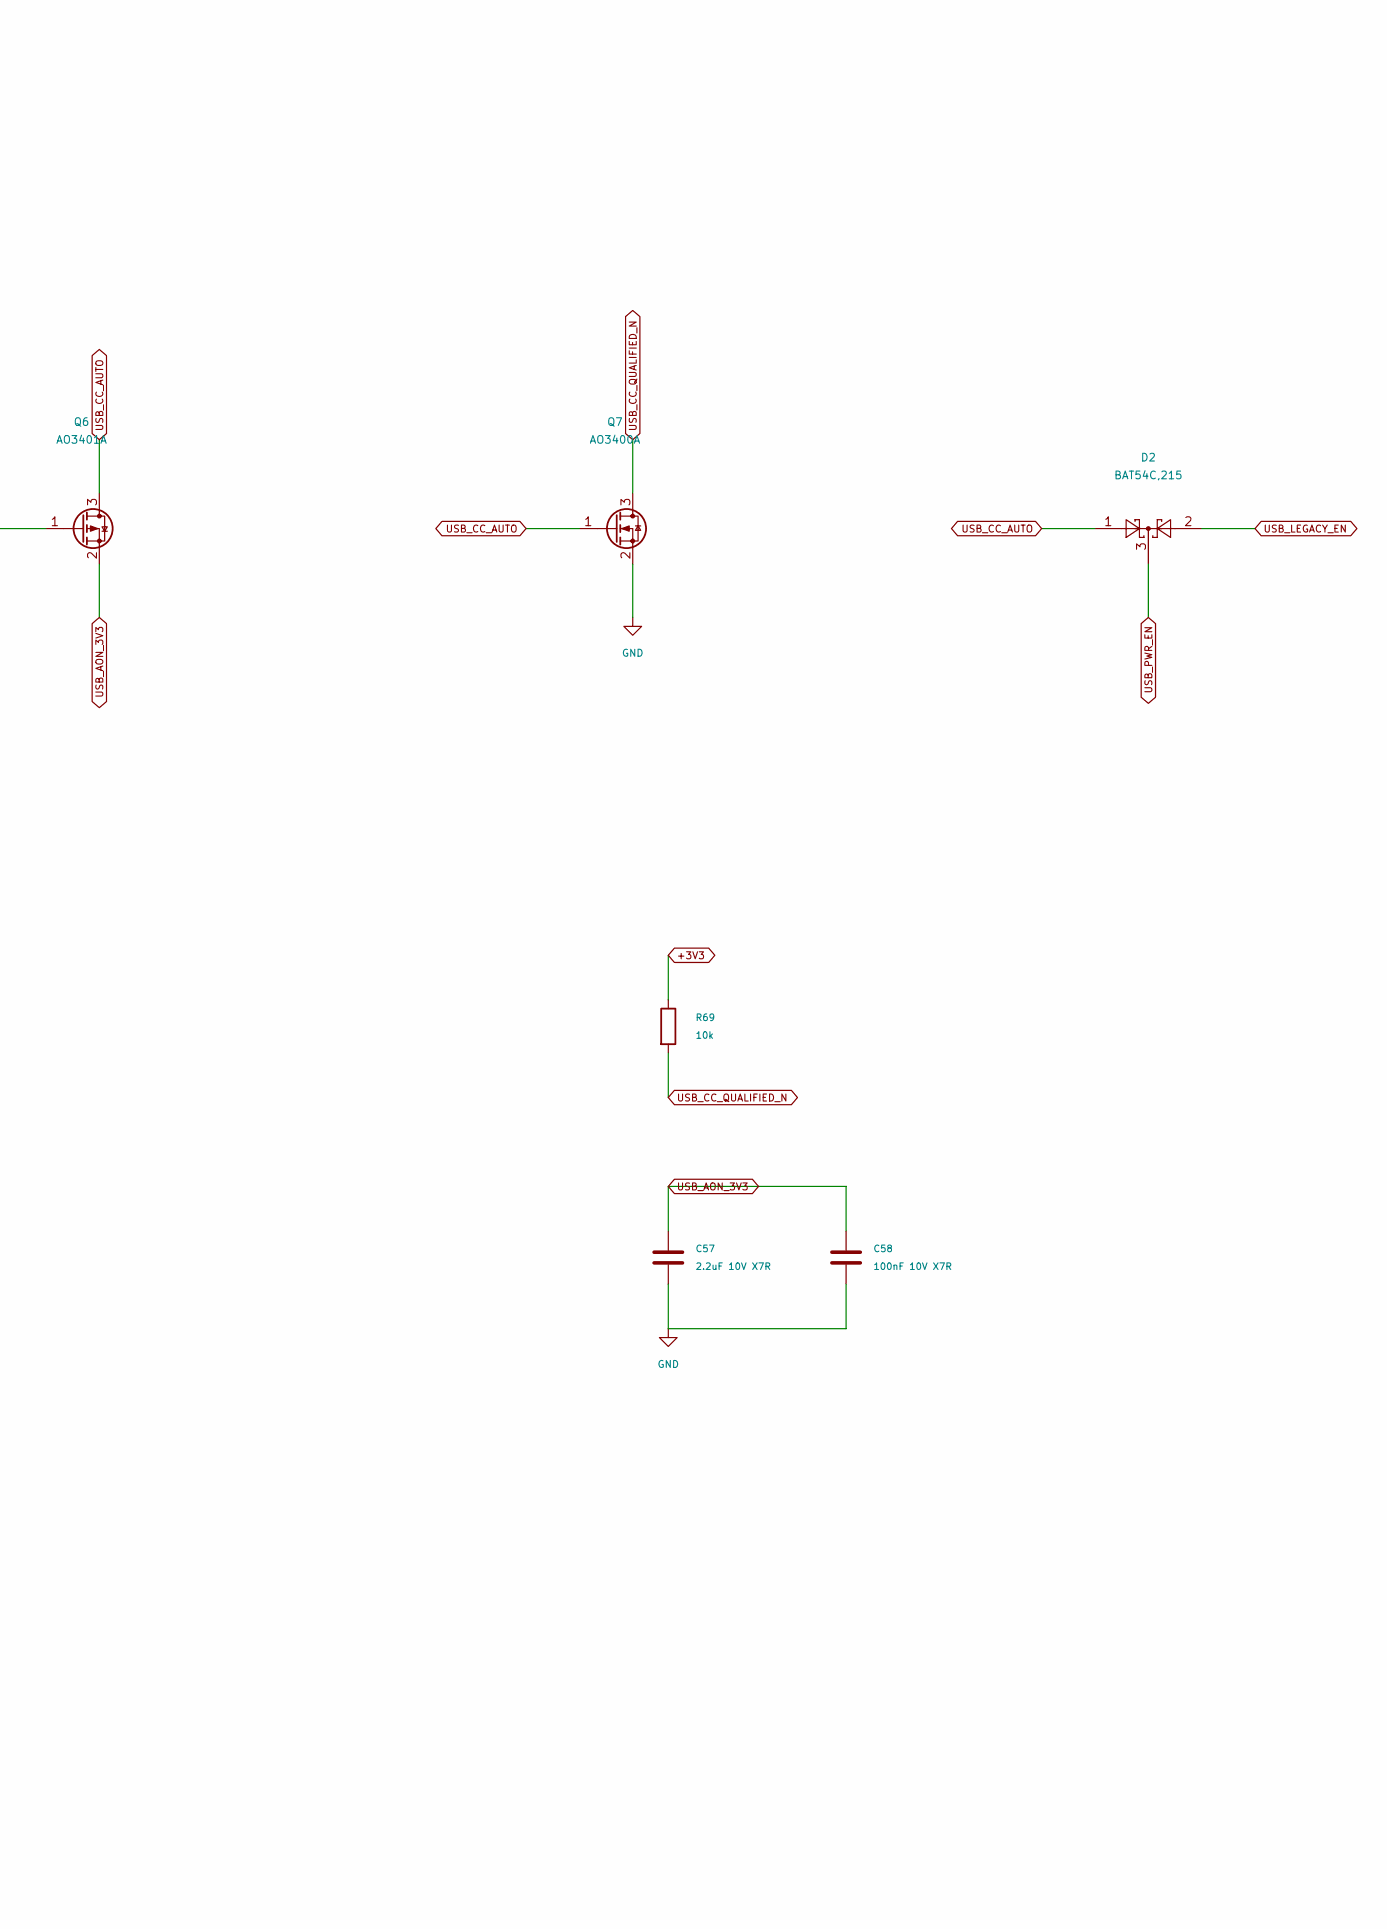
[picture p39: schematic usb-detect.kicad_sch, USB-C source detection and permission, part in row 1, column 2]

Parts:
C56: 100nF 50V X7R; C_0603_1608Metric
C57: 2.2uF 10V X7R; C_0603_1608Metric
C58: 100nF 10V X7R; C_0402_1005Metric
D2: BAT54C,215; SOT-23
Q6: AO3401A; SOT-23
Q7: AO3400A; SOT-23
R8: 100k; R_0402_1005Metric
R9: 887k 1%; R_0402_1005Metric
R69: 10k; R_0402_1005Metric
R70: 4.7k; R_0402_1005Metric
U22: TUSB320LAIRWBR; Texas_X2QFN-12_1.6x1.6mm_P0.4mm
U23: TLV70433DBVR; SOT-23-5

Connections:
USB_AON_3V3: C57.1, C58.1, Q6.2 (S), R8.1, U22.12 (VDD), U23.3 (OUT)
USB_CC1: U22.1 (CC1); also elsewhere on the board
USB_CC2: U22.2 (CC2); also elsewhere on the board
USB_CC_AUTO: D2.1, Q6.3 (D), Q7.1 (G), R70.1
USB_CC_HIGH_N: Q6.1 (G), R8.2, U22.7 (OUT1)
USB_CC_QUALIFIED_N: Q7.3 (D), R69.2; also elsewhere on the board
USB_FUSED: C56.1, R9.1, U23.2 (IN); also elsewhere on the board
USB_LEGACY_EN: D2.2; also elsewhere on the board
USB_PWR_EN: D2.3; also elsewhere on the board
USB_VBUS_DET: R9.2, U22.4 (VBUS_DET)

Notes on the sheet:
USB-C source detection and permission
Sink-only internal Rd. OUT1 low authorizes Type-C 1.5A/3A. Legacy permission requires USB enumeration; see charger- policy.json.
Engineering draft / named nets are common / NC = intentional unused pin

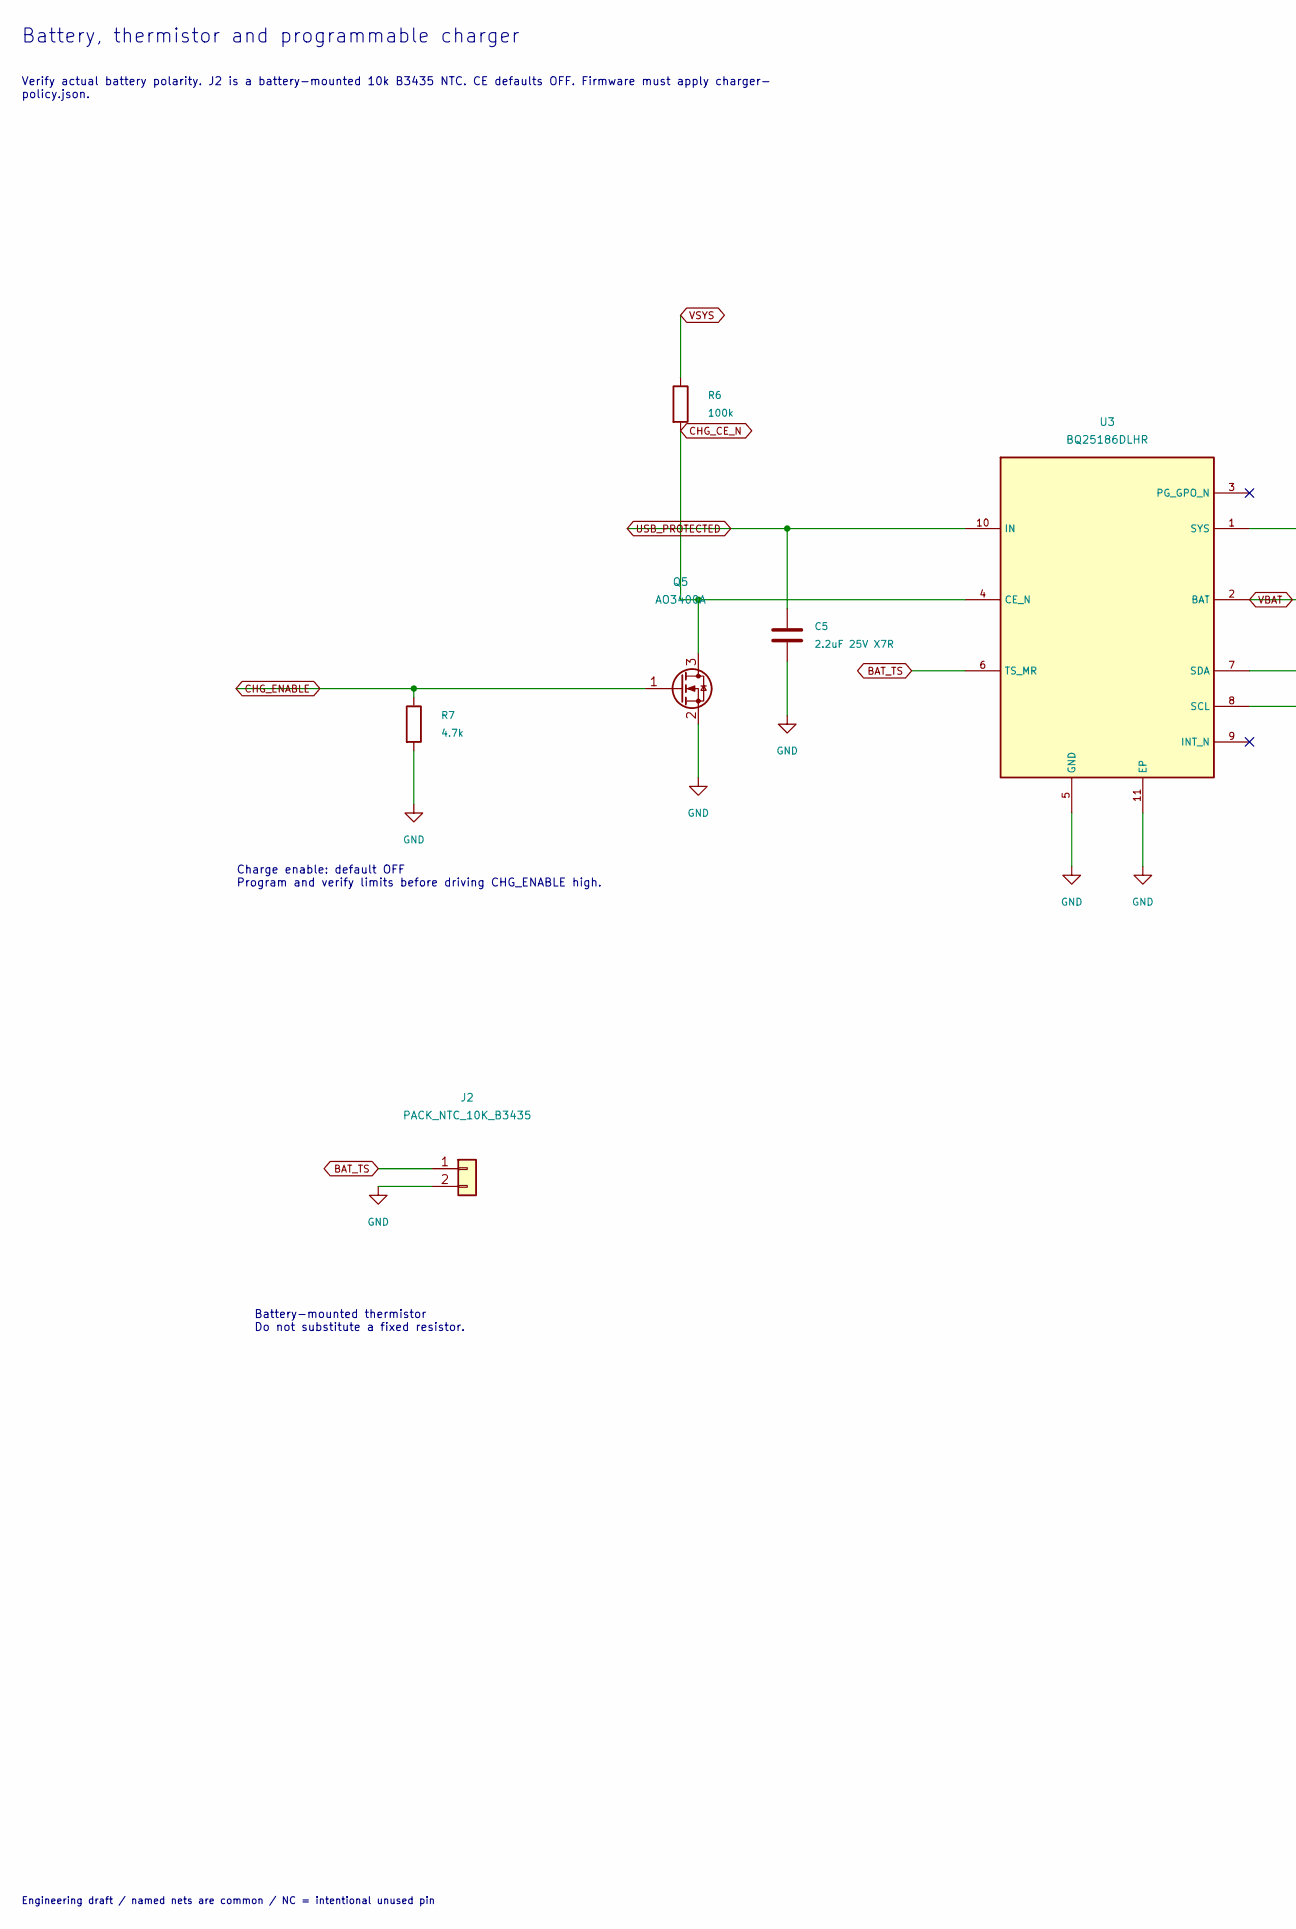
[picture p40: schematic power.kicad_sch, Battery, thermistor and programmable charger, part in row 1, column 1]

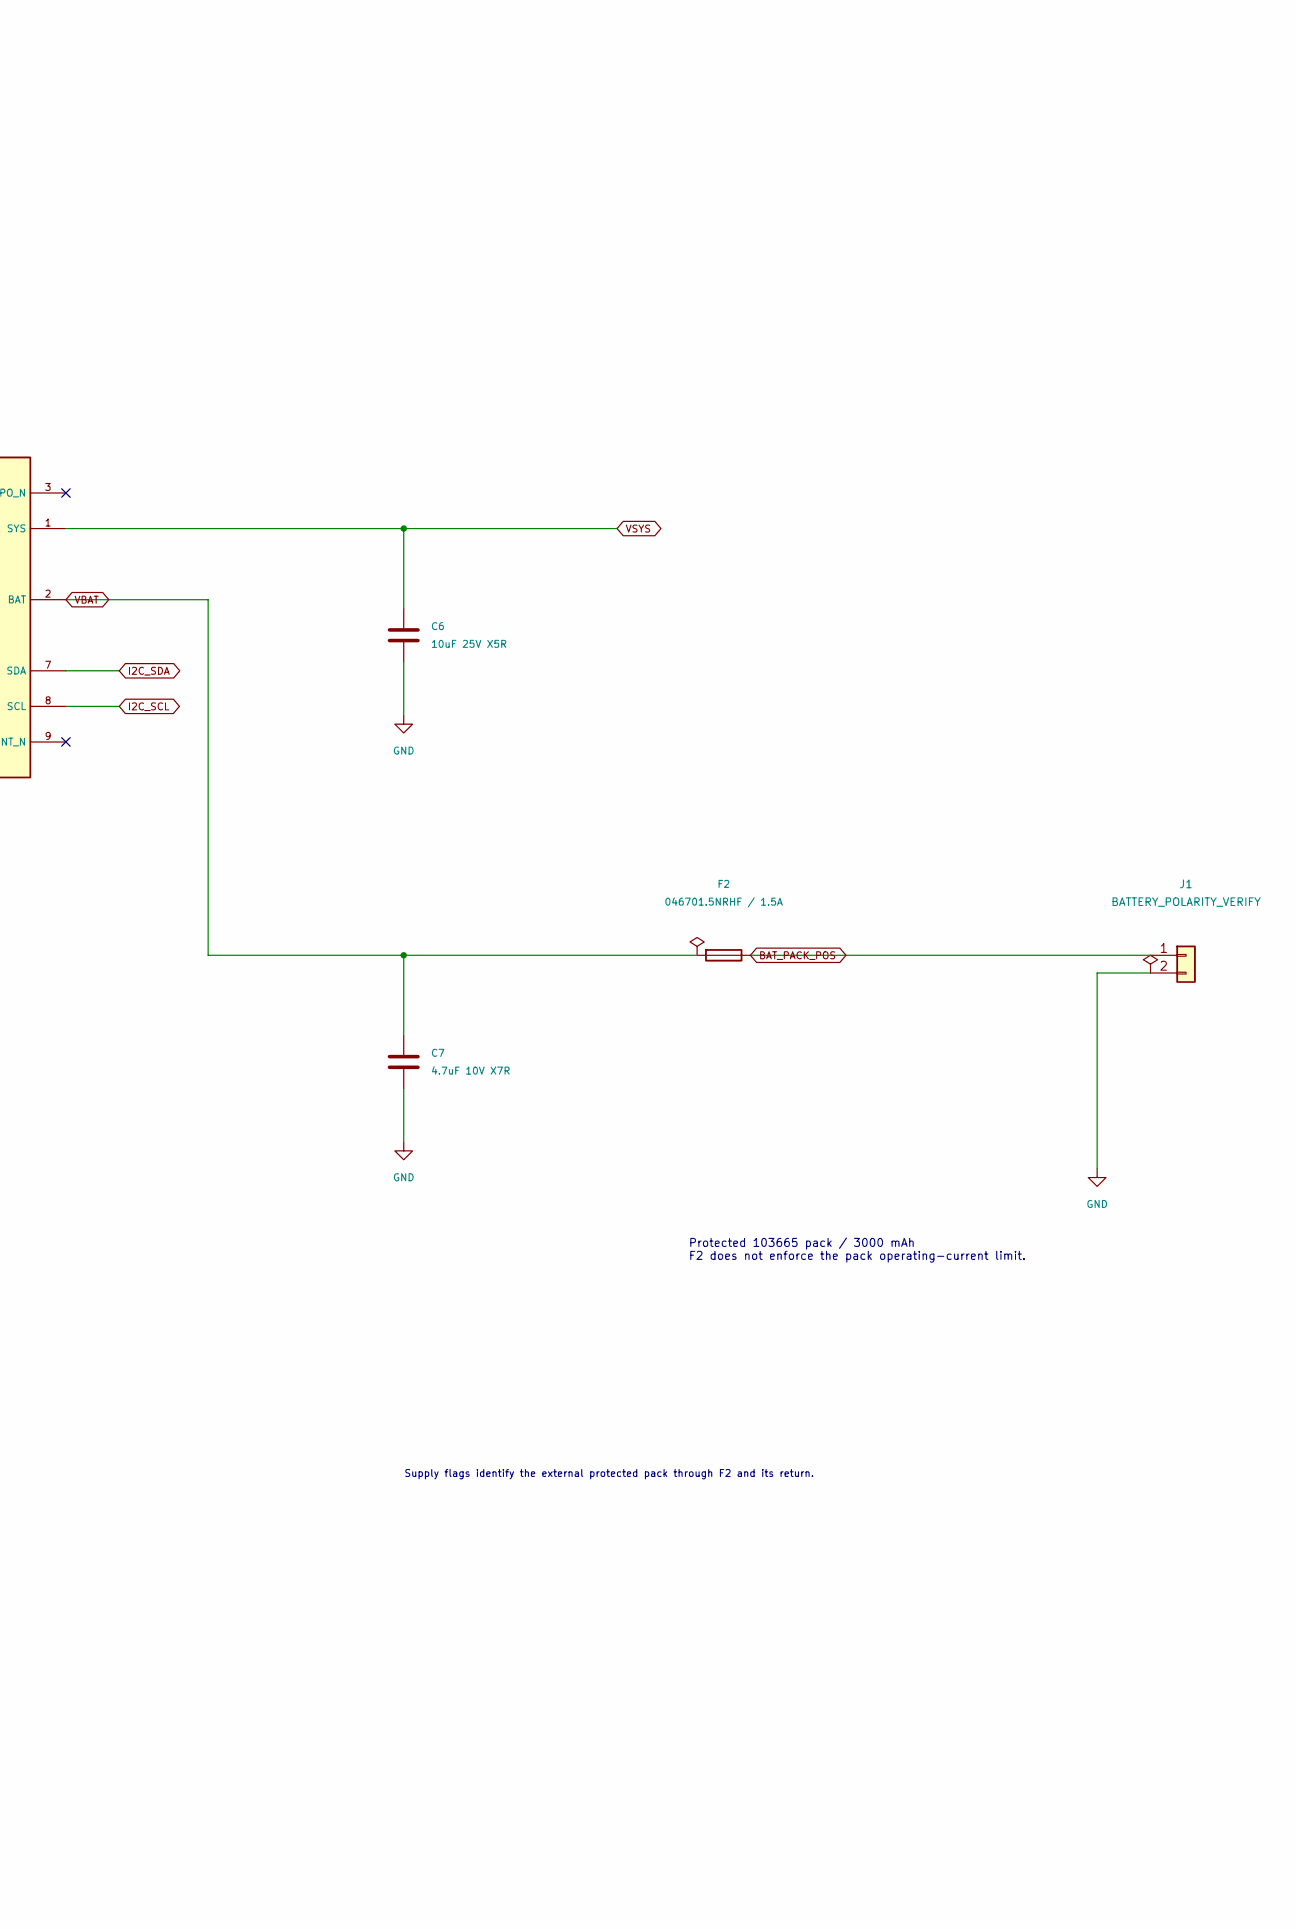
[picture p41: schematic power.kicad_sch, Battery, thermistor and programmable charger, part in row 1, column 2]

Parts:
C5: 2.2uF 25V X7R; C_0805_2012Metric
C6: 10uF 25V X5R; C_0805_2012Metric
C7: 4.7uF 10V X7R; C_0603_1608Metric
F2: 046701.5NRHF / 1.5A; Fuse_0603_1608Metric
J1: BATTERY_POLARITY_VERIFY; JST_PH_B2B-PH-SM4-TB_1x02-1MP_P2.00mm_Vertical
J2: PACK_NTC_10K_B3435; JST_GH_BM02B-GHS-TBT_1x02-1MP_P1.25mm_Vertical
Q5: AO3400A; SOT-23
R6: 100k; R_0402_1005Metric
R7: 4.7k; R_0402_1005Metric
U3: BQ25186DLHR; Texas_DLH0010A_WSON-10-1EP_2.2x2mm_P0.4mm_EP0.9x1.5mm

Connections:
BAT_PACK_POS: F2.1, J1.1
BAT_TS: J2.1, U3.6 (TS_MR)
CHG_CE_N: Q5.3 (D), R6.2, U3.4 (CE_N)
CHG_ENABLE: Q5.1 (G), R7.1; also elsewhere on the board
USB_PROTECTED: C5.1, U3.10 (IN); also elsewhere on the board
VBAT: C7.1, F2.2, U3.2 (BAT); also elsewhere on the board
VSYS: C6.1, R6.1, U3.1 (SYS); also elsewhere on the board

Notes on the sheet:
Battery, thermistor and programmable charger
Verify actual battery polarity. J2 is a battery-mounted 10k B3435 NTC. CE defaults OFF. Firmware must apply charger- policy.json.
Engineering draft / named nets are common / NC = intentional unused pin
Protected 103665 pack / 3000 mAh F2 does not enforce the pack operating-current limit.
Battery-mounted thermistor Do not substitute a fixed resistor.
Charge enable: default OFF Program and verify limits before driving CHG_ENABLE high.
Supply flags identify the external protected pack through F2 and its return.

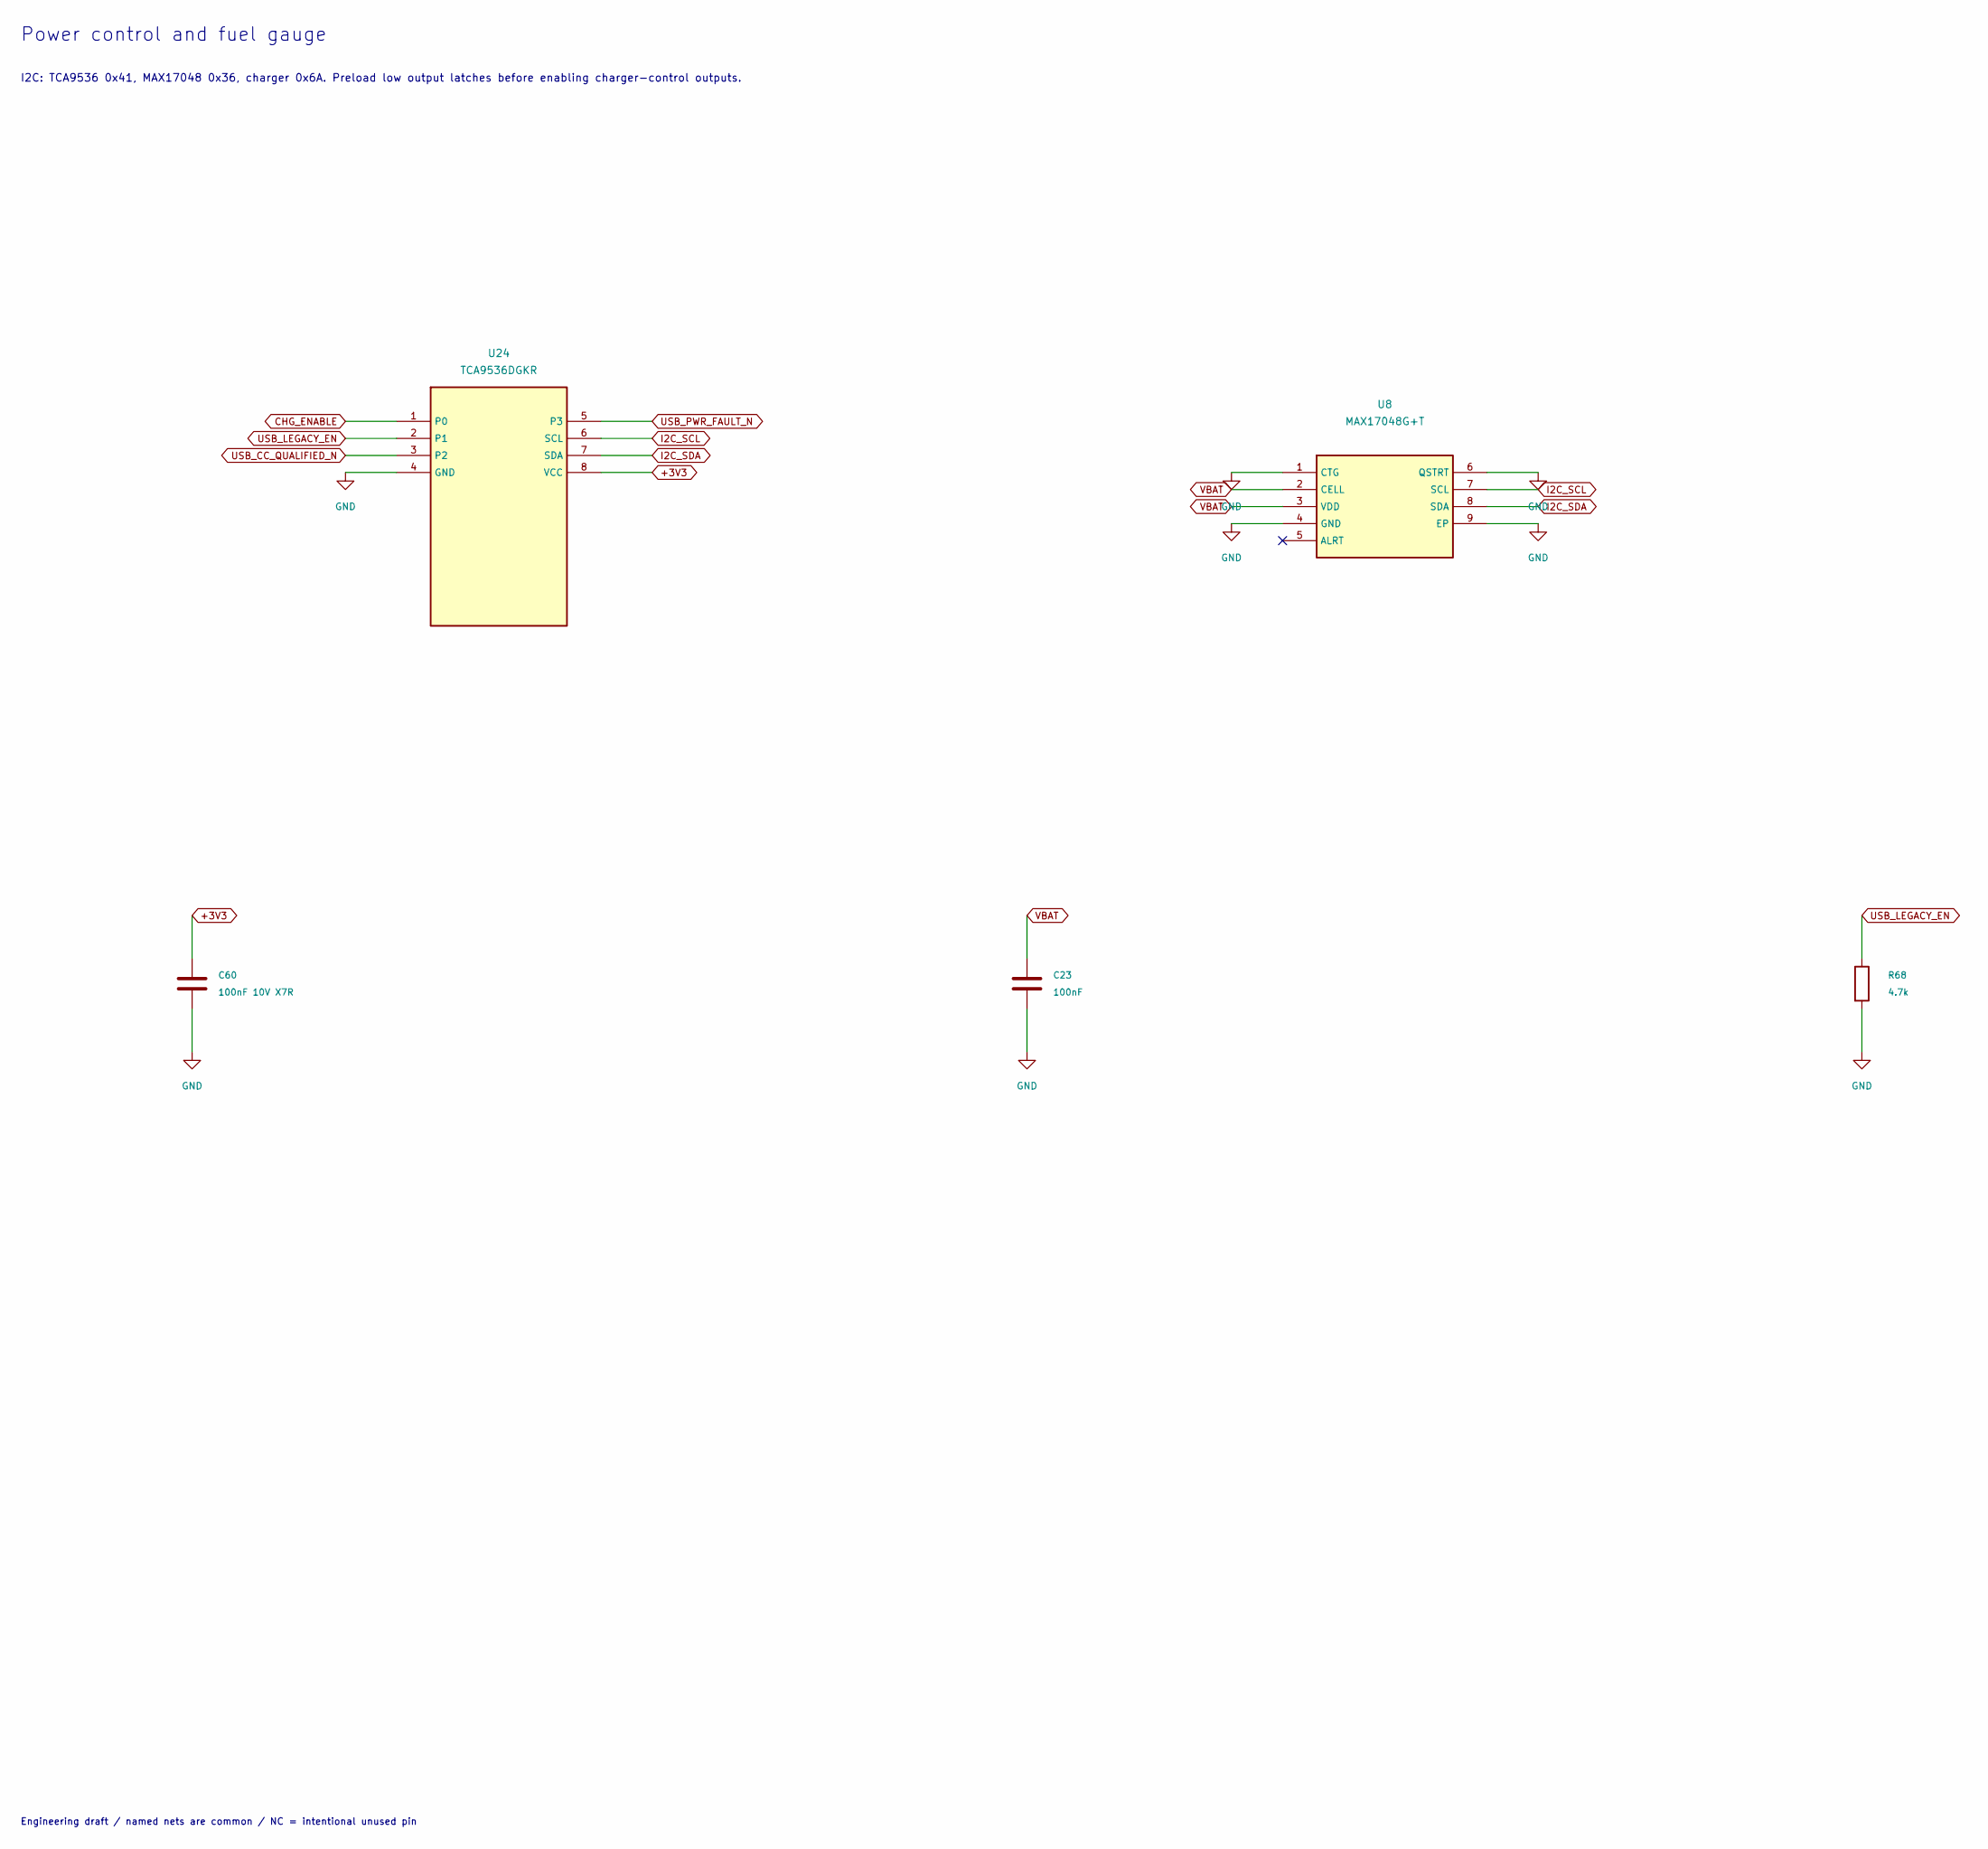
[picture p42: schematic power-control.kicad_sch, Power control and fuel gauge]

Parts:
C23: 100nF; C_0402_1005Metric
C60: 100nF 10V X7R; C_0402_1005Metric
R68: 4.7k; R_0402_1005Metric
U8: MAX17048G+T; TDFN-8-1EP_2x2mm_P0.5mm_EP0.8x1.2mm
U24: TCA9536DGKR; VSSOP-8_3x3mm_P0.65mm

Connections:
CHG_ENABLE: U24.1 (P0); also elsewhere on the board
USB_CC_QUALIFIED_N: U24.3 (P2); also elsewhere on the board
USB_LEGACY_EN: R68.1, U24.2 (P1); also elsewhere on the board
USB_PWR_FAULT_N: U24.5 (P3); also elsewhere on the board
VBAT: C23.1, U8.2 (CELL), U8.3 (VDD); also elsewhere on the board

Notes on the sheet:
Power control and fuel gauge
I2C: TCA9536 0x41, MAX17048 0x36, charger 0x6A. Preload low output latches before enabling charger-control outputs.
Engineering draft / named nets are common / NC = intentional unused pin

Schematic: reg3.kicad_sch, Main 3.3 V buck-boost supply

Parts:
C20: 10uF; C_0805_2012Metric
C21, C22: 22uF; C_0805_2012Metric
L1: XFL4020-471MEC / 0.47uH; Coilcraft_XFL4020
R30, R33: 100k; R_0402_1005Metric
R31: 560k 1%; R_0402_1005Metric
R32: 100k 1%; R_0402_1005Metric
SW19: POWER; SW_SPDT_PCM12_EdgeAssembly
U7: TPS63802DLAR; TPS63802_DLA0010A

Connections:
+3V3: C21.1, C22.1, R31.1, R33.1, U7.6 (VOUT); also elsewhere on the board
REG3_FB: R31.2, R32.1, U7.4 (FB)
REG3_L1: L1.1, U7.9 (L1)
REG3_L2: L1.2, U7.7 (L2)
REG3_PG: R33.2, U7.5 (PG)
SYS_EN: R30.1, SW19.2 (B), U7.1 (EN); also elsewhere on the board
VSYS: C20.1, SW19.1 (A), U7.10 (VIN); also elsewhere on the board

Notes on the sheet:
Main 3.3 V buck-boost supply
TPS63802 local PCB copper is routed. External distribution, effective capacitance, thermal limits and load transients remain to qualify.
Engineering draft / named nets are common / NC = intentional unused pin
0.6 V reference x (1 + 560k / 100k) = 3.3 V nominal. Feedback senses the output capacitor node; keep it clear of the switching loop.
SW19 controls SYS_EN. Battery / charger circuitry can remain energized while logic rails are off.

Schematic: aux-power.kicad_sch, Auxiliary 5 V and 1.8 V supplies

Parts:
C25, C28: 10uF; C_0805_2012Metric
C26: 22uF; C_0805_2012Metric
C27: 4.7uF; C_0603_1608Metric
L2: XFL4020-102MEC / 1uH; Coilcraft_XFL4020
L3: XFL4020-222MEC / 2.2uH; Coilcraft_XFL4020
R34: 732k 1%; R_0402_1005Metric
R35: 100k 1%; R_0402_1005Metric
U10: TPS61023DRLR; SOT-563
U11: TPS62840DLCR; VSON-8_1.5x2mm_P0.5mm

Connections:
+1V8: C28.1, L3.2, U11.8 (VOS)
+3V3: C27.1, U11.2 (VIN), U11.4 (EN); also elsewhere on the board
+5V_RF: C26.1, R34.1, U10.6 (VOUT); also elsewhere on the board
REG5_FB: R34.2, R35.1, U10.1 (FB)
REG5_SW: L2.2, U10.5 (SW)
REG18_SW: L3.1, U11.7 (SW)
SYS_EN: U10.2 (EN); also elsewhere on the board
VSYS: C25.1, L2.1, U10.3 (VIN); also elsewhere on the board

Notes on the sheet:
Auxiliary 5 V and 1.8 V supplies
Switching loops must be short in PCB layout. The 5 V rail also supplies display backlight and the LF reader.
Engineering draft / named nets are common / NC = intentional unused pin

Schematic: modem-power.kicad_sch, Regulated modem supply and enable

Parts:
C50, C51: 10uF 10V X7R; C_0805_2012Metric
C52, C53, C54: 22uF 10V X5R; C_0805_2012Metric
C55: 100nF; C_0402_1005Metric
L4: XFL4020-152MEC / 1.5uH; Coilcraft_XFL4020
Q3, Q4: AO3400A; SOT-23
R60: 374k 1%; R_0402_1005Metric
R61, R63: 100k 1%; R_0402_1005Metric
R62: 390k 1%; R_0402_1005Metric
R64: 100k; R_0402_1005Metric
U20: TPS63070RNMR; TPS63070_RNM0015A

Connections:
MODEM_DISABLE: Q3.1 (G), Q4.3 (D), R64.2
MODEM_FB: R60.2, R61.1, U20.5 (FB)
MODEM_L1: L4.1, U20.11 (L1)
MODEM_L2: L4.2, U20.9 (L2)
MODEM_REG_EN: Q3.3 (D), R62.2, R63.1, U20.14 (EN)
MODEM_SUPPLY: C52.1, C53.1, C54.1, R60.1, U20.7 (VOUT), U20.8 (VOUT); also elsewhere on the board
MODEM_VAUX: C55.1, U20.3 (VAUX)
SYS_EN: Q4.1 (G); also elsewhere on the board
VBAT: C50.1, C51.1, R62.1, R64.1, U20.12 (VIN), U20.13 (VIN); also elsewhere on the board

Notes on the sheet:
Regulated modem supply and enable
Nominal output 3.792 V. Exact modem burst current and MakerFocus pack current budget are unresolved release blockers.
Engineering draft / named nets are common / NC = intentional unused pin

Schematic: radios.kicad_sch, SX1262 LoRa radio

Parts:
C8, C75, C76, C94: 100nF 10% X7R 16V; C_0402_1005Metric; MPN GRM155R71C104KA88D
C9: 470nF 10% X5R 10V; C_0402_1005Metric; MPN GRM155R61A474KE15D
C10: 100nF; C_0402_1005Metric
C95: 10pF 5% C0G 50V; C_0402_1005Metric; MPN GRM1555C1H100JA01D
J20: LORA_915_ANT; U.FL_Hirose_U.FL-R-SMT-1_Vertical
L12: 15uH 20%; L_TDK_MLZ2012_h1.25mm; MPN MLZ2012M150WT000
R10: 10k; R_0402_1005Metric
R90: 220R 1%; R_0402_1005Metric; MPN RC0402FR-07220RL
U4: SX1262IMLTRT; QFN-24-1EP_4x4mm_P0.5mm_EP2.6x2.6mm
Y3: 32MHz TCXO 0.5ppm temp; ECS_TXO_32CSMV_3225; MPN ECS-TXO-32CSMV-320-AN-TR

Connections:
+3V3: C8.1, C75.1, C76.1, R10.1, U4.1 (VDD_IN), U4.10 (VBAT), U4.11 (VBAT_IO); also elsewhere on the board
LORA_RF_50R: J20.1 (In)
SPI_MISO: U4.16 (MISO); also elsewhere on the board
SPI_MOSI: U4.17 (MOSI); also elsewhere on the board
SPI_SCK: U4.18 (SCK); also elsewhere on the board
SX_BUSY: U4.14 (BUSY); also elsewhere on the board
SX_CS: R10.2, U4.19 (NSS); also elsewhere on the board
SX_DCC_SW: L12.1, U4.9 (DCC_SW)
SX_DIO1: U4.13 (DIO1); also elsewhere on the board
SX_RESET: U4.15 (~RESET); also elsewhere on the board
SX_RFI_N: U4.22 (RFI_N)
SX_RFI_P: U4.21 (RFI_P)
SX_RFO: U4.23 (RFO)
SX_RF_SW: U4.12 (DIO2)
SX_TCXO_COUPLED: C95.1, R90.2
SX_TCXO_OUT: R90.1, Y3.3 (OUT)
SX_TCXO_PWR: C94.1, U4.6 (DIO3), Y3.4 (VDD)
SX_VREG: C9.1, L12.2, U4.7 (VREG)
SX_VR_PA: C10.1, U4.24 (VR_PA)
SX_XTA: C95.2, U4.3 (XTA)

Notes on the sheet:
SX1262 LoRa radio
SX1262 core supply and DIO3-controlled TCXO captured. RF frontend remains incomplete; do not power.
Engineering draft / named nets are common / NC = intentional unused pin
C8: VBAT pin10. C75: VDD_IN pin1. C76: VBAT_IO pin11. All use the same +3V3 rail; place each close to its pin. C9 replaces the incorrect 100nF with Semtech reference 470nF.
SetRegulatorMode(0x01) only in STDBY_RC, after hardware qualification. L12 supplies the core, not the SX1262 high-power PA. PA feed, matching/filter and RF switch are still missing. C10 PA bypass and J20 antenna connection remain provisional.
Y3 pads 1/2 = GND, 3 = OUT, 4 = VDD. XTB is intentionally NC. Configure DIO3 for 1.8V; provisional startup allowance 5ms. Confirm TCXO output <=1.2Vpp; no qualified maximum in series data.

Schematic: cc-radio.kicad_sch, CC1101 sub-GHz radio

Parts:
C11, C12: 100nF 10% X7R 16V; C_0402_1005Metric
C61, C62: 15pF 5% C0G 50V; C_0402_1005Metric; MPN GRM1555C1H150JA01D
C63: 1pF 0.25pF C0G 50V; C_0402_1005Metric; MPN GRM1555C1H1R0CA01D
C64, C68: 1.5pF 0.25pF C0G 50V; C_0402_1005Metric; MPN GRM1555C1H1R5CA01D
C65: 3.3pF 0.25pF C0G 50V; C_0402_1005Metric; MPN GRM1555C1H3R3CA01D
C66: 100pF 5% C0G 50V; C_0402_1005Metric; MPN GRM1555C1H101JA01D
C67: 12pF 5% C0G 50V; C_0402_1005Metric; MPN GRM1555C1H120JA01D
C69, C70, C71, C72, C73: 100nF 10% X7R 16V; C_0402_1005Metric; MPN GRM155R71C104KA88D
C74: 1uF 10% X5R 10V; C_0402_1005Metric; MPN GRM155R61A105KE15D
J21: CC1101_915_ANT; U.FL_Hirose_U.FL-R-SMT-1_Vertical
L5, L6, L9, L10: 12nH 5%; L_0402_1005Metric; MPN LQW15AN12NJ00D
L7, L8: 18nH 5%; L_0402_1005Metric; MPN LQW15AN18NJ00D
L11: 1kohm @100MHz; L_0402_1005Metric; MPN BLM15HG102SN1D
R11: 56k 1%; R_0402_1005Metric
R12: 10k; R_0402_1005Metric
TP1: CC_GDO2_TEST; TestPoint_Pad_D1.0mm; MPN PCB_PAD
U5: CC1101RGPR; Texas_RGP0020D_VQFN-20-1EP_4x4mm_P0.5mm_EP2.7x2.7mm
Y2: 26MHz CL10pF; ABM8_3225; MPN ABM8-26.000MHZ-10-D-1-G-T

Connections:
+3V3: L11.1, R12.1; also elsewhere on the board
CC_BAL_N: C63.2, C68.1, L6.2, L8.1
CC_BAL_P: C63.1, C64.1, L5.2, L7.1
CC_CS: R12.2, U5.7 (CS_N); also elsewhere on the board
CC_DCOUPL: C11.1, U5.5 (DCOUPL)
CC_DC_BLOCK: C67.1, L10.2
CC_GDO0: U5.6 (GDO0); also elsewhere on the board
CC_GDO2: TP1.1, U5.3 (GDO2)
CC_LPF: C65.1, L9.2, L10.1
CC_MATCH: C64.2, L8.2, L9.1
CC_RBIAS: R11.1, U5.17 (RBIAS)
CC_RF_50R: C67.2, J21.1 (In)
CC_RF_N: L6.1, U5.13 (RF_N)
CC_RF_P: L5.1, U5.12 (RF_P)
CC_SHUNT: C66.1, L7.2
CC_VDD: C12.1, C69.1, C70.1, C71.1, C72.1, C73.1, C74.1, L11.2, U5.4 (DVDD), U5.9 (AVDD), U5.11 (AVDD), U5.14 (AVDD), U5.15 (AVDD), U5.18 (DGUARD)
CC_X1: C61.1, U5.8 (XOSC_Q1), Y2.1
CC_X2: C62.1, U5.10 (XOSC_Q2), Y2.3
SPI_MISO: U5.2 (SO); also elsewhere on the board
SPI_MOSI: U5.20 (SI); also elsewhere on the board
SPI_SCK: U5.1 (SCLK); also elsewhere on the board

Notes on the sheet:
CC1101 sub-GHz radio
868/915MHz frontend: TI SWRR045 rev3.0 / SWRS061I Fig11. RF layout and tuning are NOT qualified. Separate 50-ohm antenna.
Engineering draft / named nets are common / NC = intentional unused pin
CC_VDD flag: main +3V3 through passive L11; not an independent source. Place one 100nF at each supply pin group, plus local 1uF bulk.
Y2: ABM8-26.000MHZ-10-D-1-G-T CL = 15pF / 2 + estimated 2.5pF stray = 10pF. Measure oscillator frequency, startup and drive level.
C126/L125 optional notch from TI reference is omitted. Determine need by final conducted emissions. No 315/433MHz matching claim. GDO2 is a debug pad; set IOCFG2=0x2E when unused.

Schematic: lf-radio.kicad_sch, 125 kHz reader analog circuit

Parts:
C24: 100nF; C_0402_1005Metric
J10: LF_COIL_TUNING_REQUIRED; JST_GH_BM02B-GHS-TBT_1x02-1MP_P1.25mm_Vertical
U9: HTRC11001T; SOIC-14_3.9x8.7mm_P1.27mm

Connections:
+5V_RF: C24.1, U9.3 (VDD); also elsewhere on the board
LF_CEXT: U9.12 (CEXT)
LF_CLK_5V: U9.8 (SCLK); also elsewhere on the board
LF_COIL_A: J10.1
LF_COIL_B: J10.2
LF_DIN_5V: U9.9 (DIN); also elsewhere on the board
LF_DOUT_5V: U9.10 (DOUT); also elsewhere on the board
LF_QGND: U9.13 (QGND)
LF_RX: U9.14 (RX)
LF_TX1: U9.4 (TX1)
LF_TX2: U9.2 (TX2)
LF_X1: U9.6 (XTAL1)
LF_X2: U9.7 (XTAL2)

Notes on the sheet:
125 kHz reader analog circuit
HTRC110 requires its oscillator, QGND/CEXT bypass, resonant coil network and a timing-capable host interface.
Engineering draft / named nets are common / NC = intentional unused pin

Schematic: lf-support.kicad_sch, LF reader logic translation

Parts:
C45, C46: 100nF; C_0402_1005Metric
R50, R51: 100k; R_0402_1005Metric
U18: SN74AHCT125PWR; TSSOP-14_4.4x5mm_P0.65mm
U19: SN74LVC1G17DBVR; SOT-23-5

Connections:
+3V3: C46.1, U19.5 (VCC); also elsewhere on the board
+5V_RF: C45.1, U18.10 (OE3_N), U18.13 (OE4_N), U18.14 (VCC); also elsewhere on the board
LF_CLK_5V: U18.3 (Y1); also elsewhere on the board
LF_DIN_5V: U18.6 (Y2); also elsewhere on the board
LF_DOUT_5V: U19.2; also elsewhere on the board
RFID_CLK: R50.1, U18.2 (A1); also elsewhere on the board
RFID_DIN: R51.1, U18.5 (A2); also elsewhere on the board
RFID_DOUT_3V3: U19.4

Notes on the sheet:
LF reader logic translation
AHCT inputs accept 3.3 V logic at 5 V supply; LVC return buffer is powered at 3.3 V. Host timing remains a design requirement.
Engineering draft / named nets are common / NC = intentional unused pin

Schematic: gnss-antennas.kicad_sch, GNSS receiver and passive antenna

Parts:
C29: 100nF; C_0402_1005Metric
C30: 1uF; C_0402_1005Metric
J22: GNSS_PASSIVE_ANT; U.FL_Hirose_U.FL-R-SMT-1_Vertical
U12: MAX-M10S-00B-01; ublox_MAX

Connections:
+3V3: C29.1, C30.1, U12.7 (VCC_IO), U12.8 (VCC); also elsewhere on the board
GPS_HOST_RX: U12.2 (TXD); also elsewhere on the board
GPS_HOST_TX: U12.3 (RXD); also elsewhere on the board
GPS_PPS: U12.4 (TIMEPULSE); also elsewhere on the board
GPS_RF: J22.1 (In), U12.11 (RF_IN)

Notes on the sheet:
GNSS receiver and passive antenna
MAX-M10S passive antenna. V_BCKP remains open: cold starts after power removal. No direct LiPo connection.
Engineering draft / named nets are common / NC = intentional unused pin

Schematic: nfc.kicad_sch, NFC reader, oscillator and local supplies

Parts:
C31: 100nF; C_0402_1005Metric
C32, C33, C34, C35: 2.2uF; C_0603_1608Metric
C36: 10nF; C_0402_1005Metric
C37: 1uF; C_0402_1005Metric
C38, C39: 27pF C0G; C_0402_1005Metric
R40: 10k; R_0402_1005Metric
U13: ST25R3916B-AQET; VQFN-32-1EP_5x5mm_P0.5mm_EP3.5x3.5mm
Y1: ABM8-27.120MHZ-B2-T; Crystal_SMD_3225-4Pin_3.2x2.5mm

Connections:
+3V3: C31.1, C37.1, R40.1, U13.1 (VDD_IO), U13.8 (VDD), U13.10 (VDD_TX); also elsewhere on the board
NFC_AGDC: C36.1, U13.24 (AGDC)
NFC_CS: R40.2, U13.29 (BSS); also elsewhere on the board
NFC_IRQ: U13.27 (IRQ); also elsewhere on the board
NFC_RFI1: U13.22 (RFI1)
NFC_RFI2: U13.23 (RFI2)
NFC_RFO1: U13.13 (RFO1)
NFC_RFO2: U13.15 (RFO2)
NFC_VDD_A: C33.1, U13.7 (VDD_A)
NFC_VDD_AM: C35.1, U13.11 (VDD_AM)
NFC_VDD_D: C32.1, U13.3 (VDD_D)
NFC_VDD_RF: C34.1, U13.9 (VDD_RF), U13.14 (VDD_DR)
NFC_XTI: C38.1, U13.5 (XTI), Y1.1
NFC_XTO: C39.1, U13.4 (XTO), Y1.3
SPI_MISO: U13.32 (MISO); also elsewhere on the board
SPI_MOSI: U13.31 (MOSI); also elsewhere on the board
SPI_SCK: U13.30 (SCLK); also elsewhere on the board

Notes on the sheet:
NFC reader, oscillator and local supplies
ST25R3916B needs a tuned case-mounted loop and TX/RX matching network. Verify crystal load against the selected crystal.
Engineering draft / named nets are common / NC = intentional unused pin

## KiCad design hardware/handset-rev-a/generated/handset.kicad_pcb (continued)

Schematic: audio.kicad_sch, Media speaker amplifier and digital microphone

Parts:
C13, C15: 100nF; C_0402_1005Metric
C14: 10uF; C_0805_2012Metric
J3: MEDIA_SPEAKER_DIFFERENTIAL; JST_GH_BM02B-GHS-TBT_1x02-1MP_P1.25mm_Vertical
MK1: SPH0645LM4H-1; Knowles_SPH0645LM4H-6_3.5x2.65mm
R13: 100k; R_0402_1005Metric
U6: MAX98357AETE+; TQFN-16-1EP_3x3mm_P0.5mm_EP1.23x1.23mm

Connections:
+3V3: C13.1, C14.1, C15.1, MK1.5 (VDD), U6.7 (VDD), U6.8 (VDD); also elsewhere on the board
I2S_BCLK: MK1.4 (BCLK), U6.16 (BCLK); also elsewhere on the board
I2S_DIN: MK1.6 (DATA); also elsewhere on the board
I2S_DOUT: U6.1 (DIN); also elsewhere on the board
I2S_LRCLK: MK1.1 (WS), U6.14 (LRCLK); also elsewhere on the board
MEDIA_EN: R13.1, U6.4 (~SD_MODE); also elsewhere on the board
SPK_N: J3.2, U6.10 (OUTN)
SPK_P: J3.1, U6.9 (OUTP)

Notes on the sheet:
Media speaker amplifier and digital microphone
Top-mounted media speaker uses differential outputs: neither speaker wire is ground. Digital microphone is case-bottom mounted.
Engineering draft / named nets are common / NC = intentional unused pin

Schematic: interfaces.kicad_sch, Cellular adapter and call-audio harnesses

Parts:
J4: CALL_AUDIO_FROM_MODEM_ADAPTER; JST_GH_BM04B-GHS-TBT_1x04-1MP_P1.25mm_Vertical
J5: CALL_EARPIECE; JST_GH_BM02B-GHS-TBT_1x02-1MP_P1.25mm_Vertical
J6: CALL_MIC; JST_GH_BM02B-GHS-TBT_1x02-1MP_P1.25mm_Vertical
J8: MODEM_ADAPTER_3V3_LOGIC; JST_GH_BM06B-GHS-TBT_1x06-1MP_P1.25mm_Vertical
J9: MODEM_POWER_ADAPTER_REQUIRED; JST_GH_BM04B-GHS-TBT_1x04-1MP_P1.25mm_Vertical

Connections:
CALL_MIC_N: J4.4, J6.2
CALL_MIC_P: J4.3, J6.1
CALL_SPK_N: J4.2, J5.2
CALL_SPK_P: J4.1, J5.1
LTE_HOST_RX: J8.3; also elsewhere on the board
LTE_HOST_TX: J8.2; also elsewhere on the board
LTE_ON: J8.4; also elsewhere on the board
MODEM_STATUS: J8.6
MODEM_SUPPLY: J9.1, J9.3; also elsewhere on the board

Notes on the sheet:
Cellular adapter and call-audio harnesses
Replaceable modem adapter owns SIM, cellular RF and modem-level translation. No universal-carrier guarantee. Speaker top / mic bottom.
Engineering draft / named nets are common / NC = intentional unused pin

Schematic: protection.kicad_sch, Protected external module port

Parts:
C40: 100nF; C_0402_1005Metric
C41: 10uF; C_0805_2012Metric
J16: EXPANSION_J16; JST_GH_BM10B-GHS-TBT_1x10-1MP_P1.25mm_Vertical
R20, R21, R22, R23, R24, R25, R26: 33; R_0402_1005Metric
R41: 100k 1%; R_0402_1005Metric
R42: 10k 1%; R_0402_1005Metric; MPN RC0402FR-0710KL
U14: TPS2553DBVR; SOT-23-6
U15, U16: TPD4E05U06DQAR; USON-10_2.5x1.0mm_P0.5mm

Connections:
+3V3: C40.1, R42.1, U14.1 (IN); also elsewhere on the board
EXP_3V3: C41.1, J16.2, U14.6 (OUT); also elsewhere on the board
EXP_CS_PORT: J16.8, R25.2, U16.2 (D1-)
EXP_FAULT_N: R42.2, U14.4 (FAULT_N); also elsewhere on the board
EXP_ILIM: R41.1, U14.5 (ILIM)
EXP_IRQ_PORT: J16.9, R26.2, U16.4 (D2+)
EXP_MISO: J16.7, R24.2, U16.1 (D1+)
EXP_MOSI: J16.6, R23.2, U15.5 (D2-)
EXP_PWR_EN: U14.3 (EN); also elsewhere on the board
EXP_SCK: J16.5, R22.2, U15.4 (D2+)
EXP_SCL: J16.3, R20.2, U15.1 (D1+)
EXP_SDA: J16.4, R21.2, U15.2 (D1-)
EXP_SW_CS: R25.1; also elsewhere on the board
EXP_SW_IRQ: R26.1; also elsewhere on the board
EXP_SW_MISO: R24.1; also elsewhere on the board
EXP_SW_MOSI: R23.1; also elsewhere on the board
EXP_SW_SCK: R22.1; also elsewhere on the board
EXP_SW_SCL: R20.1; also elsewhere on the board
EXP_SW_SDA: R21.1; also elsewhere on the board

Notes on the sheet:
Protected external module port
Port signals pass through U34 on expansion-control. U14 EN defaults low; fault drives U33 and the hardware signal interlock. No hot-plug approval.
Engineering draft / named nets are common / NC = intentional unused pin

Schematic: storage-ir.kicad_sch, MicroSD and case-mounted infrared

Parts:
C42: 100nF; C_0402_1005Metric
C43: 10uF; C_0805_2012Metric
C44: 1uF; C_0402_1005Metric
J23: DM3D-SF; microSD_HC_Hirose_DM3D-SF
J24: TSAL6400_CASE_LED; JST_GH_BM02B-GHS-TBT_1x02-1MP_P1.25mm_Vertical
J25: TSOP38438_CASE_RX; JST_GH_BM03B-GHS-TBT_1x03-1MP_P1.25mm_Vertical
Q1: AO3400A; SOT-23
R43, R44, R45: 47k; R_0402_1005Metric
R46, R49: 100; R_0402_1005Metric
R47: 100k; R_0402_1005Metric
R48: 47 1% 0.125W; R_0805_2012Metric

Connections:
+3V3: C42.1, C43.1, J23.4 (VDD), R43.1, R44.1, R45.1, R48.1, R49.1; also elsewhere on the board
IR_GATE: Q1.1 (G), R46.2, R47.1
IR_LED_A: J24.1, R48.2
IR_LED_K: J24.2, Q1.3 (D)
IR_RX: J25.1; also elsewhere on the board
IR_RX_VCC: C44.1, J25.3, R49.2
IR_TX: R46.1; also elsewhere on the board
SD_CS: J23.2 (DAT3/CD), R44.2; also elsewhere on the board
SD_DAT1: J23.8 (DAT1), R45.2
SD_DAT2: J23.1 (DAT2), R43.2
SPI_MISO: J23.7 (DAT0); also elsewhere on the board
SPI_MOSI: J23.3 (CMD); also elsewhere on the board
SPI_SCK: J23.5 (CLK); also elsewhere on the board

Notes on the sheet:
MicroSD and case-mounted infrared
SPI microSD, transistor-driven IR LED, filtered receiver supply. Confirm case LED/receiver polarity and GPIO3 boot behavior.
Engineering draft / named nets are common / NC = intentional unused pin

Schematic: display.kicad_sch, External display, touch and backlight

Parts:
C47: 100nF; C_0402_1005Metric
C48: 4.7uF; C_0603_1608Metric
C49: 10uF; C_0805_2012Metric
C90: 1uF 10% X7R 25V; C_0603_1608Metric; MPN GRM188R71E105KA12D
J26: FH12A-50S-0.5SH(55); FH12A-50S-0.5SH_TopContact
R56: 100; R_0402_1005Metric
R57: 100k; R_0402_1005Metric
R58, R59: 10k; R_0402_1005Metric
R82: 4.99k 1%; R_0402_1005Metric; MPN RC0402FR-074K99L
U32: CAT4004AHU2-GT3; CAT4004A_UDFN-8_2x2mm_P0.5mm_EP1x1.73mm; MPN CAT4004AHU2-GT3

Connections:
+3V3: R58.1, R59.1; also elsewhere on the board
+5V_RF: C49.1, C90.1, J26.1, U32.8 (VIN); also elsewhere on the board
IR_RX: R59.2; also elsewhere on the board
LCD_3V0: C47.1, C48.1, J26.7, J26.8, J26.9, J26.35, J26.40, J26.41, J26.42; also elsewhere on the board
LCD_BL_EN: R56.1; also elsewhere on the board
LCD_BL_GATE: R56.2, R57.1, U32.1 (EN/DIM)
LCD_BL_RSET: R82.1, U32.7 (RSET)
LCD_CS: R58.2; also elsewhere on the board
LCD_K1: J26.2, U32.3 (LED1)
LCD_K2: J26.3, U32.4 (LED2)
LCD_K3: J26.4, U32.5 (LED3)
LCD_K4: J26.5, U32.6 (LED4)
PANEL_I2C_SCL: J26.44; also elsewhere on the board
PANEL_I2C_SDA: J26.45; also elsewhere on the board
PANEL_LCD_CS: J26.38; also elsewhere on the board
PANEL_LCD_DC: J26.36; also elsewhere on the board
PANEL_LCD_RESET: J26.10; also elsewhere on the board
PANEL_SPI_MISO: J26.33; also elsewhere on the board
PANEL_SPI_MOSI: J26.34; also elsewhere on the board
PANEL_SPI_SCK: J26.37; also elsewhere on the board
PANEL_TOUCH_IRQ: J26.46; also elsewhere on the board
PANEL_TOUCH_RESET: J26.47; also elsewhere on the board

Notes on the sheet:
External display, touch and backlight
CAT4004A: four current sinks, 4.99k sets approx. 15mA/channel. On/off only until dimming timing is qualified. Do not fabricate.
Engineering draft / named nets are common / NC = intentional unused pin
EN/DIM: external R57 pull-down retains default off. Initialize U2 GPIO low for >=10ms before enabling. Keep high for full-scale current; do not apply ordinary PWM. RSET gain, current drift, heat and purchased panel remain unqualified.

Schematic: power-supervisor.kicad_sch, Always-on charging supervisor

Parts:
C77, C78, C80: 4.7uF 10% X5R 25V; C_0603_1608Metric; MPN GRM188R61E475KE11D
C79, C81, C82, C83: 100nF 10% X7R 16V; C_0402_1005Metric; MPN GRM155R71C104KA88D
R76, R77, R78: 10k 1%; R_0402_1005Metric; MPN RC0402FR-0710KL
TP2: PWR_AON_3V0; TestPoint_Pad_D1.0mm; MPN PCB copper
TP3: GND; TestPoint_Pad_D1.0mm; MPN PCB copper
TP4: PWR_SWDIO; TestPoint_Pad_D1.0mm; MPN PCB copper
TP5: PWR_SWCLK; TestPoint_Pad_D1.0mm; MPN PCB copper
TP6: PWR_NRST; TestPoint_Pad_D1.0mm; MPN PCB copper
U25: STM32G031G8U6; QFN-28_4x4mm_P0.5mm; MPN STM32G031G8U6
U26: TPS7A0230PDBVR; SOT-23-5; MPN TPS7A0230PDBVR
U27: TCA9800DGKR; VSSOP-8_3x3mm_P0.65mm; MPN TCA9800DGKR

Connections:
+3V3: C81.1, U27.1 (VCCA), U27.5 (EN); also elsewhere on the board
CHG_ARM: U25.6 (PA0); also elsewhere on the board
PWR_HOST_SCL: U25.18 (PA9/PA11), U27.7 (SCLB)
PWR_HOST_SDA: U25.19 (PA10/PA12), U27.6 (SDAB)
PWR_NRST: C83.1, R78.2, TP6.1, U25.5 (PF2)
PWR_SWCLK: TP5.1, U25.21 (PA14)
PWR_SWDIO: TP4.1, U25.20 (PA13)
VSYS: C77.1, U26.1 (VIN), U26.3 (EN); also elsewhere on the board

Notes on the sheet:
Always-on charging supervisor
Separate supervisor selected. U3 remains the charger. Main host powers off at SW19. Circuit capture only; routing, STM32 firmware and fault qualification pending.
Engineering draft / named nets are common / NC = intentional unused pin
I2C1: PB8/PB7 AF6 -> charger 0x6A + expander 0x41. I2C2: remap PA9/PA10 to PA11/PA12, AF6. Host slave address 0x42 reserved; protocol not implemented.
TCA9800 B side: NO external/internal MCU pull-ups. A-side pull-ups are on switched +3V3. EN follows +3V3. Debug VTREF is sense only; never power from debugger.
PA0: dedicated active-high charge arm. Reset analog/high-Z allows R79 at Q8 to hold charging disabled independently of U24. Never retain this output through standby or run bootloader while armed.

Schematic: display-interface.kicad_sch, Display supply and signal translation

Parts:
C84, C85: 4.7uF 10% X5R 25V; C_0603_1608Metric; MPN GRM188R61E475KE11D
C86, C87, C88, C89: 100nF 10% X7R 16V; C_0402_1005Metric; MPN GRM155R71C104KA88D
R80, R81: 100k 1%; R_0402_1005Metric; MPN RC0402FR-07100KL
U28: TPS7A2030PDBVR; SOT-23-5; MPN TPS7A2030PDBVR
U29: SN74LVC244APWR; TSSOP-20_4.4x6.5mm_P0.65mm; MPN SN74LVC244APWR
U30: SN74LVC2G125DCUR; VSSOP-8_2.3x2mm_P0.5mm; MPN SN74LVC2G125DCUR
U31: TCA9406DCUR; VSSOP-8_2.3x2mm_P0.5mm; MPN TCA9406DCUR

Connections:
+3V3: C87.1, C89.1, U30.8 (VCC), U31.7 (VCCB); also elsewhere on the board
+5V_RF: C84.1, U28.1 (IN); also elsewhere on the board
LCD_3V0: C85.1, C86.1, C88.1, R81.1, U28.5 (OUT), U29.20 (VCC), U31.3 (VCCA), U31.6 (OE); also elsewhere on the board
LCD_CS: U29.6 (1A3), U30.1 (~1OE); also elsewhere on the board
LCD_DC: U29.8 (1A4); also elsewhere on the board
LCD_RESET: U29.11 (2A1); also elsewhere on the board
PANEL_I2C_SCL: U31.5 (SCL_A); also elsewhere on the board
PANEL_I2C_SDA: U31.4 (SDA_A); also elsewhere on the board
PANEL_LCD_CS: U29.14 (1Y3); also elsewhere on the board
PANEL_LCD_DC: U29.12 (1Y4); also elsewhere on the board
PANEL_LCD_RESET: U29.9 (2Y1); also elsewhere on the board
PANEL_SPI_MISO: R80.1, U30.2 (1A); also elsewhere on the board
PANEL_SPI_MOSI: U29.16 (1Y2); also elsewhere on the board
PANEL_SPI_SCK: U29.18 (1Y1); also elsewhere on the board
PANEL_TOUCH_IRQ: R81.2, U30.5 (2A); also elsewhere on the board
PANEL_TOUCH_RESET: U29.7 (2Y2); also elsewhere on the board
SPI_MISO: U30.6 (1Y); also elsewhere on the board
SPI_MOSI: U29.4 (1A2); also elsewhere on the board
SPI_SCK: U29.2 (1A1); also elsewhere on the board
SYS_EN: U28.3 (EN); also elsewhere on the board
TOUCH_IRQ: U30.3 (2Y); also elsewhere on the board
TOUCH_RESET: U29.13 (2A2); also elsewhere on the board

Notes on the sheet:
Display supply and signal translation
Interface routed and continuity checked. Qualify loads, timing, startup and case cable. Do not fabricate.
Engineering draft / named nets are common / NC = intentional unused pin
U29: 3.3 V tolerant inputs; outputs use LCD_3V0. U30: MISO OE follows host LCD_CS; IRQ buffer always enabled. U31: internal pull-ups; verify bus capacitance and touch option. U28: 5 V input provides headroom; qualify load and heat.

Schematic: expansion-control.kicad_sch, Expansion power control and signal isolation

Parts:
C91, C92, C93: 100nF 10% X7R 16V; C_0402_1005Metric; MPN GRM155R71C104KA88D
R83, R84: 4.7k 1%; R_0402_1005Metric; MPN RC0402FR-074K7L
R85: 100k 1%; R_0402_1005Metric; MPN RC0402FR-07100KL
R86: 220k 1%; R_0402_1005Metric; MPN RC0402FR-07220KL
R87: 10k 1%; R_0402_1005Metric; MPN RC0402FR-0710KL
U33: TCA9537DGSR; MSOP-10_3x3mm_P0.5mm; MPN TCA9537DGSR
U34: SN74CB3Q3245PWR; TSSOP-20_4.4x6.5mm_P0.65mm; MPN SN74CB3Q3245PWR
U35: SN74HCS10PWR; TSSOP-14_4.4x5mm_P0.65mm; MPN SN74HCS10PWR

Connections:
+3V3: C91.1, C92.1, C93.1, R86.1, U33.10 (VCC), U34.20 (VCC), U35.14 (VCC); also elsewhere on the board
EXP_3V3: R87.1; also elsewhere on the board
EXP_CS: U34.7 (A6); also elsewhere on the board
EXP_FAULT_N: U33.2 (P1), U35.13 (1C); also elsewhere on the board
EXP_GPIO_SPARE: R85.1, U33.4 (P3)
EXP_IO_ARM: R84.1, U33.3 (P2), U35.2 (1B)
EXP_IO_OE_N: R86.2, U34.19 (~OE), U35.12 (1Y)
EXP_IRQ: U34.8 (A7); also elsewhere on the board
EXP_PWR_EN: R83.1, U33.1 (P0), U35.1 (1A); also elsewhere on the board
EXP_SW_CS: U34.13 (B6); also elsewhere on the board
EXP_SW_IRQ: U34.12 (B7); also elsewhere on the board
EXP_SW_MISO: U34.14 (B5); also elsewhere on the board
EXP_SW_MOSI: U34.15 (B4); also elsewhere on the board
EXP_SW_SCK: U34.16 (B3); also elsewhere on the board
EXP_SW_SCL: U34.18 (B1); also elsewhere on the board
EXP_SW_SDA: U34.17 (B2); also elsewhere on the board
MCU_EN: U33.6 (~RESET); also elsewhere on the board
SPI_MISO: U34.6 (A5); also elsewhere on the board
SPI_MOSI: U34.5 (A4); also elsewhere on the board
SPI_SCK: U34.4 (A3); also elsewhere on the board

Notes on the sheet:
Expansion power control and signal isolation
TCA9537 0x49: P0 power, P1 fault, P2 IO arm, P3 unused input. MCU_EN low resets all ports to inputs. External pull-downs retain OFF.
Engineering draft / named nets are common / NC = intentional unused pin
U35: /OE = NOT (EXP_PWR_EN AND EXP_IO_ARM AND EXP_FAULT_N). Initialize output latch to 0xF0 before direction 0xFA. Power-only 0xF1; armed 0xF5. Fault is polled; no MCU GPIO/strap changes. A stuck host I2C bus requires hardware reset. No rail-good sensor: qualify load/startup and share buses only af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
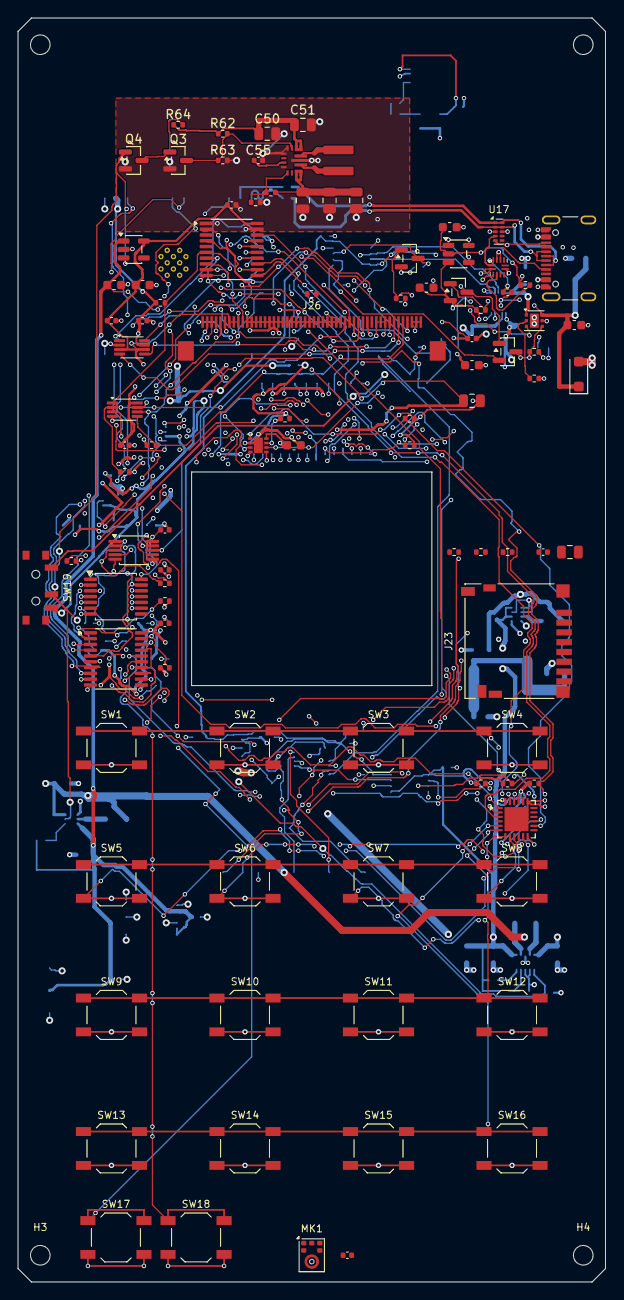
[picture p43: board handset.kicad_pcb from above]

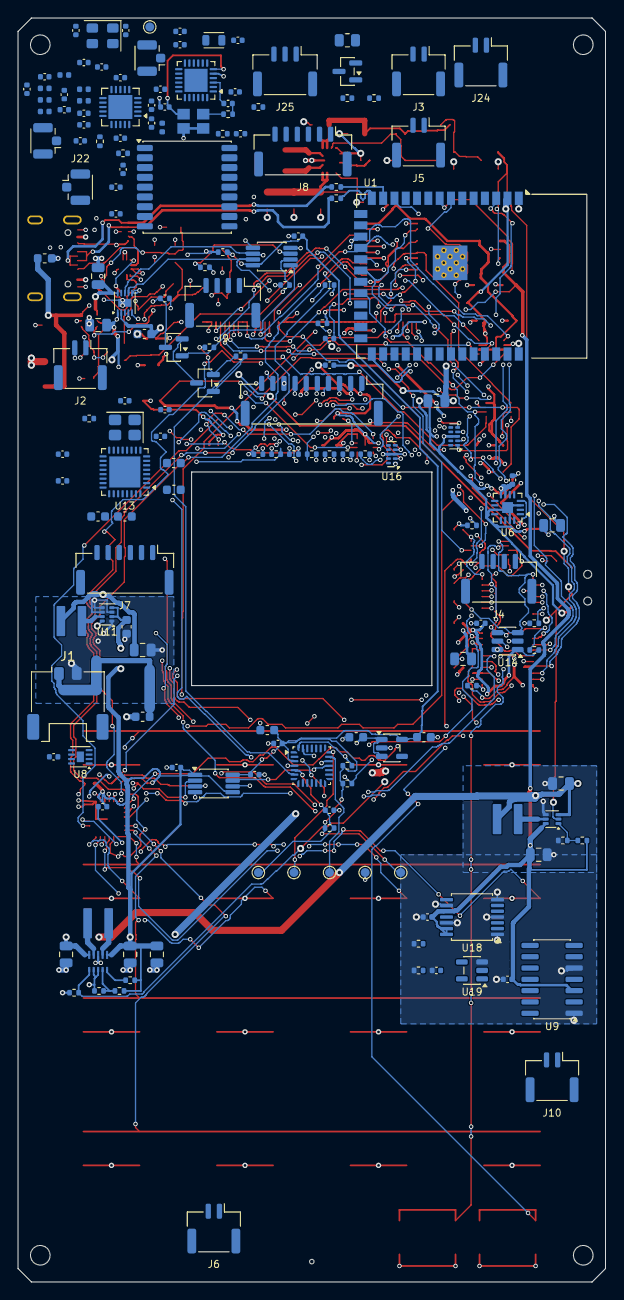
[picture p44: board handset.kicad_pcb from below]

Board: 4 copper layers, 66.0 x 142.0 mm, 269 parts (168 on the bottom side), 184 nets.

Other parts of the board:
H1, H2, H3, H4: MountingHole_2.2mm_M2
Q8: AO3400A; SOT-23
R79: 4.7k 1%; R_0402_1005Metric
R88, R89: 22 1%; R_0402_1005Metric

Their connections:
CHG_ARM: Q8.1, R79.1; also elsewhere on the board
USB_HOST_D_N: R88.1; also elsewhere on the board
USB_HOST_D_P: R89.1; also elsewhere on the board

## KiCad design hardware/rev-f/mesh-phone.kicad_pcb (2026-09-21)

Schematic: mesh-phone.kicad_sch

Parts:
C1: 1000uF-MODEM-BULK; C_1206_3216Metric
C2: 100uF-VBAT-BULK; C_1206_3216Metric
C3: 10uF-3V3-BULK; C_1206_3216Metric
C4: 10uF-USB-IN; C_1206_3216Metric
D1: TSAL6200-IR-LED; LED_0805_2012Metric
D2: 1N4148W-KEY-1; D_SOD-123
D3: 1N4148W-KEY-2; D_SOD-123
D4: 1N4148W-KEY-3; D_SOD-123
D5: 1N4148W-KEY-4; D_SOD-123
D6: 1N4148W-KEY-5; D_SOD-123
D7: 1N4148W-KEY-6; D_SOD-123
D8: 1N4148W-KEY-7; D_SOD-123
D9: 1N4148W-KEY-8; D_SOD-123
D10: 1N4148W-KEY-9; D_SOD-123
D11: 1N4148W-KEY-10; D_SOD-123
D12: 1N4148W-KEY-11; D_SOD-123
D13: 1N4148W-KEY-12; D_SOD-123
D14: 1N4148W-KEY-13; D_SOD-123
D15: 1N4148W-KEY-14; D_SOD-123
D16: 1N4148W-KEY-15; D_SOD-123
D17: 1N4148W-KEY-16; D_SOD-123
J1: A7670E-LASE-23P-12+11; A7670E_LASE_23P_12+11
J2: CC1101-module; PinHeader_1x08_P2.54mm_Vertical
J3: Ra-01SH-SX1262-915MHz; Ra-01SH
J4: PN532-NFC-module; PinHeader_1x04_P2.54mm_Vertical
J5: RDM6300-RFID-module; PinHeader_1x05_P2.54mm_Vertical
J6: Pimoroni-PIM447-Trackball; PinHeader_1x05_P2.54mm_Vertical
J7: Waveshare-3.5in-18pin-FPC; Hirose_FH12-18S-0.5SH_1x18-1MP_P0.50mm_Horizontal
J9: MicroSD-SPI; microSD_HC_Molex_104031-0811
J10: Nano-SIM; JAE_SIM_Card_SF72S006
J11: Keypad-matrix-4x4; PinHeader_1x08_P2.54mm_Vertical
J12: Mic-and-speaker; PinHeader_1x04_P2.54mm_Vertical
J13: LiPo-BATTERY-MICRO-JST-1.25; JST_GH_SM02B-GHS-TB_1x02-1MP_P1.25mm_Horizontal
J14: LoRa-UFL-Antenna; U.FL_Hirose_U.FL-R-SMT-1_Vertical
L1: 1uH-BOOST-INDUCTOR; L_1210_3225Metric
Q1: FS8205A-PROTECTION-FET; SOT-23-6
R1: 1.2k-TP4056-PROG; R_0805_2012Metric
R2: 180k-BOOST-FB; R_0805_2012Metric
R3: 27k-BOOST-FB; R_0805_2012Metric
R4: 5.1k-USB-C-CC1-Rd; R_0805_2012Metric
R5: 5.1k-USB-C-CC2-Rd; R_0805_2012Metric
SW1: Power-switch; SW_Slide_SPDT_Angled_CK_OS102011MA1Q
SW2: KEY-1; SW_Push_1P1T_NO_CK_KMR2
SW3: KEY-2; SW_Push_1P1T_NO_CK_KMR2
SW4: KEY-3; SW_Push_1P1T_NO_CK_KMR2
SW5: KEY-4; SW_Push_1P1T_NO_CK_KMR2
SW6: KEY-5; SW_Push_1P1T_NO_CK_KMR2
SW7: KEY-6; SW_Push_1P1T_NO_CK_KMR2
SW8: KEY-7; SW_Push_1P1T_NO_CK_KMR2
SW9: KEY-8; SW_Push_1P1T_NO_CK_KMR2
SW10: KEY-9; SW_Push_1P1T_NO_CK_KMR2
SW11: KEY-10; SW_Push_1P1T_NO_CK_KMR2
SW12: KEY-11; SW_Push_1P1T_NO_CK_KMR2
SW13: KEY-12; SW_Push_1P1T_NO_CK_KMR2
SW14: KEY-13; SW_Push_1P1T_NO_CK_KMR2
SW15: KEY-14; SW_Push_1P1T_NO_CK_KMR2
SW16: KEY-15; SW_Push_1P1T_NO_CK_KMR2
SW17: KEY-16; SW_Push_1P1T_NO_CK_KMR2
U1: ESP32-S3-WROOM-1-N16R8; ESP32-S3-WROOM-1
U2: PCF8574T-keypad-expander; SOIC-16_4.55x10.3mm_P1.27mm
U3: TP4056-charger; HSOP-8-1EP_3.9x4.9mm_P1.27mm_EP2.3x2.3mm
U4: DW01A-protection; SOT-23-6
U5: 3V3-LDO; SOT-23-5
U6: MAX17048-fuel-gauge; PinHeader_1x04_P1.27mm_Vertical
U7: TSOP38238-IR-receiver; Vishay_MINIMOLD-3Pin
U8: TPS61023DRLR-5V-BOOST; SOT-563
USB1: USB-C-charge-and-data; USB_C_Receptacle_GCT_USB4105-xx-A_16P_TopMnt_Horizontal

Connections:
/3V3: C3.1, J1.14, J2.1, J2.8, J3.3, J4.1, J6.1, J7.1, J9.4, J10.1, U1.2, U2.16, U5.5, U6.1, U7.1; also elsewhere on the board
/BAT_CHARGE: C2.1, J13.1, SW1.1, U3.5, U4.5, U6.3
/BOOST_FB: R2.2, R3.1, U8.1
/BOOST_SW: L1.2, U8.5
/CC1101_CS: J2.3, U1.24
/CC1101_GDO0: J2.7, U1.25
/DW01A_OC: Q1.4, U4.3
/DW01A_OD: Q1.1, U4.1
/EXP_CS: U1.7; also elsewhere on the board
/EXP_INT: U2.13
/EXP_IRQ: U1.8; also elsewhere on the board
/FUEL_ALERT: U6.4
/GND: C1.2, C2.2, C3.2, C4.2, D1.2, J1.11, J1.12, J2.2, J3.2, J3.9, J3.16, J4.2, J5.2, J6.2, J7.3, J9.6, J9.10, J10.2, J13.2, J14.2, Q1.2, Q1.3, Q1.5, Q1.6, R1.2, R3.2, R4.2, R5.2, U1.1, U1.40, U1.41, U2.1, U2.2, U2.3, U2.8, U3.3, U3.9 (EP_GND), U4.2, U4.4, U4.6, U5.2, U6.2, U7.2, U8.4, USB1.1, USB1.12, USB1.13, USB1.22; also elsewhere on the board
/GPS_HOST_RX: U1.5; also elsewhere on the board
/GPS_HOST_TX: U1.4; also elsewhere on the board
/GPS_PPS: U1.6; also elsewhere on the board
/I2C_SCL: J4.4, J6.4, J7.13, U1.38, U2.14; also elsewhere on the board
/I2C_SDA: J4.3, J6.3, J7.14, U1.39, U2.15; also elsewhere on the board
/IR_RX: U7.3
/IR_TX: D1.1, U1.35
/KEY_C1: D2.2, D6.2, D10.2, D14.2, J11.5, U2.9
/KEY_C2: D3.2, D7.2, D11.2, D15.2, J11.6, U2.10
/KEY_C3: D4.2, D8.2, D12.2, D16.2, J11.7, U2.11
/KEY_C4: D5.2, D9.2, D13.2, D17.2, J11.8, U2.12
/KEY_D1: D2.1, SW2.2
/KEY_D2: D3.1, SW3.2
/KEY_D3: D4.1, SW4.2
/KEY_D4: D5.1, SW5.2
/KEY_D5: D6.1, SW6.2
/KEY_D6: D7.1, SW7.2
/KEY_D7: D8.1, SW8.2
/KEY_D8: D9.1, SW9.2
/KEY_D9: D10.1, SW10.2
/KEY_D10: D11.1, SW11.2
/KEY_D11: D12.1, SW12.2
/KEY_D12: D13.1, SW13.2
/KEY_D13: D14.1, SW14.2
/KEY_D14: D15.1, SW15.2
/KEY_D15: D16.1, SW16.2
/KEY_D16: D17.1, SW17.2
/KEY_R1: J11.1, SW2.1, SW3.1, SW4.1, SW5.1, U2.4
/KEY_R2: J11.2, SW6.1, SW7.1, SW8.1, SW9.1, U2.5
/KEY_R3: J11.3, SW10.1, SW11.1, SW12.1, SW13.1, U2.6
/KEY_R4: J11.4, SW14.1, SW15.1, SW16.1, SW17.1, U2.7
/LCD_BL: J7.2, U1.33
/LCD_CS: J7.9, U1.31
/LCD_DC: J7.7, U1.32
/LCD_RESET: J7.8, U1.9
/LORA_ANT: J3.1, J14.1
/LTE_CTS: J1.15
/LTE_DTR: J1.17
/LTE_NET: J1.21
/LTE_PWRKEY: J1.9, U1.18
/LTE_RESET: J1.10
/LTE_RI: J1.16, U1.11
/LTE_RTS: J1.8
/LTE_RX: J1.7, U1.36
/LTE_RX2: J1.18
/LTE_STA: J1.5
/LTE_TX: J1.6, U1.37
/LTE_TX2: J1.19
/LTE_VEXT: J1.13
/MCU_BOOT: U1.27; also elsewhere on the board
/MCU_EN: U1.3; also elsewhere on the board
/MIC+: J1.2, J12.1
/MIC-: J1.1, J12.2
/MODEM_5V: C1.1, J1.22, J1.23, J5.1, R2.1, U8.6
/RFID_RX: J5.4
/RFID_TX: J5.3
/SD_CS: J7.10, J9.2, U1.34
/SD_DET: J9.9
/SIM_CLK: J10.3
/SIM_DET: J10.6
/SIM_IO: J10.5
/SIM_RST: J10.4
/SPI_MISO: J2.5, J3.13, J7.6, J9.7, U1.22; also elsewhere on the board
/SPI_MOSI: J2.4, J3.14, J7.5, J9.3, U1.21; also elsewhere on the board
/SPI_SCK: J2.6, J3.12, J7.4, J9.5, U1.20; also elsewhere on the board
/SPK+: J1.4, J12.3
/SPK-: J1.3, J12.4
/SX1262_BUSY: J3.10, U1.15
/SX1262_CS: J3.15, U1.23
/SX1262_DIO1: J3.6, U1.17
/SX1262_DIO2: J3.7
/SX1262_DIO3: J3.8
/SX1262_RESET: J3.4, U1.19
/SX1262_RXEN: J3.11
/SX1262_TXEN: J3.5
/TOUCH_INT: J7.15, U1.12
/TP_RESET: J7.12, U1.10
/TRACKBALL_INT: J6.5
/U3_PROG: R1.1, U3.2
/USB_CC1: R4.1, USB1.5
/USB_CC2: R5.1, USB1.15
/USB_D+: U1.14, USB1.6, USB1.16
/USB_D-: U1.13, USB1.7, USB1.17
/VBAT: J1.20, L1.1, SW1.2, U5.1, U8.2, U8.3
/VBUS5V: C4.1, U3.4, USB1.4, USB1.9, USB1.14, USB1.19



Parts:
C5, C9: 10uF 10V X5R; C_0603_1608Metric
C6, C10, C11, C12: 100nF 10V X7R; C_0603_1608Metric
C7, C8: 1uF 10V X7R; C_0603_1608Metric
J15: GPS PASSIVE ANTENNA; U.FL_Hirose_U.FL-R-SMT-1_Vertical; MPN U.FL-R-SMT-1(10)
J16: REAR EXPANSION - POWER OFF TO SWAP; JST_GH_BM10B-GHS-TBT_1x10-1MP_P1.25mm_Vertical; MPN BM10B-GHS-TBT(LF)(SN)
R6, R7: 1k; R_0603_1608Metric
R8, R9, R12, R13: 10k; R_0603_1608Metric
R10, R11: 4.7k; R_0603_1608Metric
R14: 232k 1%; R_0603_1608Metric
R15, R16, R17, R18, R19, R20, R21: 33; R_0603_1608Metric
SW18: BOOT; SW_Push_1P1T_NO_CK_KMR2
SW19: RESET; SW_Push_1P1T_NO_CK_KMR2
U9: MAX-M10S-00B-01; ublox_MAX; MPN MAX-M10S-00B-01
U10: TPS2553DBVR; SOT-23-6; MPN TPS2553DBVR

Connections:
/3V3: C5.1, C6.1, C8.1, C10.1, C11.1, C12.1, R8.1, R9.1, R10.1, R11.1, R12.1, R13.1, U9.7 (VCC_IO), U9.8 (VCC), U10.1 (IN), U10.3 (EN); also elsewhere on the board
/EXP_CS: R12.2, R20.1; also elsewhere on the board
/EXP_IRQ: R13.2, R21.1; also elsewhere on the board
/GND: C5.2, C6.2, C7.2, C8.2, C9.2, C10.2, C11.2, C12.2, J15.2 (Ext), J16.1, J16.10, R14.2, SW18.2, SW19.2, U9.1 (GND), U9.10 (GND), U9.12 (GND), U10.2 (GND); also elsewhere on the board
/GPS and rear expansion/EXP_3V3: C9.1, J16.2, U10.6 (OUT)
/GPS and rear expansion/EXP_CS_PORT: J16.8, R20.2
/GPS and rear expansion/EXP_ILIM: R14.1, U10.5 (ILIM)
/GPS and rear expansion/EXP_IRQ_PORT: J16.9, R21.2
/GPS and rear expansion/EXP_MISO: J16.7, R19.2
/GPS and rear expansion/EXP_MOSI: J16.6, R18.2
/GPS and rear expansion/EXP_SCK: J16.5, R17.2
/GPS and rear expansion/EXP_SCL: J16.3, R15.2
/GPS and rear expansion/EXP_SDA: J16.4, R16.2
/GPS and rear expansion/GPS_ANT: J15.1 (In), U9.11 (RF_IN)
/GPS and rear expansion/GPS_RX: R6.2, U9.3 (RXD)
/GPS and rear expansion/GPS_TX: R7.1, U9.2 (TXD)
/GPS_HOST_RX: R7.2; also elsewhere on the board
/GPS_HOST_TX: R6.1; also elsewhere on the board
/GPS_PPS: U9.4 (TIMEPULSE); also elsewhere on the board
/I2C_SCL: R10.2, R15.1; also elsewhere on the board
/I2C_SDA: R11.2, R16.1; also elsewhere on the board
/MCU_BOOT: R9.2, SW18.1; also elsewhere on the board
/MCU_EN: C7.1, R8.2, SW19.1; also elsewhere on the board
/SPI_MISO: R19.1; also elsewhere on the board
/SPI_MOSI: R18.1; also elsewhere on the board
/SPI_SCK: R17.1; also elsewhere on the board

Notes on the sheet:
PASSIVE GNSS ANTENNA ONLY. V_BCKP open: cold start after power-off. Rear port: 3.3V logic, 50mA module budget; no hot swap or external power. ENGINEERING REVISION: legacy power and radio blockers remain. DO NOT FABRICATE.



Board: 2 copper layers, 87.0 x 154.0 mm, 99 parts (61 on the bottom side), 82 nets.

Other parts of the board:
H1, H2, H3, H4: MountingHole_2.2mm_M2

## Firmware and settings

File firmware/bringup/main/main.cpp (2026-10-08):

#include <atomic>
#include <cstdarg>
#include <cstdio>
#include <cstring>
#include <cinttypes>
#include "driver/gpio.h"
#include "driver/i2c_master.h"
#include "driver/usb_serial_jtag.h"
#include "esp_timer.h"
#include "freertos/FreeRTOS.h"
#include "freertos/queue.h"
#include "freertos/task.h"
#include "board.hpp"
#include "session.hpp"

namespace {
struct Record { char text[160]; };
QueueHandle_t records, commands;
TaskHandle_t scan_task;
std::atomic<unsigned> queue_drops{0}, usb_drops{0};
unsigned sequence = 0; // Scanner task is the only record producer.
void record(const char *format, ...) __attribute__((format(printf, 1, 2)));
void record(const char *format, ...) {
    Record r{};
    int prefix = std::snprintf(r.text, sizeof(r.text), "\nseq=%u t_ms=%" PRId64 " ",
                               ++sequence, esp_timer_get_time()/1000);
    va_list args; va_start(args, format);
    std::vsnprintf(r.text+prefix, sizeof(r.text)-prefix, format, args);
    va_end(args);
    if (xQueueSend(records, &r, 0) != pdTRUE) ++queue_drops;
}
class Bus final : public keypad::Bus {
    i2c_master_dev_handle_t device_ = nullptr;
public:
    esp_err_t setup() {
        i2c_master_bus_config_t config{};
        config.i2c_port = I2C_NUM_0;
        config.sda_io_num = static_cast<gpio_num_t>(board::sda_gpio);
        config.scl_io_num = static_cast<gpio_num_t>(board::scl_gpio);
        config.clk_source = I2C_CLK_SRC_DEFAULT;
        config.glitch_ignore_cnt = 7;
        config.flags.enable_internal_pullup = false; // PCB R3/R4.
        i2c_master_bus_handle_t bus = nullptr;
        auto err = i2c_new_master_bus(&config, &bus);
        if (err != ESP_OK) return err;
        i2c_device_config_t dev{};
        dev.dev_addr_length = I2C_ADDR_BIT_LEN_7;
        dev.device_address = keypad::Controller::address;
        dev.scl_speed_hz = board::i2c_hz;
        err = i2c_master_bus_add_device(bus, &dev, &device_);
        if (err != ESP_OK) i2c_del_master_bus(bus);
        return err;
    }
    bool read(std::uint8_t address, std::uint8_t reg, std::uint8_t &value) override {
        return device_ && address == keypad::Controller::address &&
            i2c_master_transmit_receive(device_, &reg, 1, &value, 1, board::transfer_timeout_ms) == ESP_OK;
    }
    bool write(std::uint8_t address, std::uint8_t reg, std::uint8_t value) override {
        const std::uint8_t bytes[]{reg,value};
        return device_ && address == keypad::Controller::address &&
            i2c_master_transmit(device_, bytes, sizeof(bytes), board::transfer_timeout_ms) == ESP_OK;
    }
};
void irq(void *) {
    BaseType_t wake = pdFALSE;
    vTaskNotifyGiveFromISR(scan_task, &wake);
    if (wake) portYIELD_FROM_ISR();
}
void scanner(void *) {
    scan_task = xTaskGetCurrentTaskHandle();
    Bus bus;
    const esp_err_t bus_error = bus.setup();
    gpio_config_t config{};
    config.pin_bit_mask = 1ULL << board::irq_gpio;
    config.mode = GPIO_MODE_INPUT;
    config.intr_type = GPIO_INTR_DISABLE;
    esp_err_t irq_error = gpio_config(&config);
    if (irq_error == ESP_OK) irq_error = gpio_install_isr_service(0);
    if (irq_error == ESP_OK) irq_error = gpio_isr_handler_add(static_cast<gpio_num_t>(board::irq_gpio), irq, nullptr);
    if (irq_error == ESP_OK) irq_error = gpio_set_intr_type(static_cast<gpio_num_t>(board::irq_gpio), GPIO_INTR_NEGEDGE);
    gpio_intr_disable(static_cast<gpio_num_t>(board::irq_gpio));
    keypad::Controller controller(bus);
    bringup::Session<keypad::Controller> session(controller);
    record("BOOT keypad commissioning; SDA=10 SCL=9 IRQ=8 bus=%d irq=%d", bus_error, irq_error);
    record("Release all keys; commands: start, stop, status. No peripheral power enables.");
    std::int64_t last_status = 0;
    for (;;) {
        ulTaskNotifyTake(pdTRUE, pdMS_TO_TICKS(board::poll_ms));
        bringup::Command command;
        if (xQueueReceive(commands, &command, 0) == pdTRUE) {
            if (command == bringup::Command::start) {
                if (session.active()) record("START rejected: already active");
                else if (bus_error != ESP_OK || irq_error != ESP_OK) record("START rejected: hardware setup failed; reset required");
                else if (session.start()) {
                    if (gpio_intr_enable(static_cast<gpio_num_t>(board::irq_gpio)) != ESP_OK) {
                        session.stop(); record("FAULT IRQ enable failed; key state invalid");
                    } else record("START ready");
                } else record("FAULT initialize=%u; release keys before explicit restart", unsigned(session.fault()));
            } else if (command == bringup::Command::stop) {
                gpio_intr_disable(static_cast<gpio_num_t>(board::irq_gpio));
                session.stop(); record("STOP key state invalid; U2 scanning may remain configured");
            } else if (command == bringup::Command::invalid) record("ERROR commands: start, stop, status");
            last_status = 0;
        }
        if (session.active()) {
            const auto batch = session.poll();
            if (!session.active()) {
                gpio_intr_disable(static_cast<gpio_num_t>(board::irq_gpio));
                record("FAULT status=%u key state invalid; release keys then start", unsigned(batch.status));
            } else {
                for (unsigned i=0; i<batch.count; ++i) {
                    const auto &e = batch.events[i];
                    record("KEY SW%u row=%u col=%u %s", unsigned(e.row*4+e.column+1), unsigned(e.row), unsigned(e.column), e.pressed?"PRESS":"RELEASE");
                }
            }
        }
        const auto now = esp_timer_get_time();
        if (last_status == 0 || now-last_status >= 1000000) {
            record("STATUS active=%u valid=%u held=0x%04x fault=%u irq=%d queue_drop=%u usb_drop=%u",
                   unsigned(session.active()), unsigned(session.valid()), unsigned(session.held()), unsigned(session.fault()),
                   gpio_get_level(static_cast<gpio_num_t>(board::irq_gpio)), queue_drops.load(), usb_drops.load());
            last_status = now;
        }
        // Level-low IRQ gets another bounded batch; yield even under IRQ storms.
        if (session.active() && gpio_get_level(static_cast<gpio_num_t>(board::irq_gpio)) == 0)
            xTaskNotifyGive(scan_task);
        vTaskDelay(pdMS_TO_TICKS(1));
    }
}
void usb(void *) {
    bringup::LineParser parser;
    for (;;) {
        char input[64];
        int count = usb_serial_jtag_read_bytes(input, sizeof(input), pdMS_TO_TICKS(10));
        for (int i=0; i<count; ++i) {
            bringup::Command command;
            if (parser.feed(input[i], command) && xQueueSend(commands, &command, 0) != pdTRUE) ++usb_drops;
        }
        Record r;
        // USB backpressure never blocks the I2C task. Sequence numbers and drop
        // counters expose lost/truncated records; each record starts a new line.
        for (unsigned i=0; i<8 && xQueueReceive(records, &r, 0)==pdTRUE; ++i) {
            const auto length = std::strlen(r.text);
            if (usb_serial_jtag_write_bytes(r.text, length, 0) != static_cast<int>(length)) ++usb_drops;
        }
    }
}
}
extern "C" void app_main() {
    records = xQueueCreate(64, sizeof(Record));
    commands = xQueueCreate(8, sizeof(bringup::Command));
    if (!records || !commands) return;
    usb_serial_jtag_driver_config_t config{};
    config.rx_buffer_size = 1024; config.tx_buffer_size = 2048;
    if (usb_serial_jtag_driver_install(&config) != ESP_OK) return;
    if (xTaskCreate(usb,"keypad_usb",4096,nullptr,3,nullptr) != pdPASS) return;
    if (xTaskCreate(scanner,"keypad_scan",6144,nullptr,5,nullptr) != pdPASS) {
        const char message[]="\nFATAL scanner task allocation failed\n";
        usb_serial_jtag_write_bytes(message,sizeof(message)-1,0);
    }
}

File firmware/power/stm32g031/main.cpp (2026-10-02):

// Inhibited commissioning image. No flash writes or charge-arming implementation.
#include "stm32g031xx.h"
#include "../charger.hpp"

static volatile uint32_t ticks;
struct Diagnostics {
    uint32_t signature, reset_cause, option_bytes, loops, bus_errors;
    uint32_t initialized, state;
};
extern "C" {
volatile Diagnostics supervisor_diagnostics;
void SysTick_Handler() { ++ticks; }
[[noreturn]] void Default_Handler() {
    RCC->IOPENR |= RCC_IOPENR_GPIOAEN;
    (void)RCC->IOPENR;
    GPIOA->BSRR = 1u << 16;
    GPIOA->MODER = (GPIOA->MODER & ~3u) | 1u;
    __disable_irq();
    for (;;) {} // No watchdog refresh: reset returns PA0 to high impedance.
}
}
void operator delete(void*) noexcept { Default_Handler(); }
void operator delete(void*, unsigned int) noexcept { Default_Handler(); }
extern "C" void __cxa_pure_virtual() { Default_Handler(); }

static void af(GPIO_TypeDef* port, unsigned pin, unsigned function) {
    port->BSRR = 1u << pin; // Release before selecting open-drain AF.
    port->OTYPER |= 1u << pin;
    port->PUPDR &= ~(3u << (2*pin)); // External pull-ups, or TCA9800 B current sources.
    port->AFR[pin/8] = (port->AFR[pin/8] & ~(15u << (4*(pin%8)))) | (function << (4*(pin%8)));
    port->MODER = (port->MODER & ~(3u << (2*pin))) | (2u << (2*pin));
}
static bool bounded(volatile uint32_t& reg, uint32_t mask, uint32_t expected) {
    for (uint32_t n=0;n<160000;++n) if ((reg&mask)==expected) return true;
    return false;
}
static void setup() {
    RCC->IOPENR |= RCC_IOPENR_GPIOAEN | RCC_IOPENR_GPIOBEN;
    (void)RCC->IOPENR;
    GPIOA->BSRR = 1u << 16; // First action: PA0 low before output mode.
    GPIOA->OTYPER &= ~1u;
    GPIOA->PUPDR &= ~3u;
    GPIOA->MODER = (GPIOA->MODER & ~3u) | 1u;
    supervisor_diagnostics.signature=0x47503130; // GP10 commissioning format
    supervisor_diagnostics.reset_cause=RCC->CSR;
    supervisor_diagnostics.option_bytes=FLASH->OPTR; // Observe, never rewrite option bytes.
    RCC->CR |= RCC_CR_HSION;
    if (!bounded(RCC->CR,RCC_CR_HSIRDY,RCC_CR_HSIRDY)) Default_Handler();
    RCC->CFGR &= ~(RCC_CFGR_SW | RCC_CFGR_HPRE | RCC_CFGR_PPRE);
    if (!bounded(RCC->CFGR,RCC_CFGR_SWS,RCC_CFGR_SWS_HSISYS)) Default_Handler();
    RCC->CR &= ~RCC_CR_HSIDIV; // HSI16 / 1; HCLK and PCLK 16 MHz.
    if (SysTick_Config(16000)) Default_Handler();
    IWDG->KR=0xcccc; IWDG->KR=0x5555;
    IWDG->PR=3; IWDG->RLR=999; // /32, 1000 counts: nominal ~1 s, LSI tolerance applies.
    if (!bounded(IWDG->SR,7,0)) Default_Handler();
    IWDG->KR=0xaaaa;
    RCC->APBENR1 |= RCC_APBENR1_I2C1EN | RCC_APBENR1_I2C2EN;
    RCC->APBENR2 |= RCC_APBENR2_SYSCFGEN;
    (void)RCC->APBENR1;
    RCC->APBRSTR1 |= RCC_APBRSTR1_I2C1RST | RCC_APBRSTR1_I2C2RST;
    RCC->APBRSTR1 &= ~(RCC_APBRSTR1_I2C1RST | RCC_APBRSTR1_I2C2RST);
    RCC->CCIPR &= ~RCC_CCIPR_I2C1SEL; // PCLK, not a bootloader-selected clock.
    af(GPIOB,8,6); af(GPIOB,7,6);
    // 250 ns prescaler, 10 us low / 8 us high before synchronizer/filter delays.
    // Conservative Standard-mode bring-up timing; validate actual rise/fall times.
    I2C1->TIMINGR=0x30721f27;
    I2C1->CR1=I2C_CR1_PE;
    SYSCFG->CFGR1 |= SYSCFG_CFGR1_PA11_RMP | SYSCFG_CFGR1_PA12_RMP;
    af(GPIOA,11,6); af(GPIOA,12,6); // No internal pull-ups on the buffer B side.
    I2C2->OAR1=(0x42u<<1)|I2C_OAR1_OA1EN;
    I2C2->CR1=I2C_CR1_PE; // Polled, clock-stretching diagnostic slave only.
}

class Stm32PowerIO final : public handset::PowerIO {
    static constexpr uint32_t errors=I2C_ISR_NACKF|I2C_ISR_BERR|I2C_ISR_ARLO|I2C_ISR_OVR;
    bool wait(uint32_t wanted,uint32_t started) {
        for (uint32_t spins=0;spins<160000;++spins) {
            const uint32_t flags=I2C1->ISR;
            if (flags&errors) return false;
            if (flags&wanted) return true;
            if (uint32_t(ticks-started)>=25) return false;
        }
        return false; // Bounded even if SysTick is broken; IWDG is independent.
    }
    bool failed() {
        set_charge_arm(false);
        I2C1->CR1=0;
        I2C1->ICR=I2C_ICR_STOPCF|I2C_ICR_NACKCF|I2C_ICR_BERRCF|I2C_ICR_ARLOCF|I2C_ICR_OVRCF;
        I2C1->CR1=I2C_CR1_PE;
        ++supervisor_diagnostics.bus_errors;
        return false;
    }
    bool start(uint8_t address,uint32_t& now) {
        now=ticks;
        if (address!=0x41 && address!=0x6a) return false;
        if (I2C1->ISR&I2C_ISR_BUSY) return false; // No automatic stuck-bus recovery/rearming.
        I2C1->ICR=I2C_ICR_STOPCF|I2C_ICR_NACKCF|I2C_ICR_BERRCF|I2C_ICR_ARLOCF|I2C_ICR_OVRCF;
        return true;
    }
public:
    bool set_charge_arm(bool enabled) override {
        GPIOA->BSRR=1u<<16; // This build has no path that drives PA0 high.
        return !enabled && !(GPIOA->ODR&1u) && !(GPIOA->IDR&1u);
    }
    bool load_inhibit(bool& inhibited) override {
        inhibited=true;
        return false; // Persistent storage is not implemented: never fabricate a valid record.
    }
    bool save_inhibit(bool) override { return false; }
    bool write(uint8_t a,uint8_t r,uint8_t v) override {
        uint32_t now;
        if (!start(a,now)) return failed();
        I2C1->CR2=(uint32_t(a)<<1)|(2u<<16)|I2C_CR2_AUTOEND|I2C_CR2_START;
        if (!wait(I2C_ISR_TXIS,now)) return failed();
        I2C1->TXDR=r;
        if (!wait(I2C_ISR_TXIS,now)) return failed();
        I2C1->TXDR=v;
        if (!wait(I2C_ISR_STOPF,now)) return failed();
        I2C1->ICR=I2C_ICR_STOPCF;return true;
    }
    bool read(uint8_t a,uint8_t r,uint8_t& v) override {
        uint32_t now;
        if (!start(a,now)) return failed();
        I2C1->CR2=(uint32_t(a)<<1)|(1u<<16)|I2C_CR2_START;
        if (!wait(I2C_ISR_TXIS,now)) return failed();
        I2C1->TXDR=r;
        if (!wait(I2C_ISR_TC,now)) return failed();
        I2C1->CR2=(uint32_t(a)<<1)|(1u<<16)|I2C_CR2_RD_WRN|I2C_CR2_AUTOEND|I2C_CR2_START;
        if (!wait(I2C_ISR_RXNE,now)) return failed();
        const uint8_t result=uint8_t(I2C1->RXDR);
        if (!wait(I2C_ISR_STOPF,now)) return failed();
        I2C1->ICR=I2C_ICR_STOPCF;v=result;return true;
    }
};

static void diagnostic_host() {
    static uint8_t frame[8],index;
    const uint32_t flags=I2C2->ISR;
    if (flags&I2C_ISR_ADDR) {
        frame[0]=1; frame[1]=1; // Version 1, permanently charge-inhibited image.
        frame[2]=uint8_t(supervisor_diagnostics.state);
        frame[3]=uint8_t(supervisor_diagnostics.bus_errors);
        const uint32_t cause=supervisor_diagnostics.reset_cause;
        for (unsigned n=0;n<4;++n) frame[4+n]=uint8_t(cause>>(8*n));
        index=0;I2C2->ICR=I2C_ICR_ADDRCF;
    }
    if (flags&I2C_ISR_RXNE) (void)I2C2->RXDR; // Discard every write; no authorization command exists.
    if (flags&I2C_ISR_TXIS) I2C2->TXDR=index<8 ? frame[index++] : 0xff;
    I2C2->ICR=flags&(I2C_ICR_STOPCF|I2C_ICR_NACKCF|I2C_ICR_BERRCF|I2C_ICR_ARLOCF|I2C_ICR_OVRCF);
}
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

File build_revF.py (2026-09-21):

#!/usr/bin/env python3
"""Build an isolated, explicitly unreleased GPS/expansion engineering revision.

Never replaces the user's main board. KiCad remains responsible for net export,
zone fill, DRC and ERC. Pin changes remove obsolete copper on affected nets.
"""
import copy
import json
import math
from pathlib import Path
import shutil
import subprocess
import uuid
import xml.etree.ElementTree as ET
from cad_sexpr import Q, child, children, dump, parse, prop
import pcbnew

pcbnew.SwigPyIterator.next = pcbnew.SwigPyIterator.__next__
BASE = Path(__file__).resolve().parent
OUT = BASE / 'revF-gps-expansion'
OUT.mkdir(exist_ok=True)
uid = lambda: str(uuid.uuid4())
root = parse((BASE / 'owasso1.kicad_sch').read_text())
root_id = child(root, 'uuid')[1]
symbols = {str(prop(s, 'Reference')[2]): s for s in children(root, 'symbol')}
libs = {str(s[1]): s for s in children(child(root, 'lib_symbols'), 'symbol')}
board = pcbnew.LoadBoard(str(BASE / 'owasso1.kicad_pcb'))
fps = {f.GetReference(): f for f in board.GetFootprints()}
changes = []

def point(node):
    return tuple(round(float(x), 4) for x in node[1:3])

def pin_positions(symbol, lib):
    sx, sy = point(child(symbol, 'at'))
    angle = math.radians(float(child(symbol, 'at')[3]))
    pins = []
    for unit in children(lib, 'symbol'):
        for p in children(unit, 'pin'):
            x, y = point(child(p, 'at'))
            pos = (round(sx + x*math.cos(angle) + y*math.sin(angle), 4),
                   round(sy + x*math.sin(angle) - y*math.cos(angle), 4))
            pins.append((str(child(p, 'number')[1]), pos, p))
    return pins

def label(net, x, y, justify='right'):
    return parse(f'(label {json.dumps(net)} (at {x} {y} 0) (effects (font (size 1 1)) (justify {justify} bottom)) (uuid "{uid()}"))')

def wire(x, y, x2, y2):
    return parse(f'(wire (pts (xy {x} {y}) (xy {x2} {y2})) (stroke (width 0) (type default)) (uuid "{uid()}"))')

def set_pin(ref, number, net):
    s = symbols[ref]
    p = next(pos for n, pos, _ in pin_positions(s, libs[str(child(s, 'lib_id')[1])]) if n == str(number))
    connected = {p}
    removed = []
    for w in children(root, 'wire'):
        pts = [point(t) for t in children(child(w, 'pts'), 'xy')]
        if p in pts:
            connected.update(pts)
            removed.append(w)
    for n in root:
        if isinstance(n, list) and n and n[0] in ('label', 'no_connect') and point(child(n, 'at')) in connected:
            removed.append(n)
    for n in removed:
        root.remove(n)
    x, y = p
    if net is None:
        root.append(parse(f'(no_connect (at {x} {y}) (uuid "{uid()}"))'))
    else:
        root.extend([wire(x, y, x-5.08, y), label(net, x-5.08, y)])
    changes.append({'ref':ref, 'pin':str(number), 'net':net})

# Free general-purpose GPIOs. GPIO35/36/37 are occupied by octal PSRAM.
for pin, net in {3:'MCU_EN',4:'GPS_HOST_TX',5:'GPS_HOST_RX',6:'GPS_PPS',
                 7:'EXP_CS',8:'EXP_IRQ',9:'LCD_RESET',10:'TP_RESET',12:'TOUCH_INT',
                 16:None,20:'SPI_SCK',21:'SPI_MOSI',22:'SPI_MISO',
                 23:'SX1262_CS',24:'CC1101_CS',25:'CC1101_GDO0',26:None,
                 27:'MCU_BOOT',28:None,29:None,30:None}.items():
    set_pin('U1', pin, net)
# Correct SO16 address pins and P0-P7. Pin 13 remains optional polling IRQ.
for pin, net in {1:'GND',2:'GND',3:'GND',4:'KEY_R1',5:'KEY_R2',6:'KEY_R3',
                 7:'KEY_R4',9:'KEY_C1',10:'KEY_C2',11:'KEY_C3',12:'KEY_C4'}.items():
    set_pin('U2', pin, net)
# Separate protected pack/charger rail from switched system rail. In particular,
# never connect USB VBUS directly to a cell through the slide switch.
for ref, pin in [('J13',1),('U3',5),('C2',1),('U4',5),('U6',3),('SW1',1)]:
    set_pin(ref, pin, 'BAT_CHARGE')

# Correct the three legacy connector-shaped symbols to their actual pad sets.
# Keep existing pin coordinates so this does not disturb other schematic wiring.
contract_libs = []
for ref in ('J10','USB1','U3'):
    s = symbols[ref]
    old = libs[str(child(s,'lib_id')[1])]
    lib = copy.deepcopy(old)
    name = ref+'_contract'
    libid = 'owasso1-review:'+name
    actual = {p.GetNumber() for p in fps[ref].Pads() if p.GetNumber()}
    lib[1] = Q(libid)
    for sub in children(lib,'symbol'):
        sub[1] = Q(name+'_'+str(sub[1]).rsplit('_',2)[-2]+'_'+str(sub[1]).rsplit('_',1)[-1])
        sub[:] = [p for p in sub if not (isinstance(p,list) and p and p[0]=='pin' and str(child(p,'number')[1]) not in actual)]
    if ref=='U3':
        sub = next(su for su in children(lib,'symbol') if children(su,'pin'))
        template = copy.deepcopy(children(sub,'pin')[-1])
        child(template,'number')[1] = Q('9')
        child(template,'name')[1] = Q('EP_GND')
        child(template,'at')[2] = str(min(float(child(p,'at')[2]) for p in children(sub,'pin'))-2.54)
        sub.append(template)
    child(s,'lib_id')[1] = Q(libid)
    child(root,'lib_symbols').append(lib)
    libs[libid] = lib
    export = copy.deepcopy(lib)
    export[1] = Q(name)
    contract_libs.append(export)
    if ref=='U3':
        set_pin(ref,9,'GND')

# Remove only genuinely orphaned legacy annotations, not connected NC flags.
pinpoints = {pos for s in symbols.values() for _,pos,_ in pin_positions(s,libs[str(child(s,'lib_id')[1])])}
wirepoints = {point(p) for w in children(root,'wire') for p in children(child(w,'pts'),'xy')}
root[:] = [n for n in root if not (isinstance(n,list) and n and
    ((n[0]=='no_connect' and (point(child(n,'at')) not in pinpoints or point(child(n,'at')) in wirepoints)) or
     (n[0]=='label' and point(child(n,'at')) not in pinpoints|wirepoints)))]

# Restore library-qualified metadata using actual placed footprints, not stale
# schematic choices. This does NOT assert that the legacy part selection is valid.
for ref, fp in fps.items():
    if ref not in symbols:
        continue
    s = symbols[ref]
    name = str(fp.GetFPID().GetLibItemName())
    oldlib = str(prop(s, 'Footprint')[2]).split(':')[0]
    if (BASE / 'owasso1.pretty' / (name+'.kicad_mod')).exists():
        libname = 'owasso1'
    else:
        matches = list(Path('/usr/share/kicad/footprints').glob('*.pretty/'+name+'.kicad_mod'))
        preferred = [p for p in matches if p.parent.stem == oldlib]
        if not matches:
            raise RuntimeError(f'No library footprint for {ref}: {name}')
        libname = (preferred or matches)[0].parent.stem
    fpid = libname + ':' + name
    prop(s, 'Footprint')[2] = Q(fpid)
    fp.SetFPID(pcbnew.LIB_ID(libname, name))
    symbol_id = str(child(s, 'uuid')[1])
    s[:] = [n for n in s if not (isinstance(n,list) and n and n[0]=='instances')]
    s.append(parse(f'(instances (project "owasso1" (path "/{root_id}" (reference "{ref}") (unit 1))))'))
    fp.SetPath(pcbnew.KIID_PATH('/'+str(root_id)+'/'+symbol_id))
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

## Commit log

2026-09-21 Initial owasso1-pcb revF KiCad project
    [bom.csv, bom_priced.csv, enclosure.scad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]
2026-09-21 Rename KiCad files to mesh-phone
    [mesh-phone.before-external-harness-flags.kicad_sch, mesh-phone.before-footprint-sync.kicad_sch, mesh-phone.before-harness-connectors.kicad_pcb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]
2026-09-21 Fix bom_priced.csv: row U2 extra empty column (10 -> 9 cols)
    [bom_priced.csv]
2026-09-21 Fix bom_priced.csv BT1 row embedded quote causing 11 cols
    [bom_priced.csv]
2026-09-21 Fix total row (line 29/29) to 9 columns
    [bom_priced.csv]
2026-09-21 Add enclosure images to README; include unstaged mesh_render.py and .history updates
    [appearance.scad, bom.csv, bom_priced.csv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]
2026-09-24 feat(handset): save PCB and fabrication roadmap
    [audio.kicad_sch, aux-power.kicad_sch, candidate-components.csv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]
2026-10-02 feat: advance handset prototype design
    [audio.kicad_sch, aux-power.kicad_sch, backlight-bom.csv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]
2026-10-05 feat: add expansion power and signal control
    [audio.kicad_sch, aux-power.kicad_sch, backlight-bom.csv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]
2026-10-06 fix: shorten expansion ESD ground returns
    [handset.kicad_pcb]
2026-10-06 fix: clear USB connector hole violations
    [handset.kicad_pcb, materials-to-use.csv, placement.csv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]
2026-10-07 feat: route USB data and add termination
    [core.kicad_sch, handset.kicad_pcb, materials-to-use.csv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]
2026-10-07 feat: route boot reset and keypad controls
    [handset.kicad_pcb, placement.csv]
2026-10-07 feat: route keypad and add scanner driver
    [handset.kicad_pcb]
2026-10-08 feat: add ESP32 keypad bring-up app
2026-10-08 feat: route amplifier power and ground
    [handset.kicad_pcb, placement.csv]
2026-10-08 feat: add SX1262 TCXO clock circuit
    [handset.kicad_pcb, placement.csv, radios.kicad_sch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]
2026-10-08 feat: route SX1262 core regulator loop
    [handset.kicad_pcb, placement.csv]
2026-10-08 feat: route SX1262 supplies and grounds
    [handset.kicad_pcb, placement.csv]
2026-10-09 feat: capture SX1262 RF matching and switch
    [handset.kicad_pcb, placement.csv, radios.kicad_sch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]
2026-10-09 feat: capture SX1262 PA choke and bypass
    [handset.kicad_pcb, placement.csv, radios.kicad_sch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]
2026-10-09 feat: route SX1262 local PA and RF inputs
    [handset.kicad_pcb, placement.csv]
2026-10-10 feat: ground SX1262 RF matching device
    [handset.kicad_pcb]
2026-10-10 feat: route SX1262 switch and antenna path
    [handset.kicad_pcb, placement.csv]
2026-10-11 feat: route CC1101 matching and antenna path
